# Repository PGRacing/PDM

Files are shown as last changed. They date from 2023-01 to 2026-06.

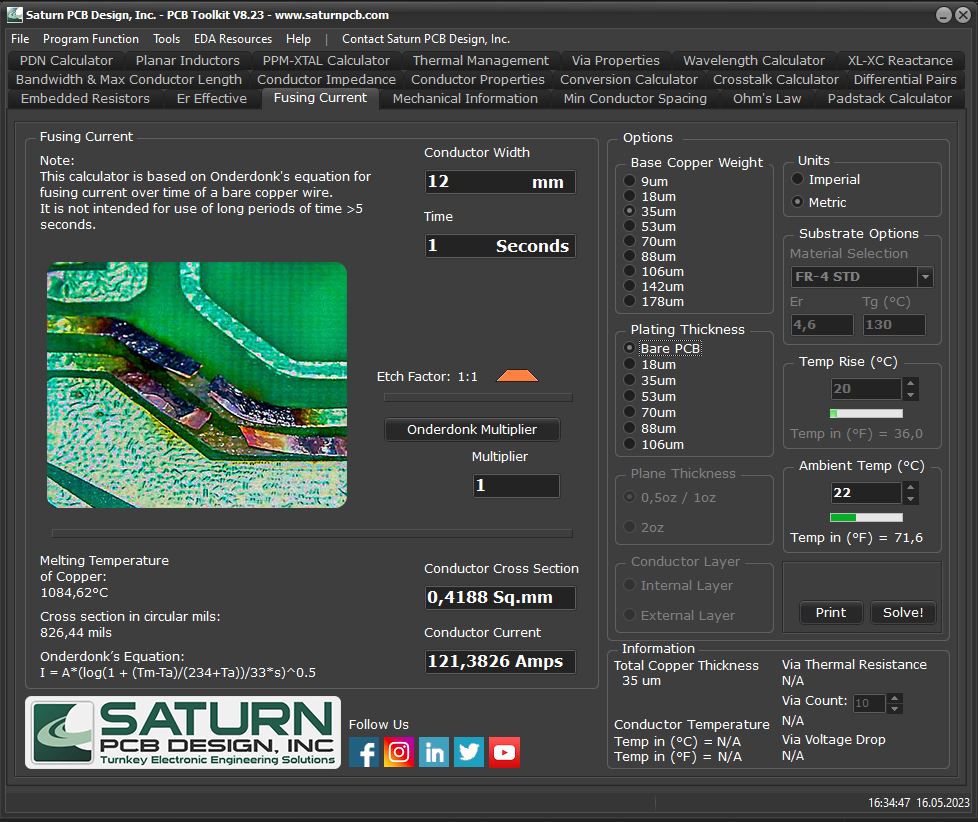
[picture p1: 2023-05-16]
SIM/CALCULATIONS/trace_fusing/external_12mm_1.0oz_121A_result.JPG

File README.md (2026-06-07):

# PDM

Schematic mockup:
obraz

TODO on next PCB:

Rev 4.3
| ID | NAME | CAUSE |DIFFICULTY | PRIORITY | STATUS |
| --- | --- | --- | --- | --- | --- |
| 1. | Create test board for BTS50025-1TAE | Switch with higher Rds(on) should perform better in terms of diagnostics on most used loads | 1 | 3 | | 
| 2. | Create schematic and brd for imporoved power delivery section optimized for autmotive use based on MP4322 TLS850F2TAV50, TVS diodes + filtering | Current solution with MP2332 has maximum rating of 18V, which is really for load dumps | 3 | 3 || 
| 3. | Divide task to "safety critical real-time" hardware based (timer) ones and other normal operation tasks | Current solution can cause safety issus | 3 | 3 || 
| 4. | Prepare I^2t wiring harness protection | This should allow better WH protection| 3 | 2 || 
| 5. | Prepare OCP using curve, not only single value | This should allow better WH protection | 2 | 3 || 
| 6. | Use buffers for MCU protection | Protect MCU I/O pins | 1 | 2 || 
| 7. | Change zenner protection diodes to extended linearity region of Is switch output || 1 | 3 || 
| 8. | Add better filtering (change RC filter values) on Is output | Is output on inductive signals or fast switched signals HFreq PWM used causes invalid readings | 1 | 3 || 
| 9. | Detect battery under-voltage and UV shutdown for battery protection || 1 | 2 || 
| 10. | Configuration over USB | For sake of user-friendly solution | 3 | 2 || 
| 11. | CAN inputs support || 2 | 2 || 
| 12. | Thermal sensing | Safety critical | 2 | 2 || 
| 13. | Better 3D printed caseing (take care of screws outside of caseing envelope) + add honeycomb reinforcment | Safety critical for splash proof | 2 | 1 || 
| 14. | Add logic-level shifter for LED's | Some LED's turn red on random order | 1 | 3 || 
| 15. | Add separate voltage source for ARGB LED's and CAN bus | working can bus is critical for system integrity | 1 | 3 || 
| 16. | Add external voltage sources diagnosis (at least voltage on output) || 2 | 3 || 
| 17. | Add battery insulation and reverse-polarity + huge TVS and maybe Gas Discharge Tubes | Load dumps + cold crank etc. | 3 | 2 || 
| 18. | Add better connector for BAT+ | 1 | 3 || 
| 19. | Add limp home mode when any peripheral is malfunctioning (detect those malfunctions) | 2 | 3 || 
| 20. | Add TVS or zenner on all inputs (in limit of absolute maximium rating) near connector | 1 | 3 || 
| 21. | Add external or on-board probes for temperature sensing | 2 | 2 || 
| 22. | Add more state/debug led's | 1 | 1 || 
| 23. | Move safety functions oc and counters and errors into separate struct or bit mask of register | 2 | 3 || 

Rev. 4.1
| NAME | DIFFICULTY | PRIORITY | STATUS |
| --- | --- | --- | --- |
| 1. Add fuse for external sensors supply (100mA). Can also be solved with second 5V regulator for sensors + fuse. | 1 | 3 | DONE - Added external LDO's to 3.3V and 5V |
| 2. Change CPC1117N to CPC1017N (or diffrent PhotoMos) | 1 | 2 | DONE - Added diffrent (smaller) Opto-MOS |
| 3. Add clamping diodes on any signals | 2 | 3 | Added zenner + shottky clippers |
| 4. Change input filtration for low profile SMD capacitor instead of tht | 1 | 1 | DEPRECEATED  |
| 5. Add SWO pin | 2 | 2 | DONE |
| 6. Current sensors output should be collected by one ADC !!! - for eg. ADC3 (change pinout) | 3 | 2 | DONE |
| 7. Add clamping diodes on current sensor to allow lower range current detecion | 2 | 3 | DONE |
| 8. Selection and redirection of IO is not imporant | 1 | 1 | DONE - (only four channels) |
| 9. Fix WS2812B footprint | 1 | 3 | DONE |
| 10. Use smaller footprint for voltage mux and can transceiver | 2 | 1 | DONE - changed voltage mux to 16 channel, CAN transceiver same |
| 11. Change FET's to BTS50010-1LUA | 3 | 2 |  DONE |
| 12. Add RX/TX information leds to CAN bus (software driven) | 1 | 1 | DEPERECATED |
| 13. Add MUX for mutlichannel switch | 2 | 2 | DONE - added 16 channel mux |
| 14. Add CAN software switching | 2 | 2 | DONE |
| 14. Remove additional header for stlink | 2 | 2 | DONE |

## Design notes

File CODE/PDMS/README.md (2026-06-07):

# PDMS 

### DESCRIPTION
This repository contains code that is targeted for PDM - Power distribution module. PDMS is custom PDM mainly created for motorcycles and single-seater vehicles (formula student). Making changes in code and configurations can have critical impact on vehicle and driver safety. After changing configuration ALWAYS verify it in secure test enviroment. 

### NOTE
- This is code that should be used with PDMS v4.1 or PDMS v4.2 board
- Before usage verify MCU I/O configuration and mapping

### INSTALL

0. Install choco package manager: https://chocolatey.org/install

1. Install Visual Studio code as it is used as IDE for this project:
`> choco install vscode`

2. Check if cygwin is installed if install it via: 
`> choco install cygwin` 

3. Check if you have ARM embedded toolchain installed, version at least 10.3.1 required. In terminal in project directory type: 
`> arm-none-eabi-gcc --version `

4. If no toolchain present install it by:
`> choco install gcc-arm-embedded `
or by installing binary from: [ARM GNU Toolchain](https://developer.arm.com/downloads/-/arm-gnu-toolchain-downloads)

5. Install GNU make: 
`> choco install make `

6. Verify that all tools installed are added to `$PATH` and available in projects directory. 
``` 
    > arm-none-eabi-gcc --version
    > make --version
    > cygwin
```

7. Install following extensions for VS Code: 
    - [C/C++](https://marketplace.visualstudio.com/items?itemName=ms-vscode.cpptools)
    - [Cortex-Debug](https://marketplace.visualstudio.com/items?itemName=marus25.cortex-debug)
    - [Makefile Tools](https://marketplace.visualstudio.com/items?itemName=ms-vscode.makefile-tools)
  
### BUILD

Project is based on makefile system based on one root makefile [Makefile](https://github.com/PGRacing/PDM/blob/main/CODE/PDMS/Makefile)

To start build type: 
`>  make -j 16`
or start task:
`Build STM32 - L496` by clicking `Ctrl + Shift + B`

To clean build type: 
`> make clean -j 16`
or start task:
`Clean STM32 - L496` by clicking `Ctrl + Shift + B`

Build results are present in `./build` directory as:
    - PDMS.elf
    - PDMS.hex
    - PDMS.bin
    - PDMS.map

### DEBUG

Debug is performed via SWD interface on ST-Link probe via GDB Debugger. Start cortex-debug session from `Run and Debug (Ctrl + Shift + D)` tab by selecting one of following options: 
    - Debug STM32 (PDMS)
    - Attach STM32 (PDMS)
    - Debug STM32 with Live Expressions
Last option gives you access to Cortex Live Watch. Refresh frequency can be adjusted in `.vscode/launch.json` file in `samplesPerSecond` parameter. 

###### SWV
When SWO pin in ST-Link probe is connected, additional logging (SWV - Serial Wire Viewer) functionality can be used. On debug startup new terminal tab will pop-up named "ITM port 0 output". All printf function output is redirected over there. To interface with this port, wrapper macros from `util\logger.h` should be used. SWV is MCU and probe clock dependent, if any of those are changed it needs to be adjusted in `.vscode/launch.json`

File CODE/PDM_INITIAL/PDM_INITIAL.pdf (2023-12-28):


09/12/2023

PDM_INITIAL Project
Configuration Report

## 1. Description

### 1.1. Project

Project Name | PDM_INITIAL
Board Name | custom
Generated with: | STM32CubeMX 6.6.1
Date | 12/09/2023

### 1.2. MCU

MCU Series | STM32L4
MCU Line | STM32L4x6
MCU name | STM32L496ZGTx
MCU Package | LQFP144
MCU Pin number | 144

### 1.3. Core(s) information

Core(s) | Arm Cortex-M4

## 2. Pinout Configuration

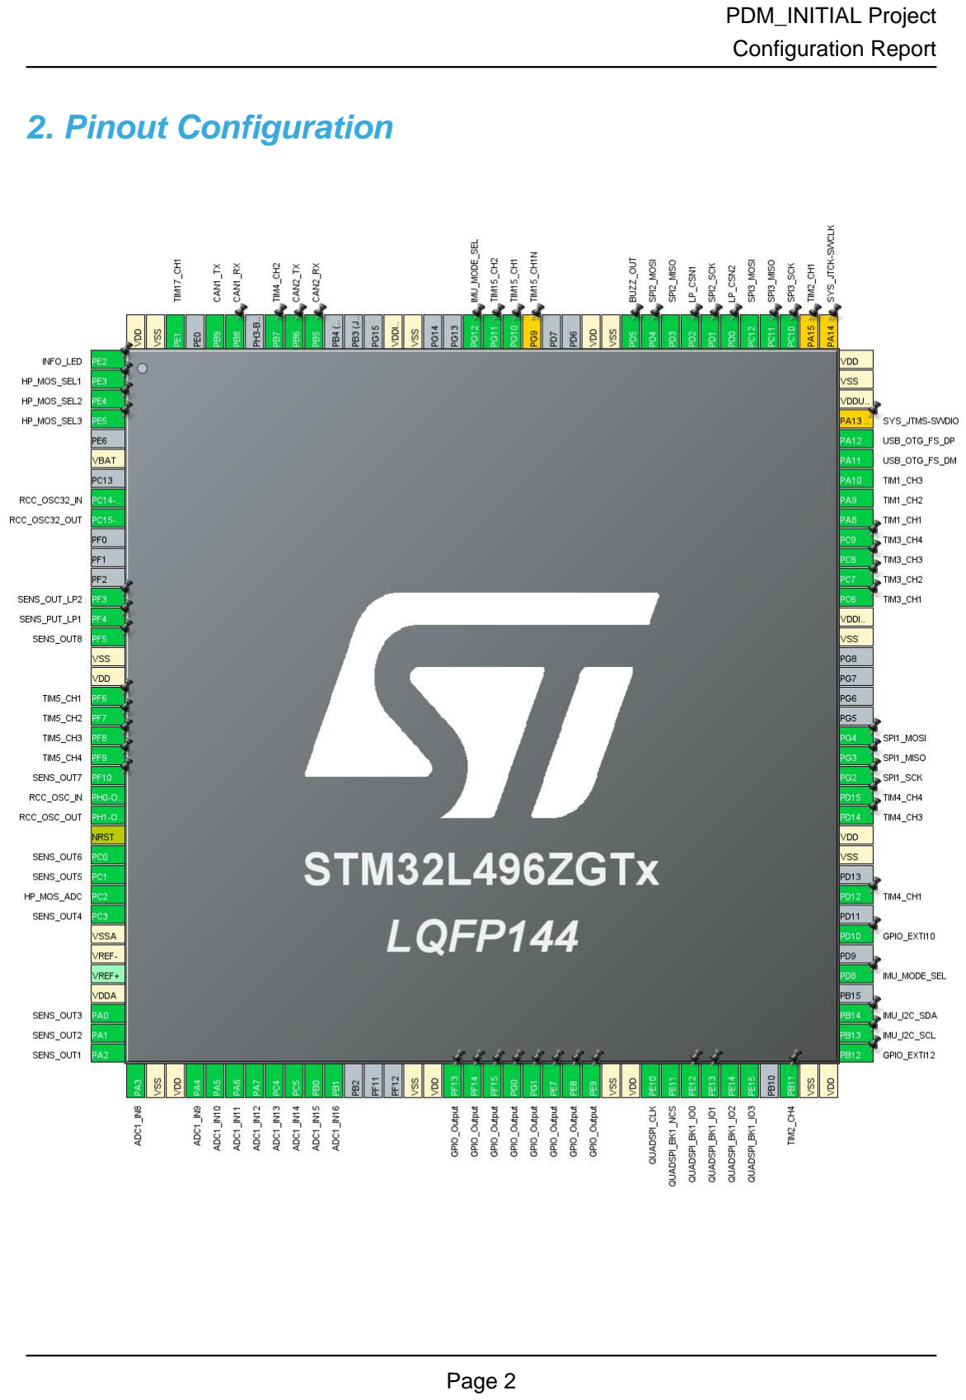
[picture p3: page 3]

## 3. Pins Configuration

Pin Number LQFP144 | Pin Name (function after reset) | Pin Type | Alternate Function(s) | Label
1 | PE2 * | I/O | GPIO_Output | INFO_LED
2 | PE3 * | I/O | GPIO_Output | HP_MOS_SEL1
3 | PE4 * | I/O | GPIO_Output | HP_MOS_SEL2
4 | PE5 * | I/O | GPIO_Output | HP_MOS_SEL3
6 | VBAT | Power
8 | PC14-OSC32_IN (PC14) | I/O | RCC_OSC32_IN
9 | PC15-OSC32_OUT (PC15) | I/O | RCC_OSC32_OUT
13 | PF3 | I/O | ADC3_IN6 | SENS_OUT_LP2
14 | PF4 | I/O | ADC3_IN7 | SENS_PUT_LP1
15 | PF5 | I/O | ADC3_IN8 | SENS_OUT8
16 | VSS | Power
17 | VDD | Power
18 | PF6 | I/O | TIM5_CH1
19 | PF7 | I/O | TIM5_CH2
20 | PF8 | I/O | TIM5_CH3
21 | PF9 | I/O | TIM5_CH4
22 | PF10 | I/O | ADC3_IN13 | SENS_OUT7
23 | PH0-OSC_IN (PH0) | I/O | RCC_OSC_IN
24 | PH1-OSC_OUT (PH1) | I/O | RCC_OSC_OUT
25 | NRST | Reset
26 | PC0 | I/O | ADC1_IN1 | SENS_OUT6
27 | PC1 | I/O | ADC1_IN2 | SENS_OUT5
28 | PC2 | I/O | ADC1_IN3 | HP_MOS_ADC
29 | PC3 | I/O | ADC1_IN4 | SENS_OUT4
30 | VSSA | Power
31 | VREF- | Power
33 | VDDA | Power
34 | PA0 | I/O | ADC1_IN5 | SENS_OUT3
35 | PA1 | I/O | ADC1_IN6 | SENS_OUT2
36 | PA2 | I/O | ADC1_IN7 | SENS_OUT1
37 | PA3 | I/O | ADC1_IN8
38 | VSS | Power
39 | VDD | Power
40 | PA4 | I/O | ADC1_IN9
41 | PA5 | I/O | ADC1_IN10
42 | PA6 | I/O | ADC1_IN11

Pin Number LQFP144 | Pin Name (function after reset) | Pin Type | Alternate Function(s) | Label
43 | PA7 | I/O | ADC1_IN12
44 | PC4 | I/O | ADC1_IN13
45 | PC5 | I/O | ADC1_IN14
46 | PB0 | I/O | ADC1_IN15
47 | PB1 | I/O | ADC1_IN16
51 | VSS | Power
52 | VDD | Power
53 | PF13 * | I/O | GPIO_Output
54 | PF14 * | I/O | GPIO_Output
55 | PF15 * | I/O | GPIO_Output
56 | PG0 * | I/O | GPIO_Output
57 | PG1 * | I/O | GPIO_Output
58 | PE7 * | I/O | GPIO_Output
59 | PE8 * | I/O | GPIO_Output
60 | PE9 * | I/O | GPIO_Output
61 | VSS | Power
62 | VDD | Power
63 | PE10 | I/O | QUADSPI_CLK
64 | PE11 | I/O | QUADSPI_BK1_NCS
65 | PE12 | I/O | QUADSPI_BK1_IO0
66 | PE13 | I/O | QUADSPI_BK1_IO1
67 | PE14 | I/O | QUADSPI_BK1_IO2
68 | PE15 | I/O | QUADSPI_BK1_IO3
70 | PB11 | I/O | TIM2_CH4
71 | VSS | Power
72 | VDD | Power
73 | PB12 | I/O | GPIO_EXTI12
74 | PB13 | I/O | I2C2_SCL | IMU_I2C_SCL
75 | PB14 | I/O | I2C2_SDA | IMU_I2C_SDA
77 | PD8 * | I/O | GPIO_Output | IMU_MODE_SEL
79 | PD10 | I/O | GPIO_EXTI10
81 | PD12 | I/O | TIM4_CH1
83 | VSS | Power
84 | VDD | Power
85 | PD14 | I/O | TIM4_CH3
86 | PD15 | I/O | TIM4_CH4
87 | PG2 | I/O | SPI1_SCK
88 | PG3 | I/O | SPI1_MISO
89 | PG4 | I/O | SPI1_MOSI

Pin Number LQFP144 | Pin Name (function after reset) | Pin Type | Alternate Function(s) | Label
94 | VSS | Power
95 | VDDIO2 | Power
96 | PC6 | I/O | TIM3_CH1
97 | PC7 | I/O | TIM3_CH2
98 | PC8 | I/O | TIM3_CH3
99 | PC9 | I/O | TIM3_CH4
100 | PA8 | I/O | TIM1_CH1
101 | PA9 | I/O | TIM1_CH2
102 | PA10 | I/O | TIM1_CH3
103 | PA11 | I/O | USB_OTG_FS_DM
104 | PA12 | I/O | USB_OTG_FS_DP
105 | PA13 (JTMS/SWDIO) ** | I/O | SYS_JTMS-SWDIO
106 | VDDUSB | Power
107 | VSS | Power
108 | VDD | Power
109 | PA14 (JTCK/SWCLK) ** | I/O | SYS_JTCK-SWCLK
110 | PA15 (JTDI) ** | I/O | TIM2_CH1
111 | PC10 | I/O | SPI3_SCK
112 | PC11 | I/O | SPI3_MISO
113 | PC12 | I/O | SPI3_MOSI
114 | PD0 * | I/O | GPIO_Output | LP_CSN2
115 | PD1 | I/O | SPI2_SCK
116 | PD2 * | I/O | GPIO_Output | LP_CSN1
117 | PD3 | I/O | SPI2_MISO
118 | PD4 | I/O | SPI2_MOSI
119 | PD5 * | I/O | GPIO_Output | BUZZ_OUT
120 | VSS | Power
121 | VDD | Power
124 | PG9 ** | I/O | TIM15_CH1N
125 | PG10 | I/O | TIM15_CH1
126 | PG11 | I/O | TIM15_CH2
127 | PG12 * | I/O | GPIO_Output | IMU_MODE_SEL
130 | VSS | Power
131 | VDDIO2 | Power
135 | PB5 | I/O | CAN2_RX
136 | PB6 | I/O | CAN2_TX
137 | PB7 | I/O | TIM4_CH2
139 | PB8 | I/O | CAN1_RX
140 | PB9 | I/O | CAN1_TX

Pin Number LQFP144 | Pin Name (function after reset) | Pin Type | Alternate Function(s) | Label
142 | PE1 | I/O | TIM17_CH1
143 | VSS | Power
144 | VDD | Power

* The pin is affected with an I/O function
** The pin is affected with a peripheral function but no peripheral mode is activated

## 4. Clock Tree Configuration

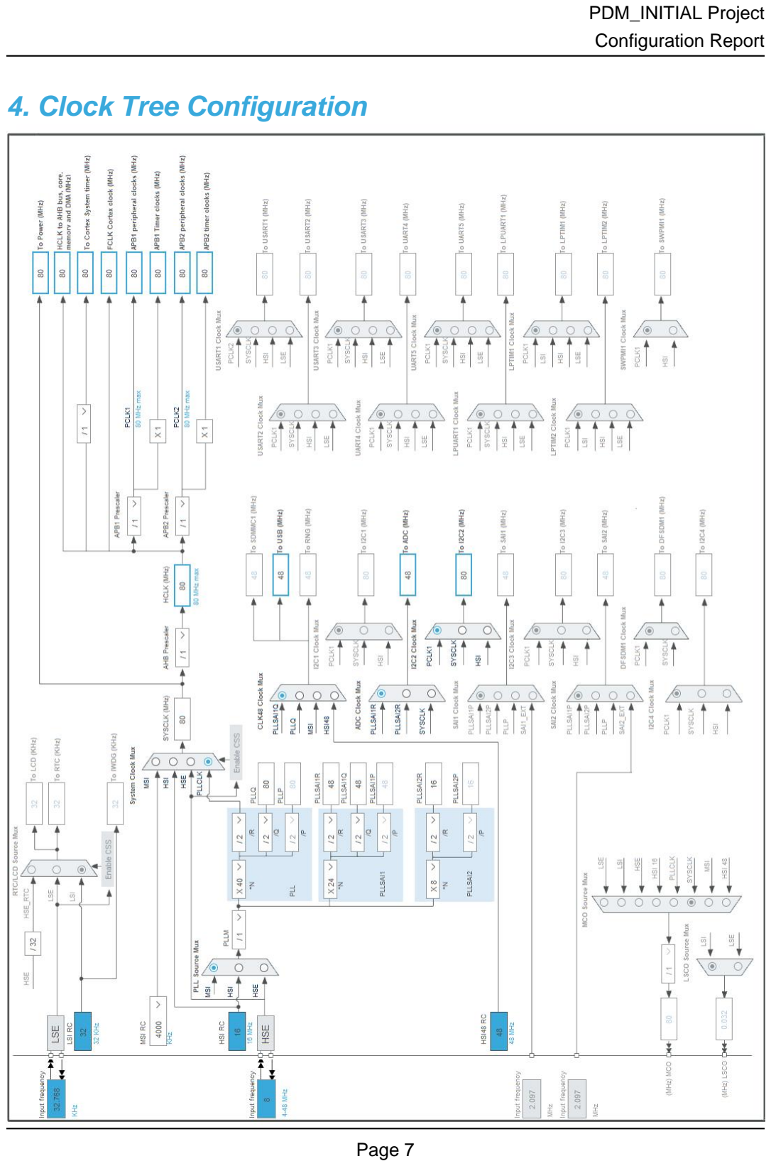
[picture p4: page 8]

## 5. Software Project

### 5.1. Project Settings

Name | Value
Project Name | PDM_INITIAL
Project Folder | C:\Users\Karol\Documents\GitHub\PDM\CODE\PDM_INITIAL
Toolchain / IDE | EWARM V8.32
Firmware Package Name and Version | STM32Cube FW_L4 V1.17.2
Application Structure | Advanced
Generate Under Root | No
Do not generate the main() | No
Minimum Heap Size | 0x200
Minimum Stack Size | 0x400

### 5.2. Code Generation Settings

Name | Value
STM32Cube MCU packages and embedded software | Copy all used libraries into the project folder
Generate peripheral initialization as a pair of '.c/.h' files | No
Backup previously generated files when re-generating | No
Keep User Code when re-generating | Yes
Delete previously generated files when not re-generated | Yes
Set all free pins as analog (to optimize the power consumption) | No
Enable Full Assert | No

### 5.3. Advanced Settings - Generated Function Calls

Rank | Function Name | Peripheral Instance Name
1 | SystemClock_Config | RCC
2 | MX_GPIO_Init | GPIO
3 | MX_DMA_Init | DMA
4 | MX_ADC1_Init | ADC1
5 | MX_ADC3_Init | ADC3
6 | MX_CAN1_Init | CAN1
7 | MX_CAN2_Init | CAN2
8 | MX_QUADSPI_Init | QUADSPI
9 | MX_SPI1_Init | SPI1
10 | MX_SPI3_Init | SPI3
11 | MX_TIM4_Init | TIM4

Rank | Function Name | Peripheral Instance Name
12 | MX_TIM3_Init | TIM3
13 | MX_TIM2_Init | TIM2
14 | MX_I2C2_Init | I2C2
15 | MX_TIM1_Init | TIM1
16 | MX_TIM5_Init | TIM5
17 | MX_TIM15_Init | TIM15
18 | MX_TIM17_Init | TIM17
19 | MX_SPI2_Init | SPI2
20 | MX_USB_DEVICE_Init | USB_DEVICE

## 6. Power Consumption Calculator report

### 6.1. Microcontroller Selection

Series | STM32L4
Line | STM32L4x6
MCU | STM32L496ZGTx
Datasheet | DS11585_Rev2

### 6.2. Parameter Selection

Temperature | 25
Vdd | 3.0

### 6.3. Battery Selection

Battery | Li-SOCL2(A3400)
Capacity | 3400.0 mAh
Self Discharge | 0.08 %/month
Nominal Voltage | 3.6 V
Max Cont Current | 100.0 mA
Max Pulse Current | 200.0 mA
Cells in series | 1
Cells in parallel | 1

### 6.4. Sequence

Step | Step1 | Step2
Mode | RUN | STOP2
Vdd | 3.0 | 3.0
Voltage Source | Battery | Battery
Range | Range1-High | NoRange
Fetch Type | FLASH | n/a
CPU Frequency | 80 MHz | 0 Hz
Clock Configuration | HSE BYP PLL Flash-ON | ALL CLOCKS OFF
Clock Source Frequency | 4 MHz | 0 Hz
Peripherals
Additional Cons. | 0 mA | 0 mA
Average Current | 10 mA | 2.69 µA
Duration | 0.1 ms | 0.9 ms
DMIPS | 100.0 | 0.0
Ta Max | 104.04 | 105
Category | In DS Table | In DS Table

### 6.5. Results

Sequence Time | 1 ms | Average Current | 1 mA
Battery Life | 4 months, 19 days, 3 hours | Average DMIPS | 100.0 DMIPS

### 6.6. Chart

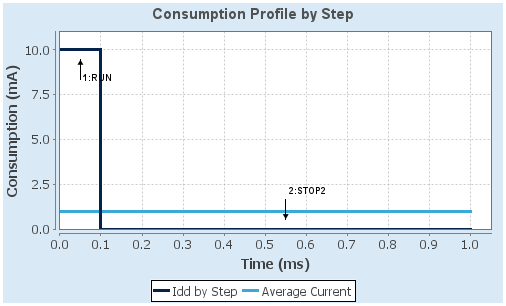
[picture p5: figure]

## 7. Peripherals and Middlewares Configuration

### 7.1. ADC1

IN1: IN1 Single-ended
IN2: IN2 Single-ended
IN3: IN3 Single-ended
IN4: IN4 Single-ended
IN5: IN5 Single-ended
IN6: IN6 Single-ended
IN7: IN7 Single-ended
IN8: IN8 Single-ended
IN9: IN9 Single-ended
IN10: IN10 Single-ended
IN11: IN11 Single-ended
IN12: IN12 Single-ended
IN13: IN13 Single-ended
IN14: IN14 Single-ended
IN15: IN15 Single-ended
mode: IN16 Single-ended
mode: Temperature Sensor Channel mode: Vbat Channel
7.1.1. Parameter Settings:

ADCs_Common_Settings:

Mode | Independent mode
ADC_Settings:
Clock Prescaler | Asynchronous clock mode divided by 1
Resolution | ADC 12-bit resolution
Data Alignment | Right alignment
Scan Conversion Mode | Disabled
Continuous Conversion Mode | Disabled
Discontinuous Conversion Mode | Disabled
DMA Continuous Requests | Disabled
End Of Conversion Selection | End of single conversion
Overrun behaviour | Overrun data preserved
Low Power Auto Wait | Disabled
ADC_Regular_ConversionMode:
Enable Regular Conversions | Enable

Enable Regular Oversampling | Disable
Number Of Conversion | 1
External Trigger Conversion Source | Regular Conversion launched by software
External Trigger Conversion Edge | None
Rank | 1
Channel | Channel 1
Sampling Time | 2.5 Cycles
Offset Number | No offset
ADC_Injected_ConversionMode:
Enable Injected Conversions | Disable
Analog Watchdog 1:
Enable Analog WatchDog1 Mode | false
Analog Watchdog 2:
Enable Analog WatchDog2 Mode | false
Analog Watchdog 3:
Enable Analog WatchDog3 Mode | false

### 7.2. ADC3

IN6: IN6 Differential
IN8: IN8 Single-ended
mode: IN13
7.2.1. Parameter Settings:

ADC_Settings:

Clock Prescaler | Asynchronous clock mode divided by 1
Resolution | ADC 12-bit resolution
Data Alignment | Right alignment
Scan Conversion Mode | Disabled
Continuous Conversion Mode | Disabled
Discontinuous Conversion Mode | Disabled
DMA Continuous Requests | Disabled
End Of Conversion Selection | End of single conversion
Overrun behaviour | Overrun data preserved
Low Power Auto Wait | Disabled
ADC_Regular_ConversionMode:
Enable Regular Conversions | Enable
Enable Regular Oversampling | Disable
Number Of Conversion | 1
External Trigger Conversion Source | Regular Conversion launched by software

External Trigger Conversion Edge | None
Rank | 1
Channel | Channel 6
Sampling Time | 2.5 Cycles
Offset Number | No offset
ADC_Injected_ConversionMode:
Enable Injected Conversions | Disable
Analog Watchdog 1:
Enable Analog WatchDog1 Mode | false
Analog Watchdog 2:
Enable Analog WatchDog2 Mode | false
Analog Watchdog 3:
Enable Analog WatchDog3 Mode | false

### 7.3. CAN1

mode: Activated
7.3.1. Parameter Settings:

Bit Timings Parameters:

Prescaler (for Time Quantum) | 16
Time Quantum | 200.0 *
Time Quanta in Bit Segment 1 | 6 Times *
Time Quanta in Bit Segment 2 | 1 Time
Time for one Bit | 1600 *
Baud Rate | 625000 *
ReSynchronization Jump Width | 1 Time
Basic Parameters:
Time Triggered Communication Mode | Disable
Automatic Bus-Off Management | Disable
Automatic Wake-Up Mode | Disable
Automatic Retransmission | Disable
Receive Fifo Locked Mode | Disable
Transmit Fifo Priority | Disable
Advanced Parameters:
Operating Mode | Normal

### 7.4. CAN2

mode: Activated
7.4.1. Parameter Settings:

Bit Timings Parameters:

Prescaler (for Time Quantum) | 16
Time Quantum | 200.0 *
Time Quanta in Bit Segment 1 | 8 Times *
Time Quanta in Bit Segment 2 | 1 Time
Time for one Bit | 2000 *
Baud Rate | 500000 *
ReSynchronization Jump Width | 1 Time
Basic Parameters:
Time Triggered Communication Mode | Disable
Automatic Bus-Off Management | Disable
Automatic Wake-Up Mode | Disable
Automatic Retransmission | Disable
Receive Fifo Locked Mode | Disable
Transmit Fifo Priority | Disable
Advanced Parameters:
Operating Mode | Normal

### 7.5. I2C2

I2C: I2C
7.5.1. Parameter Settings:

Timing configuration:

Custom Timing | Disabled
I2C Speed Mode | Standard Mode
I2C Speed Frequency (KHz) | 100
Rise Time (ns) | 0
Fall Time (ns) | 0
Coefficient of Digital Filter | 0
Analog Filter | Enabled
Timing | 0x10909CEC *
Slave Features:
Clock No Stretch Mode | Disabled
General Call Address Detection | Disabled

Primary Address Length selection | 7-bit
Dual Address Acknowledged | Disabled
Primary slave address | 0

### 7.6. QUADSPI

QuadSPI Mode: Bank1 with Quad SPI Lines
7.6.1. Parameter Settings:

General Parameters:

Clock Prescaler | 255
Fifo Threshold | 1
Sample Shifting | No Sample Shifting
Flash Size | 1
Chip Select High Time | 1 Cycle
Clock Mode | Low
Flash ID | Flash ID 1
Dual Flash | Disabled

### 7.7. RCC

High Speed Clock (HSE): Crystal/Ceramic Resonator Low Speed Clock (LSE) : Crystal/Ceramic Resonator
7.7.1. Parameter Settings:

System Parameters:

VDD voltage (V) | 3.3
Instruction Cache | Enabled
Prefetch Buffer | Disabled
Data Cache | Enabled
Flash Latency(WS) | 4 WS (5 CPU cycle)
RCC Parameters:
HSI Calibration Value | 64
MSI Calibration Value | 0
MSI Auto Calibration | Enabled
HSE Startup Timout Value (ms) | 100
LSE Startup Timout Value (ms) | 5000
LSE Drive Capability | LSE oscillator low drive capability
Power Parameters:
Power Regulator Voltage Scale | Power Regulator Voltage Scale 1

### 7.8. SPI1

Mode: Full-Duplex Master
7.8.1. Parameter Settings:

Basic Parameters:

Frame Format | Motorola
Data Size | 4 Bits
First Bit | MSB First
Clock Parameters:
Prescaler (for Baud Rate) | 2
Baud Rate | 40.0 MBits/s *
Clock Polarity (CPOL) | Low
Clock Phase (CPHA) | 1 Edge
Advanced Parameters:
CRC Calculation | Disabled
NSSP Mode | Enabled
NSS Signal Type | Software

### 7.9. SPI2

Mode: Full-Duplex Master
7.9.1. Parameter Settings:

Basic Parameters:

Frame Format | Motorola
Data Size | 4 Bits
First Bit | MSB First
Clock Parameters:
Prescaler (for Baud Rate) | 2
Baud Rate | 40.0 MBits/s *
Clock Polarity (CPOL) | Low
Clock Phase (CPHA) | 1 Edge
Advanced Parameters:
CRC Calculation | Disabled
NSSP Mode | Enabled
NSS Signal Type | Software

### 7.10. SPI3

Mode: Full-Duplex Master
7.10.1. Parameter Settings:

Basic Parameters:

Frame Format | Motorola
Data Size | 4 Bits
First Bit | MSB First
Clock Parameters:
Prescaler (for Baud Rate) | 2
Baud Rate | 40.0 MBits/s *
Clock Polarity (CPOL) | Low
Clock Phase (CPHA) | 1 Edge
Advanced Parameters:
CRC Calculation | Disabled
NSSP Mode | Enabled
NSS Signal Type | Software

### 7.11. SYS

Timebase Source: SysTick

### 7.12. TIM1

Channel1: PWM Generation CH1 Channel2: PWM Generation CH2 Channel3: PWM Generation CH3
7.12.1. Parameter Settings:

Counter Settings:

Prescaler (PSC - 16 bits value) | 0
Counter Mode | Up
Counter Period (AutoReload Register - 16 bits value ) | 65535
Internal Clock Division (CKD) | No Division
Repetition Counter (RCR - 8 bits value) | 0
auto-reload preload | Disable
Trigger Output (TRGO) Parameters:

Master/Slave Mode (MSM bit) | Disable (Trigger input effect not delayed)
Trigger Event Selection TRGO | Reset (UG bit from TIMx_EGR)
Trigger Event Selection TRGO2 | Reset (UG bit from TIMx_EGR)
Break And Dead Time management - BRK Configuration:
BRK State | Disable
BRK Polarity | High
BRK Filter (4 bits value) | 0
BRK Sources Configuration
- Digital Input | Disable
- COMP1 | Disable
- COMP2 | Disable
- DFSDM | Disable
Break And Dead Time management - BRK2 Configuration:
BRK2 State | Disable
BRK2 Polarity | High
BRK2 Filter (4 bits value) | 0
BRK2 Sources Configuration
- Digital Input | Disable
- COMP1 | Disable
- COMP2 | Disable
- DFSDM | Disable
Break And Dead Time management - Output Configuration:
Automatic Output State | Disable
Off State Selection for Run Mode (OSSR) | Disable
Off State Selection for Idle Mode (OSSI) | Disable
Lock Configuration | Off
Clear Input:
Clear Input Source | Disable
PWM Generation Channel 1:
Mode | PWM mode 1
Pulse (16 bits value) | 0
Output compare preload | Enable
Fast Mode | Disable
CH Polarity | High
CH Idle State | Reset
PWM Generation Channel 2:
Mode | PWM mode 1
Pulse (16 bits value) | 0
Output compare preload | Enable
Fast Mode | Disable
CH Polarity | High
CH Idle State | Reset

PWM Generation Channel 3:

Mode | PWM mode 1
Pulse (16 bits value) | 0
Output compare preload | Enable
Fast Mode | Disable
CH Polarity | High
CH Idle State | Reset

### 7.13. TIM2

Channel4: PWM Generation CH4
7.13.1. Parameter Settings:

Counter Settings:

Prescaler (PSC - 16 bits value) | 0
Counter Mode | Up
Counter Period (AutoReload Register - 32 bits value ) | 4294967295
Internal Clock Division (CKD) | No Division
auto-reload preload | Disable
Trigger Output (TRGO) Parameters:
Master/Slave Mode (MSM bit) | Disable (Trigger input effect not delayed)
Trigger Event Selection TRGO | Reset (UG bit from TIMx_EGR)
Clear Input:
Clear Input Source | Disable
PWM Generation Channel 4:
Mode | PWM mode 1
Pulse (32 bits value) | 0
Output compare preload | Enable
Fast Mode | Disable
CH Polarity | High

### 7.14. TIM3

Channel1: PWM Generation CH1 Channel2: PWM Generation CH2 Channel3: PWM Generation CH3 Channel4: PWM Generation CH4
7.14.1. Parameter Settings:

Counter Settings:

Prescaler (PSC - 16 bits value) | 0
Counter Mode | Up
Counter Period (AutoReload Register - 16 bits value ) | 65535
Internal Clock Division (CKD) | No Division
auto-reload preload | Disable
Trigger Output (TRGO) Parameters:
Master/Slave Mode (MSM bit) | Disable (Trigger input effect not delayed)
Trigger Event Selection TRGO | Reset (UG bit from TIMx_EGR)
Clear Input:
Clear Input Source | Disable
PWM Generation Channel 1:
Mode | PWM mode 1
Pulse (16 bits value) | 0
Output compare preload | Enable
Fast Mode | Disable
CH Polarity | High
PWM Generation Channel 2:
Mode | PWM mode 1
Pulse (16 bits value) | 0
Output compare preload | Enable
Fast Mode | Disable
CH Polarity | High
PWM Generation Channel 3:
Mode | PWM mode 1
Pulse (16 bits value) | 0
Output compare preload | Enable
Fast Mode | Disable
CH Polarity | High
PWM Generation Channel 4:
Mode | PWM mode 1
Pulse (16 bits value) | 0
Output compare preload | Enable
Fast Mode | Disable
CH Polarity | High

### 7.15. TIM4

Channel1: PWM Generation CH1 Channel2: PWM Generation CH2 Channel3: PWM Generation CH3 Channel4: PWM Generation CH4
7.15.1. Parameter Settings:

Counter Settings:

Prescaler (PSC - 16 bits value) | 0
Counter Mode | Up
Counter Period (AutoReload Register - 16 bits value ) | 65535
Internal Clock Division (CKD) | No Division
auto-reload preload | Disable
Trigger Output (TRGO) Parameters:
Master/Slave Mode (MSM bit) | Disable (Trigger input effect not delayed)
Trigger Event Selection TRGO | Reset (UG bit from TIMx_EGR)
Clear Input:
Clear Input Source | Disable
PWM Generation Channel 1:
Mode | PWM mode 1
Pulse (16 bits value) | 0
Output compare preload | Enable
Fast Mode | Disable
CH Polarity | High
PWM Generation Channel 2:
Mode | PWM mode 1
Pulse (16 bits value) | 0
Output compare preload | Enable
Fast Mode | Disable
CH Polarity | High
PWM Generation Channel 3:
Mode | PWM mode 1
Pulse (16 bits value) | 0
Output compare preload | Enable
Fast Mode | Disable
CH Polarity | High
PWM Generation Channel 4:
Mode | PWM mode 1
Pulse (16 bits value) | 0
Output compare preload | Enable
Fast Mode | Disable

CH Polarity | High

### 7.16. TIM5

Channel1: PWM Generation CH1 Channel2: PWM Generation CH2 Channel3: PWM Generation CH3 Channel4: PWM Generation CH4
7.16.1. Parameter Settings:

Counter Settings:

Prescaler (PSC - 16 bits value) | 0
Counter Mode | Up
Counter Period (AutoReload Register - 32 bits value ) | 4294967295
Internal Clock Division (CKD) | No Division
auto-reload preload | Disable
Trigger Output (TRGO) Parameters:
Master/Slave Mode (MSM bit) | Disable (Trigger input effect not delayed)
Trigger Event Selection TRGO | Reset (UG bit from TIMx_EGR)
Clear Input:
Clear Input Source | Disable
PWM Generation Channel 1:
Mode | PWM mode 1
Pulse (32 bits value) | 0
Output compare preload | Enable
Fast Mode | Disable
CH Polarity | High
PWM Generation Channel 2:
Mode | PWM mode 1
Pulse (32 bits value) | 0
Output compare preload | Enable
Fast Mode | Disable
CH Polarity | High
PWM Generation Channel 3:
Mode | PWM mode 1
Pulse (32 bits value) | 0
Output compare preload | Enable
Fast Mode | Disable
CH Polarity | High
PWM Generation Channel 4:

Mode | PWM mode 1
Pulse (32 bits value) | 0
Output compare preload | Enable
Fast Mode | Disable
CH Polarity | High

### 7.17. TIM15

Channel1: PWM Generation CH1 Channel2: PWM Generation CH2
7.17.1. Parameter Settings:

Counter Settings:

Prescaler (PSC - 16 bits value) | 0
Counter Mode | Up
Counter Period (AutoReload Register - 16 bits value ) | 65535
Internal Clock Division (CKD) | No Division
Repetition Counter (RCR - 8 bits value) | 0
auto-reload preload | Disable
Trigger Output (TRGO) Parameters:
Master/Slave Mode (MSM bit) | Disable (Trigger input effect not delayed)
Trigger Event Selection | Reset (UG bit from TIMx_EGR)
Break And Dead Time management - BRK Configuration:
BRK State | Disable
BRK Polarity | High
BRK Sources Configuration
- Digital Input | Disable
- COMP1 | Disable
- COMP2 | Disable
- DFSDM | Disable
Break And Dead Time management - Output Configuration:
Automatic Output State | Disable
Off State Selection for Run Mode (OSSR) | Disable
Off State Selection for Idle Mode (OSSI) | Disable
Lock Configuration | Off
PWM Generation Channel 1:
Mode | PWM mode 1
Pulse (16 bits value) | 0
Output compare preload | Enable
Fast Mode | Disable
CH Polarity | High

CH Idle State | Reset
PWM Generation Channel 2:
Mode | PWM mode 1
Pulse (16 bits value) | 0
Output compare preload | Enable
Fast Mode | Disable
CH Polarity | High
CH Idle State | Reset

### 7.18. TIM17

mode: Activated
Channel1: PWM Generation CH1
7.18.1. Parameter Settings:

Counter Settings:

Prescaler (PSC - 16 bits value) | 0
Counter Mode | Up
Counter Period (AutoReload Register - 16 bits value ) | 65535
Internal Clock Division (CKD) | No Division
Repetition Counter (RCR - 8 bits value) | 0
auto-reload preload | Disable
Break And Dead Time management - BRK Configuration:
BRK State | Disable
BRK Polarity | High
BRK Sources Configuration
- Digital Input | Disable
- COMP1 | Disable
- COMP2 | Disable
- DFSDM | Disable
Break And Dead Time management - Output Configuration:
Automatic Output State | Disable
Off State Selection for Run Mode (OSSR) | Disable
Off State Selection for Idle Mode (OSSI) | Disable
Lock Configuration | Off
PWM Generation Channel 1:
Mode | PWM mode 1
Pulse (16 bits value) | 0
Output compare preload | Enable
Fast Mode | Disable
CH Polarity | High

CH Idle State | Reset

### 7.19. USB_OTG_FS

Mode: Device_Only
7.19.1. Parameter Settings:
Speed | Full Speed 12MBit/s
Low power | Disabled
Battery charging | Disabled
Link Power Management | Disabled
Use dedicated end point 1 interrupt | Disabled
VBUS sensing | Disabled
Signal start of frame | Disabled

### 7.20. USB_DEVICE

Class For FS IP: Communication Device Class (Virtual Port Com)
7.20.1. Parameter Settings:

Basic Parameters:

USBD_MAX_NUM_INTERFACES (Maximum number of supported interfaces) | 1
USBD_MAX_NUM_CONFIGURATION (Maximum number of supported configuration) | 1
USBD_MAX_STR_DESC_SIZ (Maximum size for the string descriptors) | 512
USBD_SELF_POWERED (Enabled self power) | Enabled
USBD_DEBUG_LEVEL (USBD Debug Level) | 0: No debug message
USBD_LPM_ENABLED (Link Power Management) | 1: Link Power Management supported
Class Parameters:
USB CDC Rx Buffer Size | 2048
USB CDC Tx Buffer Size | 2048
7.20.2. Device Descriptor:

Device Descriptor:

VID (Vendor IDentifier) | 1155
LANGID_STRING (Language Identifier) | English(United States)
MANUFACTURER_STRING (Manufacturer Identifier) | STMicroelectronics
Device Descriptor FS:
PID (Product IDentifier) | 22336

PRODUCT_STRING (Product Identifier) | STM32 Virtual ComPort
CONFIGURATION_STRING (Configuration Identifier) | CDC Config
INTERFACE_STRING (Interface Identifier) | CDC Interface

* User modified value

## 8. System Configuration

### 8.1. GPIO configuration

IP | Pin | Signal | GPIO mode | GPIO pull/up pull down

Max
Speed

User Label

ADC1 | PC0 | ADC1_IN1 | Analog mode | No pull-up and no pull-down | n/a | SENS_OUT6
| PC1 | ADC1_IN2 | Analog mode | No pull-up and no pull-down | n/a | SENS_OUT5
| PC2 | ADC1_IN3 | Analog mode | No pull-up and no pull-down | n/a | HP_MOS_ADC
| PC3 | ADC1_IN4 | Analog mode | No pull-up and no pull-down | n/a | SENS_OUT4
| PA0 | ADC1_IN5 | Analog mode | No pull-up and no pull-down | n/a | SENS_OUT3
| PA1 | ADC1_IN6 | Analog mode | No pull-up and no pull-down | n/a | SENS_OUT2
| PA2 | ADC1_IN7 | Analog mode | No pull-up and no pull-down | n/a | SENS_OUT1
| PA3 | ADC1_IN8 | Analog mode | No pull-up and no pull-down | n/a
| PA4 | ADC1_IN9 | Analog mode | No pull-up and no pull-down | n/a
| PA5 | ADC1_IN10 | Analog mode | No pull-up and no pull-down | n/a
| PA6 | ADC1_IN11 | Analog mode | No pull-up and no pull-down | n/a
| PA7 | ADC1_IN12 | Analog mode | No pull-up and no pull-down | n/a
| PC4 | ADC1_IN13 | Analog mode | No pull-up and no pull-down | n/a
| PC5 | ADC1_IN14 | Analog mode | No pull-up and no pull-down | n/a
| PB0 | ADC1_IN15 | Analog mode | No pull-up and no pull-down | n/a
| PB1 | ADC1_IN16 | Analog mode | No pull-up and no pull-down | n/a
ADC3 | PF3 | ADC3_IN6 | Analog mode | No pull-up and no pull-down | n/a | SENS_OUT_LP2
| PF4 | ADC3_IN7 | Analog mode | No pull-up and no pull-down | n/a | SENS_PUT_LP1
| PF5 | ADC3_IN8 | Analog mode | No pull-up and no pull-down | n/a | SENS_OUT8
| PF10 | ADC3_IN13 | Analog mode | No pull-up and no pull-down | n/a | SENS_OUT7
CAN1 | PB8 | CAN1_RX | Alternate Function Push Pull | No pull-up and no pull-down | Very High
*
| PB9 | CAN1_TX | Alternate Function Push Pull | No pull-up and no pull-down | Very High
*
CAN2 | PB5 | CAN2_RX | Alternate Function Push Pull | No pull-up and no pull-down | Very High
*
| PB6 | CAN2_TX | Alternate Function Push Pull | No pull-up and no pull-down | Very High
*
I2C2 | PB13 | I2C2_SCL | Alternate Function Open Drain | No pull-up and no pull-down | Very High
*
| | | | | | IMU_I2C_SCL
| PB14 | I2C2_SDA | Alternate Function Open Drain | No pull-up and no pull-down | Very High
*
| | | | | | IMU_I2C_SDA
QUADSPI | PE10 | QUADSPI_CLK Alternate Function Push Pull | No pull-up and no pull-down | Very High
*
| PE11 | QUADSPI_BK1_ | Alternate Function Push Pull | No pull-up and no pull-down | Very High

IP | Pin | Signal | GPIO mode | GPIO pull/up pull down

Max
Speed

User Label

NCS | | | *
PE12 | QUADSPI_BK1_I
O0 | Alternate Function Push Pull | No pull-up and no pull-down | Very High
*
PE13 | QUADSPI_BK1_I
O1 | Alternate Function Push Pull | No pull-up and no pull-down | Very High
*
PE14 | QUADSPI_BK1_I
O2 | Alternate Function Push Pull | No pull-up and no pull-down | Very High
*
PE15 | QUADSPI_BK1_I
O3 | Alternate Function Push Pull | No pull-up and no pull-down | Very High
*
RCC | PC14-
OSC32_IN
(PC14)
RCC_OSC32_IN | n/a | n/a | n/a

PC15-
OSC32_OU
T (PC15)

RCC_OSC32_O
UT
n/a | n/a | n/a

PH0-
OSC_IN
(PH0)
RCC_OSC_IN | n/a | n/a | n/a

PH1-
OSC_OUT
(PH1)
RCC_OSC_OUT | n/a | n/a | n/a
SPI1 | PG2 | SPI1_SCK | Alternate Function Push Pull | No pull-up and no pull-down | Very High
*
| PG3 | SPI1_MISO | Alternate Function Push Pull | No pull-up and no pull-down | Very High
*
| PG4 | SPI1_MOSI | Alternate Function Push Pull | No pull-up and no pull-down | Very High
*
SPI2 | PD1 | SPI2_SCK | Alternate Function Push Pull | No pull-up and no pull-down | Very High
*
| PD3 | SPI2_MISO | Alternate Function Push Pull | No pull-up and no pull-down | Very High
*
| PD4 | SPI2_MOSI | Alternate Function Push Pull | No pull-up and no pull-down | Very High
*
SPI3 | PC10 | SPI3_SCK | Alternate Function Push Pull | No pull-up and no pull-down | Very High
*
| PC11 | SPI3_MISO | Alternate Function Push Pull | No pull-up and no pull-down | Very High
*
| PC12 | SPI3_MOSI | Alternate Function Push Pull | No pull-up and no pull-down | Very High
*

IP | Pin | Signal | GPIO mode | GPIO pull/up pull down | Max Speed | User Label
TIM1 | PA8 | TIM1_CH1 | Alternate Function Push Pull | No pull-up and no pull-down | Low
| PA9 | TIM1_CH2 | Alternate Function Push Pull | No pull-up and no pull-down | Low
| PA10 | TIM1_CH3 | Alternate Function Push Pull | No pull-up and no pull-down | Low
TIM2 | PB11 | TIM2_CH4 | Alternate Function Push Pull | No pull-up and no pull-down | Low
TIM3 | PC6 | TIM3_CH1 | Alternate Function Push Pull | No pull-up and no pull-down | Low
| PC7 | TIM3_CH2 | Alternate Function Push Pull | No pull-up and no pull-down | Low
| PC8 | TIM3_CH3 | Alternate Function Push Pull | No pull-up and no pull-down | Low
| PC9 | TIM3_CH4 | Alternate Function Push Pull | No pull-up and no pull-down | Low
TIM4 | PD12 | TIM4_CH1 | Alternate Function Push Pull | No pull-up and no pull-down | Low
| PD14 | TIM4_CH3 | Alternate Function Push Pull | No pull-up and no pull-down | Low
| PD15 | TIM4_CH4 | Alternate Function Push Pull | No pull-up and no pull-down | Low
| PB7 | TIM4_CH2 | Alternate Function Push Pull | No pull-up and no pull-down | Low
TIM5 | PF6 | TIM5_CH1 | Alternate Function Push Pull | No pull-up and no pull-down | Low
| PF7 | TIM5_CH2 | Alternate Function Push Pull | No pull-up and no pull-down | Low
| PF8 | TIM5_CH3 | Alternate Function Push Pull | No pull-up and no pull-down | Low
| PF9 | TIM5_CH4 | Alternate Function Push Pull | No pull-up and no pull-down | Low
TIM15 | PG10 | TIM15_CH1 | Alternate Function Push Pull | No pull-up and no pull-down | Low
| PG11 | TIM15_CH2 | Alternate Function Push Pull | No pull-up and no pull-down | Low
TIM17 | PE1 | TIM17_CH1 | Alternate Function Push Pull | No pull-up and no pull-down | Low
USB_OTG_ FS | PA11 | USB_OTG_FS_ DM | Alternate Function Push Pull | No pull-up and no pull-down | Very High *
| PA12 | USB_OTG_FS_ DP | Alternate Function Push Pull | No pull-up and no pull-down | Very High *
Single Mapped Signals | PA13 (JTMS/SWDI O) | SYS_JTMS-SWDIO | n/a | n/a | n/a
| PA14 (JTCK/SWC LK) | SYS_JTCK-SWCLK | n/a | n/a | n/a
| PA15 (JTDI) | TIM2_CH1 | Alternate Function Push Pull | No pull-up and no pull-down | Low
| PG9 | TIM15_CH1N | Alternate Function Push Pull | No pull-up and no pull-down | Low
GPIO | PE2 | GPIO_Output | Output Push Pull | No pull-up and no pull-down | Low | INFO_LED
| PE3 | GPIO_Output | Output Push Pull | No pull-up and no pull-down | Low | HP_MOS_SEL1
| PE4 | GPIO_Output | Output Push Pull | No pull-up and no pull-down | Low | HP_MOS_SEL2
| PE5 | GPIO_Output | Output Push Pull | No pull-up and no pull-down | Low | HP_MOS_SEL3
| PF13 | GPIO_Output | Output Push Pull | No pull-up and no pull-down | Low
| PF14 | GPIO_Output | Output Push Pull | No pull-up and no pull-down | Low
| PF15 | GPIO_Output | Output Push Pull | No pull-up and no pull-down | Low
| PG0 | GPIO_Output | Output Push Pull | No pull-up and no pull-down | Low
| PG1 | GPIO_Output | Output Push Pull | No pull-up and no pull-down | Low
| PE7 | GPIO_Output | Output Push Pull | No pull-up and no pull-down | Low

IP | Pin | Signal | GPIO mode | GPIO pull/up pull down | Max Speed | User Label
| PE8 | GPIO_Output | Output Push Pull | No pull-up and no pull-down | Low
| PE9 | GPIO_Output | Output Push Pull | No pull-up and no pull-down | Low
| PB12 | GPIO_EXTI12 | External Interrupt Mode with Rising edge trigger detection | No pull-up and no pull-down | n/a
| PD8 | GPIO_Output | Output Push Pull | No pull-up and no pull-down | Low | IMU_MODE_SEL
| PD10 | GPIO_EXTI10 | External Interrupt Mode with Rising edge trigger detection | No pull-up and no pull-down | n/a
| PD0 | GPIO_Output | Output Push Pull | No pull-up and no pull-down | Low | LP_CSN2
| PD2 | GPIO_Output | Output Push Pull | No pull-up and no pull-down | Low | LP_CSN1
| PD5 | GPIO_Output | Output Push Pull | No pull-up and no pull-down | Low | BUZZ_OUT
| PG12 | GPIO_Output | Output Push Pull | No pull-up and no pull-down | Low | IMU_MODE_SEL

### 8.2. DMA configuration

DMA request | Stream | Direction | Priority
ADC1 | DMA1_Channel1 | Peripheral To Memory | Low
ADC3 | DMA2_Channel5 | Peripheral To Memory | Low
TIM3_CH4/UP | DMA1_Channel3 | Peripheral To Memory | Low
SPI1_RX | DMA1_Channel2 | Peripheral To Memory | Low
SPI1_TX | DMA2_Channel4 | Memory To Peripheral | Low

ADC1: DMA1_Channel1 DMA request Settings:

Mode: | Normal
Peripheral Increment: | Disable
Memory Increment: | Enable *
Peripheral Data Width: | Half Word
Memory Data Width: | Half Word

ADC3: DMA2_Channel5 DMA request Settings:

Mode: | Normal
Peripheral Increment: | Disable
Memory Increment: | Enable *
Peripheral Data Width: | Half Word
Memory Data Width: | Half Word

TIM3_CH4/UP: DMA1_Channel3 DMA request Settings:

Mode: | Normal
Peripheral Increment: | Disable
Memory Increment: | Enable *
Peripheral Data Width: | Half Word
Memory Data Width: | Half Word

SPI1_RX: DMA1_Channel2 DMA request Settings:

Mode: | Normal
Peripheral Increment: | Disable
Memory Increment: | Enable *
Peripheral Data Width: | Byte

Memory Data Width: Byte

SPI1_TX: DMA2_Channel4 DMA request Settings:

Mode: | Normal
Peripheral Increment: | Disable
Memory Increment: | Enable *
Peripheral Data Width: | Byte
Memory Data Width: | Byte

### 8.3. NVIC configuration

8.3.1. NVIC
Interrupt Table | Enable | Preenmption Priority | SubPriority
Non maskable interrupt | true | 0 | 0
Hard fault interrupt | true | 0 | 0
Memory management fault | true | 0 | 0
Prefetch fault, memory access fault | true | 0 | 0
Undefined instruction or illegal state | true | 0 | 0
System service call via SWI instruction | true | 0 | 0
Debug monitor | true | 0 | 0
Pendable request for system service | true | 0 | 0
System tick timer | true | 15 | 0
DMA1 channel1 global interrupt | true | 0 | 0
DMA1 channel2 global interrupt | true | 0 | 0
DMA1 channel3 global interrupt | true | 0 | 0
DMA2 channel4 global interrupt | true | 0 | 0
DMA2 channel5 global interrupt | true | 0 | 0
USB OTG FS global interrupt | true | 0 | 0
PVD/PVM1/PVM2/PVM3/PVM4 interrupts through EXTI lines 16/35/36/37/38 | unused
Flash global interrupt | unused
RCC global interrupt | unused
ADC1 and ADC2 interrupts | unused
CAN1 TX interrupt | unused
CAN1 RX0 interrupt | unused
CAN1 RX1 interrupt | unused
CAN1 SCE interrupt | unused
TIM1 break interrupt and TIM15 global interrupt | unused
TIM1 update interrupt and TIM16 global interrupt | unused
TIM1 trigger and commutation interrupts and TIM17 global interrupt | unused
TIM1 capture compare interrupt | unused
TIM2 global interrupt | unused
TIM3 global interrupt | unused
TIM4 global interrupt | unused
I2C2 event interrupt | unused
I2C2 error interrupt | unused
SPI1 global interrupt | unused
SPI2 global interrupt | unused
EXTI line[15:10] interrupts | unused
ADC3 global interrupt | unused

Interrupt Table | Enable | Preenmption Priority | SubPriority
TIM5 global interrupt | unused
SPI3 global interrupt | unused
QUADSPI global interrupt | unused
FPU global interrupt | unused
CAN2 TX interrupt | unused
CAN2 RX0 interrupt | unused
CAN2 RX1 interrupt | unused
CAN2 SCE interrupt | unused
8.3.2. NVIC Code generation
Enabled interrupt Table | Select for init sequence ordering | Generate IRQ handler | Call HAL handler
Non maskable interrupt | false | true | false
Hard fault interrupt | false | true | false
Memory management fault | false | true | false
Prefetch fault, memory access fault | false | true | false
Undefined instruction or illegal state | false | true | false
System service call via SWI instruction | false | true | false
Debug monitor | false | true | false
Pendable request for system service | false | true | false
System tick timer | false | true | true
DMA1 channel1 global interrupt | false | true | true
DMA1 channel2 global interrupt | false | true | true
DMA1 channel3 global interrupt | false | true | true
DMA2 channel4 global interrupt | false | true | true
DMA2 channel5 global interrupt | false | true | true
USB OTG FS global interrupt | false | true | true

* User modified value

## 9. System Views

9.1. Category view
9.1.1. Current

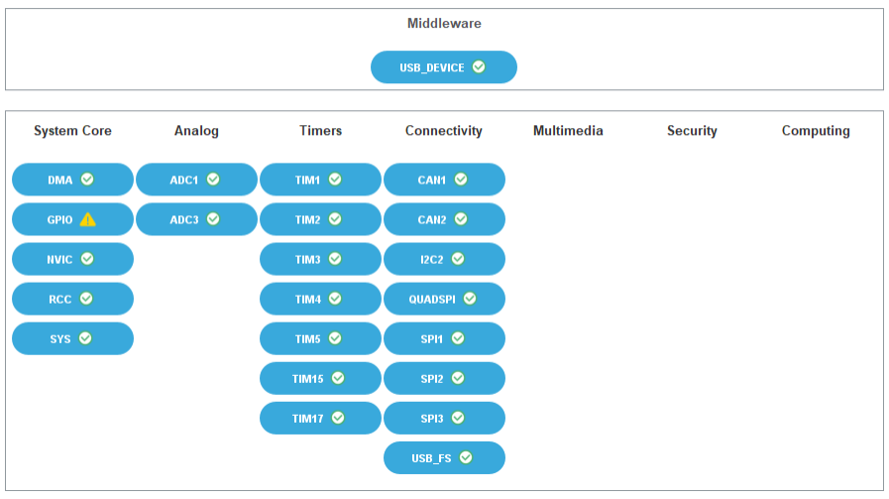
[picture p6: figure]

## 10. Docs & Resources

Type | Link
BSDL files | https://www.st.com/resource/en/bsdl_model/stm32l4_bsdl.zip
IBIS models | https://www.st.com/resource/en/ibis_model/stm32l4_ibis.zip
System View Description | https://www.st.com/resource/en/svd/stm32l4_svd.zip
Presentations | https://www.st.com/resource/en/product_presentation/stm32-stm8_embedded_software_solutions.pdf
Presentations | https://www.st.com/resource/en/product_presentation/stm32_eval-tools_portfolio.pdf
Presentations | https://www.st.com/resource/en/product_presentation/stm32_stm8_functi onal-safety-packages.pdf
Presentations | https://www.st.com/resource/en/product_presentation/stm32l4_marketing-pres.pdf
Presentations | https://www.st.com/resource/en/product_presentation/stm32-stm8_software_development_tools.pdf
Presentations | https://www.st.com/resource/en/product_presentation/microcontrollers-stm32-family-overview.pdf
Brochures | https://www.st.com/resource/en/brochure/brstm32ulp.pdf
Flyers | https://www.st.com/resource/en/flyer/flstm32l4.pdf
Flyers | https://www.st.com/resource/en/flyer/flstm32nucleo.pdf
Flyers | https://www.st.com/resource/en/flyer/flstmcsuite.pdf
Flyers | https://www.st.com/resource/en/flyer/flstm32trust.pdf
Flyers | https://www.st.com/resource/en/flyer/flstm32gui.pdf
Magazine Articles | https://www.st.com/resource/en/magazine/design-elektronik_august2017.pdf
Magazine Articles | https://www.st.com/resource/en/magazine/design-elektronik_october2016.pdf
Product Certifications | https://www.st.com/resource/en/certification_document/sesip-2000002-01-cert.pdf

Product Certifications | https://www.st.com/resource/en/certification_document/sesip-2000002-01-st2.pdf
Product Certifications | https://www.st.com/resource/en/certification_document/psa-certificate_stm32l4.pdf
Application Notes | https://www.st.com/resource/en/application_note/an1181-electrostatic-discharge-sensitivity-measurement-stmicroelectronics.pdf
Application Notes | https://www.st.com/resource/en/application_note/an1709-emc-design-guide-for-stm8-stm32-and-legacy-mcus-stmicroelectronics.pdf
Application Notes | https://www.st.com/resource/en/application_note/an2606-stm32-microcontroller-system-memory-boot-mode-stmicroelectronics.pdf
Application Notes | https://www.st.com/resource/en/application_note/an2639-soldering-recommendations-and-package-information-for-leadfree-ecopack-mcus-and-mpus-stmicroelectronics.pdf
Application Notes | https://www.st.com/resource/en/application_note/an2867-oscillator-design-guide-for-stm8afals-stm32-mcus-and-mpus-stmicroelectronics.pdf
Application Notes | https://www.st.com/resource/en/application_note/an3126-audio-and-waveform-generation-using-the-dac-in-stm32-products-stmicroelectronics.pdf
Application Notes | https://www.st.com/resource/en/application_note/an3154-can-protocol-used-in-the-stm32-bootloader-stmicroelectronics.pdf
Application Notes | https://www.st.com/resource/en/application_note/an3155-usart-protocol-used-in-the-stm32-bootloader-stmicroelectronics.pdf
Application Notes | https://www.st.com/resource/en/application_note/an3156-usb-dfu-protocol-used-in-the-stm32-bootloader-stmicroelectronics.pdf
Application Notes | https://www.st.com/resource/en/application_note/an3236-increase-the-number-of-touchkeys-for-touch-sensing-applications-on-mcus-stmicroelectronics.pdf
Application Notes | https://www.st.com/resource/en/application_note/an3960-esd-considerations-for-touch-sensing-applications-on-mcus-stmicroelectronics.pdf
Application Notes | https://www.st.com/resource/en/application_note/an4013-stm32-crossseries-timer-overview-stmicroelectronics.pdf
Application Notes | https://www.st.com/resource/en/application_note/an4221-i2c-protocol-

| used-in-the-stm32-bootloader-stmicroelectronics.pdf
Application Notes | https://www.st.com/resource/en/application_note/an4229-how-to-implement-a-vocoder-solution-using-stm32-microcontrollers-stmicroelectronics.pdf
Application Notes | https://www.st.com/resource/en/application_note/an4277-using-stm32-device-pwm-shutdown-features-for-motor-control-and-digital-power-conversion-stmicroelectronics.pdf
Application Notes | https://www.st.com/resource/en/application_note/an4286-spi-protocol-used-in-the-stm32-bootloader-stmicroelectronics.pdf
Application Notes | https://www.st.com/resource/en/application_note/an4299-improve-conducted-noise-robustness-for-touch-sensing-applications-on-mcus-stmicroelectronics.pdf
Application Notes | https://www.st.com/resource/en/application_note/an4310-sampling-capacitor-selection-guide-for-touch-sensing-applications-on-mcus-stmicroelectronics.pdf
Application Notes | https://www.st.com/resource/en/application_note/an4312-design-with-surface-sensors-for-touch-sensing-applications-on-mcus-stmicroelectronics.pdf
Application Notes | https://www.st.com/resource/en/application_note/an4316-tuning-a-touch-sensing-application-on-mcus-stmicroelectronics.pdf
Application Notes | https://www.st.com/resource/en/application_note/an4555-getting-started-with-stm32l4-series-and-stm32l4-series-hardware-development-stmicroelectronics.pdf
Application Notes | https://www.st.com/resource/en/application_note/an4566-extending-the-dac-performance-of-stm32-microcontrollers-stmicroelectronics.pdf
Application Notes | https://www.st.com/resource/en/application_note/an4612-migrating-from-stm32l1-series-to-stm32l4-series-and-stm32l4-series-microcontrollers-stmicroelectronics.pdf
Application Notes | https://www.st.com/resource/en/application_note/an4616-migrating-from-stm32f401-and-stm32f411-lines-to-stm32l4-series-and-stm32l4-series-microcontrollers-stmicroelec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
Application Notes | https://www.st.com/resource/en/application_note/an4621-stm32l4-and-stm32l4-ultralowpower-features-overview-stmicroelectronics.pdf

Application Notes | https://www.st.com/resource/en/application_note/an4629-adc-hardware-oversampling-for-microcontrollers-of-the-stm32-l0-and-l4-series-stmicroelectronics.pdf
Application Notes | https://www.st.com/resource/en/application_note/an4635-minimization-of-power-consumption-using-lpuart-for-stm32-microcontrollers-stmicroelectronics.pdf
Application Notes | https://www.st.com/resource/en/application_note/an4649-migrating-from-stm32f1-series-to-stm32l4-series--stm32l4-series-microntrollers-stmicroelectronics.pdf
Application Notes | https://www.st.com/resource/en/application_note/an4655-virtually-increasing-the-number-of-serial-communication-peripherals-in-stm32-applications-stmicroelectronics.p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
Application Notes | https://www.st.com/resource/en/application_note/an4726-stm32cube-firmware-examples-for-stm32l4-series-and-stm32l4-series-stmicroelectronics.pdf
Application Notes | https://www.st.com/resource/en/application_note/an4729-stm32l0l4-firewall-overview-stmicroelectronics.pdf
Application Notes | https://www.st.com/resource/en/application_note/an4730-using-the-firewall-embedded-in-stm32l0l4l4-series-mcus-for-secure-access-to-sensitive-parts-of-code-and-data-s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
Application Notes | https://www.st.com/resource/en/application_note/an4746-optimizing-power-and-performance-with-stm32l4-and-stm32l4-series-microcontrollers-stmicroelectronics.pdf
Application Notes | https://www.st.com/resource/en/application_note/an4750-handling-of-soft-errors-in-stm32-applications-stmicroelectronics.pdf
Application Notes | https://www.st.com/resource/en/application_note/an4759-using-the-hardware-realtime-clock-rtc-and-the-tamper-management-unit-tamp-with-stm32-microcontrollers-stmicroe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
Application Notes | https://www.st.com/resource/en/application_note/an4776-generalpurpose-timer-cookbook-for-stm32-microcontrollers-stmicroelectronics.pdf
Application Notes | https://www.st.com/resource/en/application_note/an4803-highspeed-si-simulations-using-ibis-and-boardlevel-simulations-using-hyperlynx-si-on-stm32-mcus-and-mpus-stmic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
Application Notes | https://www.st.com/resource/en/application_note/an4809-migrating-

| between-stm32l0-series-and-stm32l4-series--stm32l4-series-microcontrollers-stmicroelectronics.pdf
Application Notes | https://www.st.com/resource/en/application_note/an4821-migrating-from-stm32f405415-line-and-stm32f407417-line-to-stm32l4-series-and-stm32l4-series-microcontrollers-s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
Application Notes | https://www.st.com/resource/en/application_note/an4822-migrating-between-stm32l476xx486xx-and-stm32l496xx4a6xx-microcontrollers-stmicroelectronics.pdf
Application Notes | https://www.st.com/resource/en/application_note/an4831-migrating-from-stm32f2x5-line-to-stm32l4-series-and-stm32l4-series-microcontrollers-stmicroelectronics.pdf
Application Notes | https://www.st.com/resource/en/application_note/an4832-migrating-from-stm32f303-line-to-stm32l4-series-and-stm32l4-series-microcontrollers-stmicroelectronics.pdf
Application Notes | https://www.st.com/resource/en/application_note/an4908-stm32-usart-automatic-baud-rate-detection-stmicroelectronics.pdf
Application Notes | https://www.st.com/resource/en/application_note/an4989-stm32-microcontroller-debug-toolbox-stmicroelectronics.pdf
Application Notes | https://www.st.com/resource/en/application_note/an4990-getting-started-with-sigmadelta-digital-interface-on-applicable-stm32-microcontrollers-stmicroelectronics.pdf
Application Notes | https://www.st.com/resource/en/application_note/an4995-using-an-electromyogram-technique-to-detect-muscle-activity-stmicroelectronics.pdf
Application Notes | https://www.st.com/resource/en/application_note/an5012-analogtodigital-audio-conversion-example-using-stm32l4-series-microcontroller-peripherals-stmicroelectronics.p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
Application Notes | https://www.st.com/resource/en/application_note/an5020-digital-camera-interface-dcmi-on-stm32-mcus-stmicroelectronics.pdf
Application Notes | https://www.st.com/resource/en/application_note/an5027-interfacing-pdm-digital-microphones-using-stm32-mcus-and-mpus-stmicroelectronics.pdf
Application Notes | https://www.st.com/resource/en/application_note/an5036-thermal-management-guidelines-for-stm32-applications-stmicroelectronics.pdf

Application Notes | https://www.st.com/resource/en/application_note/an5105-getting-started-with-touch-sensing-control-on-stm32-microcontrollers-stmicroelectronics.pdf
Application Notes | https://www.st.com/resource/en/application_note/an5138-migrating-from-stm32l4-and-stm32l4-to-stm32l5-series-microcontrollers-stmicroelectronics.pdf
Application Notes | https://www.st.com/resource/en/application_note/an5408-migrating-from-stm32l0-stm32l1-and-stm32l4-series-associated-with-sx12xx-transceivers-to-stm32wl-series-microc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
Application Notes | https://www.st.com/resource/en/application_note/an5543-enhanced-methods-to-handle-spi-communication-on-stm32-devices-stmicroelectronics.pdf
Application Notes | https://www.st.com/resource/en/application_note/an4943-using-the-stm32-chromart-accelerator-to-refresh-an-lcdtft-display-stmicroelectronics.pdf
Application Notes | https://www.st.com/resource/en/application_note/an5690-vrefbuf-peripheral-applications-and-trimming-technique-stmicroelectronics.pdf
Application Notes | https://www.st.com/resource/en/application_note/an4760-quadspi-interface-on-stm32-microcontrollers-and-microprocessors--stmicroelectronics.pdf
Application Notes | https://www.st.com/resource/en/application_note/an4899-stm32-microcontroller-gpio-hardware-settings-and-lowpower-consumption-stmicroelectronics.pdf
Application Notes | https://www.st.com/resource/en/application_note/an5612-esd-protection-of-stm32-mcus-and-mpus-stmicroelectronics.pdf
Application Notes | https://www.st.com/resource/en/application_note/an5156-introduction-to-stm32-microcontrollers-security-stmicroelectronics.pdf
Application Notes | https://www.st.com/resource/en/application_note/an2548-using-the-stm32f0f1f3cxgxlx-series-dma-controller-stmicroelectronics.pdf
Application Notes | https://www.st.com/resource/en/application_note/an4991-how-to-wake-up-an-stm32-microcontroller-from-lowpower-mode-with-the-usart-or-the-lpuart-stmicroelectronics.pdf
Application Notes | https://www.st.com/resource/en/application_note/an4978-design- recommendations-for-stm32l4xxxx-with-external-smps-for-ultra-low-

| power-applications-with-high-performance-stmicroelectronics.pdf
Application Notes | https://www.st.com/resource/en/application_note/an4838-introduction-to-memory-protection-unit-management-on-stm32-mcus-stmicroelectronics.pdf
Application Notes | https://www.st.com/resource/en/application_note/an4230-random-number-generation-validation-using-nist-statistical-test-suite-for-stm32-microcontrollers-stmicroelectr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
Application Notes | https://www.st.com/resource/en/application_note/an4879-introduction-to-usb-hardware-and-pcb-guidelines-using-stm32-mcus-stmicroelectronics.pdf
Application Notes | https://www.st.com/resource/en/application_note/an5372-migrating-from-stm32l4-and-stm32l4--to-stm32u5-mcus-stmicroelectronics.pdf
Application Notes | https://www.st.com/resource/en/application_note/an5225-introduction-to-usb-typec-power-delivery-for-stm32-mcus-and-mpus-stmicroelectronics.pdf
Application Notes | https://www.st.com/resource/en/application_note/an4894-how-to-use-eeprom-emulation-on-stm32-mcus-stmicroelectronics.pdf
Application Notes | https://www.st.com/resource/en/application_note/an2834-how-to-optimize-the-adc-accuracy-in-the-stm32-mcus-stmicroelectronics.pdf
Application Notes | https://www.st.com/resource/en/application_note/an5816-how-to-build-stm32-lpbam-application-using-stm32cubemx-stmicroelectronics.pdf
Application Notes | https://www.st.com/resource/en/application_note/an5537-how-to-use-adc-oversampling-techniques-to-improve-signaltonoise-ratio-on-stm32-mcus-stmicroelectronics.pdf
Application Notes for related Tools & Software | https://www.st.com/resource/en/application_note/an1202_freertos_guide-freertos-guide-stmicroelectronics.pdf
Application Notes for related Tools & Software | https://www.st.com/resource/en/application_note/an1602_semihosting_in_truestudio-how-to-do-semihosting-in-truestudio-stmicroelectronics.pdf
Application Notes for related Tools & Software | https://www.st.com/resource/en/application_note/an1801_stm32cubeprogrammer_in_truestudio-installing-stm32cubeprogrammer-in-truestudio-stmicroelectronics.pdf

Application Notes for related Tools & Software | https://www.st.com/resource/en/application_note/atollic_editing_keyboard_shortcuts-atollic-editing-keyboard-shortcuts-stmicroelectronics.pdf
Application Notes for related Tools & Software | https://www.st.com/resource/en/application_note/iar_to_atollic_truestudio_migration_guide-truestudio-for-arm-migration-guide-iar-embedded-workbench-to-truestudio-stm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
Application Notes for related Tools & Software | https://www.st.com/resource/en/application_note/stm32cubemx_installation_in_truestudio-stm32cubemx-installation-in-truestudio-stmicroelectronics.pdf
Application Notes for related Tools & Software | https://www.st.com/resource/en/application_note/an4044-floating-point-unit-demonstration-on-stm32-microcontrollers-stmicroelectronics.pdf
Application Notes for related Tools & Software | https://www.st.com/resource/en/application_note/an4323-getting-started-with-stemwin-library-stmicroelectronics.pdf
Application Notes for related Tools & Software | https://www.st.com/resource/en/application_note/an4435-guidelines-for-obtaining-ulcsaiec-607301603351-class-b-certification-in-any-stm32-application-stmicroelectroni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
Application Notes for related Tools & Software | https://www.st.com/resource/en/application_note/an4631-how-to-calibrate-an-stm32l0xx-internal-rc-oscillator-stmicroelectronics.pdf
Application Notes for related Tools & Software | https://www.st.com/resource/en/application_note/an4635-minimization-of-power-consumption-using-lpuart-for-stm32-microcontrollers-stmicroelectronics.pdf
Application Notes for related Tools & Software | https://www.st.com/resource/en/application_note/an4657-stm32-inapplication-programming-iap-using-the-usart-stmicroelectronics.pdf
Application Notes for related Tools & Software | https://www.st.com/resource/en/application_note/an4666-parallel-synchronous-transmission-using-gpio-and-dma-stmicroelectronics.pdf
Application Notes for related Tools & Software | https://www.st.com/resource/en/application_note/an4701-proprietary-code-readout-protection-on-microcontrollers-of-the-stm32f4-series-stmicroelectronics.pdf
Application Notes | https://www.st.com/resource/en/application_note/an4726-stm32cube-

for related Tools & Software | firmware-examples-for-stm32l4-series-and-stm32l4-series-stmicroelectronics.pdf
Application Notes for related Tools & Software | https://www.st.com/resource/en/application_note/an4736-how-to-calibrate-stm32l4-series-microcontrollers-internal-rc-oscillator-stmicroelectronics.pdf
Application Notes for related Tools & Software | https://www.st.com/resource/en/application_note/an4758-proprietary-code-readout-protection-on-stm32l4-stm32l4-stm32g4-and-stm32wb-series-mcus-stmicroelectronics.pdf
Application Notes for related Tools & Software | https://www.st.com/resource/en/application_note/an4759-using-the-hardware-realtime-clock-rtc-and-the-tamper-management-unit-tamp-with-stm32-microcontrollers-stmicroe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
Application Notes for related Tools & Software | https://www.st.com/resource/en/application_note/an4767-onthefly-firmware-update-for-dual-bank-stm32-microcontrollers-stmicroelectronics.pdf
Application Notes for related Tools & Software | https://www.st.com/resource/en/application_note/an4834-implementation-of-transmitters-and-receivers-for-infrared-remote-control-protocols-with-stm32cube-stmicroelect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
Application Notes for related Tools & Software | https://www.st.com/resource/en/application_note/an4841-digital-signal-processing-for-stm32-microcontrollers-using-cmsis-stmicroelectronics.pdf
Application Notes for related Tools & Software | https://www.st.com/resource/en/application_note/an4968-proprietary-code-read-out-protection-pcrop-on-stm32f72xxx-and-stm32f73xxx-microcontrollers-stmicroelectronics.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
Application Notes for related Tools & Software | https://www.st.com/resource/en/application_note/an5054-secure-programming-using-stm32cubeprogrammer-stmicroelectronics.pdf
Application Notes for related Tools & Software | https://www.st.com/resource/en/application_note/an5056-integration-guide-for-the-xcubesbsfu-stm32cube-expansion-package-stmicroelectronics.pdf
Application Notes for related Tools & Software | https://www.st.com/resource/en/application_note/an5282-using-xcuberccalib-software-to-calibrate-stm32wb-series-internal-rc-oscillators-stmicroelectronics.pdf

Application Notes
for related Tools

https://www.st.com/resource/en/application_note/an5360-getting-startedwith-projects-based-on-the-stm32mp1-series-in-stm32cubeide-

& Software | stmicroelectronics.pdf
Application Notes for related Tools & Software | https://www.st.com/resource/en/application_note/an5361-getting-started-with-projects-based-on-dualcore-stm32h7-microcontrollers-in-stm32cubeide-stmicroelectronics.pd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
Application Notes for related Tools & Software | https://www.st.com/resource/en/application_note/an5394-getting-started-with-projects-based-on-the-stm32l5-series-in-stm32cubeide-stmicroelectronics.pdf
Application Notes for related Tools & Software | https://www.st.com/resource/en/application_note/an5418-how-to-build-a-simple-usbpd-sink-application-with-stm32cubemx-stmicroelectronics.pdf
Application Notes for related Tools & Software | https://www.st.com/resource/en/application_note/an5426-migrating-graphics-middleware-projects-from-stm32cubemx-540-to-stm32cubemx-550-stmicroelectronics.pdf
Application Notes for related Tools & Software | https://www.st.com/resource/en/application_note/an5564-getting-started-with-projects-based-on-dualcore-stm32wl-microcontrollers-in-stm32cubeide-stmicroelectronics.pd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
Application Notes for related Tools & Software | https://www.st.com/resource/en/application_note/an4865-lowpower-timer-lptim-applicative-use-cases-on-stm32-mcus-and-mpus-stmicroelectronics.pdf
Application Notes for related Tools & Software | https://www.st.com/resource/en/application_note/an5676-how-to-calibrate-internal-rc-oscillators-on-stm32u5-series-stmicroelectronics.pdf
Application Notes for related Tools & Software | https://www.st.com/resource/en/application_note/an5698-adapting-the-xcubestl-functional-safety-package-for-stm32-iec-61508-compliant-to-other-safety-standards-stmicr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
Application Notes for related Tools & Software | https://www.st.com/resource/en/application_note/an5731-stm32cubemx-and-stm32cubeide-threadsafe-solution-stmicroelectronics.pdf
Application Notes for related Tools & Software | https://www.st.com/resource/en/application_note/an5857-using-xcuberccalib-software-to-calibrate-stm32c0-series-internal-rc-oscillator-stmicroelectronics.pdf
Application Notes for related Tools & Software | https://www.st.com/resource/en/application_note/an4502-stm32-smbuspmbus-expansion-package-for-stm32cube-stmicroelectronics.pdf

Application Notes for related Tools & Software | https://www.st.com/resource/en/application_note/an5126-how-to-calibrate-internal-oscillators-on-stm32g0-mcus-stmicroelectronics.pdf
Application Notes for related Tools & Software | https://www.st.com/resource/en/application_note/an4777-how-to-optimize-power-consumption-on-stm32-mcus-stmicroelectronics.pdf
Application Notes for related Tools & Software | https://www.st.com/resource/en/application_note/an5952-how-to-use-cmake-in-stm32cubeide-stmicroelectronics.pdf
Application Notes for related Tools & Software | https://www.st.com/resource/en/application_note/an4894-how-to-use-eeprom-emulation-on-stm32-mcus-stmicroelectronics.pdf
Design Notes & Tips | https://www.st.com/resource/en/design_tip/dt0117-microphone-array-beamforming-in-the-pcm-and-pdm-domain-stmicroelectronics.pdf
Device Option Lists | https://www.st.com/resource/en/device_option_list/opl_stm32l496_1m.zip
Device Option Lists | https://www.st.com/resource/en/device_option_list/opl_stm32l496_1m_sm ps.zip
Errata Sheets | https://www.st.com/resource/en/errata_sheet/es0335-stm32l496xx4a6xx-device-errata-stmicroelectronics.pdf
Datasheet | https://www.st.com/resource/en/datasheet/dm00284211.pdf
Programming Manuals | https://www.st.com/resource/en/programming_manual/pm0214-stm32-cortexm4-mcus-and-mpus-programming-manual-stmicroelectronics.pdf
Reference Manuals | https://www.st.com/resource/en/reference_manual/rm0351-stm32l47xxx-stm32l48xxx-stm32l49xxx-and-stm32l4axxx-advanced-armbased-32bit-mcus-stmicroelectronics.pdf
Technical Notes & Articles | https://www.st.com/resource/en/technical_note/tn1163-description-of-wlcsp-for-microcontrollers-and-recommendations-for-its-use-stmicroelectronics.pdf
Technical Notes & Articles | https://www.st.com/resource/en/technical_note/tn1204-tape-and-reel-shipping-media-for-stm32-microcontrollers-in-bga-packages-stmicroelectronics.pdf
Technical Notes | https://www.st.com/resource/en/technical_note/tn1205-tape-and-reel-

& Articles | shipping-media-for-stm8-and-stm32-microcontrollers-in-fpn-packages-stmicroelectronics.pdf
Technical Notes & Articles | https://www.st.com/resource/en/technical_note/tn1206-tape-and-reel-shipping-media-for-stm8-and-stm32-microcontrollers-in-qfp-packages-stmicroelectronics.pdf
Technical Notes & Articles | https://www.st.com/resource/en/technical_note/tn1207-tape-and-reel-shipping-media-for-stm8-and-stm32-microcontrollers-in-so-packages-stmicroelectronics.pdf
Technical Notes & Articles | https://www.st.com/resource/en/technical_note/tn1208-tape-and-reel-shipping-media-for-stm8-and-stm32-microcontrollers-in-tssop-and-ssop-packages-stmicroelectronics.p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
Technical Notes & Articles | https://www.st.com/resource/en/technical_note/tn1433-reference-device-marking-schematics-for-stm32-microcontrollers-and-microprocessors-stmicroelectronics.pdf
User Manuals | https://www.st.com/resource/en/user_manual/um2305-stm32l4-and-stm32l4-series-safety-manual-stmicroelectronics.pdf
User Manuals | https://www.st.com/resource/en/user_manual/um3166-stm32l4-and-stm32l4-series-ulcsaiec-607301603351-selftest-library-user-guide-stmicroelectronics.pdf

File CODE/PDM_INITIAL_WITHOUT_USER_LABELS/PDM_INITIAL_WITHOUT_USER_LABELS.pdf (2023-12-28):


09/12/2023

PDM_INITIAL_WITHOUT_USER_LABELS Project Configuration Report

## 1. Description

### 1.1. Project

Project Name | PDM_INITIAL_WITHOUT_USER_L ABELS
Board Name | custom
Generated with: | STM32CubeMX 6.6.1
Date | 12/09/2023

### 1.2. MCU

MCU Series | STM32L4
MCU Line | STM32L4x6
MCU name | STM32L496ZGTx
MCU Package | LQFP144
MCU Pin number | 144

### 1.3. Core(s) information

Core(s) | Arm Cortex-M4

## 2. Pinout Configuration

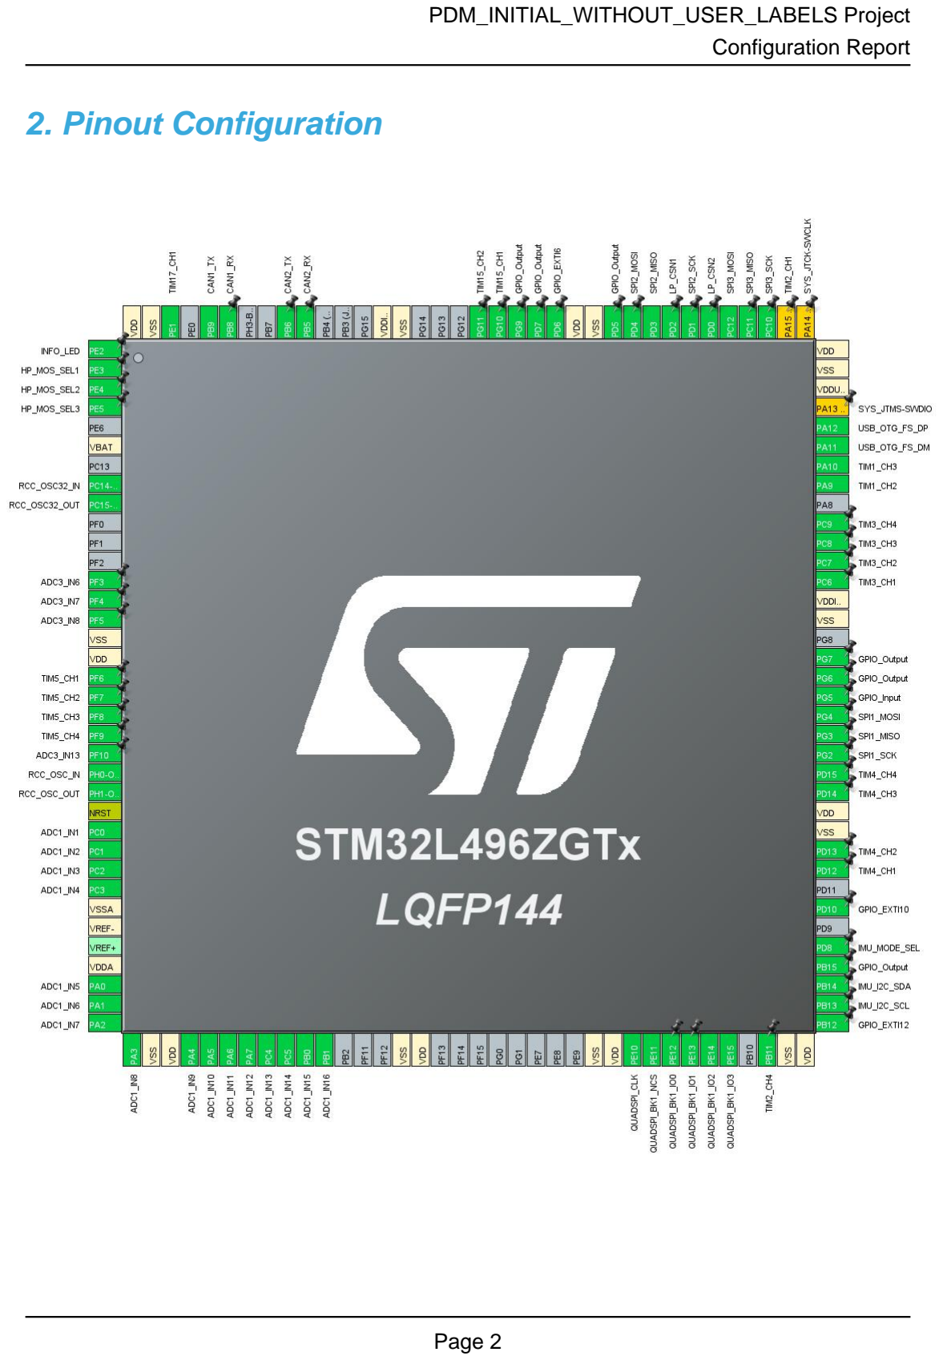
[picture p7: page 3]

## 3. Pins Configuration

Pin Number LQFP144 | Pin Name (function after reset) | Pin Type | Alternate Function(s) | Label
1 | PE2 * | I/O | GPIO_Output | INFO_LED
2 | PE3 * | I/O | GPIO_Output | HP_MOS_SEL1
3 | PE4 * | I/O | GPIO_Output | HP_MOS_SEL2
4 | PE5 * | I/O | GPIO_Output | HP_MOS_SEL3
6 | VBAT | Power
8 | PC14-OSC32_IN (PC14) | I/O | RCC_OSC32_IN
9 | PC15-OSC32_OUT (PC15) | I/O | RCC_OSC32_OUT
13 | PF3 | I/O | ADC3_IN6
14 | PF4 | I/O | ADC3_IN7
15 | PF5 | I/O | ADC3_IN8
16 | VSS | Power
17 | VDD | Power
18 | PF6 | I/O | TIM5_CH1
19 | PF7 | I/O | TIM5_CH2
20 | PF8 | I/O | TIM5_CH3
21 | PF9 | I/O | TIM5_CH4
22 | PF10 | I/O | ADC3_IN13
23 | PH0-OSC_IN (PH0) | I/O | RCC_OSC_IN
24 | PH1-OSC_OUT (PH1) | I/O | RCC_OSC_OUT
25 | NRST | Reset
26 | PC0 | I/O | ADC1_IN1
27 | PC1 | I/O | ADC1_IN2
28 | PC2 | I/O | ADC1_IN3
29 | PC3 | I/O | ADC1_IN4
30 | VSSA | Power
31 | VREF- | Power
33 | VDDA | Power
34 | PA0 | I/O | ADC1_IN5
35 | PA1 | I/O | ADC1_IN6
36 | PA2 | I/O | ADC1_IN7
37 | PA3 | I/O | ADC1_IN8
38 | VSS | Power
39 | VDD | Power
40 | PA4 | I/O | ADC1_IN9
41 | PA5 | I/O | ADC1_IN10
42 | PA6 | I/O | ADC1_IN11

Pin Number LQFP144 | Pin Name (function after reset) | Pin Type | Alternate Function(s) | Label
43 | PA7 | I/O | ADC1_IN12
44 | PC4 | I/O | ADC1_IN13
45 | PC5 | I/O | ADC1_IN14
46 | PB0 | I/O | ADC1_IN15
47 | PB1 | I/O | ADC1_IN16
51 | VSS | Power
52 | VDD | Power
61 | VSS | Power
62 | VDD | Power
63 | PE10 | I/O | QUADSPI_CLK
64 | PE11 | I/O | QUADSPI_BK1_NCS
65 | PE12 | I/O | QUADSPI_BK1_IO0
66 | PE13 | I/O | QUADSPI_BK1_IO1
67 | PE14 | I/O | QUADSPI_BK1_IO2
68 | PE15 | I/O | QUADSPI_BK1_IO3
70 | PB11 | I/O | TIM2_CH4
71 | VSS | Power
72 | VDD | Power
73 | PB12 | I/O | GPIO_EXTI12
74 | PB13 | I/O | I2C2_SCL | IMU_I2C_SCL
75 | PB14 | I/O | I2C2_SDA | IMU_I2C_SDA
76 | PB15 * | I/O | GPIO_Output
77 | PD8 * | I/O | GPIO_Output | IMU_MODE_SEL
79 | PD10 | I/O | GPIO_EXTI10
81 | PD12 | I/O | TIM4_CH1
82 | PD13 | I/O | TIM4_CH2
83 | VSS | Power
84 | VDD | Power
85 | PD14 | I/O | TIM4_CH3
86 | PD15 | I/O | TIM4_CH4
87 | PG2 | I/O | SPI1_SCK
88 | PG3 | I/O | SPI1_MISO
89 | PG4 | I/O | SPI1_MOSI
90 | PG5 * | I/O | GPIO_Input
91 | PG6 * | I/O | GPIO_Output
92 | PG7 * | I/O | GPIO_Output
94 | VSS | Power
95 | VDDIO2 | Power
96 | PC6 | I/O | TIM3_CH1

Pin Number LQFP144 | Pin Name (function after reset) | Pin Type | Alternate Function(s) | Label
97 | PC7 | I/O | TIM3_CH2
98 | PC8 | I/O | TIM3_CH3
99 | PC9 | I/O | TIM3_CH4
101 | PA9 | I/O | TIM1_CH2
102 | PA10 | I/O | TIM1_CH3
103 | PA11 | I/O | USB_OTG_FS_DM
104 | PA12 | I/O | USB_OTG_FS_DP
105 | PA13 (JTMS/SWDIO) ** | I/O | SYS_JTMS-SWDIO
106 | VDDUSB | Power
107 | VSS | Power
108 | VDD | Power
109 | PA14 (JTCK/SWCLK) ** | I/O | SYS_JTCK-SWCLK
110 | PA15 (JTDI) ** | I/O | TIM2_CH1
111 | PC10 | I/O | SPI3_SCK
112 | PC11 | I/O | SPI3_MISO
113 | PC12 | I/O | SPI3_MOSI
114 | PD0 * | I/O | GPIO_Output | LP_CSN2
115 | PD1 | I/O | SPI2_SCK
116 | PD2 * | I/O | GPIO_Output | LP_CSN1
117 | PD3 | I/O | SPI2_MISO
118 | PD4 | I/O | SPI2_MOSI
119 | PD5 * | I/O | GPIO_Output
120 | VSS | Power
121 | VDD | Power
122 | PD6 | I/O | GPIO_EXTI6
123 | PD7 * | I/O | GPIO_Output
124 | PG9 * | I/O | GPIO_Output
125 | PG10 | I/O | TIM15_CH1
126 | PG11 | I/O | TIM15_CH2
130 | VSS | Power
131 | VDDIO2 | Power
135 | PB5 | I/O | CAN2_RX
136 | PB6 | I/O | CAN2_TX
139 | PB8 | I/O | CAN1_RX
140 | PB9 | I/O | CAN1_TX
142 | PE1 | I/O | TIM17_CH1
143 | VSS | Power
144 | VDD | Power

* The pin is affected with an I/O function
** The pin is affected with a peripheral function but no peripheral mode is activated

## 4. Clock Tree Configuration

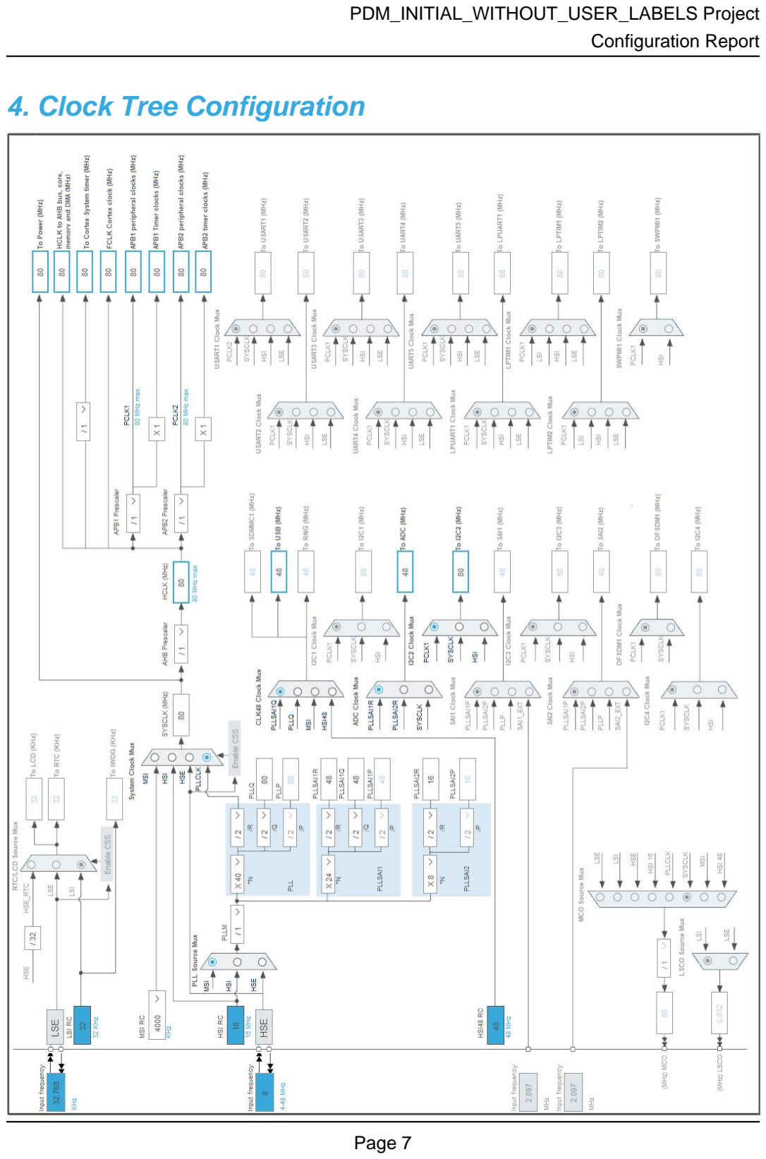
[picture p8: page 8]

## 5. Software Project

### 5.1. Project Settings

Name | Value
Project Name | PDM_INITIAL_WITHOUT_USER_LABELS
Project Folder | C:\Users\Karol\Documents\GitHub\PDM\CODE\PDM_INITIAL_WITHOUT_USER
Toolchain / IDE | EWARM V8.32
Firmware Package Name and Version | STM32Cube FW_L4 V1.17.2
Application Structure | Advanced
Generate Under Root | No
Do not generate the main() | No
Minimum Heap Size | 0x200
Minimum Stack Size | 0x400

### 5.2. Code Generation Settings

Name | Value
STM32Cube MCU packages and embedded software | Copy all used libraries into the project folder
Generate peripheral initialization as a pair of '.c/.h' files | No
Backup previously generated files when re-generating | No
Keep User Code when re-generating | Yes
Delete previously generated files when not re-generated | Yes
Set all free pins as analog (to optimize the power consumption) | No
Enable Full Assert | No

### 5.3. Advanced Settings - Generated Function Calls

Rank | Function Name | Peripheral Instance Name
1 | SystemClock_Config | RCC
2 | MX_GPIO_Init | GPIO
3 | MX_DMA_Init | DMA
4 | MX_ADC1_Init | ADC1
5 | MX_ADC3_Init | ADC3
6 | MX_CAN1_Init | CAN1
7 | MX_CAN2_Init | CAN2
8 | MX_QUADSPI_Init | QUADSPI
9 | MX_SPI1_Init | SPI1
10 | MX_SPI3_Init | SPI3
11 | MX_TIM4_Init | TIM4

Rank | Function Name | Peripheral Instance Name
12 | MX_TIM3_Init | TIM3
13 | MX_TIM2_Init | TIM2
14 | MX_I2C2_Init | I2C2
15 | MX_TIM1_Init | TIM1
16 | MX_TIM5_Init | TIM5
17 | MX_TIM15_Init | TIM15
18 | MX_TIM17_Init | TIM17
19 | MX_SPI2_Init | SPI2
20 | MX_USB_DEVICE_Init | USB_DEVICE

## 6. Power Consumption Calculator report

### 6.1. Microcontroller Selection

Series | STM32L4
Line | STM32L4x6
MCU | STM32L496ZGTx
Datasheet | DS11585_Rev2

### 6.2. Parameter Selection

Temperature | 25
Vdd | 3.0

### 6.3. Battery Selection

Battery | Li-SOCL2(A3400)
Capacity | 3400.0 mAh
Self Discharge | 0.08 %/month
Nominal Voltage | 3.6 V
Max Cont Current | 100.0 mA
Max Pulse Current | 200.0 mA
Cells in series | 1
Cells in parallel | 1

### 6.4. Sequence

Step | Step1 | Step2
Mode | RUN | STOP2
Vdd | 3.0 | 3.0
Voltage Source | Battery | Battery
Range | Range1-High | NoRange
Fetch Type | FLASH | n/a
CPU Frequency | 80 MHz | 0 Hz
Clock Configuration | HSE BYP PLL Flash-ON | ALL CLOCKS OFF
Clock Source Frequency | 4 MHz | 0 Hz
Peripherals
Additional Cons. | 0 mA | 0 mA
Average Current | 10 mA | 2.69 µA
Duration | 0.1 ms | 0.9 ms
DMIPS | 100.0 | 0.0
Ta Max | 104.04 | 105
Category | In DS Table | In DS Table

### 6.5. Results

Sequence Time | 1 ms | Average Current | 1 mA
Battery Life | 4 months, 19 days, 3 hours | Average DMIPS | 100.0 DMIPS

### 6.6. Chart


## 7. Peripherals and Middlewares Configuration

### 7.1. ADC1

IN1: IN1 Single-ended
IN2: IN2 Single-ended
IN3: IN3 Single-ended
IN4: IN4 Single-ended
IN5: IN5 Single-ended
IN6: IN6 Single-ended
IN7: IN7 Single-ended
IN8: IN8 Single-ended
IN9: IN9 Single-ended
IN10: IN10 Single-ended
IN11: IN11 Single-ended
IN12: IN12 Single-ended
IN13: IN13 Single-ended
IN14: IN14 Single-ended
IN15: IN15 Single-ended
mode: IN16 Single-ended
mode: Temperature Sensor Channel mode: Vbat Channel
7.1.1. Parameter Settings:

ADCs_Common_Settings:

Mode | Independent mode
ADC_Settings:
Clock Prescaler | Asynchronous clock mode divided by 1
Resolution | ADC 12-bit resolution
Data Alignment | Right alignment
Scan Conversion Mode | Disabled
Continuous Conversion Mode | Disabled
Discontinuous Conversion Mode | Disabled
DMA Continuous Requests | Disabled
End Of Conversion Selection | End of single conversion
Overrun behaviour | Overrun data preserved
Low Power Auto Wait | Disabled
ADC_Regular_ConversionMode:
Enable Regular Conversions | Enable

Enable Regular Oversampling | Disable
Number Of Conversion | 1
External Trigger Conversion Source | Regular Conversion launched by software
External Trigger Conversion Edge | None
Rank | 1
Channel | Channel 1
Sampling Time | 2.5 Cycles
Offset Number | No offset
ADC_Injected_ConversionMode:
Enable Injected Conversions | Disable
Analog Watchdog 1:
Enable Analog WatchDog1 Mode | false
Analog Watchdog 2:
Enable Analog WatchDog2 Mode | false
Analog Watchdog 3:
Enable Analog WatchDog3 Mode | false

### 7.2. ADC3

IN6: IN6 Differential
IN8: IN8 Single-ended
mode: IN13
7.2.1. Parameter Settings:

ADC_Settings:

Clock Prescaler | Asynchronous clock mode divided by 1
Resolution | ADC 12-bit resolution
Data Alignment | Right alignment
Scan Conversion Mode | Disabled
Continuous Conversion Mode | Disabled
Discontinuous Conversion Mode | Disabled
DMA Continuous Requests | Disabled
End Of Conversion Selection | End of single conversion
Overrun behaviour | Overrun data preserved
Low Power Auto Wait | Disabled
ADC_Regular_ConversionMode:
Enable Regular Conversions | Enable
Enable Regular Oversampling | Disable
Number Of Conversion | 1
External Trigger Conversion Source | Regular Conversion launched by software

External Trigger Conversion Edge | None
Rank | 1
Channel | Channel 6
Sampling Time | 2.5 Cycles
Offset Number | No offset
ADC_Injected_ConversionMode:
Enable Injected Conversions | Disable
Analog Watchdog 1:
Enable Analog WatchDog1 Mode | false
Analog Watchdog 2:
Enable Analog WatchDog2 Mode | false
Analog Watchdog 3:
Enable Analog WatchDog3 Mode | false

### 7.3. CAN1

mode: Activated
7.3.1. Parameter Settings:

Bit Timings Parameters:

Prescaler (for Time Quantum) | 16
Time Quantum | 200.0 *
Time Quanta in Bit Segment 1 | 6 Times *
Time Quanta in Bit Segment 2 | 1 Time
Time for one Bit | 1600 *
Baud Rate | 625000 *
ReSynchronization Jump Width | 1 Time
Basic Parameters:
Time Triggered Communication Mode | Disable
Automatic Bus-Off Management | Disable
Automatic Wake-Up Mode | Disable
Automatic Retransmission | Disable
Receive Fifo Locked Mode | Disable
Transmit Fifo Priority | Disable
Advanced Parameters:
Operating Mode | Normal

### 7.4. CAN2

mode: Activated
7.4.1. Parameter Settings:

Bit Timings Parameters:

Prescaler (for Time Quantum) | 16
Time Quantum | 200.0 *
Time Quanta in Bit Segment 1 | 8 Times *
Time Quanta in Bit Segment 2 | 1 Time
Time for one Bit | 2000 *
Baud Rate | 500000 *
ReSynchronization Jump Width | 1 Time
Basic Parameters:
Time Triggered Communication Mode | Disable
Automatic Bus-Off Management | Disable
Automatic Wake-Up Mode | Disable
Automatic Retransmission | Disable
Receive Fifo Locked Mode | Disable
Transmit Fifo Priority | Disable
Advanced Parameters:
Operating Mode | Normal

### 7.5. I2C2

I2C: I2C
7.5.1. Parameter Settings:

Timing configuration:

Custom Timing | Disabled
I2C Speed Mode | Standard Mode
I2C Speed Frequency (KHz) | 100
Rise Time (ns) | 0
Fall Time (ns) | 0
Coefficient of Digital Filter | 0
Analog Filter | Enabled
Timing | 0x10909CEC *
Slave Features:
Clock No Stretch Mode | Disabled
General Call Address Detection | Disabled

Primary Address Length selection | 7-bit
Dual Address Acknowledged | Disabled
Primary slave address | 0

### 7.6. QUADSPI

QuadSPI Mode: Bank1 with Quad SPI Lines
7.6.1. Parameter Settings:

General Parameters:

Clock Prescaler | 255
Fifo Threshold | 1
Sample Shifting | No Sample Shifting
Flash Size | 1
Chip Select High Time | 1 Cycle
Clock Mode | Low
Flash ID | Flash ID 1
Dual Flash | Disabled

### 7.7. RCC

High Speed Clock (HSE): Crystal/Ceramic Resonator Low Speed Clock (LSE) : Crystal/Ceramic Resonator
7.7.1. Parameter Settings:

System Parameters:

VDD voltage (V) | 3.3
Instruction Cache | Enabled
Prefetch Buffer | Disabled
Data Cache | Enabled
Flash Latency(WS) | 4 WS (5 CPU cycle)
RCC Parameters:
HSI Calibration Value | 64
MSI Calibration Value | 0
MSI Auto Calibration | Enabled
HSE Startup Timout Value (ms) | 100
LSE Startup Timout Value (ms) | 5000
LSE Drive Capability | LSE oscillator low drive capability
Power Parameters:
Power Regulator Voltage Scale | Power Regulator Voltage Scale 1

### 7.8. SPI1

Mode: Full-Duplex Master
7.8.1. Parameter Settings:

Basic Parameters:

Frame Format | Motorola
Data Size | 4 Bits
First Bit | MSB First
Clock Parameters:
Prescaler (for Baud Rate) | 2
Baud Rate | 40.0 MBits/s *
Clock Polarity (CPOL) | Low
Clock Phase (CPHA) | 1 Edge
Advanced Parameters:
CRC Calculation | Disabled
NSSP Mode | Enabled
NSS Signal Type | Software

### 7.9. SPI2

Mode: Full-Duplex Master
7.9.1. Parameter Settings:

Basic Parameters:

Frame Format | Motorola
Data Size | 4 Bits
First Bit | MSB First
Clock Parameters:
Prescaler (for Baud Rate) | 2
Baud Rate | 40.0 MBits/s *
Clock Polarity (CPOL) | Low
Clock Phase (CPHA) | 1 Edge
Advanced Parameters:
CRC Calculation | Disabled
NSSP Mode | Enabled
NSS Signal Type | Software

### 7.10. SPI3

Mode: Full-Duplex Master
7.10.1. Parameter Settings:

Basic Parameters:

Frame Format | Motorola
Data Size | 4 Bits
First Bit | MSB First
Clock Parameters:
Prescaler (for Baud Rate) | 2
Baud Rate | 40.0 MBits/s *
Clock Polarity (CPOL) | Low
Clock Phase (CPHA) | 1 Edge
Advanced Parameters:
CRC Calculation | Disabled
NSSP Mode | Enabled
NSS Signal Type | Software

### 7.11. SYS

Timebase Source: SysTick

### 7.12. TIM1

Channel2: PWM Generation CH2 Channel3: PWM Generation CH3
7.12.1. Parameter Settings:

Counter Settings:

Prescaler (PSC - 16 bits value) | 0
Counter Mode | Up
Counter Period (AutoReload Register - 16 bits value ) | 65535
Internal Clock Division (CKD) | No Division
Repetition Counter (RCR - 8 bits value) | 0
auto-reload preload | Disable
Trigger Output (TRGO) Parameters:
Master/Slave Mode (MSM bit) | Disable (Trigger input effect not delayed)
Trigger Event Selection TRGO | Reset (UG bit from TIMx_EGR)

Trigger Event Selection TRGO2 | Reset (UG bit from TIMx_EGR)
Break And Dead Time management - BRK Configuration:
BRK State | Disable
BRK Polarity | High
BRK Filter (4 bits value) | 0
BRK Sources Configuration
- Digital Input | Disable
- COMP1 | Disable
- COMP2 | Disable
- DFSDM | Disable
Break And Dead Time management - BRK2 Configuration:
BRK2 State | Disable
BRK2 Polarity | High
BRK2 Filter (4 bits value) | 0
BRK2 Sources Configuration
- Digital Input | Disable
- COMP1 | Disable
- COMP2 | Disable
- DFSDM | Disable
Break And Dead Time management - Output Configuration:
Automatic Output State | Disable
Off State Selection for Run Mode (OSSR) | Disable
Off State Selection for Idle Mode (OSSI) | Disable
Lock Configuration | Off
Clear Input:
Clear Input Source | Disable
PWM Generation Channel 2:
Mode | PWM mode 1
Pulse (16 bits value) | 0
Output compare preload | Enable
Fast Mode | Disable
CH Polarity | High
CH Idle State | Reset
PWM Generation Channel 3:
Mode | PWM mode 1
Pulse (16 bits value) | 0
Output compare preload | Enable
Fast Mode | Disable
CH Polarity | High
CH Idle State | Reset

### 7.13. TIM2

Channel4: PWM Generation CH4
7.13.1. Parameter Settings:

Counter Settings:

Prescaler (PSC - 16 bits value) | 0
Counter Mode | Up
Counter Period (AutoReload Register - 32 bits value ) | 4294967295
Internal Clock Division (CKD) | No Division
auto-reload preload | Disable
Trigger Output (TRGO) Parameters:
Master/Slave Mode (MSM bit) | Disable (Trigger input effect not delayed)
Trigger Event Selection TRGO | Reset (UG bit from TIMx_EGR)
Clear Input:
Clear Input Source | Disable
PWM Generation Channel 4:
Mode | PWM mode 1
Pulse (32 bits value) | 0
Output compare preload | Enable
Fast Mode | Disable
CH Polarity | High

### 7.14. TIM3

Channel1: PWM Generation CH1 Channel2: PWM Generation CH2 Channel3: PWM Generation CH3 Channel4: PWM Generation CH4
7.14.1. Parameter Settings:

Counter Settings:

Prescaler (PSC - 16 bits value) | 0
Counter Mode | Up
Counter Period (AutoReload Register - 16 bits value ) | 65535
Internal Clock Division (CKD) | No Division
auto-reload preload | Disable
Trigger Output (TRGO) Parameters:

Master/Slave Mode (MSM bit) | Disable (Trigger input effect not delayed)
Trigger Event Selection TRGO | Reset (UG bit from TIMx_EGR)
Clear Input:
Clear Input Source | Disable
PWM Generation Channel 1:
Mode | PWM mode 1
Pulse (16 bits value) | 0
Output compare preload | Enable
Fast Mode | Disable
CH Polarity | High
PWM Generation Channel 2:
Mode | PWM mode 1
Pulse (16 bits value) | 0
Output compare preload | Enable
Fast Mode | Disable
CH Polarity | High
PWM Generation Channel 3:
Mode | PWM mode 1
Pulse (16 bits value) | 0
Output compare preload | Enable
Fast Mode | Disable
CH Polarity | High
PWM Generation Channel 4:
Mode | PWM mode 1
Pulse (16 bits value) | 0
Output compare preload | Enable
Fast Mode | Disable
CH Polarity | High

### 7.15. TIM4

Channel1: PWM Generation CH1 Channel2: PWM Generation CH2 Channel3: PWM Generation CH3 Channel4: PWM Generation CH4
7.15.1. Parameter Settings:

Counter Settings:

Prescaler (PSC - 16 bits value) | 0
Counter Mode | Up

Counter Period (AutoReload Register - 16 bits value ) | 65535
Internal Clock Division (CKD) | No Division
auto-reload preload | Disable
Trigger Output (TRGO) Parameters:
Master/Slave Mode (MSM bit) | Disable (Trigger input effect not delayed)
Trigger Event Selection TRGO | Reset (UG bit from TIMx_EGR)
Clear Input:
Clear Input Source | Disable
PWM Generation Channel 1:
Mode | PWM mode 1
Pulse (16 bits value) | 0
Output compare preload | Enable
Fast Mode | Disable
CH Polarity | High
PWM Generation Channel 2:
Mode | PWM mode 1
Pulse (16 bits value) | 0
Output compare preload | Enable
Fast Mode | Disable
CH Polarity | High
PWM Generation Channel 3:
Mode | PWM mode 1
Pulse (16 bits value) | 0
Output compare preload | Enable
Fast Mode | Disable
CH Polarity | High
PWM Generation Channel 4:
Mode | PWM mode 1
Pulse (16 bits value) | 0
Output compare preload | Enable
Fast Mode | Disable
CH Polarity | High

### 7.16. TIM5

Channel1: PWM Generation CH1 Channel2: PWM Generation CH2 Channel3: PWM Generation CH3 Channel4: PWM Generation CH4

7.16.1. Parameter Settings:

Counter Settings:

Prescaler (PSC - 16 bits value) | 0
Counter Mode | Up
Counter Period (AutoReload Register - 32 bits value ) | 4294967295
Internal Clock Division (CKD) | No Division
auto-reload preload | Disable
Trigger Output (TRGO) Parameters:
Master/Slave Mode (MSM bit) | Disable (Trigger input effect not delayed)
Trigger Event Selection TRGO | Reset (UG bit from TIMx_EGR)
Clear Input:
Clear Input Source | Disable
PWM Generation Channel 1:
Mode | PWM mode 1
Pulse (32 bits value) | 0
Output compare preload | Enable
Fast Mode | Disable
CH Polarity | High
PWM Generation Channel 2:
Mode | PWM mode 1
Pulse (32 bits value) | 0
Output compare preload | Enable
Fast Mode | Disable
CH Polarity | High
PWM Generation Channel 3:
Mode | PWM mode 1
Pulse (32 bits value) | 0
Output compare preload | Enable
Fast Mode | Disable
CH Polarity | High
PWM Generation Channel 4:
Mode | PWM mode 1
Pulse (32 bits value) | 0
Output compare preload | Enable
Fast Mode | Disable
CH Polarity | High

### 7.17. TIM15

Channel1: PWM Generation CH1 Channel2: PWM Generation CH2
7.17.1. Parameter Settings:

Counter Settings:

Prescaler (PSC - 16 bits value) | 0
Counter Mode | Up
Counter Period (AutoReload Register - 16 bits value ) | 65535
Internal Clock Division (CKD) | No Division
Repetition Counter (RCR - 8 bits value) | 0
auto-reload preload | Disable
Trigger Output (TRGO) Parameters:
Master/Slave Mode (MSM bit) | Disable (Trigger input effect not delayed)
Trigger Event Selection | Reset (UG bit from TIMx_EGR)
Break And Dead Time management - BRK Configuration:
BRK State | Disable
BRK Polarity | High
BRK Sources Configuration
- Digital Input | Disable
- COMP1 | Disable
- COMP2 | Disable
- DFSDM | Disable
Break And Dead Time management - Output Configuration:
Automatic Output State | Disable
Off State Selection for Run Mode (OSSR) | Disable
Off State Selection for Idle Mode (OSSI) | Disable
Lock Configuration | Off
PWM Generation Channel 1:
Mode | PWM mode 1
Pulse (16 bits value) | 0
Output compare preload | Enable
Fast Mode | Disable
CH Polarity | High
CH Idle State | Reset
PWM Generation Channel 2:
Mode | PWM mode 1
Pulse (16 bits value) | 0
Output compare preload | Enable
Fast Mode | Disable
CH Polarity | High

CH Idle State | Reset

### 7.18. TIM17

mode: Activated
Channel1: PWM Generation CH1
7.18.1. Parameter Settings:

Counter Settings:

Prescaler (PSC - 16 bits value) | 0
Counter Mode | Up
Counter Period (AutoReload Register - 16 bits value ) | 65535
Internal Clock Division (CKD) | No Division
Repetition Counter (RCR - 8 bits value) | 0
auto-reload preload | Disable
Break And Dead Time management - BRK Configuration:
BRK State | Disable
BRK Polarity | High
BRK Sources Configuration
- Digital Input | Disable
- COMP1 | Disable
- COMP2 | Disable
- DFSDM | Disable
Break And Dead Time management - Output Configuration:
Automatic Output State | Disable
Off State Selection for Run Mode (OSSR) | Disable
Off State Selection for Idle Mode (OSSI) | Disable
Lock Configuration | Off
PWM Generation Channel 1:
Mode | PWM mode 1
Pulse (16 bits value) | 0
Output compare preload | Enable
Fast Mode | Disable
CH Polarity | High
CH Idle State | Reset

### 7.19. USB_OTG_FS

Mode: Device_Only

7.19.1. Parameter Settings:
Speed | Full Speed 12MBit/s
Low power | Disabled
Battery charging | Disabled
Link Power Management | Disabled
Use dedicated end point 1 interrupt | Disabled
VBUS sensing | Disabled
Signal start of frame | Disabled

### 7.20. USB_DEVICE

Class For FS IP: Communication Device Class (Virtual Port Com)
7.20.1. Parameter Settings:

Basic Parameters:

USBD_MAX_NUM_INTERFACES (Maximum number of supported interfaces) | 1
USBD_MAX_NUM_CONFIGURATION (Maximum number of supported configuration) | 1
USBD_MAX_STR_DESC_SIZ (Maximum size for the string descriptors) | 512
USBD_SELF_POWERED (Enabled self power) | Enabled
USBD_DEBUG_LEVEL (USBD Debug Level) | 0: No debug message
USBD_LPM_ENABLED (Link Power Management) | 1: Link Power Management supported
Class Parameters:
USB CDC Rx Buffer Size | 2048
USB CDC Tx Buffer Size | 2048
7.20.2. Device Descriptor:

Device Descriptor:

VID (Vendor IDentifier) | 1155
LANGID_STRING (Language Identifier) | English(United States)
MANUFACTURER_STRING (Manufacturer Identifier) | STMicroelectronics
Device Descriptor FS:
PID (Product IDentifier) | 22336
PRODUCT_STRING (Product Identifier) | STM32 Virtual ComPort
CONFIGURATION_STRING (Configuration Identifier) | CDC Config
INTERFACE_STRING (Interface Identifier) | CDC Interface

* User modified value

## 8. System Configuration

### 8.1. GPIO configuration

IP | Pin | Signal | GPIO mode | GPIO pull/up pull down

Max
Speed

User Label

ADC1 | PC0 | ADC1_IN1 | Analog mode | No pull-up and no pull-down | n/a
| PC1 | ADC1_IN2 | Analog mode | No pull-up and no pull-down | n/a
| PC2 | ADC1_IN3 | Analog mode | No pull-up and no pull-down | n/a
| PC3 | ADC1_IN4 | Analog mode | No pull-up and no pull-down | n/a
| PA0 | ADC1_IN5 | Analog mode | No pull-up and no pull-down | n/a
| PA1 | ADC1_IN6 | Analog mode | No pull-up and no pull-down | n/a
| PA2 | ADC1_IN7 | Analog mode | No pull-up and no pull-down | n/a
| PA3 | ADC1_IN8 | Analog mode | No pull-up and no pull-down | n/a
| PA4 | ADC1_IN9 | Analog mode | No pull-up and no pull-down | n/a
| PA5 | ADC1_IN10 | Analog mode | No pull-up and no pull-down | n/a
| PA6 | ADC1_IN11 | Analog mode | No pull-up and no pull-down | n/a
| PA7 | ADC1_IN12 | Analog mode | No pull-up and no pull-down | n/a
| PC4 | ADC1_IN13 | Analog mode | No pull-up and no pull-down | n/a
| PC5 | ADC1_IN14 | Analog mode | No pull-up and no pull-down | n/a
| PB0 | ADC1_IN15 | Analog mode | No pull-up and no pull-down | n/a
| PB1 | ADC1_IN16 | Analog mode | No pull-up and no pull-down | n/a
ADC3 | PF3 | ADC3_IN6 | Analog mode | No pull-up and no pull-down | n/a
| PF4 | ADC3_IN7 | Analog mode | No pull-up and no pull-down | n/a
| PF5 | ADC3_IN8 | Analog mode | No pull-up and no pull-down | n/a
| PF10 | ADC3_IN13 | Analog mode | No pull-up and no pull-down | n/a
CAN1 | PB8 | CAN1_RX | Alternate Function Push Pull | No pull-up and no pull-down | Very High
*
| PB9 | CAN1_TX | Alternate Function Push Pull | No pull-up and no pull-down | Very High
*
CAN2 | PB5 | CAN2_RX | Alternate Function Push Pull | No pull-up and no pull-down | Very High
*
| PB6 | CAN2_TX | Alternate Function Push Pull | No pull-up and no pull-down | Very High
*
I2C2 | PB13 | I2C2_SCL | Alternate Function Open Drain | No pull-up and no pull-down | Very High
*

IMU_I2C_SCL

| PB14 | I2C2_SDA | Alternate Function Open Drain | No pull-up and no pull-down | Very High
*

IMU_I2C_SDA

QUADSPI | PE10 | QUADSPI_CLK Alternate Function Push Pull | No pull-up and no pull-down | Very High
*
| PE11 | QUADSPI_BK1_ | Alternate Function Push Pull | No pull-up and no pull-down | Very High

IP | Pin | Signal | GPIO mode | GPIO pull/up pull down

Max
Speed

User Label

NCS | | | *
PE12 | QUADSPI_BK1_I
O0 | Alternate Function Push Pull | No pull-up and no pull-down | Very High
*
PE13 | QUADSPI_BK1_I
O1 | Alternate Function Push Pull | No pull-up and no pull-down | Very High
*
PE14 | QUADSPI_BK1_I
O2 | Alternate Function Push Pull | No pull-up and no pull-down | Very High
*
PE15 | QUADSPI_BK1_I
O3 | Alternate Function Push Pull | No pull-up and no pull-down | Very High
*
RCC | PC14-
OSC32_IN
(PC14)
RCC_OSC32_IN | n/a | n/a | n/a

PC15-
OSC32_OU
T (PC15)

RCC_OSC32_O
UT
n/a | n/a | n/a

PH0-
OSC_IN
(PH0)
RCC_OSC_IN | n/a | n/a | n/a

PH1-
OSC_OUT
(PH1)
RCC_OSC_OUT | n/a | n/a | n/a
SPI1 | PG2 | SPI1_SCK | Alternate Function Push Pull | No pull-up and no pull-down | Very High
*
| PG3 | SPI1_MISO | Alternate Function Push Pull | No pull-up and no pull-down | Very High
*
| PG4 | SPI1_MOSI | Alternate Function Push Pull | No pull-up and no pull-down | Very High
*
SPI2 | PD1 | SPI2_SCK | Alternate Function Push Pull | No pull-up and no pull-down | Very High
*
| PD3 | SPI2_MISO | Alternate Function Push Pull | No pull-up and no pull-down | Very High
*
| PD4 | SPI2_MOSI | Alternate Function Push Pull | No pull-up and no pull-down | Very High
*
SPI3 | PC10 | SPI3_SCK | Alternate Function Push Pull | No pull-up and no pull-down | Very High
*
| PC11 | SPI3_MISO | Alternate Function Push Pull | No pull-up and no pull-down | Very High
*
| PC12 | SPI3_MOSI | Alternate Function Push Pull | No pull-up and no pull-down | Very High
*

IP | Pin | Signal | GPIO mode | GPIO pull/up pull down

Max
Speed

User Label

TIM1 | PA9 | TIM1_CH2 | Alternate Function Push Pull | No pull-up and no pull-down | Low
| PA10 | TIM1_CH3 | Alternate Function Push Pull | No pull-up and no pull-down | Low
TIM2 | PB11 | TIM2_CH4 | Alternate Function Push Pull | No pull-up and no pull-down | Low
TIM3 | PC6 | TIM3_CH1 | Alternate Function Push Pull | No pull-up and no pull-down | Low
| PC7 | TIM3_CH2 | Alternate Function Push Pull | No pull-up and no pull-down | Low
| PC8 | TIM3_CH3 | Alternate Function Push Pull | No pull-up and no pull-down | Low
| PC9 | TIM3_CH4 | Alternate Function Push Pull | No pull-up and no pull-down | Low
TIM4 | PD12 | TIM4_CH1 | Alternate Function Push Pull | No pull-up and no pull-down | Low
| PD13 | TIM4_CH2 | Alternate Function Push Pull | No pull-up and no pull-down | Low
| PD14 | TIM4_CH3 | Alternate Function Push Pull | No pull-up and no pull-down | Low
| PD15 | TIM4_CH4 | Alternate Function Push Pull | No pull-up and no pull-down | Low
TIM5 | PF6 | TIM5_CH1 | Alternate Function Push Pull | No pull-up and no pull-down | Low
| PF7 | TIM5_CH2 | Alternate Function Push Pull | No pull-up and no pull-down | Low
| PF8 | TIM5_CH3 | Alternate Function Push Pull | No pull-up and no pull-down | Low
| PF9 | TIM5_CH4 | Alternate Function Push Pull | No pull-up and no pull-down | Low
TIM15 | PG10 | TIM15_CH1 | Alternate Function Push Pull | No pull-up and no pull-down | Low
| PG11 | TIM15_CH2 | Alternate Function Push Pull | No pull-up and no pull-down | Low
TIM17 | PE1 | TIM17_CH1 | Alternate Function Push Pull | No pull-up and no pull-down | Low
USB_OTG_ FS | PA11 | USB_OTG_FS_ DM | Alternate Function Push Pull | No pull-up and no pull-down | Very High
*
| PA12 | USB_OTG_FS_ DP | Alternate Function Push Pull | No pull-up and no pull-down | Very High
*
Single Mapped Signals | PA13 (JTMS/SWDI O) | SYS_JTMS- SWDIO | n/a | n/a | n/a

PA14
(JTCK/SWC
LK)

SYS_JTCK-SWCLK

n/a | n/a | n/a
| PA15 (JTDI) | TIM2_CH1 | Alternate Function Push Pull | No pull-up and no pull-down | Low
GPIO | PE2 | GPIO_Output | Output Push Pull | No pull-up and no pull-down | Low | INFO_LED
| PE3 | GPIO_Output | Output Push Pull | No pull-up and no pull-down | Low | HP_MOS_SEL1
| PE4 | GPIO_Output | Output Push Pull | No pull-up and no pull-down | Low | HP_MOS_SEL2
| PE5 | GPIO_Output | Output Push Pull | No pull-up and no pull-down | Low | HP_MOS_SEL3
PB12 | GPIO_EXTI12 External Interrupt Mode with
| | | Rising edge trigger detection | No pull-up and no pull-down | n/a
| PB15 | GPIO_Output | Output Push Pull | No pull-up and no pull-down | Low
| PD8 | GPIO_Output | Output Push Pull | No pull-up and no pull-down | Low | IMU_MODE_SEL
PD10 | GPIO_EXTI10 External Interrupt Mode with
| | | Rising edge trigger detection | No pull-up and no pull-down | n/a
| PG5 | GPIO_Input | Input mode | No pull-up and no pull-down | n/a
| PG6 | GPIO_Output | Output Push Pull | No pull-up and no pull-down | Low

IP | Pin | Signal | GPIO mode | GPIO pull/up pull down | Max Speed | User Label
| PG7 | GPIO_Output | Output Push Pull | No pull-up and no pull-down | Low
| PD0 | GPIO_Output | Output Push Pull | No pull-up and no pull-down | Low | LP_CSN2
| PD2 | GPIO_Output | Output Push Pull | No pull-up and no pull-down | Low | LP_CSN1
| PD5 | GPIO_Output | Output Push Pull | No pull-up and no pull-down | Low
| PD6 | GPIO_EXTI6 | External Interrupt Mode with Rising edge trigger detection | No pull-up and no pull-down | n/a
| PD7 | GPIO_Output | Output Push Pull | No pull-up and no pull-down | Low
| PG9 | GPIO_Output | Output Push Pull | No pull-up and no pull-down | Low

### 8.2. DMA configuration

DMA request | Stream | Direction | Priority
ADC1 | DMA1_Channel1 | Peripheral To Memory | Low
ADC3 | DMA2_Channel5 | Peripheral To Memory | Low
TIM3_CH4/UP | DMA1_Channel3 | Peripheral To Memory | Low
SPI1_RX | DMA1_Channel2 | Peripheral To Memory | Low
SPI1_TX | DMA2_Channel4 | Memory To Peripheral | Low

ADC1: DMA1_Channel1 DMA request Settings:

Mode: | Normal
Peripheral Increment: | Disable
Memory Increment: | Enable *
Peripheral Data Width: | Half Word
Memory Data Width: | Half Word

ADC3: DMA2_Channel5 DMA request Settings:

Mode: | Normal
Peripheral Increment: | Disable
Memory Increment: | Enable *
Peripheral Data Width: | Half Word
Memory Data Width: | Half Word

TIM3_CH4/UP: DMA1_Channel3 DMA request Settings:

Mode: | Normal
Peripheral Increment: | Disable
Memory Increment: | Enable *
Peripheral Data Width: | Half Word
Memory Data Width: | Half Word

SPI1_RX: DMA1_Channel2 DMA request Settings:

Mode: | Normal
Peripheral Increment: | Disable
Memory Increment: | Enable *
Peripheral Data Width: | Byte

Memory Data Width: Byte

SPI1_TX: DMA2_Channel4 DMA request Settings:

Mode: | Normal
Peripheral Increment: | Disable
Memory Increment: | Enable *
Peripheral Data Width: | Byte
Memory Data Width: | Byte

### 8.3. NVIC configuration

8.3.1. NVIC
Interrupt Table | Enable | Preenmption Priority | SubPriority
Non maskable interrupt | true | 0 | 0
Hard fault interrupt | true | 0 | 0
Memory management fault | true | 0 | 0
Prefetch fault, memory access fault | true | 0 | 0
Undefined instruction or illegal state | true | 0 | 0
System service call via SWI instruction | true | 0 | 0
Debug monitor | true | 0 | 0
Pendable request for system service | true | 0 | 0
System tick timer | true | 15 | 0
DMA1 channel1 global interrupt | true | 0 | 0
DMA1 channel2 global interrupt | true | 0 | 0
DMA1 channel3 global interrupt | true | 0 | 0
DMA2 channel4 global interrupt | true | 0 | 0
DMA2 channel5 global interrupt | true | 0 | 0
USB OTG FS global interrupt | true | 0 | 0
PVD/PVM1/PVM2/PVM3/PVM4 interrupts through EXTI lines 16/35/36/37/38 | unused
Flash global interrupt | unused
RCC global interrupt | unused
ADC1 and ADC2 interrupts | unused
CAN1 TX interrupt | unused
CAN1 RX0 interrupt | unused
CAN1 RX1 interrupt | unused
CAN1 SCE interrupt | unused
EXTI line[9:5] interrupts | unused
TIM1 break interrupt and TIM15 global interrupt | unused
TIM1 update interrupt and TIM16 global interrupt | unused
TIM1 trigger and commutation interrupts and TIM17 global interrupt | unused
TIM1 capture compare interrupt | unused
TIM2 global interrupt | unused
TIM3 global interrupt | unused
TIM4 global interrupt | unused
I2C2 event interrupt | unused
I2C2 error interrupt | unused
SPI1 global interrupt | unused
SPI2 global interrupt | unused
EXTI line[15:10] interrupts | unused

Interrupt Table | Enable | Preenmption Priority | SubPriority
ADC3 global interrupt | unused
TIM5 global interrupt | unused
SPI3 global interrupt | unused
QUADSPI global interrupt | unused
FPU global interrupt | unused
CAN2 TX interrupt | unused
CAN2 RX0 interrupt | unused
CAN2 RX1 interrupt | unused
CAN2 SCE interrupt | unused
8.3.2. NVIC Code generation
Enabled interrupt Table | Select for init sequence ordering | Generate IRQ handler | Call HAL handler
Non maskable interrupt | false | true | false
Hard fault interrupt | false | true | false
Memory management fault | false | true | false
Prefetch fault, memory access fault | false | true | false
Undefined instruction or illegal state | false | true | false
System service call via SWI instruction | false | true | false
Debug monitor | false | true | false
Pendable request for system service | false | true | false
System tick timer | false | true | true
DMA1 channel1 global interrupt | false | true | true
DMA1 channel2 global interrupt | false | true | true
DMA1 channel3 global interrupt | false | true | true
DMA2 channel4 global interrupt | false | true | true
DMA2 channel5 global interrupt | false | true | true
USB OTG FS global interrupt | false | true | true

* User modified value

## 9. System Views

9.1. Category view
9.1.1. Current

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

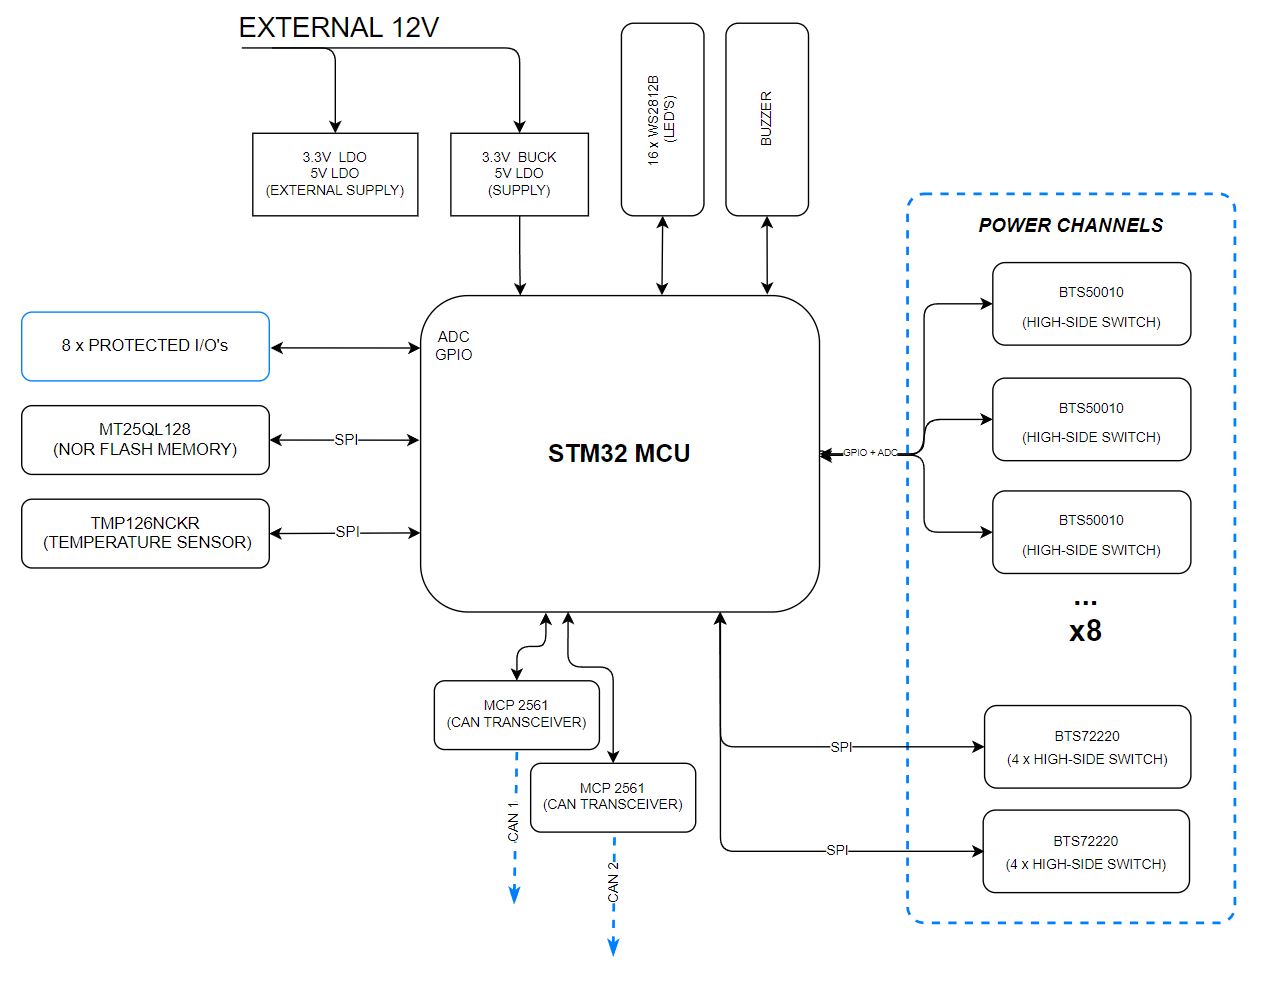
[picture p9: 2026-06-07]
DOCS/concept_schema_2024.JPG

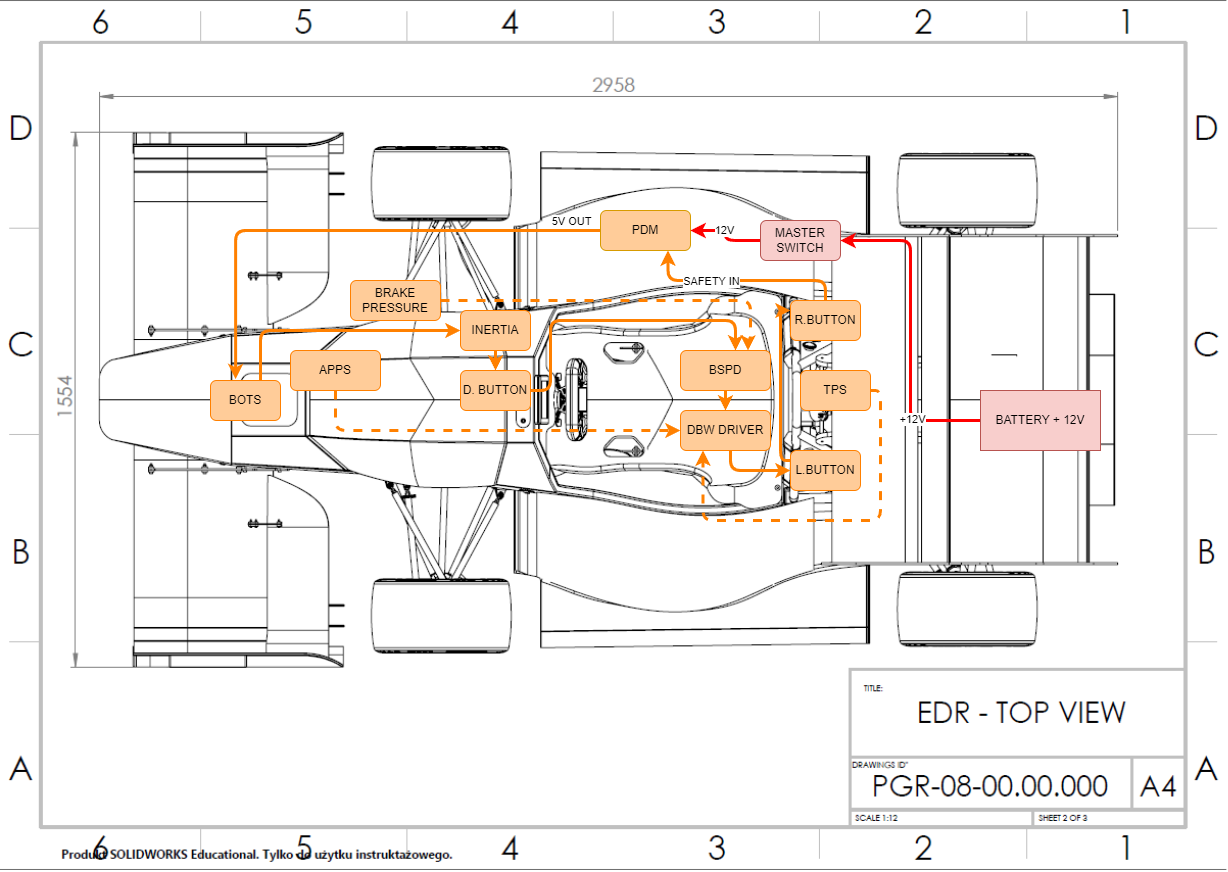
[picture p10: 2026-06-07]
DOCS/safety.png

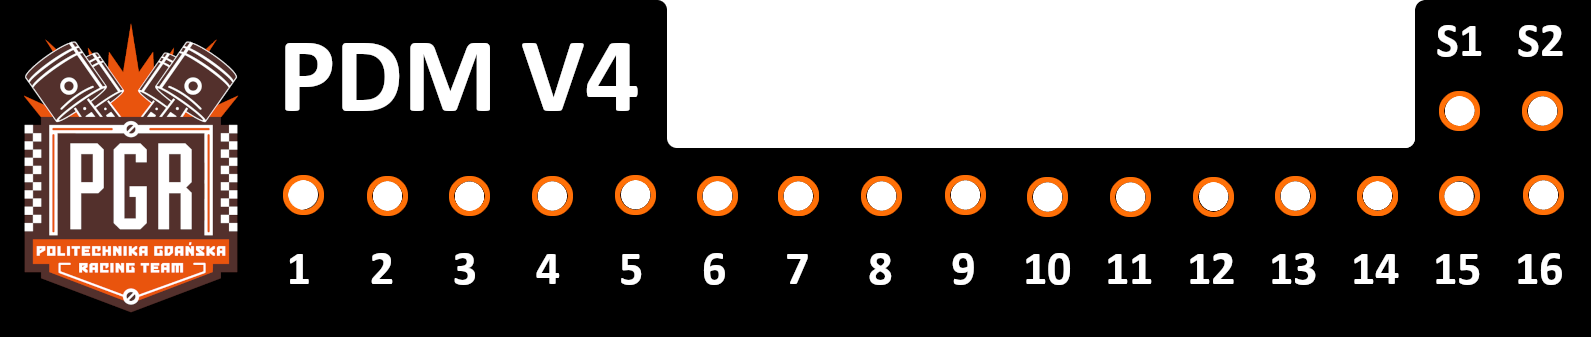
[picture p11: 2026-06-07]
MODEL/sticker_final.png

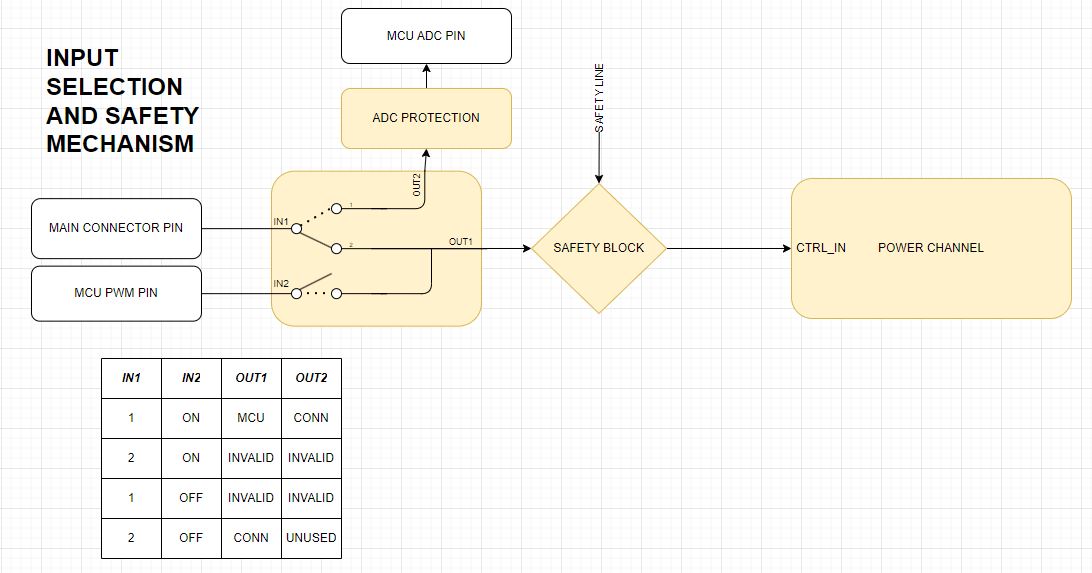
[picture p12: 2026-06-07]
PCB/io_safety_schema.jpg

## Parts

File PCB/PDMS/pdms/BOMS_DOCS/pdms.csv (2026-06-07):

Item | Qty | Reference(s) | Value | LibPart | Footprint | Datasheet | Arrow Part Number | Arrow Price/Stock | Comment | Datasheet_1 | Description | Footprint_1 | Height | MANUFACTURER | MAXIMUM_PACKAGE_HEIGHT | Manufacturer_Name | Manufacturer_Part_Number | Mouser Part Number | Mouser Price/Stock | PARTREV | Reference_1 | STANDARD | Value_1
1 | 1 | BZ1 | Buzzer | Device:Buzzer | Buzzer_Beeper:Buzzer_12x9.5RM7.6 | ~
2 | 14 | C2, C64, C65, C74, C76, C87, C95, C101, C106, C111, C117, C122, C127, C132 | 100nF | Device:C_Small | Capacitor_SMD:C_0402_1005Metric | ~
3 | 3 | C3, C54, C90 | 1uF | Device:C_Small | Capacitor_SMD:C_0805_2012Metric | ~
4 | 3 | C4, C55, C92 | 4.7uF | Device:C_Small | Capacitor_SMD:C_0603_1608Metric | ~
5 | 8 | C14, C15, C16, C17, C70, C71, C72, C73 | 10nF | Device:C_Small | Capacitor_SMD:C_0603_1608Metric | ~
6 | 2 | C18, C67 | 220pF | Device:C_Small | Capacitor_SMD:C_0402_1005Metric | ~
7 | 2 | C19, C68 | 470nF | Device:C_Small | Capacitor_SMD:C_0805_2012Metric | ~
8 | 2 | C20, C69 | 100nF | Device:C_Small | Resistor_SMD:R_0402_1005Metric | ~
9 | 1 | C40 | 1F | Device:C_Small | PDMS_Additional:CAPCP3225X100N | ~
10 | 1 | C41 | 4u7 | Device:C_Small | Resistor_SMD:R_0402_1005Metric | ~
11 | 3 | C42, C46, C61 | 10pF | Device:C_Small | Resistor_SMD:R_0402_1005Metric | ~
12 | 1 | C43 | 1u | Device:C_Small | Resistor_SMD:R_0402_1005Metric | ~
13 | 11 | C44, C45, C47, C48, C49, C50, C51, C52, C53, C66, C91 | 100n | Device:C_Small | Resistor_SMD:R_0402_1005Metric | ~
14 | 1 | C56 | 22uF | Device:C_Small | Capacitor_SMD:C_0805_2012Metric | ~
15 | 1 | C57 | 1nF | Device:C_Small | Resistor_SMD:R_0402_1005Metric | ~
16 | 1 | C58 | 0.1uF | Device:C_Small | Resistor_SMD:R_0402_1005Metric | ~
17 | 1 | C59 | 6.8nF | Device:C_Small | Resistor_SMD:R_0402_1005Metric | ~
18 | 1 | C60 | 1uF | Device:C_Small | Resistor_SMD:R_0402_1005Metric | ~
19 | 2 | C62, C63 | 22uF | Device:C_Small | Resistor_SMD:R_0402_1005Metric | ~
20 | 17 | C75, C93, C94, C98, C100, C103, C105, C108, C110, C114, C116, C119, C121, C124, C126, C129, C131 | 10nF | Device:C_Small | Capacitor_SMD:C_0402_1005Metric | ~
21 | 6 | C77, C78, C79, C80, C81, C82 | 100n | Device:C_Small | Capacitor_SMD:C_0402_1005Metric | ~
22 | 1 | C83 | 1u | Device:C_Small | Capacitor_SMD:C_0402_1005Metric | ~
23 | 2 | C84, C85 | 10pF | Device:C_Small | Capacitor_SMD:C_0402_1005Metric | ~
24 | 1 | C86 | 0.1uF | Device:C_Small | Capacitor_SMD:C_0402_1005Metric | ~
25 | 1 | C88 | 1000uF | Device:C | Capacitor_THT:CP_Radial_D12.5mm_P5.00mm | ~
26 | 8 | C99, C104, C109, C113, C115, C120, C125, C130 | 1nF | Device:C_Small | Capacitor_SMD:C_0402_1005Metric | ~
27 | 13 | D1, D2, D3, D4, D5, D6, D7, D8, D9, D37, D38, D39, D40 | BAT54SW | Diode:BAT54SW | Package_TO_SOT_SMD:SOT-323_SC-70 | https://assets.nexperia.com/documents/data-sheet/BAT54W_SER.pdf
28 | 18 | D10, D11, D12, D13, D14, D15, D16, D17, D18, D19, D20, D21, D22, D29, D30, D31, D32, D36 | WS2812B-2020 | pdms_additional:WS2812B-2020 | PDMS_Additional:WS2812B2020 |  |  |  |  | https://www.alldatasheet.com/datasheet-pdf/pdf/1134522/WORLDSEMI/WS2812B-2020.html |  | WS2812B2020 | 0.84 |  |  | Worldsemi | WS2812B-2020 |  |  |  | LED |  | WS2812B-2020
29 | 4 | D23, D24, D25, D26 | BAT54BRW-7-F | pdms_additional:BAT54BRW-7-F | PDM_Additional:SOT65P210X110-6N |  |  |  |  |  |  |  |  | Diodes Inc. | 1.1 mm |  |  |  |  | 17 - 2 |  | IPC 7351B
30 | 2 | D27, D28 | PESD2CANFD24L-UX | pdms_additional:PESD2CANFD24L-UX | PDMS_Additional:SOT65P210X110-3N | https://assets.nexperia.com/documents/data-sheet/PESD2CANFD24L-U.pdf | PESD2CANFD24L-UX | https://www.arrow.com/en/products/pesd2canfd24l-ux/nexperia?region=nac |  |  | PESD2CANFD24L-U - ESD protection for In-vehicle networks |  | 1.1 |  |  | Nexperia | PESD2CANFD24L-UX | 771-PESD2CANFD24L-UX | https://www.mouser.co.uk/ProductDetail/Nexperia/PESD2CANFD24L-UX?qs=sPbYRqrBIVnB5Z4FrS5%2FgA%3D%3D
31 | 1 | D33 | LED | Device:LED_Small | LED_SMD:LED_0402_1005Metric | ~
32 | 2 | D34, D35 | LED | Device:LED_Small | LED_SMD:LED_0805_2012Metric | ~
33 | 10 | D41, D42, D43, D44, D45, D46, D47, D48, D49, D50 | 3V3 | Device:D_Zener_Small | Diode_SMD:D_SOD-523 | SZMM5Z3V3T1G
34 | 2 | F1, F3 | 3A | Device:Fuse | Fuse:Fuse_0805_2012Metric | ~
35 | 3 | F2, F18, F19 | 100mA | Device:Fuse | Fuse:Fuse_0805_2012Metric | ~
36 | 8 | F10, F11, F12, F13, F14, F15, F16, F17 | 7A | Device:Fuse_Small | Fuse:Fuse_1206_3216Metric | ~
37 | 1 | F20 | 500mA | Device:Fuse | Fuse:Fuse_0805_2012Metric | ~
38 | 4 | H1, H2, H3, H4 | MountingHole_Pad | Mechanical:MountingHole_Pad | MountingHole:MountingHole_3.2mm_M3_Pad_Via | ~
39 | 1 | IC2 | 74HC4067PW-Q100J | pdms_additional:74HC4067PW-Q100J | PDMS_Additional:SOP65P640X110-24N |  | 74HC4067PW-Q100J | https://www.arrow.com/en/products/74hc4067pw-q100j/nexperia?region=asia |  | https://assets.nexperia.com/documents/data-sheet/74HC_HCT4067_Q100.pdf |  | SOP65P640X110-24N | 1.1 |  |  | Nexperia | 74HC4067PW-Q100J | 771-74HC4067PW-Q100J | https://www.mouser.co.uk/ProductDetail/Nexperia/74HC4067PW-Q100J?qs=sPdA%252BpIfi%2F%252BXvXN1KGf9sg%3D%3D |  | IC |  | 74HC4067PW-Q100J
40 | 1 | IC3 | LDO40LPU33RY | pdms_additional:LDO40LPU33RY | PDMS_Additional:SON95P300X300X90-7N-D |  | LDO40LPU33RY | https://www.arrow.com/en/products/ldo40lpu33ry/stmicroelectronics?region=europe |  | https://www.st.com/resource/en/datasheet/ldo40l.pdf |  | SON95P300X300X90-7N-D | 0.9 |  |  | STMicroelectronics | LDO40LPU33RY | 511-LDO40LPU33RY | https://www.mouser.co.uk/ProductDetail/STMicroelectronics/LDO40LPU33RY?qs=qSfuJ%252Bfl%2Fd5qazWclm%2Ffpg%3D%3D |  | IC |  | LDO40LPU33RY
41 | 2 | IC7, IC16 | BTS722204ESAXUMA1 | PDM_additional:BTS722204ESAXUMA1 | PDMS_Additional:SOP65P600X115-25N | https://www.infineon.com/dgdl/Infineon-BTS72220-4ESA-DS-v01_00-EN.pdf?fileId=5546d462636cc8fb0163feab173708d9 | BTS722204ESAXUMA1 | https://www.arrow.com/en/products/bts722204esaxuma1/infineon-technologies-ag |  |  | Power Switch ICs - Power Distribution SPOC |  | 1.15 |  |  | Infineon | BTS722204ESAXUMA1 | 726-BTS722204ESAXUMA | https://www.mouser.co.uk/ProductDetail/Infineon-Technologies/BTS722204ESAXUMA1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
42 | 2 | IC10, IC14 | LDO40LPU50RY | pdms_additional:LDO40LPU50RY | PDMS_Additional:SON95P300X300X90-7N-D | https://componentsearchengine.com/Datasheets/1/LDO40LPU50RY.pdf | LDO40LPU50RY | https://www.arrow.com/en/products/ldo40lpu50ry/stmicroelectronics?region=nac |  |  | LDO Voltage Regulators 400 mA, 38 V low-dropout regulator |  | 0.9 |  |  | STMicroelectronics | LDO40LPU50RY | 511-LDO40LPU50RY | https://www.mouser.co.uk/ProductDetail/STMicroelectronics/LDO40LPU50RY?qs=qSfuJ%252Bfl%2Fd76TFu8P3XttQ%3D%3D
43 | 1 | IC11 | MP2332HGTL-P | pdms_additional:MP2332HGTL-P | PDMS_Additional:SOTFL50P160X60-8N | https://eu.mouser.com/datasheet/2/277/MP2332H-1624281.pdf |  |  |  |  | Switching Voltage Regulators High-Efficiency, 2A, 18V, 1200kHz, Synchronous, Step-Down Converter |  | 0.6 |  |  | Monolithic Power Systems (MPS) | MP2332HGTL-P | 946-MP2332HGTL-P | https://www.mouser.co.uk/ProductDetail/Monolithic-Power-Systems-MPS/MP2332HGTL-P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
44 | 1 | IC12 | TMP126NDCKR | PDM_additional:TMP126NDCKR | PDM_Additional:SOT65P210X110-6N | https://www.ti.com/lit/ds/symlink/tmp126.pdf |  |  |  |  | Board Mount Temperature Sensors +/-0.25 C SPI temperature sensor with 175 C operation, CRC and slew-rate alert |  | 1.1 |  |  | Texas Instruments | TMP126NDCKR | 595-TMP126NDCKR | https://www.mouser.co.uk/ProductDetail/Texas-Instruments/TMP126NDCKR?qs=4ASt3YYao0WSJ2BCCG0dWw%3D%3D
45 | 1 | IC15 | ASM330LHHTR | pdms_additional:ASM330LHHTR | PDMS_Additional:LGA-14_2.5X3X0.86_ | https://www.st.com/resource/en/datasheet/asm330lhh.pdf | ASM330LHHTR | https://www.arrow.com/en/products/asm330lhhtr/stmicroelectronics |  |  | STMICROELECTRONICS - ASM330LHHTR - MEMS MOD, 3-AXIS GYROSCOPE/ACCELEROMETER |  |  |  |  | STMicroelectronics | ASM330LHHTR | 511-ASM330LHHTR | https://www.mouser.co.uk/ProductDetail/STMicroelectronics/ASM330LHHTR?qs=lc2O%252BfHJPVYgP8P9MzExKQ%3D%3D
46 | 1 | IC17 | TS5A21366DCUR | PDM_additional:TS5A21366DCUR | PDM_Additional:SOP50P310X90-8N | https://datasheet.datasheetarchive.com/originals/distributors/Datasheets-SFU2/DSASFU100028169.pdf | TS5A21366DCUR | https://www.arrow.com/en/products/ts5a21366dcur/texas-instruments?region=nac |  |  | 0.75R Dual SPST Analog Switch 1.8V VSSOP TS5A21366DCUR, Analogue Switch Dual SPST Analogue Switch, 1.65 5.5 V, 8-Pin, US8, 2 |  | 0.9 |  |  | Texas Instruments | TS5A21366DCUR | 595-TS5A21366DCUR | https://www.mouser.co.uk/ProductDetail/Texas-Instruments/TS5A21366DCUR?qs=XqfCv5qmO5hoVqowLBMCFA%3D%3D
47 | 1 | IC19 | STM32L496ZGT6 | PDM_additional:STM32L496ZGT6 | PDM_Additional:QFP50P2200X2200X160-144N | https://componentsearchengine.com/Datasheets/2/STM32L496ZGT6.pdf | STM32L496ZGT6 | https://www.arrow.com/en/products/stm32l496zgt6/stmicroelectronics |  |  | STMICROELECTRONICS - STM32L496ZGT6 - ARM MCU, STM32 Family STM32L4 Series Microcontrollers, ARM Cortex-M4, 32bit, 80 MHz, 1 MB, 320 KB |  | 1.6 |  |  | STMicroelectronics | STM32L496ZGT6 | 511-STM32L496ZGT6 | https://www.mouser.co.uk/ProductDetail/STMicroelectronics/STM32L496ZGT6?qs=Mv7BduZupUixTZjNdljBTQ%3D%3D
48 | 1 | IC20 | AT25SF128A-SHB-T | PDM_additional:AT25SF128A-SHB-T | PDM_Additional:SOIC127P798X216-8N | https://www.dialog-semiconductor.com/sites/default/files/2021-02/DS-AT25SF128A-168.pdf |  |  |  |  | NOR Flash 128 Mbit, 3.0V (2.7V to 3.6V), -40C to 85C, SOIC-W 208mil (Tape Reel), Single, Dual, Quad SPI NOR flash |  | 2.16 |  |  | Dialog Semiconductor | AT25SF128A-SHB-T | 988-AT25SF128A-SHB-T | https://www.mouser.co.uk/ProductDetail/Dialog-Semiconductor/AT25SF128A-SHB-T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
49 | 1 | J1 | Conn_2Rows-07Pins | Connector_Generic:Conn_2Rows-07Pins | Connector_Molex:Molex_PicoBlade_53047-0710_1x07_P1.25mm_Vertical | ~
50 | 1 | J2 | 6473427-1 | pdms_additional:6473427-1 | PDMS_Additional:64734271 | https://www.te.com/commerce/DocumentDelivery/DDEController?Action=showdoc | 6473427-1 | https://www.arrow.com/en/products/6473427-1/te-connectivity?region=nac |  |  | Automotive Connectors SUPER SEAL 60POS CAP ASY H AU |  | 27.4 |  |  | TE Connectivity | 6473427-1 | 571-6473427-1 | https://www.mouser.co.uk/ProductDetail/TE-Connectivity/6473427-1?qs=%252BJ%252BJwDEtia0S2ZPotWhzbA%3D%3D
51 | 1 | J3 | 7461383 | pdms_additional:7461383 | PDMS_Additional:7461383 |  |  |  |  | https://www.we-online.com/catalog/datasheet/7461383.pdf |  | 7461383 | 12.5 |  |  | Wurth Elektronik | 7461383 | 710-7461383 | https://www.mouser.co.uk/ProductDetail/Wurth-Elektronik/7461383?qs=lykWx4dhCCFZ0JBsRfYENw%3D%3D |  | IC |  | 7461383
52 | 1 | J4 | Conn_02x04_Counter_Clockwise | Connector_Generic:Conn_02x04_Counter_Clockwise | Connector_PinHeader_1.00mm:PinHeader_2x04_P1.00mm_Vertical_SMD | ~
53 | 1 | J5 | SAFETY | Connector:Conn_01x04_Male | Connector_Molex:Molex_PicoBlade_53047-0410_1x04_P1.25mm_Vertical | ~
54 | 1 | J6 | 2305018-2 | pdms_additional:2305018-2 | PDMS_Additional:TE_2305018-2 |  |  |  | 2305018-2
55 | 1 | JP1 | SolderJumper_3_Open | Jumper:SolderJumper_3_Open | Jumper:SolderJumper-3_P1.3mm_Open_Pad1.0x1.5mm | ~
56 | 1 | L1 | 2u7 120m | Device:L_Small | Inductor_SMD:L_0603_1608Metric | ~
57 | 1 | L2 | 2.2uH | Device:L_Small | Inductor_SMD:L_Vishay_IHLP-1616 | ~
58 | 2 | Q1, Q11 | AO3401A | Transistor_FET:AO3401A | Package_TO_SOT_SMD:SOT-23 | http://www.aosmd.com/pdfs/datasheet/AO3401A.pdf
59 | 1 | Q2 | RJU002N06FRAT106 | BSPD-07:RJU002N06FRAT106 | PDMS_Additional:SOT65P210X110-3N | https://datasheet.datasheetarchive.com/originals/distributors/DKDS-10/185695.pdf |  |  |  |  | ROHM - RJU002N06FRAT106 - MOSFET, AEC-Q101, N-CH, 60V, 0.2A, UMT3 |  | 1 |  |  | ROHM Semiconductor | RJU002N06FRAT106 | 755-RJU002N06FRAT106 | https://www.mouser.com/Search/Refine.aspx?Keyword=755-RJU002N06FRAT106
60 | 8 | Q3, Q4, Q5, Q6, Q7, Q8, Q9, Q10 | BTS500101LUAAUMA1 | BTS500101LUAAUMA1:BTS500101LUAAUMA1 | PDM_Additional:BTS500101LUAAUMA1 |  |  |  |  | https://www.infineon.com/dgdl/Infineon-BTS50010-1LUA-DataSheet-v01_10-EN.pdf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 |  | BTS500101LUAAUMA1 | 2.3 |  |  | Infineon | BTS500101LUAAUMA1 | 726-BTS500101LUAAUMA | https://www.mouser.co.uk/ProductDetail/Infineon-Technologies/BTS500101LUAAUMA1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 |  | IC |  | BTS500101LUAAUMA1
61 | 16 | R1, R2, R3, R4, R116, R117, R118, R119, R159, R160, R161, R162, R163, R164, R165, R166 | 0Ohm | Device:R_Small | Resistor_SMD:R_0402_1005Metric | ~
62 | 17 | R5, R6, R7, R8, R55, R67, R72, R169, R170, R172, R185, R190, R195, R201, R206, R211, R216 | 1k | Device:R_Small | Resistor_SMD:R_0402_1005Metric | ~
63 | 29 | R9, R24, R25, R26, R27, R30, R38, R96, R101, R102, R103, R104, R106, R107, R110, R111, R112, R113, R114, R115, R171, R183, R188, R193, R198, R199, R204, R209, R214 | 4.7k | Device:R_Small | Resistor_SMD:R_0402_1005Metric | ~
64 | 16 | R10, R13, R14, R17, R18, R33, R34, R37, R45, R48, R49, R52, R53, R88, R89, R92 | 2.3k | Device:R_Small | Resistor_SMD:R_0402_1005Metric | ~
65 | 18 | R11, R12, R15, R16, R19, R32, R35, R36, R46, R47, R50, R51, R56, R57, R65, R87, R90, R91 | 10k | Device:R_Small | Resistor_SMD:R_0402_1005Metric | ~
66 | 21 | R20, R21, R22, R23, R31, R44, R68, R70, R75, R77, R79, R81, R83, R85, R93, R97, R98, R99, R100, R105, R168 | 1.2k | Device:R_Small | Resistor_SMD:R_0402_1005Metric | ~
67 | 2 | R28, R94 | 47 | Device:R_Small | Resistor_SMD:R_0402_1005Metric | ~
68 | 2 | R29, R95 | 470 | Device:R_Small | Resistor_SMD:R_0402_1005Metric | ~
69 | 4 | R39, R40, R41, R42 | 100k | Device:R_Small | Resistor_SMD:R_0402_1005Metric | ~
70 | 1 | R43 | EXB-2HV472JV | pdms_additional:EXB-2HV472JV | PDMS_Additional:RES_EXB2HV | EXB-2HV472JV
71 | 1 | R54 | 0 | Device:R_Small | Resistor_SMD:R_0805_2012Metric | ~
72 | 2 | R58, R59 | 120 | Device:R_Small | Resistor_SMD:R_0402_1005Metric | ~
73 | 1 | R60 | 200k | Device:R_Small | Resistor_SMD:R_0402_1005Metric | ~
74 | 1 | R61 | 20 | Device:R_Small | Resistor_SMD:R_0402_1005Metric | ~
75 | 1 | R62 | 20k | Device:R_Small | Resistor_SMD:R_0402_1005Metric | ~
76 | 1 | R63 | 13k | Device:R_Small | Resistor_SMD:R_0402_1005Metric | ~
77 | 1 | R64 | 40.2k | Device:R_Small | Resistor_SMD:R_0402_1005Metric | ~
78 | 5 | R66, R108, R109, R173, R175 | 1k5 | Device:R_Small | Resistor_SMD:R_0402_1005Metric | ~
79 | 9 | R69, R71, R76, R78, R80, R82, R84, R86, R167 | 2.2k | Device:R_Small | Resistor_SMD:R_0402_1005Metric | ~
80 | 2 | R73, R74 | 2k2 | Device:R_Small | Resistor_SMD:R_0402_1005Metric | ~
81 | 2 | R174, R176 | 22 | Device:R_Small | Resistor_SMD:R_0402_1005Metric | ~
82 | 2 | R177, R178 | 5.1k | Device:R_Small | Resistor_SMD:R_0402_1005Metric | ~
83 | 2 | R179, R180 | 0 | Device:R_Small | Resistor_SMD:R_0402_1005Metric | ~
84 | 1 | TP1 | 3.3V PG | Connector:TestPoint | TestPoint:TestPoint_Pad_D1.0mm | ~
85 | 4 | U1, U4, U5, U6 | AQY221R4VY | pdms_additional:AQY221R4VY | PDMS_Additional:SOTFL127P485X190-4N |  |  |  |  | https://www3.panasonic.biz/ac/cdn/e/control/relay/photomos/catalog/semi_eng_rf1a_aqy22_v_cr10.pdf |  | SOTFL127P485X190-4N | 1.9 |  |  | Panasonic | AQY221R4VY | 769-AQY221R4VY | https://www.mouser.com/Search/Refine.aspx?Keyword=769-AQY221R4VY |  | IC |  | AQY221R4VY
86 | 2 | U2, U3 | MCP2561-E-SN | Interface_CAN_LIN:MCP2561-E-SN | Package_SO:SOIC-8_3.9x4.9mm_P1.27mm | http://ww1.microchip.com/downloads/en/DeviceDoc/25167A.pdf
87 | 1 | U12 | USBLC6-2SC6 | Power_Protection:USBLC6-2SC6 | Package_TO_SOT_SMD:SOT-23-6 | https://www.st.com/resource/en/datasheet/usblc6-2.pdf
88 | 1 | Y1 | 16Mhz | Device:Crystal_GND24_Small | Crystal:Crystal_SMD_2016-4Pin_2.0x1.6mm | ~
89 | 1 | Y2 | 32KHz | Device:Crystal_Small | Crystal:Crystal_SMD_3215-2Pin_3.2x1.5mm | ~

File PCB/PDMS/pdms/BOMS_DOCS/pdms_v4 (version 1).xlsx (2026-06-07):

LID | Reference | Value | Footprint | Qty | DNP | Stock | Kolumna1
1 | BZ1 | Buzzer | Buzzer_Beeper:Buzzer_12x9.5RM7.6 | 1 |  | 3
2 | C4, C92 | 4.7uF | Capacitor_SMD:C_0603_1608Metric | 2 |  | 10
3 | C2, C64, C65, C74, C76, C77, C78, C79, C80, C81, C82, C86, C87, C112, C118, C44, C45, C47, C48, C49, C50, C51, C52, C53, C66, C89, C91, C96, C97, C102, C133, C134, C135, C136, C137, C138, C139, C140, C141, C142, C143, C144, C145, C146, C147, C148, C149, C150 | 100nF | _0402 | 48 |  | 100
4 | C3,C5, C90 | 1uF | _0805 | 3 |  | 15
5 | C6,C7,C8,C9,C10,C11,C12,C13 | 10uF | Capacitor_SMD:C_1206_3216Metric | 8 |  | 24
6 | (0603)C14,C15,C16,C17,C70,C71,C72,C73 | 10nF | Capacitor_SMD:C_0603_1608Metric | 8 |  | 24
7 | C18,C67 | 220pF | Capacitor_SMD:C_0402_1005Metric | 2 |  | 10
8 | C19,C68 | 470nF | Capacitor_SMD:C_0805_2012Metric | 2 |  | 10
9 | C21 | 100pF/50V | Capacitor_SMD:C_0402_1005Metric | 1 |  | 10
10 | C22 | 100nF/50V | Capacitor_SMD:C_0402_1005Metric | 1 |  | 100
11 | C23,C99,C104,C109,C113,C115,C120,C125,C130 | 1nF | Capacitor_SMD:C_0402_1005Metric | 9 |  | 30
12 | C25,C26 | 2.2uF | Capacitor_SMD:C_0805_2012Metric | 2 |  | 10
13 | C58,C59 | 22uF | Capacitor_SMD:C_1206_3216Metric | 3 |  | 25
14 |  |  |  | 2
15 | C32,C33,C34,C35,C36,C37,C38,C39,C56 | 47nF | Capacitor_SMD:C_0402_1005Metric | 9 |  | 30
16 | C40 | 1F | PDMS_Additional:CAPCP3225X100N | 1 | DNP
17 | C41 | 4.7uF | Capacitor_SMD:C_0402_1005Metric | 1 |  | 10
18 | C42,C46,C57,C84,C85 | 10pF | Capacitor_SMD:C_0402_1005Metric | 5 |  | 20
19 | C61,C62 | 10uF | Capacitor_SMD:C_1206_3216Metric | 2 | DNP | 6
20 | C63 | 2.2uF | Capacitor_SMD:C_1206_3216Metric | 1 | DNP | 3
21 | C88 | 1000uF | Capacitor_THT:CP_Radial_D12.5mm_P5.00mm | 1 |  | 1
22 | C107,C123,C128,R122,R123 | NA | -- mixed values -- | 5
23 | D1,D2,D3,D4,D5,D6,D7,D8,D9,D37,D38,D39,D40 | BAT54SW | Package_TO_SOT_SMD:SOT-323_SC-70 | 13 |  | 39
24 | D10,D11,D12,D13,D14,D15,D16,D17,D18,D19,D20,D21,D22,D29,D30,D31,D32,D36 | WS2812B-2020 | PDMS_Additional:WS2812B2020 | 18 |  | 60
25 | D23,D24,D25,D26 | BAT54BRW-7-F | PDM_Additional:SOT65P210X110-6N | 4 |  | 22
26 | D27,D28 | PESD2CANFD24L-UX | PDMS_Additional:SOT65P210X110-3N | 2
26 | D33, | LED | _0402 | 3 |  | 6
28 | D41,D42,D43,D44,D45,D46,D47,D48,D49,D50,D67,D69 | SZMM5Z3V9 | Diode_SMD:D_SOD-523 | 12 |  | 36
29 | D51 | SMC_TVS_28V | Diode_SMD:D_SMC | 1 |  | 6
30 | D52 | SMC_TVS_28V | Diode_SMD:D_SMC | 1 |  | abv
31 | D53 | 1N4448WS | Diode_SMD:D_SOD-323 | 2 |  | 6
32 | D55,D56,D57,D58,D59,D60,D61,D62 | TSD05 | Diode_SMD:D_SOD-323 | 8 |  | 24
33 | D63,D64,D65,D66 | SZMM5Z5V6 | Diode_SMD:D_SOD-523 | 4 |  | 12
34 | D68 | TSD12 | Diode_SMD:D_SOD-323 | 1 |  | 3
35 | F1 | 2A | Fuse:Fuse_1206_3216Metric | 1 |  | 3
36 | F2,F19,F23 | 1A | Fuse:Fuse_0805_2012Metric | 4 |  | 10
37 | F3 | 3A | Fuse:Fuse_0805_2012Metric | 1 |  | 3
38 | F4,F5,F6,F7,F8,F9,F21,F22 | 40A | Fuse:Fuse_1206_3216Metric | 8 |  | 24
39 | F10,F11,F12,F13,F14,F15,F16,F17 | 7A | Fuse:Fuse_1206_3216Metric | 8 |  | 24
40 | FB1,L2 | 742792063 | Inductor_SMD:L_0805_2012Metric | 2 |  | 10
41 | H1,H2,H3,H4 | MountingHole_Pad | MountingHole:MountingHole_3.2mm_M3_Pad_Via | 4
42 | IC1 | BD50FD0WHFP-TR | PDMS_Additional:BD50FD0WHFPTR | 1 |  | 10
43 | IC2 | 74HC4067PW-Q100J | PDMS_Additional:SOP65P640X110-24N | 1 |  | 2
44 | IC3 | LDO40LPU33RY | PDMS_Additional:SON95P300X300X90-7N-D | 1 |  | 3
45 | IC7,IC16 | BTS722204ESAXUMA1 | PDMS_Additional:SOP65P600X115-25N | 2 |  | 10
46 | IC10,IC14 | LDO40LPU50RY | PDMS_Additional:SON95P300X300X90-7N-D | 2 |  | 15
47 | IC12 | TMP126NDCKR | PDM_Additional:SOT65P210X110-6N | 1 |  | 3
48 | IC15 | ASM330LHHTR | PDMS_Additional:LGA-14_2.5X3X0.86_ | 1 |  | 1
49 | IC17 | TS5A21366DCUR | PDM_Additional:SOP50P310X90-8N | 1
50 | IC19 | STM32L496ZGT6 | PDM_Additional:QFP50P2200X2200X160-144N | 1 |  | 3
51 | IC20 | AT25SF128A-SHB-T | PDM_Additional:SOIC127P798X216-8N | 1 |  | 3
52 | J1 | DBG | Connector_Molex:Molex_PicoBlade_53047-0710_1x07_P1.25mm_Vertical | 1 |  | 1
53 | J2 | 6473427-1 | PDMS_Additional:64734271 | 1 |  | 2
54 | J3 | 7461383 | PDMS_Additional:7461383 | 1 |  | 3
55 | J4 | AUX | Connector_PinHeader_1.00mm:PinHeader_2x04_P1.00mm_Vertical_SMD | 1
56 | J5 | SAFETY | Connector_Molex:Molex_PicoBlade_53047-0410_1x04_P1.25mm_Vertical | 1 | DNP
57 | J6 | 2305018-2 | PDMS_Additional:TE_2305018-2 | 1 | DNP
58 | J7 | ONE_WIRE | Connector_PinHeader_2.00mm:PinHeader_1x03_P2.00mm_Vertical | 1
59 | JP1 | SolderJumper_3_Open | Jumper:SolderJumper-3_P1.3mm_Open_Pad1.0x1.5mm | 1
60 | L1 | FCM 1608KF-601T03 | Inductor_SMD:L_0603_1608Metric | 1 |  | 10
61 | L3 | 120uH / 1A | Inductor_SMD:L_6.3x6.3_H3 | 1 |  | 3
62 | L4 | XEL4020-102MEB | Inductor_SMD:L_Coilcraft_XxL4020 | 1 |  | 3
63 | L5 | 2.2uH | Inductor_SMD:L_Vishay_IHLP-1616 | 1 |  | 3
64 | Q1,Q11 | Si2319CDS | Package_TO_SOT_SMD:SOT-23 | 1 |  | 10
65 | Q2 | RJU002N06FRAT106 | PDMS_Additional:SOT65P210X110-3N | 1 |  | 10
66 | Q3,Q4,Q5,Q6,Q7,Q8,Q9,Q10 | BTS500101LUAAUMA1 | PDM_Additional:BTS500101LUAAUMA1 | 8 |  | 24
67 |  | AO3401A | Package_TO_SOT_SMD:SOT-23 | 1 |  | DNP
68 | R1,R2,R3,R4,R160,R162,R164,R166 | 0Ohm | Resistor_SMD:R_0402_1005Metric | 8 | DNP
69 | R5,R6,R7,R8, R55,R72 | 1k | Resistor_SMD:R_0402_1005Metric | 6 |  | 18
70 | R142, R9,R24,R25,R26,R27,R30,R38,R96,R101,R102,R103,R104,R106,R107,R110,R111,R112,R113,R114,R115,R183,R188,R193,R198,R199,R204,R209,R214 | 4.7k | Resistor_SMD:R_0402_1005Metric | 28 |  | 70
71 | R10,R13,R14,R17,R18,R33,R34,R37,R45,R48,R49,R52,R53,R88,R89,R92 | 2.3k | Resistor_SMD:R_0402_1005Metric | 16 |  | 90
72 | R11,R12,R15,R16,R19,R32,R35,R36,R39,R40,R41,R42,R46,R47,R50,R51,R56,R57,R65,R73,R74,R87,R90,R91,R141,R170 | 10k | Resistor_SMD:R_0402_1005Metric | 26 |  | 50
73 | R20,R21,R22,R23,R31,R44,R68,R70,R75,R77,R79,R81,R83,R85,R93,R97,R98,R99,R100,R105,R168 | 1.2k | Resistor_SMD:R_0402_1005Metric | 21 |  | 100
74 | R28,R94 | 47 | Resistor_SMD:R_0805_2012Metric | 2 |  | 10
75 | R29,R95 | 470 | Resistor_SMD:R_0402_1005Metric | 2 |  | 10
76 | R43 | EXB-2HV472JV | PDMS_Additional:RES_EXB2HV | 1 |  | 9
77 | R54,R179,R180 | 0 | -- mixed values -- | 3
78 | R58,R59 | 120 | Resistor_SMD:R_0402_1005Metric | 2 |  | 8
79 | R60 | 0R0 | Resistor_SMD:R_0402_1005Metric | 1
80 | R61,R63,R64,R127,R128,R131,R132,R137,R138,R139,R140 | 100k | Resistor_SMD:R_0402_1005Metric | 11 |  | 90
81 | R62 | 15k | Resistor_SMD:R_0402_1005Metric | 1 |  | 10
82 | R66,R108,R109 | 1k5 | Resistor_SMD:R_0402_1005Metric | 3 |  | 10
83 | R69,R71,R76,R78,R80,R82,R84,R86,R167,R124 | 2k | Resistor_SMD:R_0402_1005Metric | 10 |  | 80
84 | R116,R117,R118,R119,R159,R161,R163,R165 | 0Ohm | Resistor_SMD:R_0402_1005Metric | 8
85 | R120 | 31.6k | Resistor_SMD:R_0402_1005Metric | 1 |  | 10
86 | R121 | NA | Resistor_SMD:R_0402_1005Metric | 1 | DNP
87
88 | R125,R126,R129,R130,R133,R134,R135,R136 | 1k/0.2W | Resistor_SMD:R_0603_1608Metric | 8 |  | 24
89 |  | 4k7 | Resistor_SMD:R_0402_1005Metric | 1
90 | R169 | 10k | Resistor_SMD:R_0402_1005Metric | 1 | DNP
91 | R174,R176 | 22 | Resistor_SMD:R_0402_1005Metric | 2 | DNP
92 | R177,R178 | 5.1k | Resistor_SMD:R_0402_1005Metric | 2 | DNP
93 | TP1 | 3.3V PG | TestPoint:TestPoint_Pad_D1.0mm | 1
94 | TP2,TP3,TP4,TP5,TP6,TP7,TP8,TP9 | AFUSE | TestPoint:TestPoint_Pad_D2.0mm | 8
95 | TP10 | 5V | TestPoint:TestPoint_Pad_D2.0mm | 1
96 | TP11 | SAFETY_TP | TestPoint:TestPoint_Pad_D2.0mm | 1
97 | TP13 | 3.3V | TestPoint:TestPoint_Pad_D2.0mm | 1
98 | U1,U4,U5,U6 | AQY221R4VY | PDMS_Additional:SOTFL127P485X190-4N | 4 |  | 12
99 | U2,U3 | MCP2561-E-SN | Package_SO:SOIC-8_3.9x4.9mm_P1.27mm | 2 |  | 6 | MCP2561T as replacement (same diffrent pack)
100 |  | MP4322GDE-P | PDMS_Additional:QFN-12_MP4322_MNP | 1 |  | 3 | 1 x MP4323 ordered as replacement
101 | U8,U9,U10,U11 | MCP6002-xMC | Package_DFN_QFN:DFN-8-1EP_3x2mm_P0.5mm_EP1.75x1.45mm | 4 |  | 12
102 | U12 | USBLC6-2SC6 | Package_TO_SOT_SMD:SOT-23-6 | 1 | DNP | 10
103 | U13,U14 | MCP6001-OT | Package_TO_SOT_SMD:SOT-23-5 | 2 |  | 10
104 | Y1 | 16Mhz | Crystal:Crystal_SMD_2016-4Pin_2.0x1.6mm | 1 |  | 2
105 | Y2 | 32KHz | Crystal:Crystal_SMD_3215-2Pin_3.2x1.5mm | 1 |  | 2
106 | C27 | 22uF | Capacitor_6.3x9.9 | 1 |  | 10
107 | F20 | 2A | _0805 | 1 |  | 5
108 | C43 ,C60,C83, | 1uF | _0402 | 3 |  | 10
109 | D34,D35 | LED | _0805
110 | C20, C30, C31, C69, C95, C101, C106, C111, C117, C122, C127, C132 | 100nF | _0805 | 12 |  | 36
111 | C1 | 4.7uF | Capacitor_SMD:C_0805_2012Metric | 1 |  | 10
112 | C28, C29 | 4.7uF | Capacitor_SMD:C_1206_3216Metric | 2 |  | 10
113 | C93, C98, C103, C108, C114, C119, C124, C129 | 33nF | Capacitor_SMD:C_0402_1005Metric | 8 |  | 100
114 | (0402) ,C94,C100,C105,C110,C116,C121,C126,C131, C24,C75 | 10nF | Capacitor_SMD:C_0402_1005Metric | 10
115 | R67,R185,R190,R195,R201,R206,R211,R216 | 8.2k 0.1% | Resistor_SMD:R_0402_1005Metric | 8 |  | 24

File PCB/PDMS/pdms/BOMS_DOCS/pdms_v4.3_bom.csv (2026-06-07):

Reference | Value | Datasheet | Footprint | Qty | DNP
BZ1 | Buzzer | ~ | Buzzer_Beeper:Buzzer_12x9.5RM7.6 | 1
C1,C4,C28,C29,C55,C92 | 4.7uF | ~ | -- mixed values -- | 6
C2,C20,C44,C45,C47,C48,C49,C50,C51,C52,C53,C64,C65,C66,C69,C74,C76,C77,C78,C79,C80,C81,C82,C86,C87,C89,C91,C95,C96,C97,C101,C102,C106,C111,C112,C117,C118,C122,C127,C132,C133,C134,C135,C136,C137,C138,C139,C140,C141,C142,C143,C144,C145,C146,C147,C148,C149,C150 | 100nF | ~ | -- mixed values -- | 58
C3,C5,C43,C54,C60,C83,C90 | 1uF | ~ | -- mixed values -- | 7
C6,C7,C8,C9,C10,C11,C12,C13 | 10uF | ~ | Capacitor_SMD:C_1206_3216Metric | 8
C14,C15,C16,C17,C24,C70,C71,C72,C73,C75,C93,C94,C98,C100,C103,C105,C108,C110,C114,C116,C119,C121,C124,C126,C129,C131 | 10nF | ~ | -- mixed values -- | 26
C18,C67 | 220pF | ~ | Capacitor_SMD:C_0402_1005Metric | 2
C19,C68 | 470nF | ~ | Capacitor_SMD:C_0805_2012Metric | 2
C21 | 100pF/50V | ~ | Capacitor_SMD:C_0402_1005Metric | 1
C22 | 100nF/50V | ~ | Capacitor_SMD:C_0402_1005Metric | 1
C23,C99,C104,C109,C113,C115,C120,C125,C130 | 1nF | ~ | Capacitor_SMD:C_0402_1005Metric | 9
C25,C26 | 2.2uF | ~ | Capacitor_SMD:C_0805_2012Metric | 2
C27,C58,C59 | 22uF | ~ | -- mixed values -- | 3
C30,C31 | 0.1uF | ~ | Capacitor_SMD:C_0805_2012Metric | 2
C32,C33,C34,C35,C36,C37,C38,C39,C56 | 47nF | ~ | Capacitor_SMD:C_0402_1005Metric | 9
C40 | 1F | ~ | PDMS_Additional:CAPCP3225X100N | 1
C41 | 4u7 | ~ | Resistor_SMD:R_0402_1005Metric | 1
C42,C46,C57,C84,C85 | 10pF | ~ | -- mixed values -- | 5
C61,C62 | 10uF | ~ | Capacitor_SMD:C_1206_3216Metric | 2 | DNP
C63 | 2.2uF | ~ | Capacitor_SMD:C_1206_3216Metric | 1 | DNP
C88 | 1000uF | ~ | Capacitor_THT:CP_Radial_D12.5mm_P5.00mm | 1
C107,C123,C128,R122,R123 | NA | ~ | -- mixed values -- | 5
D1,D2,D3,D4,D5,D6,D7,D8,D9,D37,D38,D39,D40 | BAT54SW | https://assets.nexperia.com/documents/data-sheet/BAT54W_SER.pdf | Package_TO_SOT_SMD:SOT-323_SC-70 | 13
D10,D11,D12,D13,D14,D15,D16,D17,D18,D19,D20,D21,D22,D29,D30,D31,D32,D36 | WS2812B-2020 |  | PDMS_Additional:WS2812B2020 | 18
D23,D24,D25,D26 | BAT54BRW-7-F |  | PDM_Additional:SOT65P210X110-6N | 4
D27,D28 | PESD2CANFD24L-UX | https://assets.nexperia.com/documents/data-sheet/PESD2CANFD24L-U.pdf | PDMS_Additional:SOT65P210X110-3N | 2
D33,D34,D35 | LED | ~ | -- mixed values -- | 3
D41,D42,D43,D44,D45,D46,D47,D48,D49,D50,D67,D69 | SZMM5Z3V9 | SZMM5Z3V3T1G | Diode_SMD:D_SOD-523 | 12
D51 | SMC_TVS_28V | ~ | Diode_SMD:D_SMC | 1
D52 | D_TVS | ~ | Diode_SMD:D_SMC | 1
D53,D54 | 1N4448WS | https://www.vishay.com/docs/81387/1n4448ws.pdf | Diode_SMD:D_SOD-323 | 2
D55,D56,D57,D58,D59,D60,D61,D62 | TSD05 | ~ | Diode_SMD:D_SOD-323 | 8
D63,D64,D65,D66 | SZMM5Z5V3 | ~ | Diode_SMD:D_SOD-523 | 4
D68 | 12V | ~ | Diode_SMD:D_SOD-323 | 1
F1,F20 | 2A | ~ | -- mixed values -- | 2
F2,F18,F19,F23 | 100mA | ~ | Fuse:Fuse_0805_2012Metric | 4
F3 | 3A | ~ | Fuse:Fuse_0805_2012Metric | 1
F4,F5,F6,F7,F8,F9,F21,F22 | Fuse | ~ | Fuse:Fuse_1206_3216Metric | 8
F10,F11,F12,F13,F14,F15,F16,F17 | 7A | ~ | Fuse:Fuse_1206_3216Metric | 8
FB1,L2 | 742792063 | ~ | Inductor_SMD:L_0805_2012Metric | 2
H1,H2,H3,H4 | MountingHole_Pad | ~ | MountingHole:MountingHole_3.2mm_M3_Pad_Via | 4
IC1 | BD50FD0WHFP-TR |  | PDMS_Additional:BD50FD0WHFPTR | 1
IC2 | 74HC4067PW-Q100J |  | PDMS_Additional:SOP65P640X110-24N | 1
IC3 | LDO40LPU33RY |  | PDMS_Additional:SON95P300X300X90-7N-D | 1
IC7,IC16 | BTS722204ESAXUMA1 | https://www.infineon.com/dgdl/Infineon-BTS72220-4ESA-DS-v01_00-EN.pdf?fileId=5546d462636cc8fb0163feab173708d9 | PDMS_Additional:SOP65P600X115-25N | 2
IC10,IC14 | LDO40LPU50RY | https://componentsearchengine.com/Datasheets/1/LDO40LPU50RY.pdf | PDMS_Additional:SON95P300X300X90-7N-D | 2
IC12 | TMP126NDCKR | https://www.ti.com/lit/ds/symlink/tmp126.pdf | PDM_Additional:SOT65P210X110-6N | 1
IC15 | ASM330LHHTR | https://www.st.com/resource/en/datasheet/asm330lhh.pdf | PDMS_Additional:LGA-14_2.5X3X0.86_ | 1
IC17 | TS5A21366DCUR | https://datasheet.datasheetarchive.com/originals/distributors/Datasheets-SFU2/DSASFU100028169.pdf | PDM_Additional:SOP50P310X90-8N | 1
IC19 | STM32L496ZGT6 | https://componentsearchengine.com/Datasheets/2/STM32L496ZGT6.pdf | PDM_Additional:QFP50P2200X2200X160-144N | 1
IC20 | AT25SF128A-SHB-T | https://www.dialog-semiconductor.com/sites/default/files/2021-02/DS-AT25SF128A-168.pdf | PDM_Additional:SOIC127P798X216-8N | 1
J1 | DBG | ~ | Connector_Molex:Molex_PicoBlade_53047-0710_1x07_P1.25mm_Vertical | 1
J2 | 6473427-1 | https://www.te.com/commerce/DocumentDelivery/DDEController?Action=showdoc | PDMS_Additional:64734271 | 1
J3 | 7461383 |  | PDMS_Additional:7461383 | 1
J4 | AUX | ~ | Connector_PinHeader_1.00mm:PinHeader_2x04_P1.00mm_Vertical_SMD | 1
J5 | SAFETY | ~ | Connector_Molex:Molex_PicoBlade_53047-0410_1x04_P1.25mm_Vertical | 1 | DNP
J6 | 2305018-2 |  | PDMS_Additional:TE_2305018-2 | 1
J7 | Conn_01x03_Pin | ~ | Connector_PinHeader_2.00mm:PinHeader_1x03_P2.00mm_Vertical | 1
JP1 | SolderJumper_3_Open | ~ | Jumper:SolderJumper-3_P1.3mm_Open_Pad1.0x1.5mm | 1
L1 | 2u7 120m | ~ | Inductor_SMD:L_0603_1608Metric | 1
L3 | 120uH / 3A | ~ | Inductor_SMD:L_6.3x6.3_H3 | 1
L4 | XEL4020-102MEB | ~ | Inductor_SMD:L_Coilcraft_XxL4020 | 1
L5 | 2.2uH | ~ | Inductor_SMD:L_Vishay_IHLP-1616 | 1
Q1 | Si2319CDS | http://www.aosmd.com/pdfs/datasheet/AO3401A.pdf | Package_TO_SOT_SMD:SOT-23 | 1
Q2 | RJU002N06FRAT106 | https://datasheet.datasheetarchive.com/originals/distributors/DKDS-10/185695.pdf | PDMS_Additional:SOT65P210X110-3N | 1
Q3,Q4,Q5,Q6,Q7,Q8,Q9,Q10 | BTS500101LUAAUMA1 |  | PDM_Additional:BTS500101LUAAUMA1 | 8
Q11 | AO3401A | http://www.aosmd.com/pdfs/datasheet/AO3401A.pdf | Package_TO_SOT_SMD:SOT-23 | 1
R1,R2,R3,R4,R160,R162,R164,R166 | 0Ohm | ~ | Resistor_SMD:R_0402_1005Metric | 8 | DNP
R5,R6,R7,R8,R55,R67,R72,R185,R190,R195,R201,R206,R211,R216 | 1k | ~ | Resistor_SMD:R_0402_1005Metric | 14
R9,R24,R25,R26,R27,R30,R38,R96,R101,R102,R103,R104,R106,R107,R110,R111,R112,R113,R114,R115,R183,R188,R193,R198,R199,R204,R209,R214 | 4.7k | ~ | Resistor_SMD:R_0402_1005Metric | 28
R10,R13,R14,R17,R18,R33,R34,R37,R45,R48,R49,R52,R53,R88,R89,R92 | 2.3k | ~ | Resistor_SMD:R_0402_1005Metric | 16
R11,R12,R15,R16,R19,R32,R35,R36,R39,R40,R41,R42,R46,R47,R50,R51,R56,R57,R65,R73,R74,R87,R90,R91,R141,R170 | 10k | ~ | Resistor_SMD:R_0402_1005Metric | 26
R20,R21,R22,R23,R31,R44,R68,R70,R75,R77,R79,R81,R83,R85,R93,R97,R98,R99,R100,R105,R168 | 1.2k | ~ | Resistor_SMD:R_0402_1005Metric | 21
R28,R94 | 47 | ~ | Resistor_SMD:R_0805_2012Metric | 2
R29,R95 | 470 | ~ | Resistor_SMD:R_0402_1005Metric | 2
R43 | EXB-2HV472JV | EXB-2HV472JV | PDMS_Additional:RES_EXB2HV | 1
R54,R179,R180 | 0 | ~ | -- mixed values -- | 3
R58,R59 | 120 | ~ | Resistor_SMD:R_0402_1005Metric | 2
R60 | 0R0 | ~ | Resistor_SMD:R_0402_1005Metric | 1
R61,R63,R64,R127,R128,R131,R132,R137,R138,R139,R140 | 100k | ~ | Resistor_SMD:R_0402_1005Metric | 11
R62 | 15k | ~ | Resistor_SMD:R_0402_1005Metric | 1
R66,R108,R109,R173,R175 | 1k5 | ~ | Resistor_SMD:R_0402_1005Metric | 5
R69,R71,R76,R78,R80,R82,R84,R86,R167 | 2.2k | ~ | Resistor_SMD:R_0402_1005Metric | 9
R116,R117,R118,R119,R159,R161,R163,R165 | 0Ohm | ~ | Resistor_SMD:R_0402_1005Metric | 8
R120 | 31.6k | ~ | Resistor_SMD:R_0402_1005Metric | 1
R121 | NA | ~ | Resistor_SMD:R_0402_1005Metric | 1 | DNP
R124 | 2.32k | ~ | Resistor_SMD:R_0402_1005Metric | 1
R125,R126,R129,R130,R133,R134,R135,R136 | 1k/0.2W | ~ | Resistor_SMD:R_0603_1608Metric | 8
R142 | 4k7 | ~ | Resistor_SMD:R_0402_1005Metric | 1
R169 | 10k | ~ | Resistor_SMD:R_0402_1005Metric | 1 | DNP
R174,R176 | 22 | ~ | Resistor_SMD:R_0402_1005Metric | 2
R177,R178 | 5.1k | ~ | Resistor_SMD:R_0402_1005Metric | 2
TP1 | 3.3V PG | ~ | TestPoint:TestPoint_Pad_D1.0mm | 1
TP2,TP3,TP4,TP5,TP6,TP7,TP8,TP9 | AFUSE | ~ | TestPoint:TestPoint_Pad_D2.0mm | 8
TP10 | 5V | ~ | TestPoint:TestPoint_Pad_D2.0mm | 1
TP11 | SAFETY_TP | ~ | TestPoint:TestPoint_Pad_D2.0mm | 1
TP13 | 3.3V | ~ | TestPoint:TestPoint_Pad_D2.0mm | 1
U1,U4,U5,U6 | AQY221R4VY |  | PDMS_Additional:SOTFL127P485X190-4N | 4
U2,U3 | MCP2561-E-SN | http://ww1.microchip.com/downloads/en/DeviceDoc/25167A.pdf | Package_SO:SOIC-8_3.9x4.9mm_P1.27mm | 2
U7 | MP4322GDE-P | MP4322GDE-P | PDMS_Additional:QFN-12_MP4322_MNP | 1
U8,U9,U10,U11 | MCP6002-xMC | http://ww1.microchip.com/downloads/en/DeviceDoc/21733j.pdf | Package_DFN_QFN:DFN-8-1EP_3x2mm_P0.5mm_EP1.75x1.45mm | 4
U12 | USBLC6-2SC6 | https://www.st.com/resource/en/datasheet/usblc6-2.pdf | Package_TO_SOT_SMD:SOT-23-6 | 1
U13,U14 | MCP6001-OT | https://ww1.microchip.com/downloads/en/DeviceDoc/MCP6001-1R-1U-2-4-1-MHz-Low-Power-Op-Amp-DS20001733L.pdf | Package_TO_SOT_SMD:SOT-23-5 | 2
Y1 | 16Mhz | ~ | Crystal:Crystal_SMD_2016-4Pin_2.0x1.6mm | 1
Y2 | 32KHz | ~ | Crystal:Crystal_SMD_3215-2Pin_3.2x1.5mm | 1

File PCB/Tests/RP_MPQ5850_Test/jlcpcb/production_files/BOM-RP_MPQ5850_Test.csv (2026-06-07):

Comment | Designator | Footprint | LCSC | Quantity
IQDH45N04LM6CG | Q3 | IFX-PG-TTFN-9-2-V |  | 1
0R0 | R2 | R_0402_1005Metric |  | 1
4.7uF | C3 | D_1206_3216Metric |  | 1
MPQ5850GJ-AEC1-Z | IC1 | SOT65P280X100-8N |  | 1
COM | J1 | PinHeader_1x03_P2.54mm_Vertical |  | 1
IQDH45N04LM6CG | Q1 | IFX-PG-TTFN-9-2-V |  | 1
IQDH45N04LM6CG | Q5 | IFX-PG-TTFN-9-2-V |  | 1
470uF | C7 | CP_Radial_D12.5mm_P5.00mm |  | 1
SMBJ24CA | D1 | D_SMB |  | 1
10nF / 50V | C1 | D_0603_1608Metric |  | 1
1uF | C2 | D_0805_2012Metric |  | 1
IQDH45N04LM6CG | Q4 | IFX-PG-TTFN-9-2-V |  | 1
68uH | L1 | LQH2MCN100K02L |  | 1
100k | R1 | R_0402_1005Metric |  | 1
470uF | C5 | CP_Radial_D12.5mm_P5.00mm |  | 1
IQDH45N04LM6CG | Q2 | IFX-PG-TTFN-9-2-V |  | 1
IQDH45N04LM6CG | Q6 | IFX-PG-TTFN-9-2-V |  | 1
470uF | C6 | CP_Radial_D12.5mm_P5.00mm |  | 1
100k | R3 | R_0402_1005Metric |  | 1
470uF | C4 | CP_Radial_D12.5mm_P5.00mm |  | 1

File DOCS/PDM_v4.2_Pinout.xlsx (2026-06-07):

 | ID | NAME | WHAT | USED
BIG 34 PIN | 1 | HP_MOS7 | FAN1 | YES
 | 2 | LP_MOS7 | ADD1
 | 3 | HP_MOS7 | FAN2 | YES
 | 4
 | 5 | LP_MOS6 | LOGGER
 | 6
 | 7 | LP_MOS5 | MOTOROLA
 | 8 | HP_MOS6 | FUEL PUMP | YES
 | 9 | HP_MOS6 | FUEL PUMP | YES
 | 10 | GND
 | 11 | LP_MOS4 | DASHBOARD + STEERING
 | 12 | GND
 | 13 | LP_MOS3 | TELEMETRY FRONT
 | 14 | GND
 | 15 | LP_MOS2
 | 16 | HP_MOS5 | COILS | YES
 | 17 | HP_MOS5 | INJECTORS | YES
 | 18 | LP_MOS8 | ADD2
 | 19 | HP_MOS8 | ECUMASTER IGNITION | YES
 | 20 | HP_MOS8 | ECUMASTER CONSTANT, Lambda | YES
 | 21 | `+12VA | GEAR CONTROL + 12VA | YES
 | 22 | `+12VA
 | 23 | `+3.3VP
 | 24 | `+3.3VP
 | 25 | `+5VL | SAFETY IN | YES
 | 26 | `+5VL
 | 27 | GND
 | 28 | GND
 | 29 | GND
 | 30 | GND
 | 31 | GND
 | 32 | GND
 | 33 | SAFETY_IN | SAFETY OUT | YES
 | 34 | LP_MOS1 | TELEMETRY + BRAKE LIGHT
SMALL 26 PIN | 35 | HP_MOS4 |  | NO
 | 36 | HP_MOS4 |  | NO
 | 37 | HP_MOS4 |  | NO
 | 38 | CAN1_L
 | 39 | HP_MOS3 | GEAR CONTROL | YES
 | 40 | CAN1_H
 | 41 | HP_MOS3 | GEAR CONTROL | YES
 | 42 | CAN2_L
 | 43 | HP_MOS3 |  | NO
 | 44 | CAN2_H
 | 45 | HP_MOS2 | CAN LAMBDA | YES
 | 46 | HP_MOS1 | SERVO 12V | YES
 | 47 | HP_MOS2 | CAN LAMBDA | YES
 | 48 | ADC_IN1
 | 49 | ADC_IN2
 | 50 | ADC_IN3
 | 51 | ADC_IN4
 | 52 | CONN_AD_IN5
 | 53 | CONN_AD_IN6 | 3. HBRIDGE VIOLET
 | 54 | CONN_AD_IN7 | 10. HBRIDGE GREEN
 | 55 | CONN_AD_IN8 | 2. HBRIDGE MAIN
 | 56 | GND
 | 57 | GND
 | 58 | GND
 | 59 | HP_MOS1 | SERVO 12V | YES
 | 60 | GND

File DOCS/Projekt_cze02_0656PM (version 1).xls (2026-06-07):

PDM_V4.3_ADDITONAL
Nr Mouser | Nr prod. | Producent | Nr klienta | Opis | Wielkość zamówienia | Cena (PLN) | Wewn.: (PLN)
652-SF-1206HV40M-2 | SF-1206HV40M-2 | Bourns | PDM_v4.3_MAIN_CHANNEL | Surface Mount Fuses 40A Single blow fuse 1206 SinglFuse | 12 | 5.12 | 61.44
863-SZMM5Z3V9T5G | SZMM5Z3V9T5G | onsemi | PDM_v4.3_D41__ | Zener Diodes SOD-523 EUT SNGL PB FREE | 36 | 1.23 | 44.28
581-F0805B1R00FSTR | F0805B1R00FSTR | KYOCERA AVX | PDM_v4.3_F2_F19_F23 | Surface Mount Fuses 1A SMD | 9 | 4.17 | 37.53
511-ASM330LHHTR | ASM330LHHTR | STMicroelectronics | PDM_IC15 | IMUs - Inertial Measurement Units Automotive 6-axis inertial module: 3D accelerometer and 3D gyroscope | 1 | 31.48 | 31.48
579-MCP2561T-E/SN | MCP2561T-E/SN | Microchip | PDM_v4.3_U2_U3 | CAN Interface IC CAN Tranceiver | 6 | 4.73 | 28.38
579-MCP6002T-E/MC | MCP6002T-E/MC | Microchip | PDM_v4.3_U8/9/10/11 | Operational Amplifiers - Op Amps Dual 1.8V 1MHz OP, E temp | 12 | 1.96 | 23.52
994-XEL4020-102MEC | XEL4020-102MEC | Coilcraft | PDM_v4.3_L4 | Power Inductors - SMD 1uH Shld 20% 9.6A 14.6mOhms AECQ2 | 3 | 7.78 | 23.34
511-LDO40LPU33RY | LDO40LPU33RY | STMicroelectronics | PDM_v4.3_IC3 | LDO Voltage Regulators 400 mA, 38 V low-dropout regulator, 45 uA quiescent current | 3 | 7.53 | 22.59
710-7461383 | 7461383 | Wurth Elektronik | PDM | Terminals WP-SHFU Pin-Plate 16Pin M5 Shank 180A | 2 | 11.05 | 22.1
581-F0805B2R00FSTR | F0805B2R00FSTR | KYOCERA AVX | PDM_v4.3_F20 | Surface Mount Fuses 2A SMD | 5 | 4.17 | 20.85
78-SI2319CDS-T1-BE3 | SI2319CDS-T1-BE3 | Vishay | PDM_v4.3_Q1_Q11 | MOSFETs P-CHANNEL 40V (D-S | 10 | 1.68 | 16.8
871-B82462G4103M | B82462G4103M | TDK | PDM_v4.3_L3 | Power Inductors - SMD 10uH 1.5A 20% 6.3x6.3mm SMD | 3 | 5.25 | 15.75
660-RS73G1JRTTD1001F | RS73G1JRTTD1001F | KOA Speer | PDM_V4.3_R125 | Thick Film Resistors - SMD 0603 1kOhm 0.2W Tol 1% AEC-Q200 | 24 | 0.641 | 15.38
70-IHLP1616ABER2R2M1 | IHLP1616ABER2R2M11 | Vishay | PDM_v4.3_L5 | Power Inductors - SMD 2.2uH 20% | 3 | 4.43 | 13.29
871-B41866C5108M000 | B41866C5108M000 | TDK | PDM | Aluminum Electrolytic Capacitors - Radial Leaded 25VDC 1000uF 20% STD Leads | 2 | 6.45 | 12.9
810-C2012X8R1H104K | C2012X8R1H104K125AA | TDK | PDMK_v4.3_C20__ | Multilayer Ceramic Capacitors MLCC - SMD/SMT 0805 50V 0.1uF X8R 10% T: 1.25mm | 36 | 0.34 | 12.24
603-RC0402BR-078K2L | RC0402BR-078K2L | YAGEO | PDM_v4.3_R67__ | Thick Film Resistors - SMD 8.2kOhms 1/16W 0402 0.1% | 24 | 0.499 | 11.98
187-CL31B106KBHNNNE | CL31B106KBHNNNE | Samsung Electro-Mechanics | PDM_v4.3_C6/7__ | Multilayer Ceramic Capacitors MLCC - SMD/SMT 10uF+/-10% 50V X7R 3 1206 | 24 | 0.49 | 11.76
810-CGA5L3X7R1H225KS | CGA5L3X7R1H225K160AE | TDK | PDM_v4.3_C63_DNP | Multilayer Ceramic Capacitors MLCC - SMD/SMT SOFT 1206 50V 2.2uF X7R 10% AEC-Q200 | 3 | 3.8 | 11.4
863-SZMM5Z5V6T5G | SZMM5Z5V6T5G | onsemi | PDM_v4.3_D63__ | Zener Diodes ZENER DIODE SOD523 | 12 | 0.937 | 11.24
581-KAM21KR71H225KU | KAM21KR71H225KU | KYOCERA AVX | PDM_v4.3_C25_C26 | Multilayer Ceramic Capacitors MLCC - SMD/SMT 50V 2.2uF X7R 0805 1 0% AEC-Q200 | 10 | 1.08 | 10.8
80-C0805C474K3RECLR | C0805C474K3REC7210 | KEMET | PDM_C19_C68 | Multilayer Ceramic Capacitors MLCC - SMD/SMT 25V 0.47uF X7R 0805 10% | 20 | 0.499 | 9.98
946-MP4323GDE-P | MP4323GDE-P | Monolithic Power Systems (MPS) | PDM_v4.3_U7 | Switching Voltage Regulators 36V, 3A, Low Quiescent Current | 1 | 9.33 | 9.33
80-EDK226M050S9GAA | EDK226M050S9GAA | KEMET | PDM_v4.3_C27 | Aluminum Electrolytic Capacitors - SMD 50V 22uF AEC-Q200 20% 85C/2K Hours | 10 | 0.873 | 8.73
710-742792063 | 742792063 | Wurth Elektronik | PDM_v4.3_FB1_L2 | Ferrite Beads WE-CBF 0805 100MHz 60Ohm 3000mA AECQ200 | 10 | 0.86 | 8.6
963-UMK316ABJ475MLHT | UMK316ABJ475MLHT | TAIYO YUDEN | PDM_v4.3_C28_C29 | Multilayer Ceramic Capacitors MLCC - SMD/SMT 963-MCASU31LAB5475MT RPLCMT PN 50V 4.7uF X5R 1206 AEC-Q200 | 10 | 0.86 | 8.6
579-MCP6001T-E/OT | MCP6001T-E/OT | Microchip | PDM_v4.3_U13_U14 | Operational Amplifiers - Op Amps Single 1.8V 1MHz | 6 | 1.43 | 8.58
595-TSD05CDYFR | TSD05CDYFR | Texas Instruments | PDM_v4.3_D55,D56 | ESD Protection Diodes / TVS Diodes 5.5-V 30-A bidirecti onal surge protectio | 24 | 0.292 | 7.01
81-GRM21BZ71E475KE5L | GRM21BZ71E475KE15L | Murata | PDM_v4.3_C1 | Multilayer Ceramic Capacitors MLCC - SMD/SMT 4.7 uF 25 VDC 10% 0805 X7R | 10 | 0.606 | 6.06
81-GCM155R71H333KE2D | GCM155R71H333KE02D | Murata | PDM_v4.3_C93, C98, __ | Multilayer Ceramic Capacitors MLCC - SMD/SMT 0.033 uF 50 VDC 10% 0402 X7R AEC-Q200 | 100 | 0.056 | 5.6
81-GCM155R71H104ME2J | GCM155R71H104ME02J | Murata | PDM_v4.3_C2_C64__ | Multilayer Ceramic Capacitors MLCC - SMD/SMT 0.1 uF 50 VDC 20% 0402 X7R AEC-Q200 | 100 | 0.056 | 5.6
595-TSD12CDYFR | TSD12CDYFR | Texas Instruments | PDM_v4.3_D68 | ESD Protection Diodes / TVS Diodes 12V bidirectional su rge protection devic | 3 | 1.76 | 5.28
81-GRM155D71A475ME5D | GRM155D71A475ME15D | Murata | PDM_v4.3_C41 | Multilayer Ceramic Capacitors MLCC - SMD/SMT 4.7UF 10V 20% 0402 | 10 | 0.482 | 4.82
603-AC0603KPX79BB103 | AC0603KPX7R9BB103 | YAGEO | PDM_v4.3_C14_15__ | Multilayer Ceramic Capacitors MLCC - SMD/SMT 50V 0.01uF X7R 0603 10% AEC-Q200 | 24 | 0.181 | 4.34
603-AC0402KR9BB102 | AC0402KRX7R9BB102 | YAGEO | PDM_v4.3_C23_99_104__ | Multilayer Ceramic Capacitors MLCC - SMD/SMT 50V 1000pF X7R 0402 10% AEC-Q200 | 30 | 0.142 | 4.26
81-GRT188C81E475KE3D | GRT188C81E475KE13D | Murata | PDM_v4.3_C4_C92 | Multilayer Ceramic Capacitors MLCC - SMD/SMT 4.7 uF 25 VDC 10% 0603 X6S AEC-Q200 | 10 | 0.409 | 4.09
187-CL05B103KB5NFNC | CL05B103KB5NFNC | Samsung Electro-Mechanics | PDM_v4.3_C94_100__ | Multilayer Ceramic Capacitors MLCC - SMD/SMT 10nF+/-10% 50V X7R 1 0402 | 100 | 0.039 | 3.9
81-GCM155R71H473KE2D | GCM155R71H473KE02D | Murata | PDM_v4.3_C32_33_34__ | Multilayer Ceramic Capacitors MLCC - SMD/SMT 0.047 uF 50 VDC 10% 0402 X7R AEC-Q200 | 30 | 0.082 | 2.46
80-C0402C101K5RAUTO | C0402C101K5RACAUTO | KEMET | PDM_v4.3_C21 | Multilayer Ceramic Capacitors MLCC - SMD/SMT 50V 100pF X7R 0402 10% AEC-Q200 | 10 | 0.198 | 1.98
81-GRM155R61H105KE5J | GRM155R61H105KE05J | Murata | PDM_v4.3_C43_C60_C83 | Multilayer Ceramic Capacitors MLCC - SMD/SMT 1 uF 50 VDC 10% 0402 X5R | 10 | 0.185 | 1.85
603-BBGK160808601Y00 | BBGK00160808601Y00 | Pulse | PDM_v4.3_L1 | Ferrite Beads 600Ohms RDC=0.30Ohms 400mA | 10 | 0.159 | 1.59
603-CC0402KR7BN100 | CC0402KRNPO7BN100 | YAGEO | PDM_v4.3_C42_46___ | Multilayer Ceramic Capacitors MLCC - SMD/SMT 16 V 10 pF C0G 0402 10% | 20 | 0.077 | 1.54
603-AC0805FR-7W47RL | AC0805FR-7W47RL | YAGEO | PDM_v4.3_R28_R94 | Thick Film Resistors - SMD 47Ohms 1/8W 0805 1% AEC-Q200 Double Power Version | 10 | 0.129 | 1.29
71-CRCW0402-31.6K-E3 | CRCW040231K6FKED | Vishay | PDM_v4.3_R120 | Thick Film Resistors - SMD 1/16watt 31.6Kohms 1% | 10 | 0.125 | 1.25
603-AC0402FR-1315KL | AC0402FR-1315KL | YAGEO | PDM_v4.3_R62 | Thick Film Resistors - SMD 15K OHM 1% | 20 | 0.06 | 1.2
581-KGM05AR71H221KH | KGM05AR71H221KH | KYOCERA AVX | PDM_v4.3_C18_C67 | Multilayer Ceramic Capacitors MLCC - SMD/SMT 50V 220pF X7R 0402 1 0% | 10 | 0.099 | 0.99
603-RE0402FRE071KL | RE0402FRE071KL | YAGEO | PDM_v4.3_R5/6/7/8/__ | Thick Film Resistors - SMD 1 kOhms 62.5 mW 0402 1% | 18 | 0.052 | 0.94

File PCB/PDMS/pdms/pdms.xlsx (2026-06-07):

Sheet: pdms (2)
Column1 | Column2 | Column3 | Column4 | Column5 | Column6 | Column7

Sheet: pdms (3)
Kolumna1 | Column1 | Column2 | Column3 | Column4 | Column5 | Column6 | Column7
1 | Source: | C:\Users\Karol\Documents\GitHub\PDM\PCB\PDMS\pdms\pdms.kicad_sch
0
1 | Date: | 01.06.2023 14:44:04
0
1 | Tool: | Eeschema (6.0.8)
0
1 | Generator: | C:\Program Files\KiCad\6.0\bin\scripting\plugins/bom_csv_grouped_by_value_with_fp.py
0
1 | Component Count: | 373
0
1 | Ref | Qnty | Value | Cmp name | Footprint | Description | Vendor
0
1 | BZ1, | 1 | Buzzer | Buzzer | Buzzer_Beeper:Buzzer_12x9.5RM7.6 | Buzzer, polarized
0
1 | C1, C5, C9, C13, C24, C28, C32, C36, C75, | 9 | 10nF | C_Small | Capacitor_SMD:C_0402_1005Metric | Unpolarized capacitor, small symbol
0
1 | C2, C6, C10, C21, C25, C29, C33, C37, | 8 | 150nF | C_Small | Capacitor_SMD:C_0402_1005Metric | Unpolarized capacitor, small symbol
0
1 | C3, C7, C11, C20, C22, C26, C30, C34, C38, C69, | 10 | 100nF | C_Small | Capacitor_SMD:C_0805_2012Metric | Unpolarized capacitor, small symbol
0
1 | C4, C8, C12, C23, C27, C31, C35, C39, | 8 | 10nF | C_Small | Capacitor_SMD:C_0805_2012Metric | Unpolarized capacitor, small symbol
0
1 | C14, C15, C16, C17, C70, C71, C72, C73, | 8 | 10nF | C_Small | Capacitor_SMD:C_0603_1608Metric | Unpolarized capacitor, small symbol
0
1 | C18, C67, | 2 | 220pF | C_Small | Capacitor_SMD:C_0402_1005Metric | Unpolarized capacitor, small symbol
0
1 | C19, C68, | 2 | 470nF | C_Small | Capacitor_SMD:C_0805_2012Metric | Unpolarized capacitor, small symbol
0
1 | C40, | 1 | 1F 5V | C_Small | PDMS_Additional:CAPCP3225X100N | Unpolarized capacitor, small symbol
0
1 | C41, | 1 | 4u7 | C_Small | Resistor_SMD:R_0402_1005Metric | Unpolarized capacitor, small symbol
0
1 | C42, C46, C61, | 3 | 10pF | C_Small | Resistor_SMD:R_0402_1005Metric | Unpolarized capacitor, small symbol
0
1 | C43, | 1 | 1u | C_Small | Resistor_SMD:R_0402_1005Metric | Unpolarized capacitor, small symbol
0
1 | C44, C45, C47, C48, C49, C50, C51, C52, C53, C66, C91, | 11 | 100n | C_Small | Resistor_SMD:R_0402_1005Metric | Unpolarized capacitor, small symbol
0
1 | C54, | 1 | 1uF | C_Small | Capacitor_SMD:C_0805_2012Metric | Unpolarized capacitor, small symbol
0
1 | C55, | 1 | 4.7uF | C_Small | Capacitor_SMD:C_0603_1608Metric | Unpolarized capacitor, small symbol
0
1 | C56, | 1 | 22uF | C_Small | Capacitor_SMD:C_0805_2012Metric | Unpolarized capacitor, small symbol
0
1 | C57, | 1 | 1nF | C_Small | Resistor_SMD:R_0402_1005Metric | Unpolarized capacitor, small symbol
0
1 | C58, | 1 | 0.1uF | C_Small | Resistor_SMD:R_0402_1005Metric | Unpolarized capacitor, small symbol
0
1 | C59, | 1 | 6.8nF | C_Small | Resistor_SMD:R_0402_1005Metric | Unpolarized capacitor, small symbol
0
1 | C60, | 1 | 1uF | C_Small | Resistor_SMD:R_0402_1005Metric | Unpolarized capacitor, small symbol
0
1 | C62, C63, | 2 | 22uF | C_Small | Resistor_SMD:R_0402_1005Metric | Unpolarized capacitor, small symbol
0
1 | C64, C65, C74, C76, C89, | 5 | 100nF | C_Small | Capacitor_SMD:C_0402_1005Metric | Unpolarized capacitor, small symbol
0
1 | C77, C78, C79, C80, C81, C82, C87, | 7 | 100n | C_Small | Capacitor_SMD:C_0402_1005Metric | Unpolarized capacitor, small symbol
0
1 | C83, | 1 | 1u | C_Small | Capacitor_SMD:C_0402_1005Metric | Unpolarized capacitor, small symbol
0
1 | C84, C85, | 2 | 10pF | C_Small | Capacitor_SMD:C_0402_1005Metric | Unpolarized capacitor, small symbol
0
1 | C86, | 1 | 0.1uF | C_Small | Capacitor_SMD:C_0402_1005Metric | Unpolarized capacitor, small symbol
0
1 | C88, | 1 | C | C | Capacitor_THT:CP_Radial_D12.5mm_P5.00mm | Unpolarized capacitor
0
1 | D1, D2, D3, D5, D6, D7, D8, D9, | 8 | 40V | D_TVS | Diode_SMD:D_SMA | Bidirectional transient-voltage-suppression diode
0
1 | D4, D37, | 2 | BAT54SW | BAT54SW | Package_TO_SOT_SMD:SOT-323_SC-70 | Dual schottky barrier diode, in series, SOT-323
0
1 | D10, D11, D12, D13, D14, D15, D16, D17, D18, D19, D20, D21, D22, D29, D30, D31, D32, D36, | 18 | WS2812B | WS2812B | LED_SMD:LED_WS2812B-2020_PLCC4_2.0x2.0mm | RGB LED with integrated controller
0
1 | D23, D24, D25, D26, | 4 | BAT54BRW-7-F | BAT54BRW-7-F | PDM_Additional:SOT65P210X110-6N
0
1 | D27, D28, | 2 | PESD2CANFD24L-UX | PESD2CANFD24L-UX | PDMS_Additional:SOT65P210X110-3N | PESD2CANFD24L-U - ESD protection for In-vehicle networks
0
1 | D33, | 1 | LED | LED_Small | LED_SMD:LED_0402_1005Metric | Light emitting diode, small symbol
0
1 | D34, D35, | 2 | LED | LED_Small | LED_SMD:LED_0805_2012Metric | Light emitting diode, small symbol
0
1 | F1, | 1 | 3A | Fuse | Fuse:Fuse_0805_2012Metric | Fuse
0
1 | F2, F3, F4, F5, F6, F7, F8, F9, | 8 | 40A | Fuse_Small | PDMS_Additional:0ACA9400TE | Fuse, small symbol
0
1 | F10, F11, F12, F13, F14, F15, F16, F17, | 8 | 7A | Fuse_Small | Fuse:Fuse_1206_3216Metric | Fuse, small symbol
0
1 | H1, H2, H3, H4, | 4 | MountingHole_Pad | MountingHole_Pad | MountingHole:MountingHole_3.2mm_M3_Pad_Via | Mounting Hole with connection
0
1 | IC1, IC2, IC3, IC4, IC5, IC6, IC8, IC9, | 8 | BTS500101TAEATMA1 | BTS500101TAEATMA1 | PDMS_Additional:PG-TO263-7-3_3 | Power Switch ICs - Power Distribution
0
1 | IC7, IC16, | 2 | BTS722204ESAXUMA1 | BTS722204ESAXUMA1 | PDMS_Additional:SOP65P600X115-25N | Power Switch ICs - Power Distribution SPOC
0
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

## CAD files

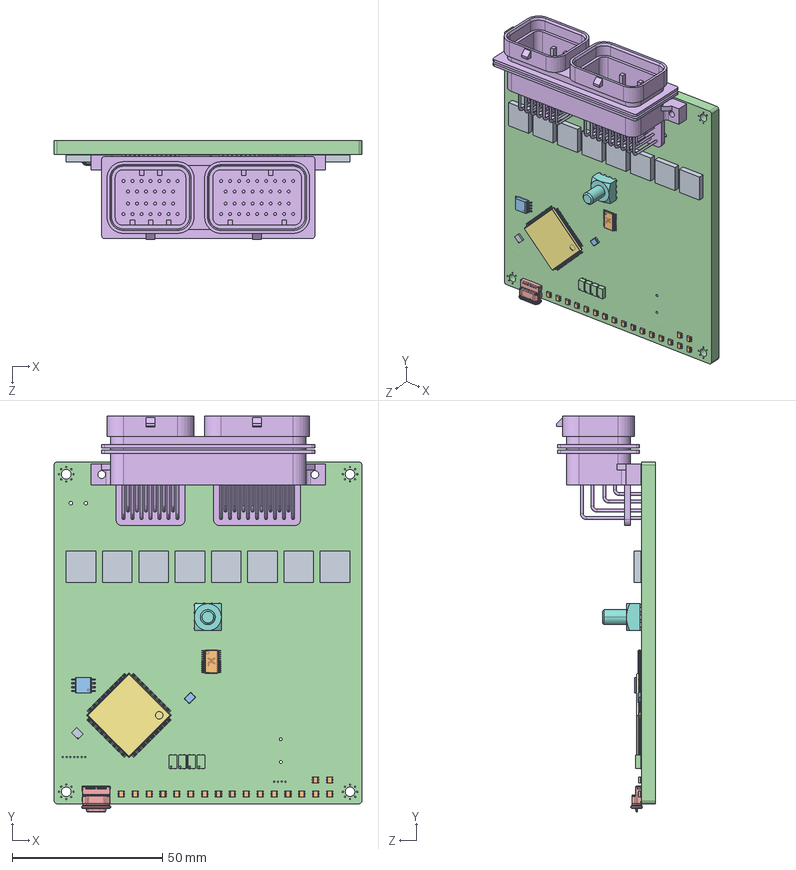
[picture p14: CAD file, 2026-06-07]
MODEL/pdms_v4.2_2024.SLDASM
102.5 x 131.9 x 32.9 mm
COMPOUND.step x 8
SOLID.step x 18
COMPOUND-0.step
COMPOUND-1.step x 4
COMPOUND-2.step
SOLID-3.step
COMPOUND-4.step
SOLID-5.step
COMPOUND-6.step
COMPOUND-7.step
COMPOUND-8.step
pdms PCB.step

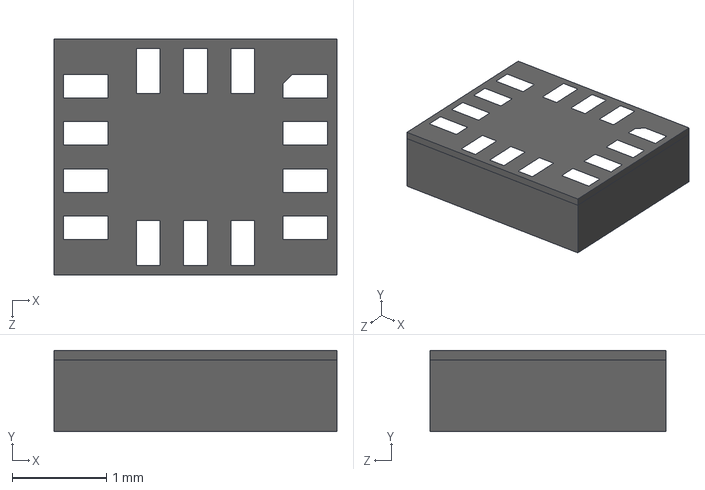
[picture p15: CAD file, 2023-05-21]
PCB/PDMS/pdms_additional/ASM330LHHTR/ASM330LHHTR.stp
3.00 x 0.86 x 2.50 mm

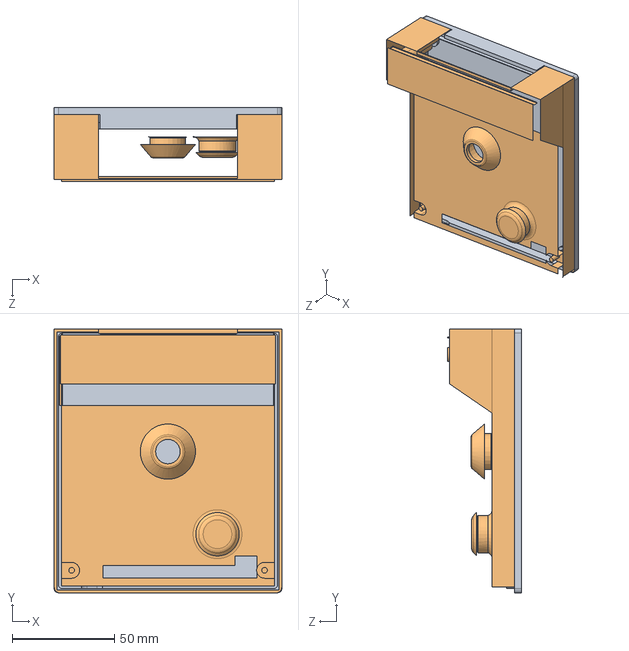
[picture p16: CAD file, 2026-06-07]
MODEL/CASE_2024/assy.SLDASM
111.5 x 129.3 x 38.4 mm
obudowa dół
prostokont ale lepszy

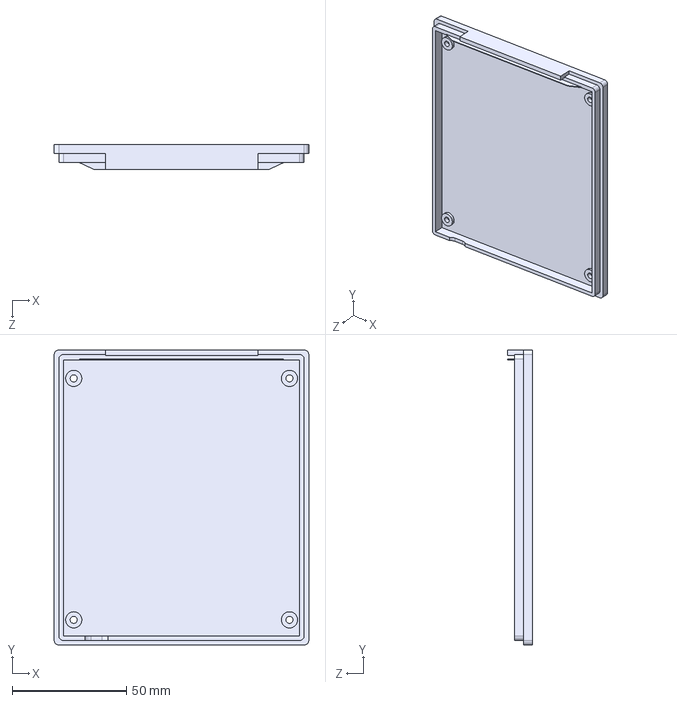
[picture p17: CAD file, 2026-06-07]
MODEL/CASE_2024/bottom.STEP
111.5 x 129.2 x 11.1 mm

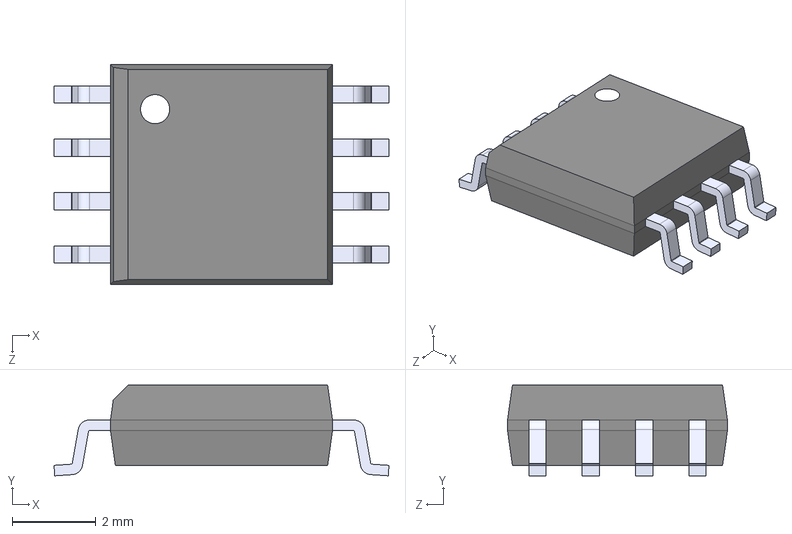
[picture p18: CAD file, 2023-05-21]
PCB/Additional/AT25SF128A-SHB-T/AT25SF128A-SHB-T.step
7.98 x 2.16 x 5.24 mm

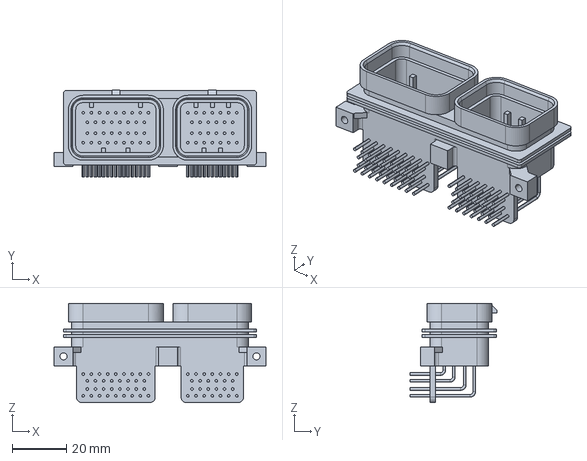
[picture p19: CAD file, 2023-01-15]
PCB/Additional/TE_6473427-1/.stp
78.0 x 32.1 x 36.5 mm

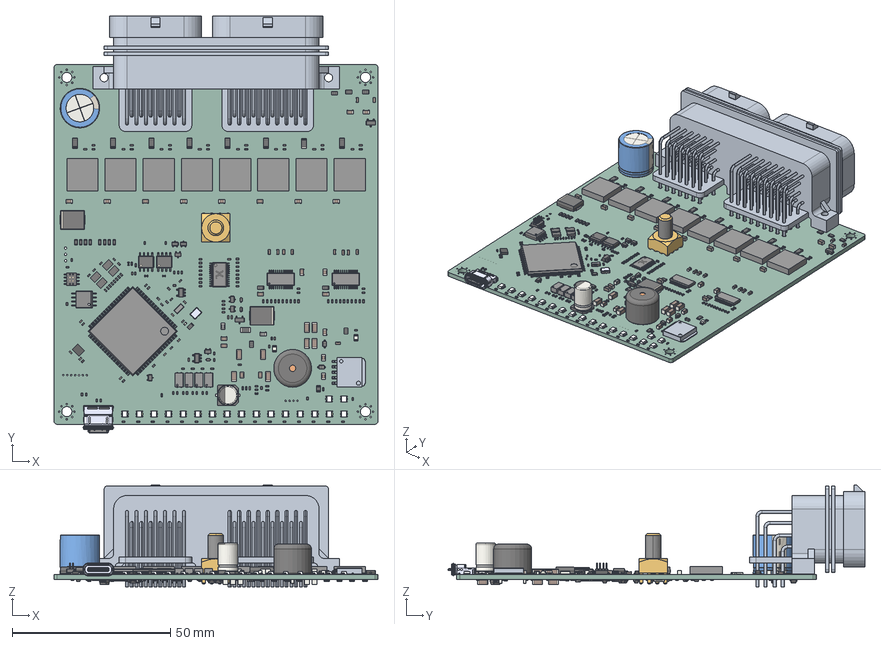
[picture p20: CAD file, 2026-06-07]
PCB/PDMS/pdms/3D_MODELS/pdms_v4.3_2025.step
102.5 x 131.9 x 32.2 mm
R_0402_1005Metric x 202
C_0805_2012Metric x 21
C_0402_1005Metric x 63
D_SMC x 2
ASSEMBLY x 15
WS2812B-2020 x 18
C_0603_1608Metric x 11
C_1206_3216Metric x 15
SOT_23 x 2
AT25QF128A-SHB-T
R_0603_1608Metric x 8
PinHeader_2x04_P100mm_Vertical_SMD
CP_Radial_D125mm_P500mm
R_0805_2012Metric x 3
LED_0402_1005Metric
Fuse_0805_2012Metric x 6
SOT_323_SC_70 x 13
C-6473427-1
DFN-8-1EP_3x2mm_Pitch0.5mm x 4
D_SOD_523 x 16
Fuse_1206_3216Metric x 17
Buzzer_12x95RM76
ISM330DHCXTR
SOT355-1
Crystal_SMD_3215-2Pin_3.2x1.5mm
D_SOD_323 x 11
HRP5
SOT_23_5 x 2
L_0805_2012Metric x 2
SOIC_8_39x49mm_P127mm x 2
CPH3225A
CP_Elec_63x99
LED_0805_2012Metric x 2
SOT_23_6
L_0603_1608Metric
pdms_PCB

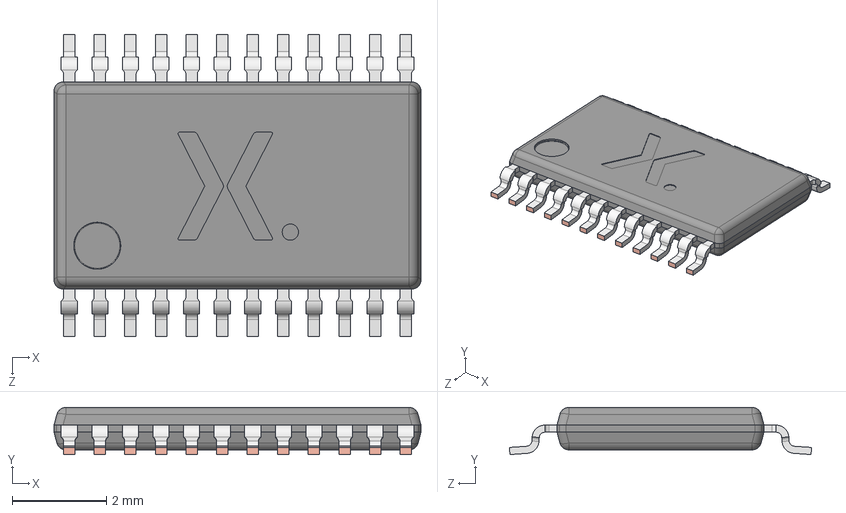
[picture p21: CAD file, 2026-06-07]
PCB/PDMS/pdms_additional/74HC4067PW-Q100J/74HC4067PW-Q100J.stp
7.80 x 1.00 x 6.42 mm
SOT355-1 Lower Mold body
SOT355-1 Lead
SOT355-1 Upper Mold body

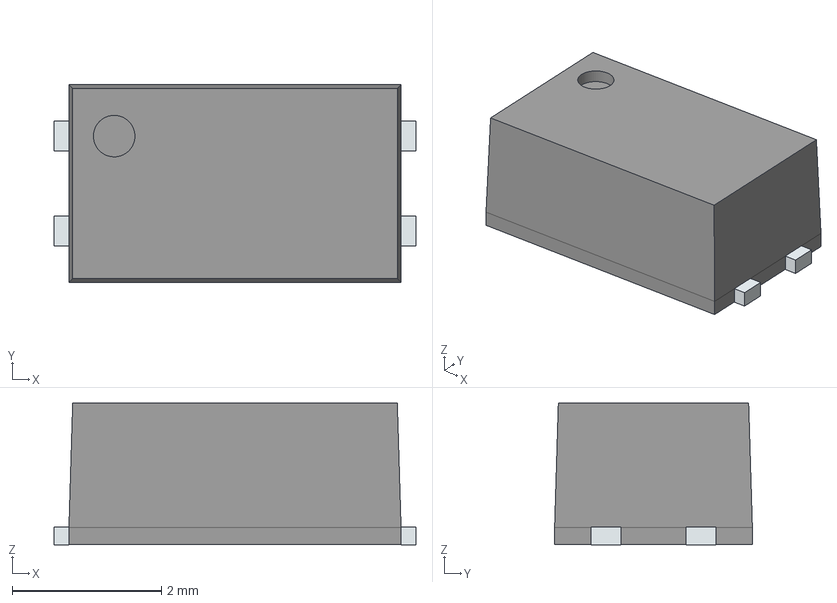
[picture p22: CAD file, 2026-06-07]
PCB/PDMS/pdms_additional/AQY221R4VY/3D/AQY221R4VY.stp
4.85 x 2.65 x 1.90 mm
PinsArrayL
PinsArrayR

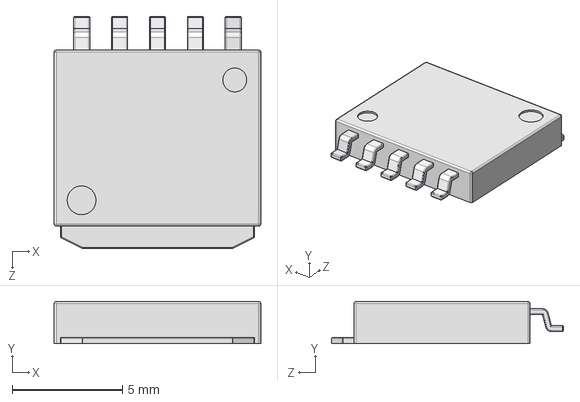
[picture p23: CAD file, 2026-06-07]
PCB/PDMS/pdms_additional/BD50FD0WHFP-TR/BD50FD0WHFP-TR.stp
9.40 x 1.92 x 10.5 mm

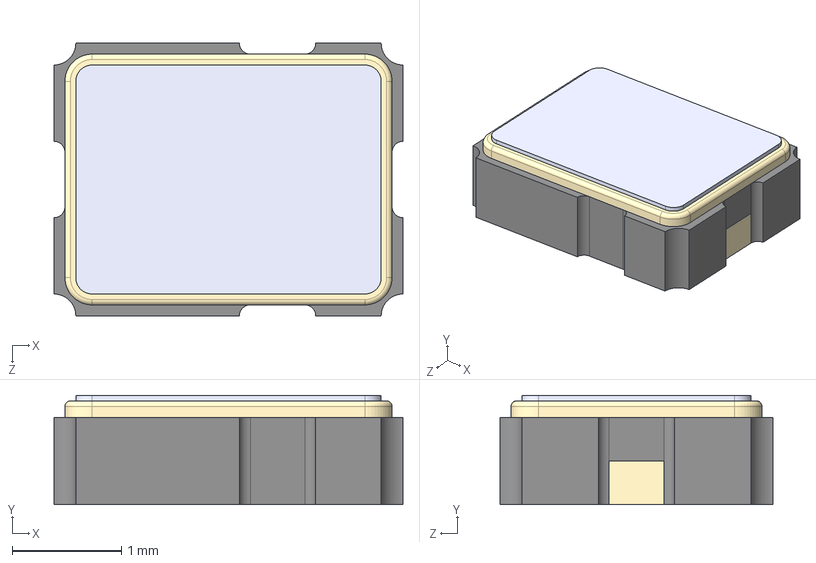
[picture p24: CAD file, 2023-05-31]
PCB/PDMS/pdms_additional/CPH3225A/CPH3225A.step
3.20 x 1.00 x 2.50 mm

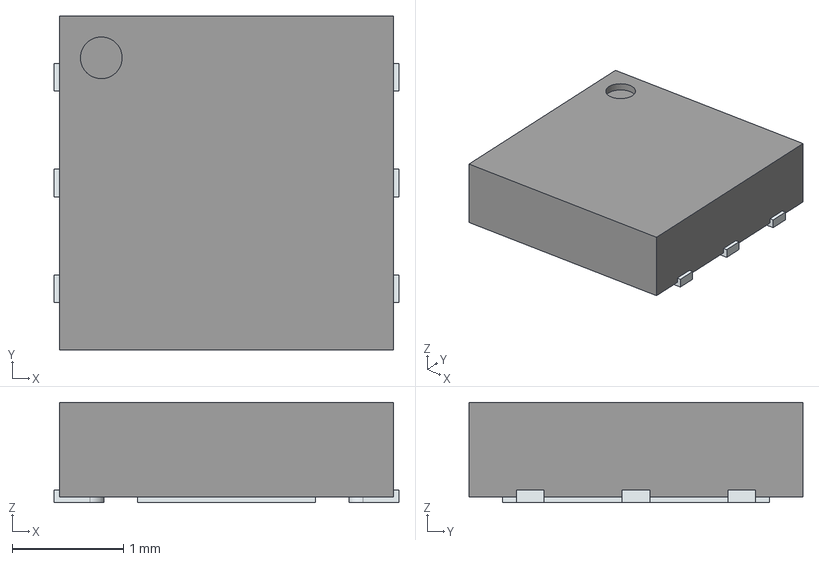
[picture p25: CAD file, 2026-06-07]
PCB/PDMS/pdms_additional/LDO40LPU33RY/LDO40LPU33RY.stp
3.10 x 3.00 x 0.9 mm
ThermalPin
PinsArrayLR

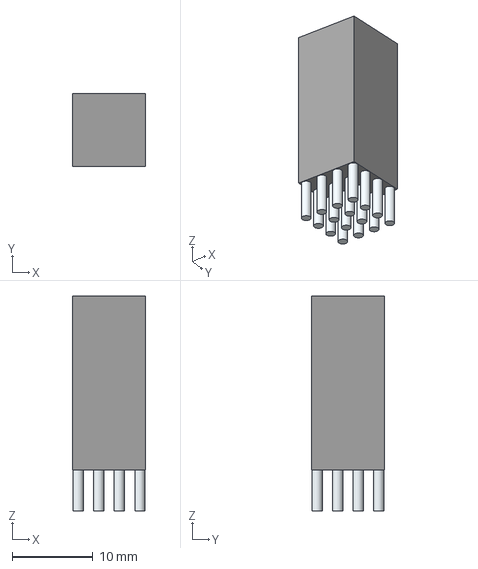
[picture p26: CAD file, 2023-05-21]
PCB/PDMS/pdms_additional/N01_036_6501_001/N01_036_6501_001.stp
9.00 x 9.00 x 26.6 mm
Leads

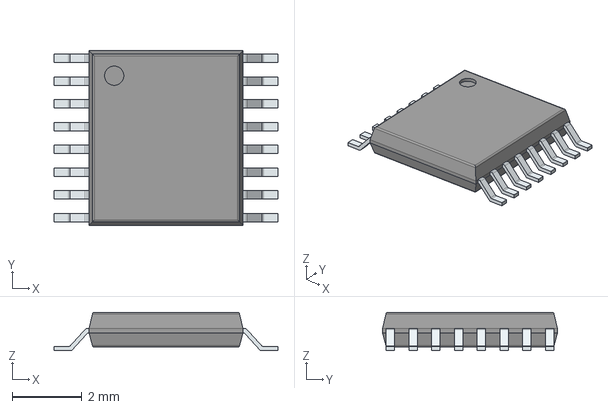
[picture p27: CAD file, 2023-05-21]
PCB/PDMS/pdms_additional/NX3L4051PW,118/NX3L4051PW,118.stp
6.40 x 5.00 x 1.10 mm
PinsArrayLR

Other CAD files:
MODEL/CASE_2025/pdms_assy_2025.SLDASM
PCB/PDMS/pdms_additional/SPBTLE-RF/SPBTLE-RF.step
PCB/PDMS/pdms_additional/WS2812B-2020/WS2812B-2020.stp
MODEL/CASE_2025/pdms_thread_extender.SLDPRT
MODEL/CASE_2024/bottom.3mf
MODEL/CASE_2024/bottom.SLDPRT
MODEL/CASE_2024/upper.SLDPRT
MODEL/CASE_2025/14mm.SLDPRT
MODEL/CASE_2025/14mm.stl
MODEL/CASE_2025/pdms_lower_case.SLDPRT
MODEL/CASE_2025/pdms_lower_case.STL
MODEL/CASE_2025/pdms_upper_case.SLDPRT
MODEL/CASE_2025/pdms_upper_case.STL
PCB/PDMS/pdms/3D_MODELS/pdms_v4.3_2025.SLDASM
PCB/PDMS/pdms_additional/6437288-2/6437288-2.stp
PCB/PDMS/pdms_additional/BTS500101LUAAUMA1/BTS500101LUAAUMA1.stp
PCB/PDMS/pdms_additional/BTS500101TAEATMA1/BTS500101TAEATMA1.stp
PCB/PDMS/pdms_additional/BTS722204ESAXUMA1/BTS722204ESAXUMA1.stp
PCB/PDMS/pdms_additional/USB TYPE C/2305018-2.step
PCB/PDMS/pdms_additional/WE_7461383/7461383.stp
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

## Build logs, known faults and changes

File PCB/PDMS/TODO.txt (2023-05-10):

1. Add connector
2. Take measurments to check if any inverter will be needed
3. Test if it's possible to generate PWM on 4 channels
4. Change footprint of debug connectors

Remember about:
1. 5V and 3.3V output for sensors -> 5VA will be carried from BSPD
2.

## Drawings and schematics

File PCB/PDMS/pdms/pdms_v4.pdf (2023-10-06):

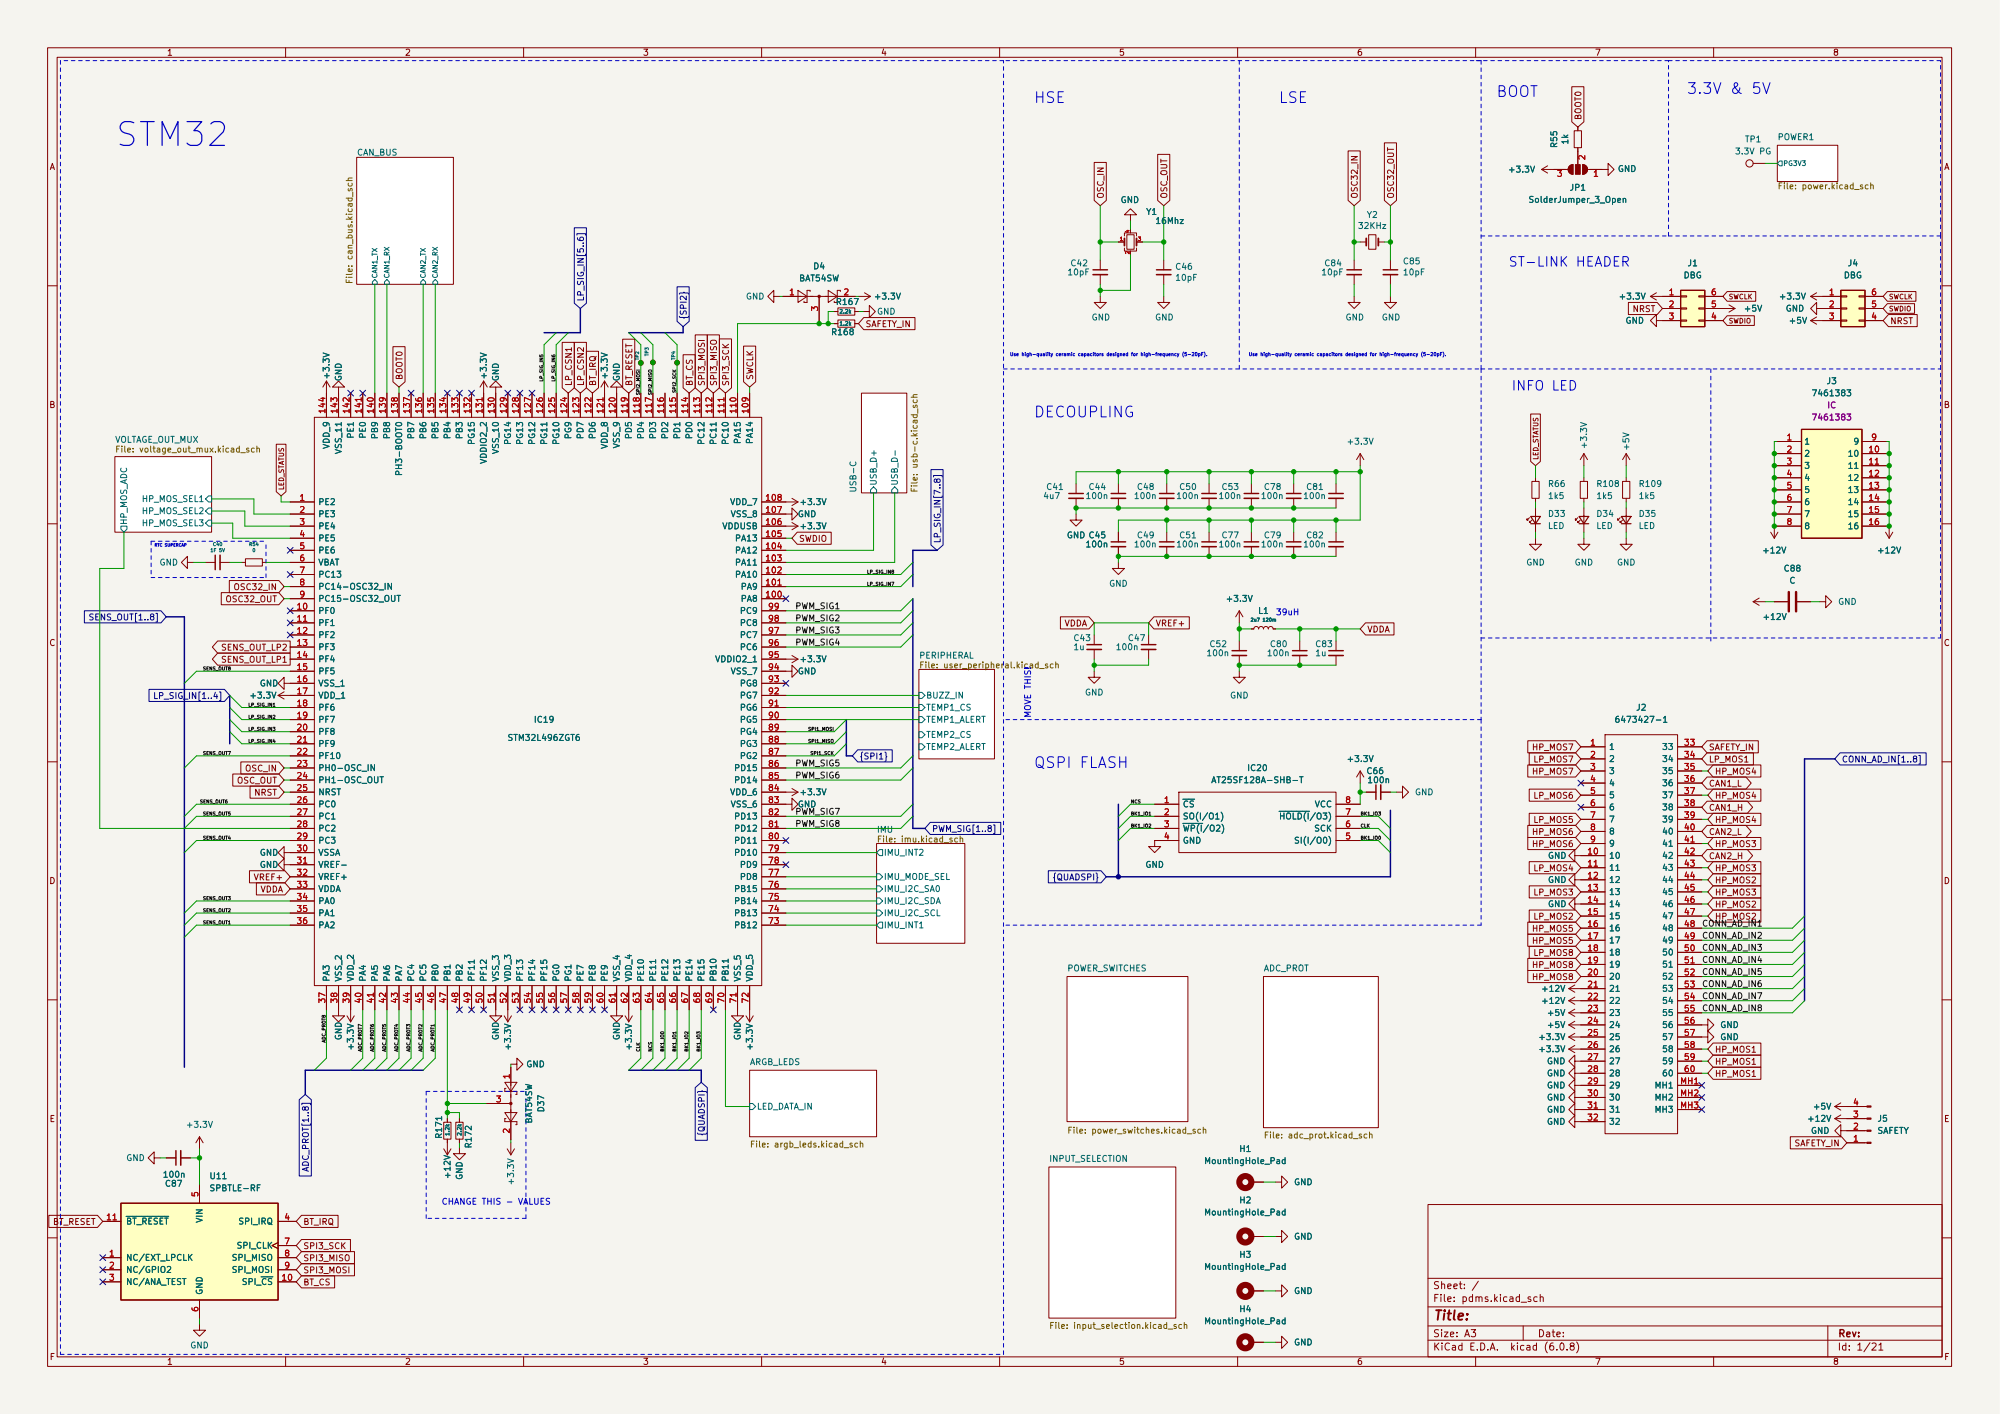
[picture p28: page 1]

Use high-quality ceramic capacitors designed for high-frequency (5-20pF). HSE

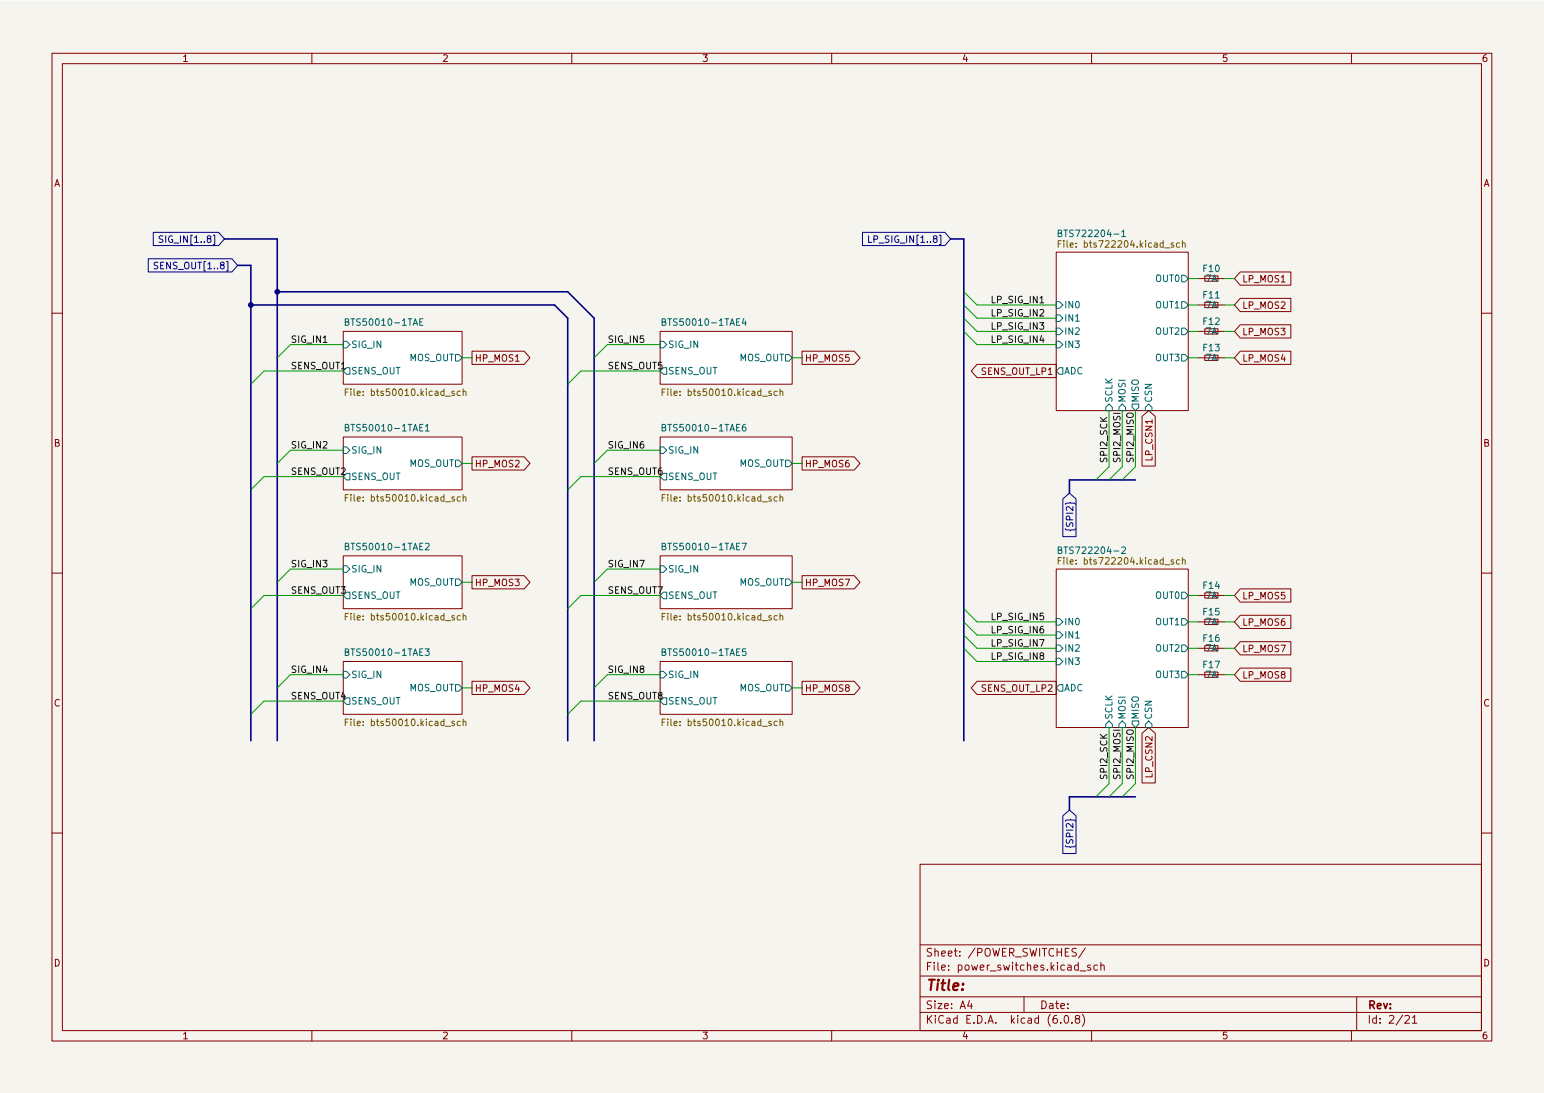
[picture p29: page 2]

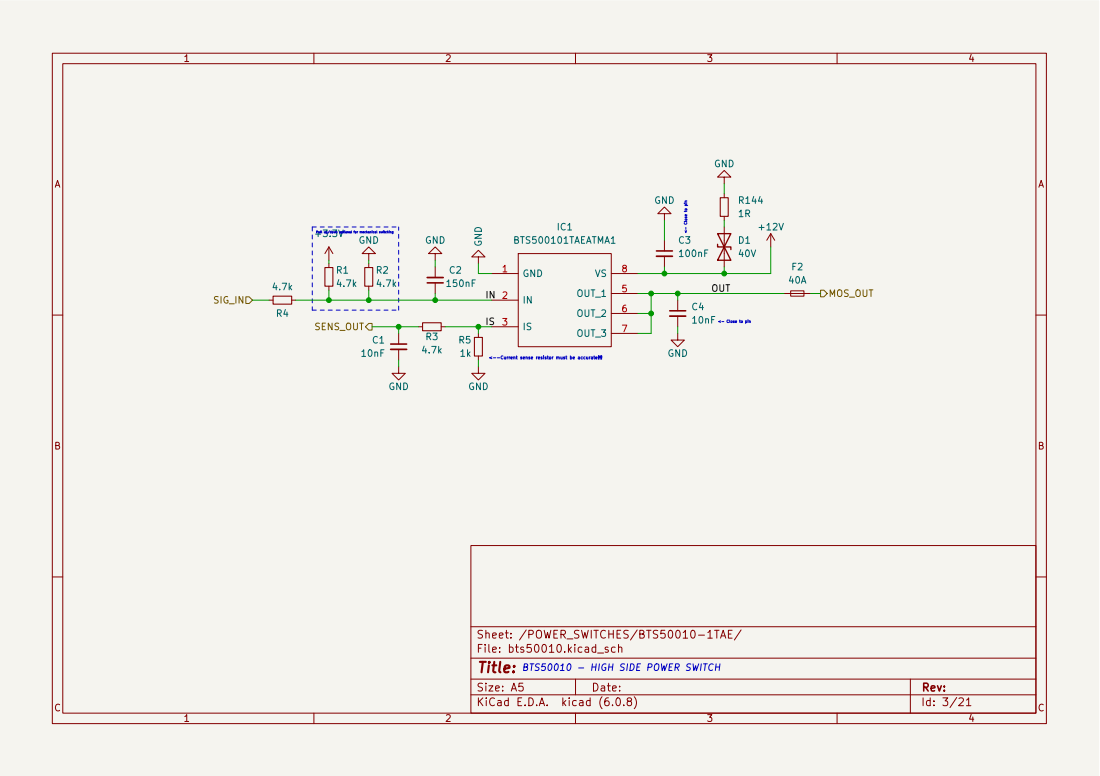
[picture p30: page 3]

<--Current sense resistor must be accurate!!! BTS50010 - HIGH SIDE POWER SWITCH

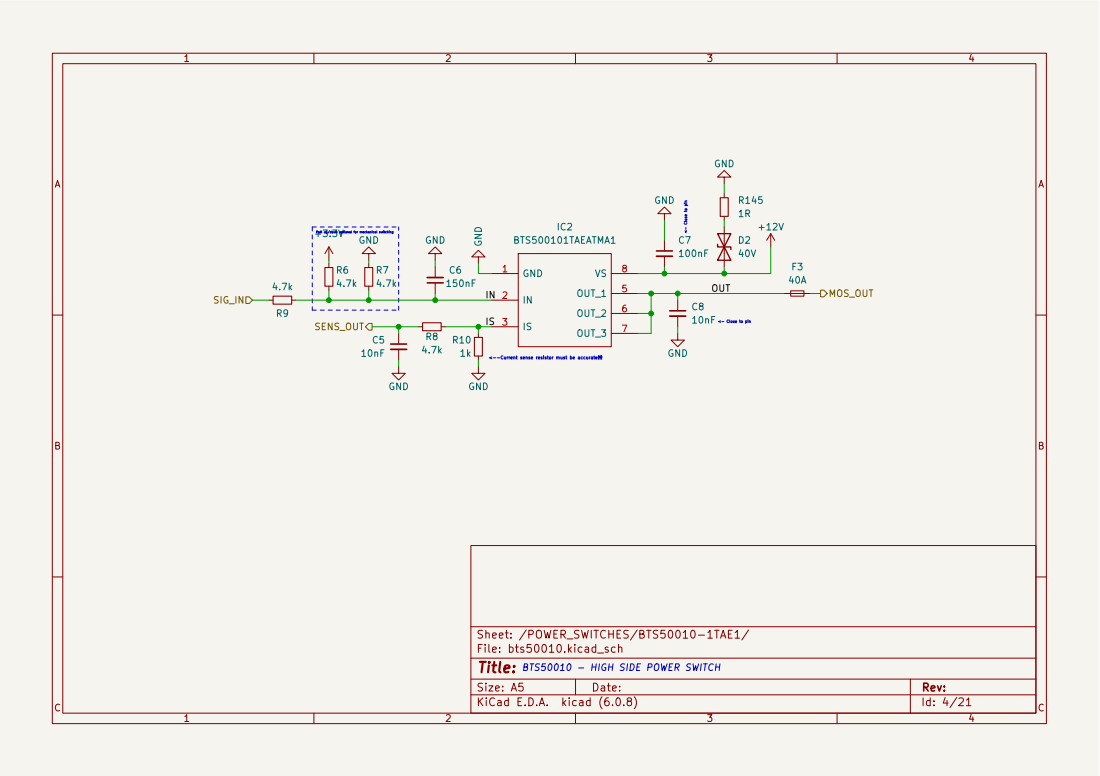
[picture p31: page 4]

<--Current sense resistor must be accurate!!! BTS50010 - HIGH SIDE POWER SWITCH

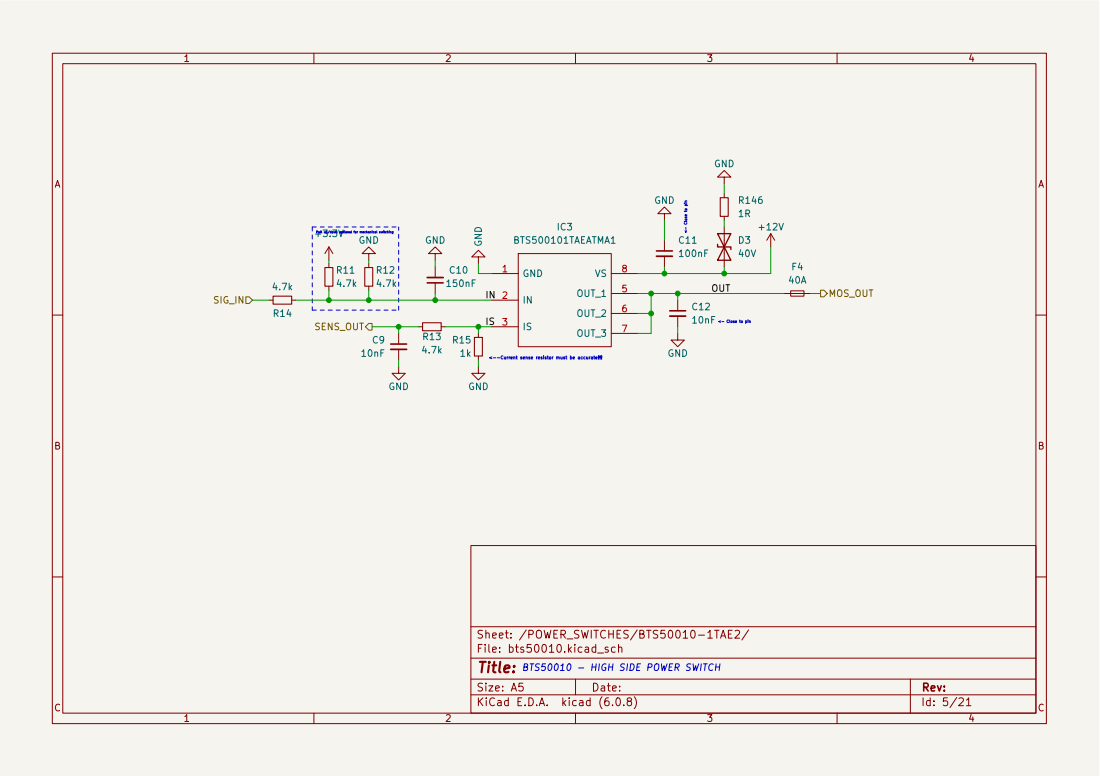
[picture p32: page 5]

<--Current sense resistor must be accurate!!! BTS50010 - HIGH SIDE POWER SWITCH

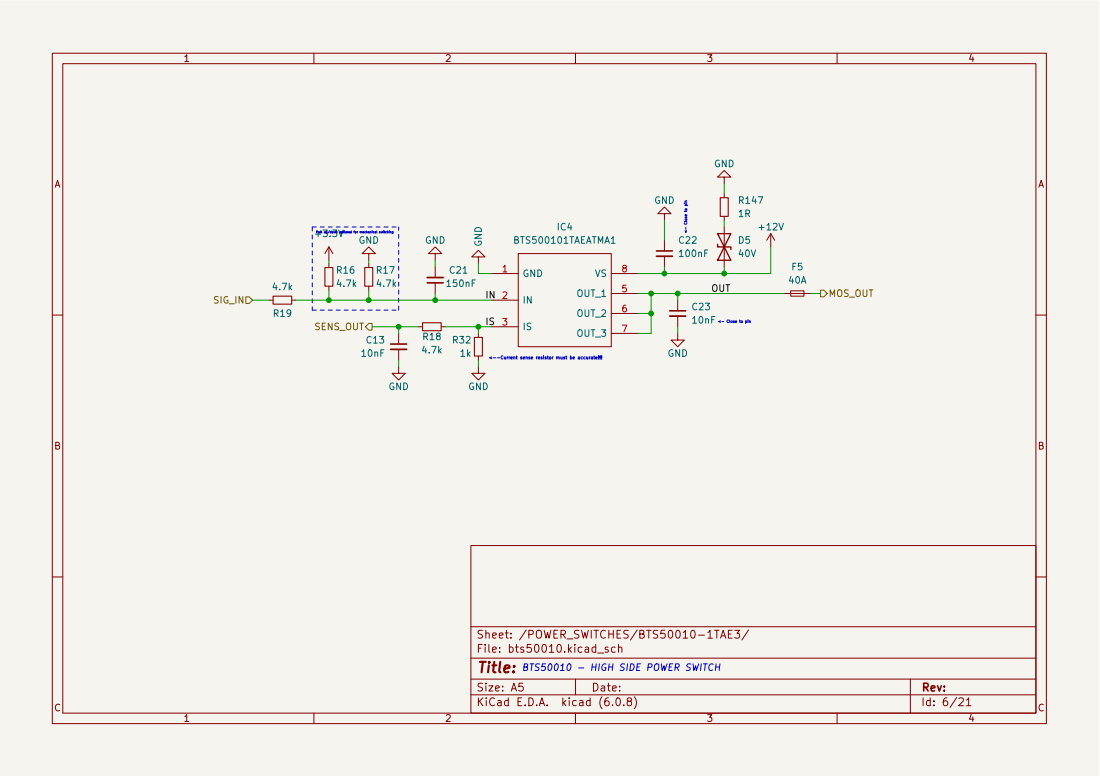
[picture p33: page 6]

<--Current sense resistor must be accurate!!! BTS50010 - HIGH SIDE POWER SWITCH

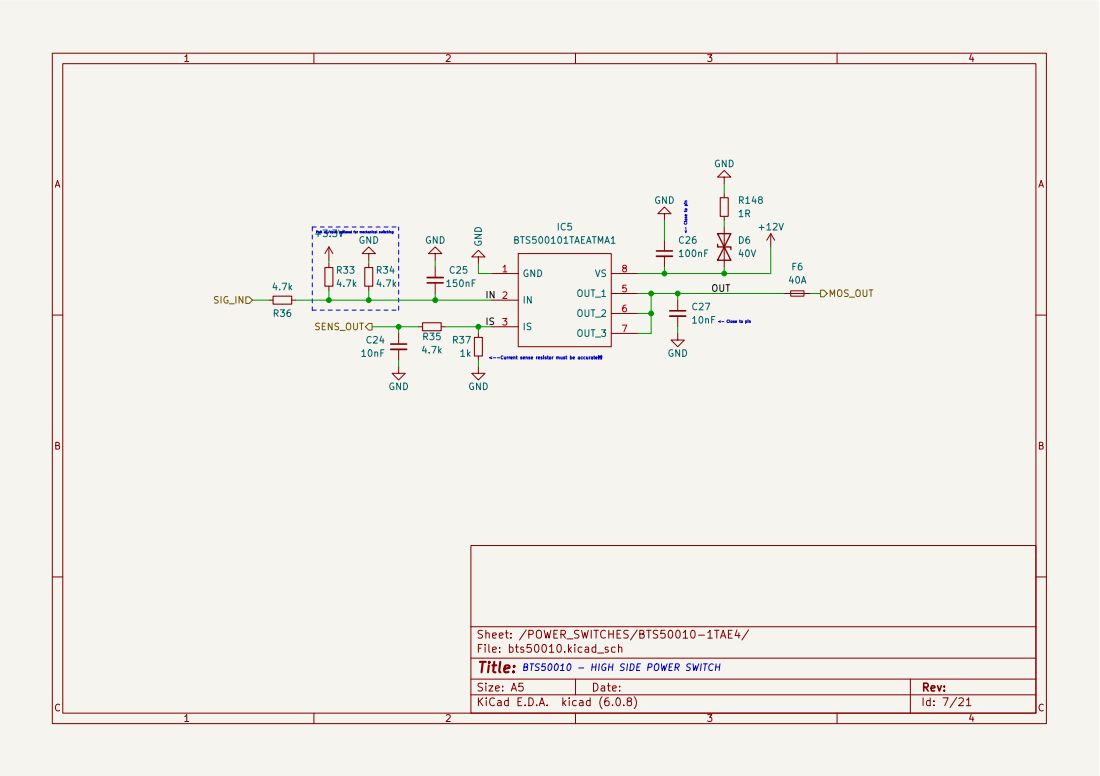
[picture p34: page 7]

<--Current sense resistor must be accurate!!! BTS50010 - HIGH SIDE POWER SWITCH

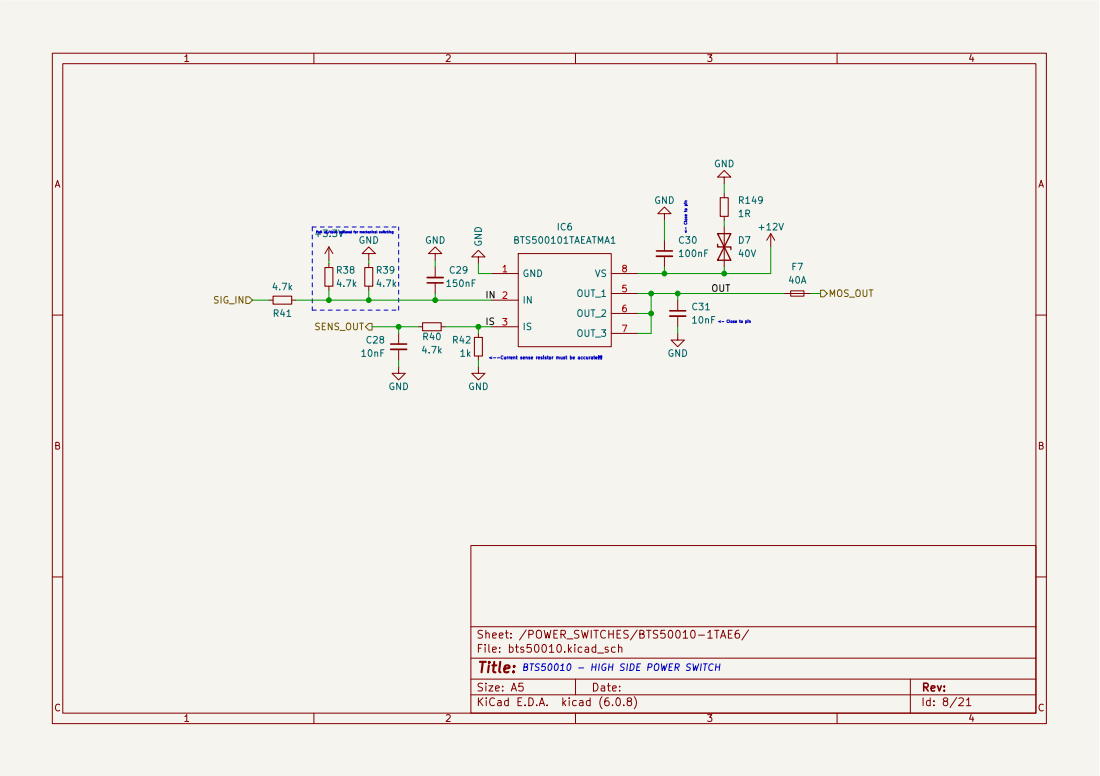
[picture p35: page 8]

<--Current sense resistor must be accurate!!! BTS50010 - HIGH SIDE POWER SWITCH

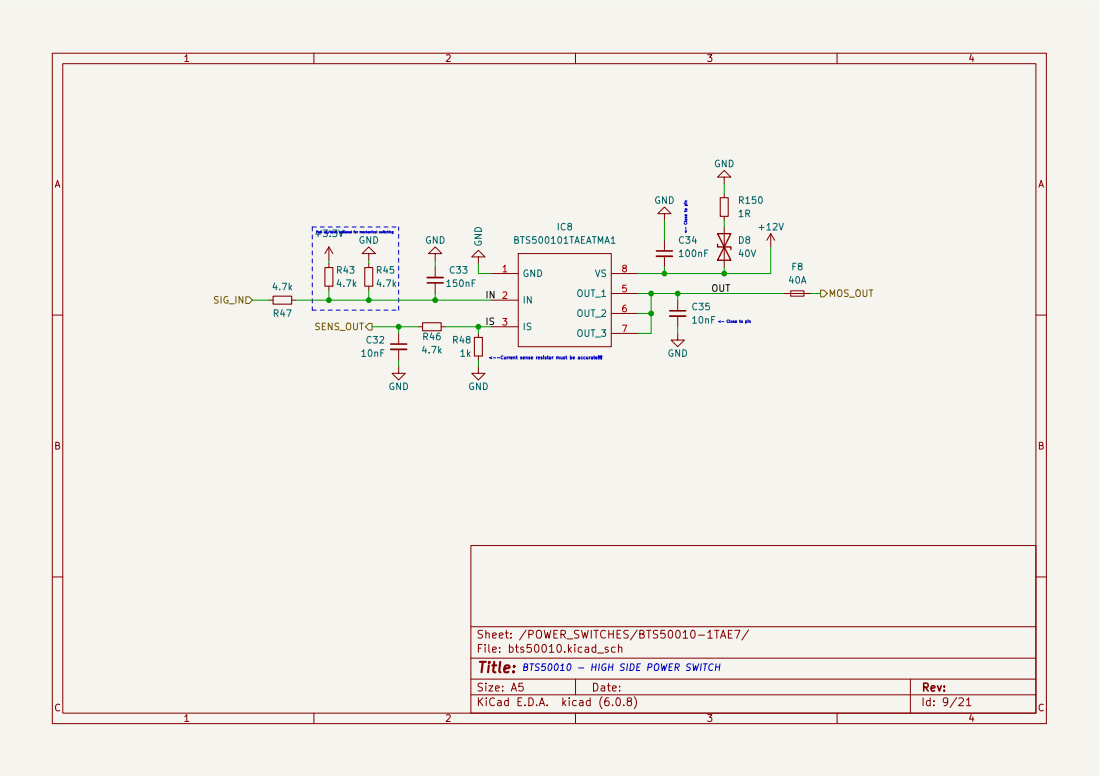
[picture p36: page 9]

<--Current sense resistor must be accurate!!! BTS50010 - HIGH SIDE POWER SWITCH

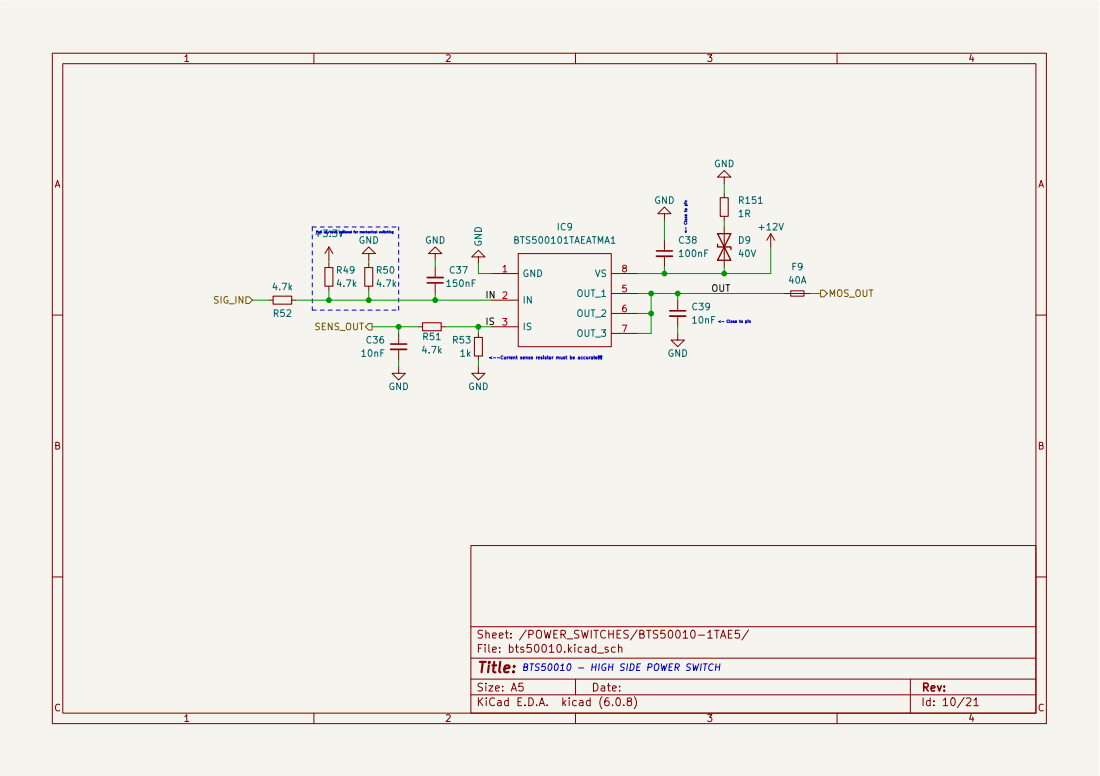
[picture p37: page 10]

<--Current sense resistor must be accurate!!! BTS50010 - HIGH SIDE POWER SWITCH

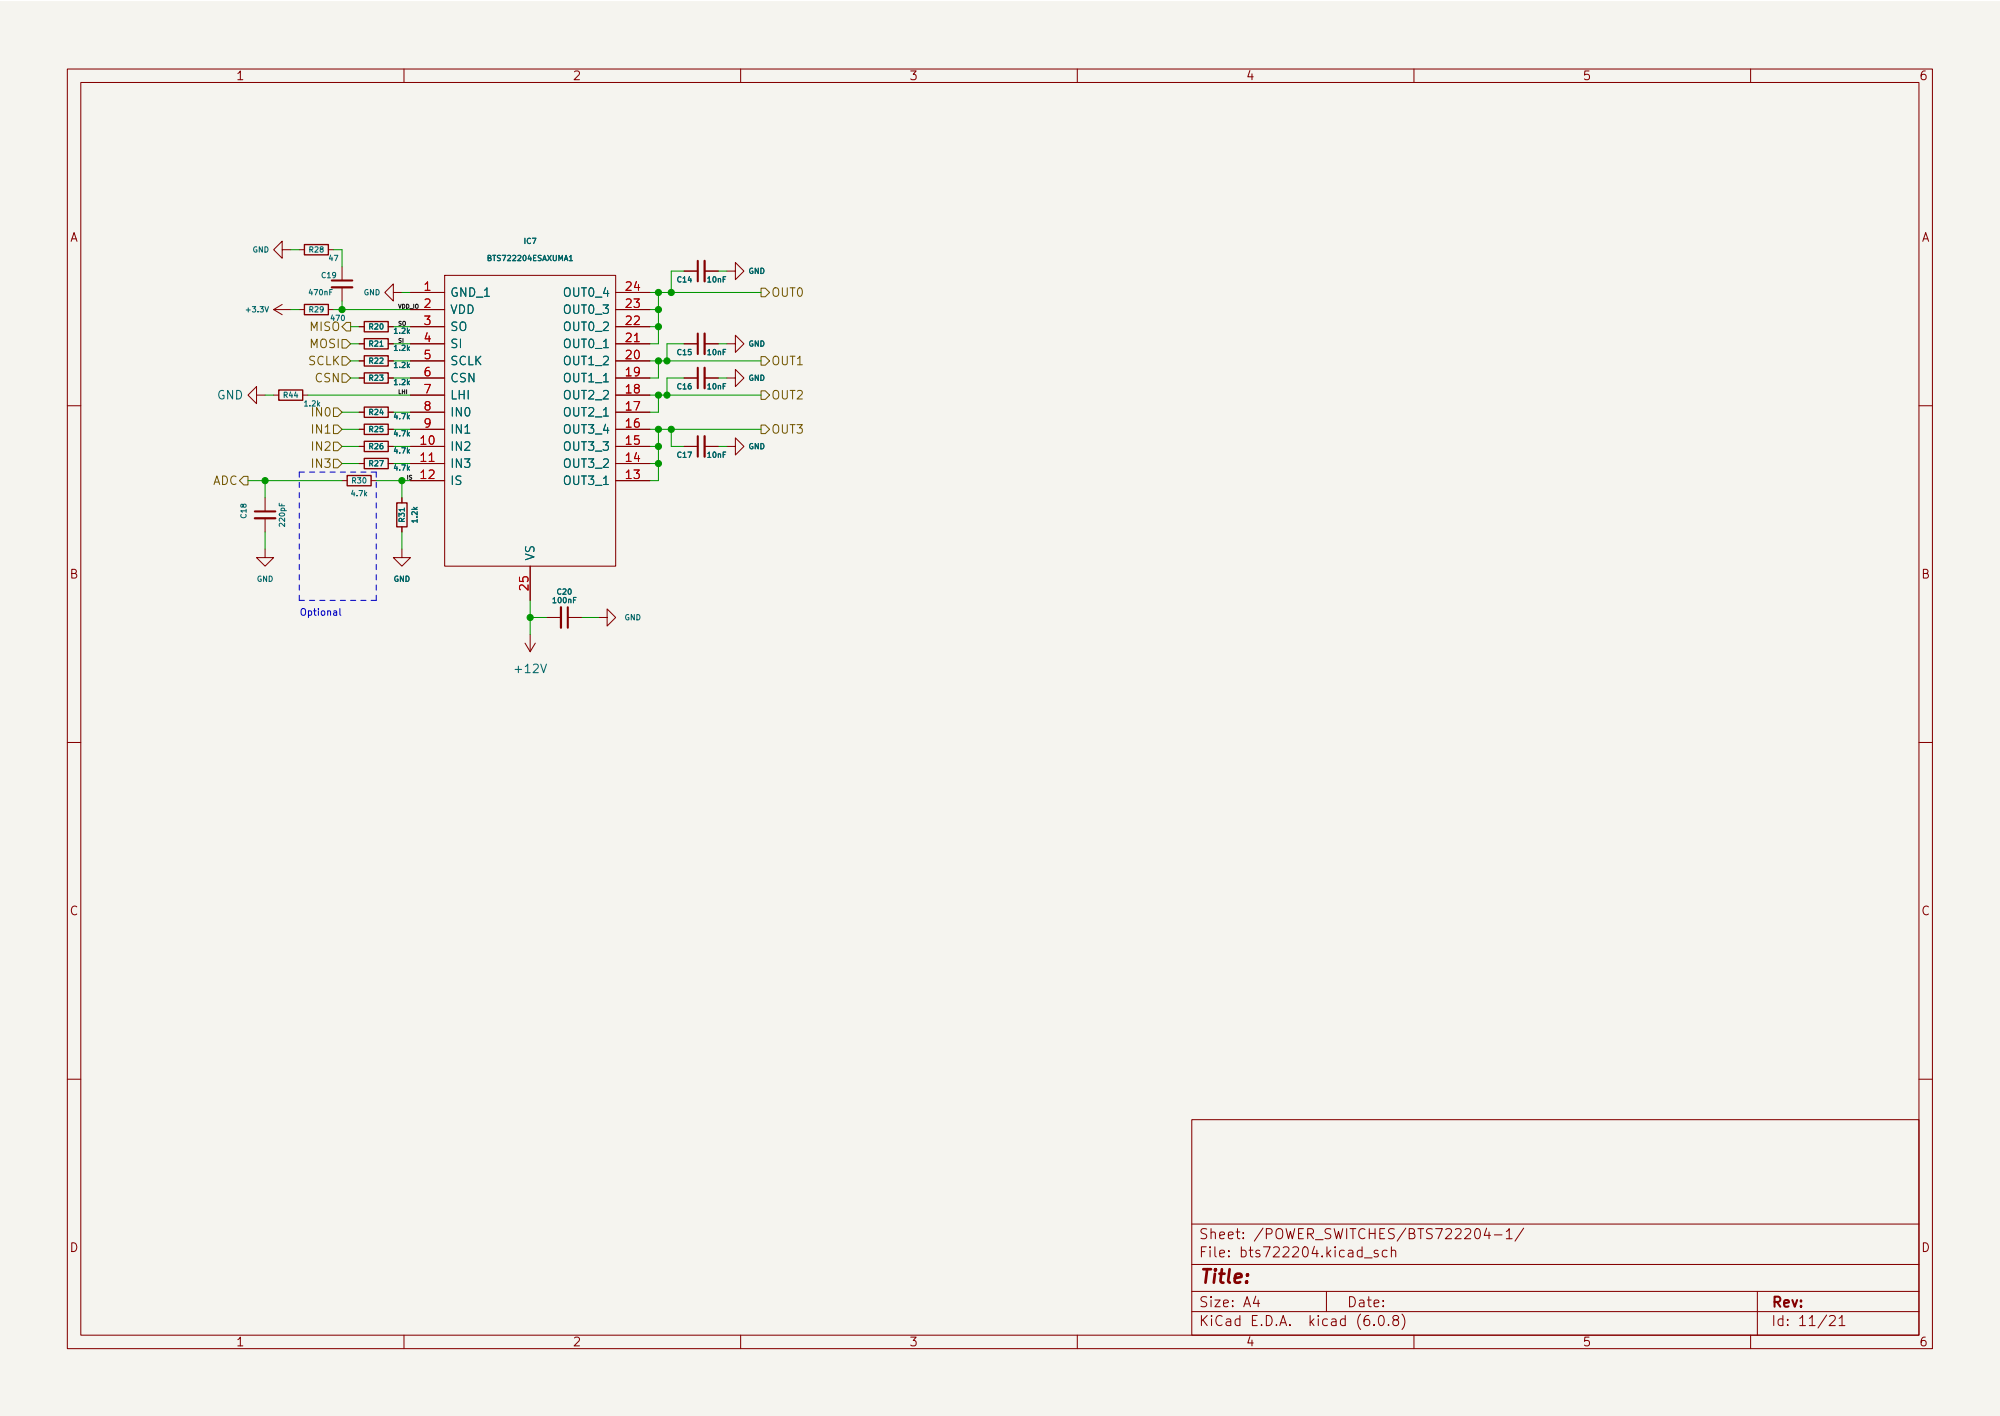
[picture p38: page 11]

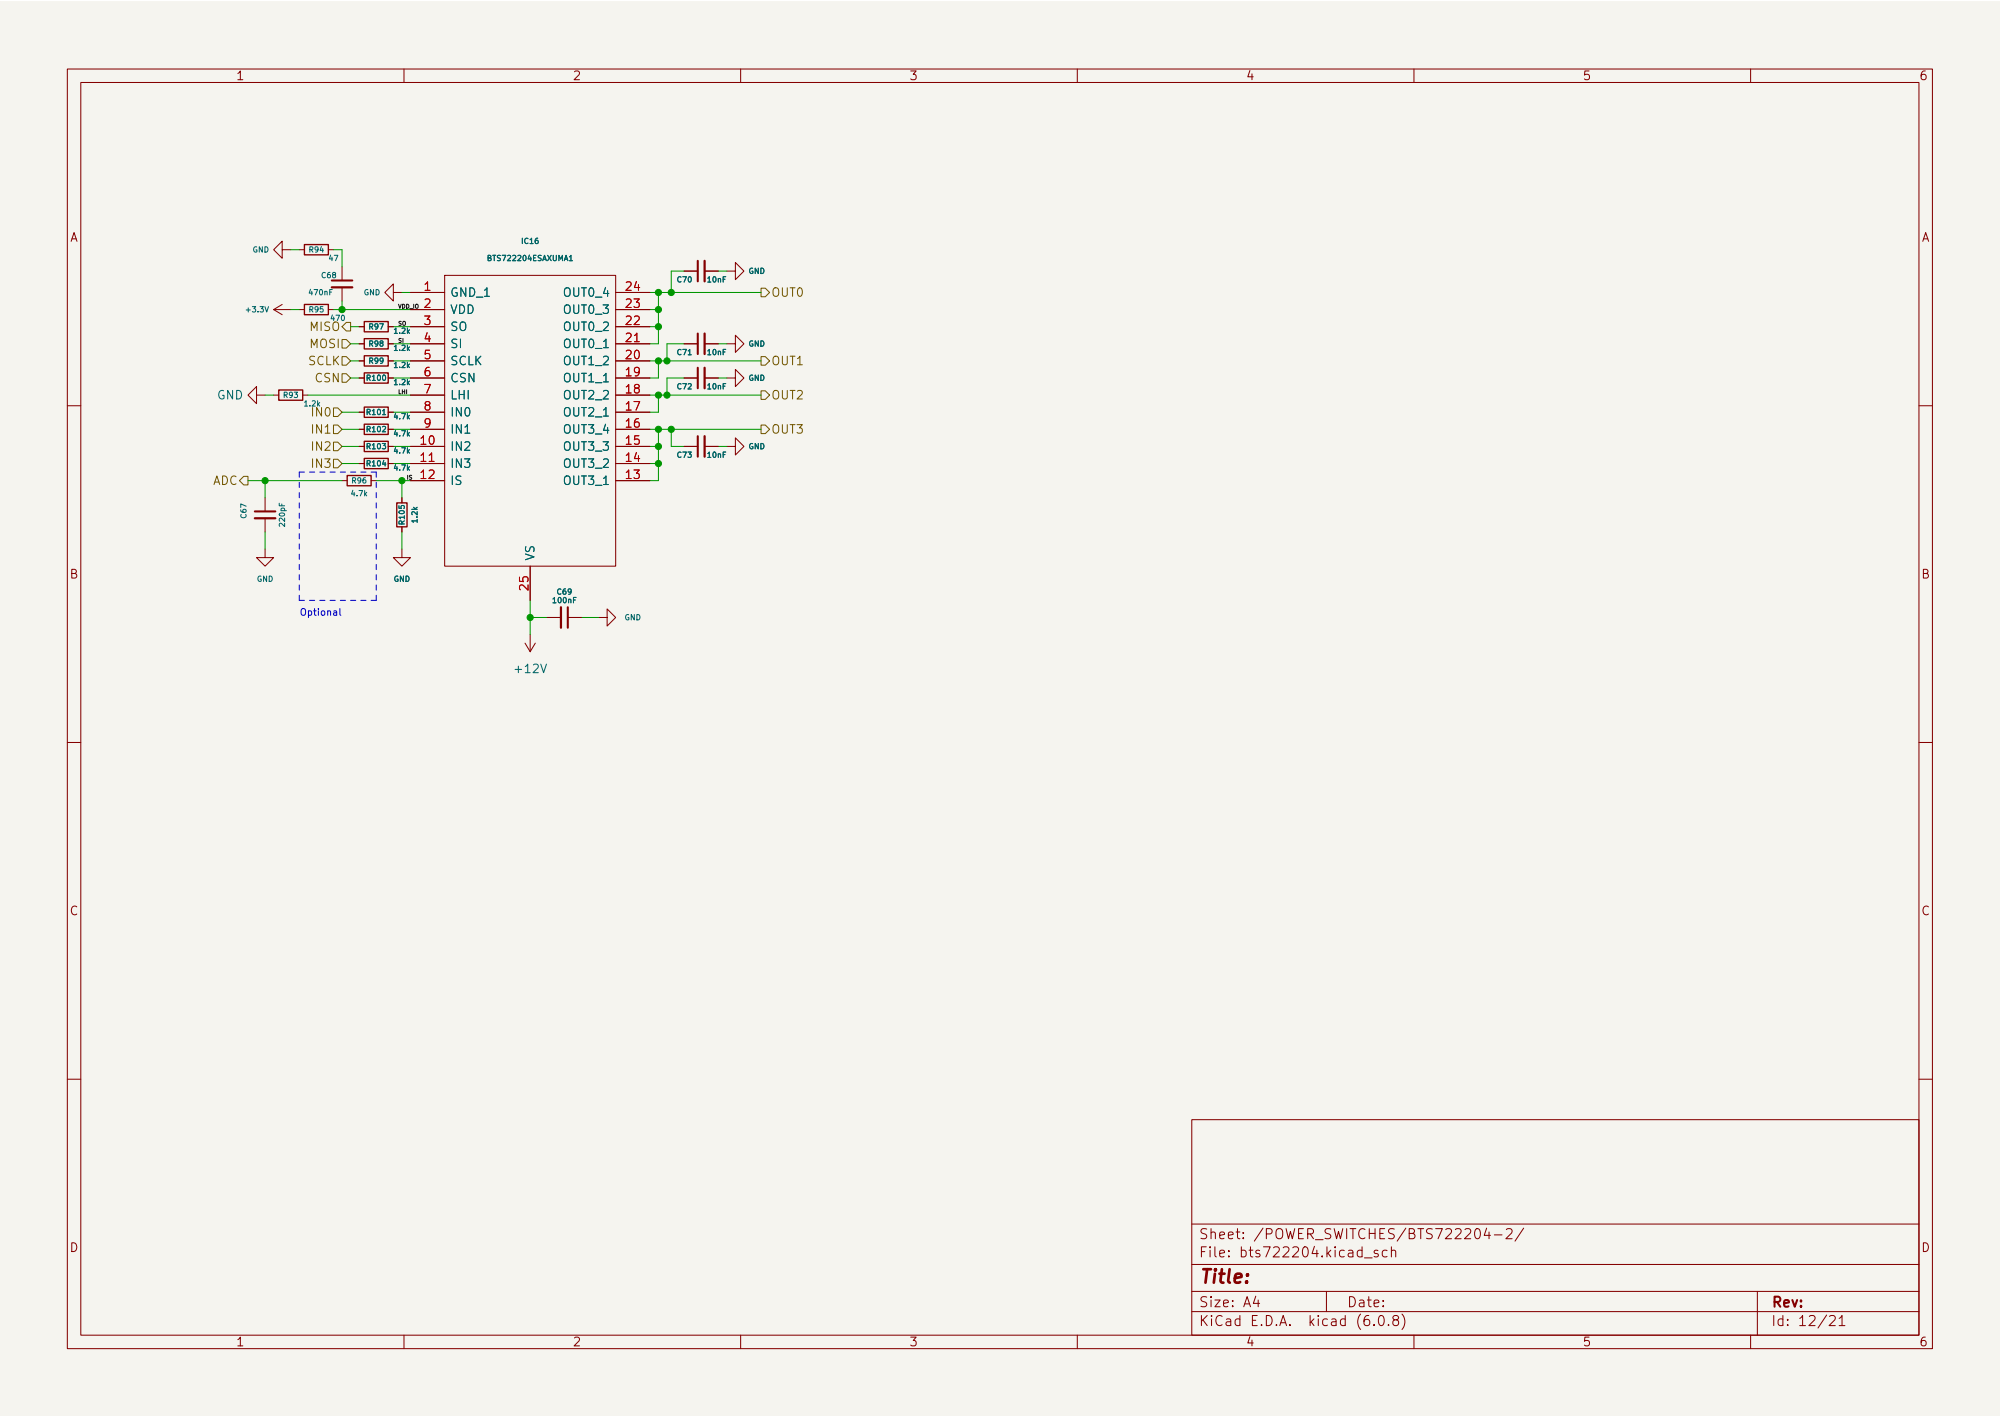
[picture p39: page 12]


IMU_I2C_SA0
File: imu.kicad_sch Sheet: /IMU/ C74



3 RXD 4 SPLIT 5 CANL 6 CANH 7 STBY 8 +5V D27 PESD2CANFD24L-UX K1

3 RXD 4 SPLIT 5 CANL 6 CANH 7 STBY 8 U2MCP2561-E-SN K1

3 RXD 4 SPLIT 5 CANL 6 CANH 7 STBY 8 U3MCP2561-E-SN

3 RXD 4 SPLIT 5 CANL 6 CANH 7 STBY 8



X7R capacitors close to pins LDO

4 BST 5 EN 6 SS 7 FB 8






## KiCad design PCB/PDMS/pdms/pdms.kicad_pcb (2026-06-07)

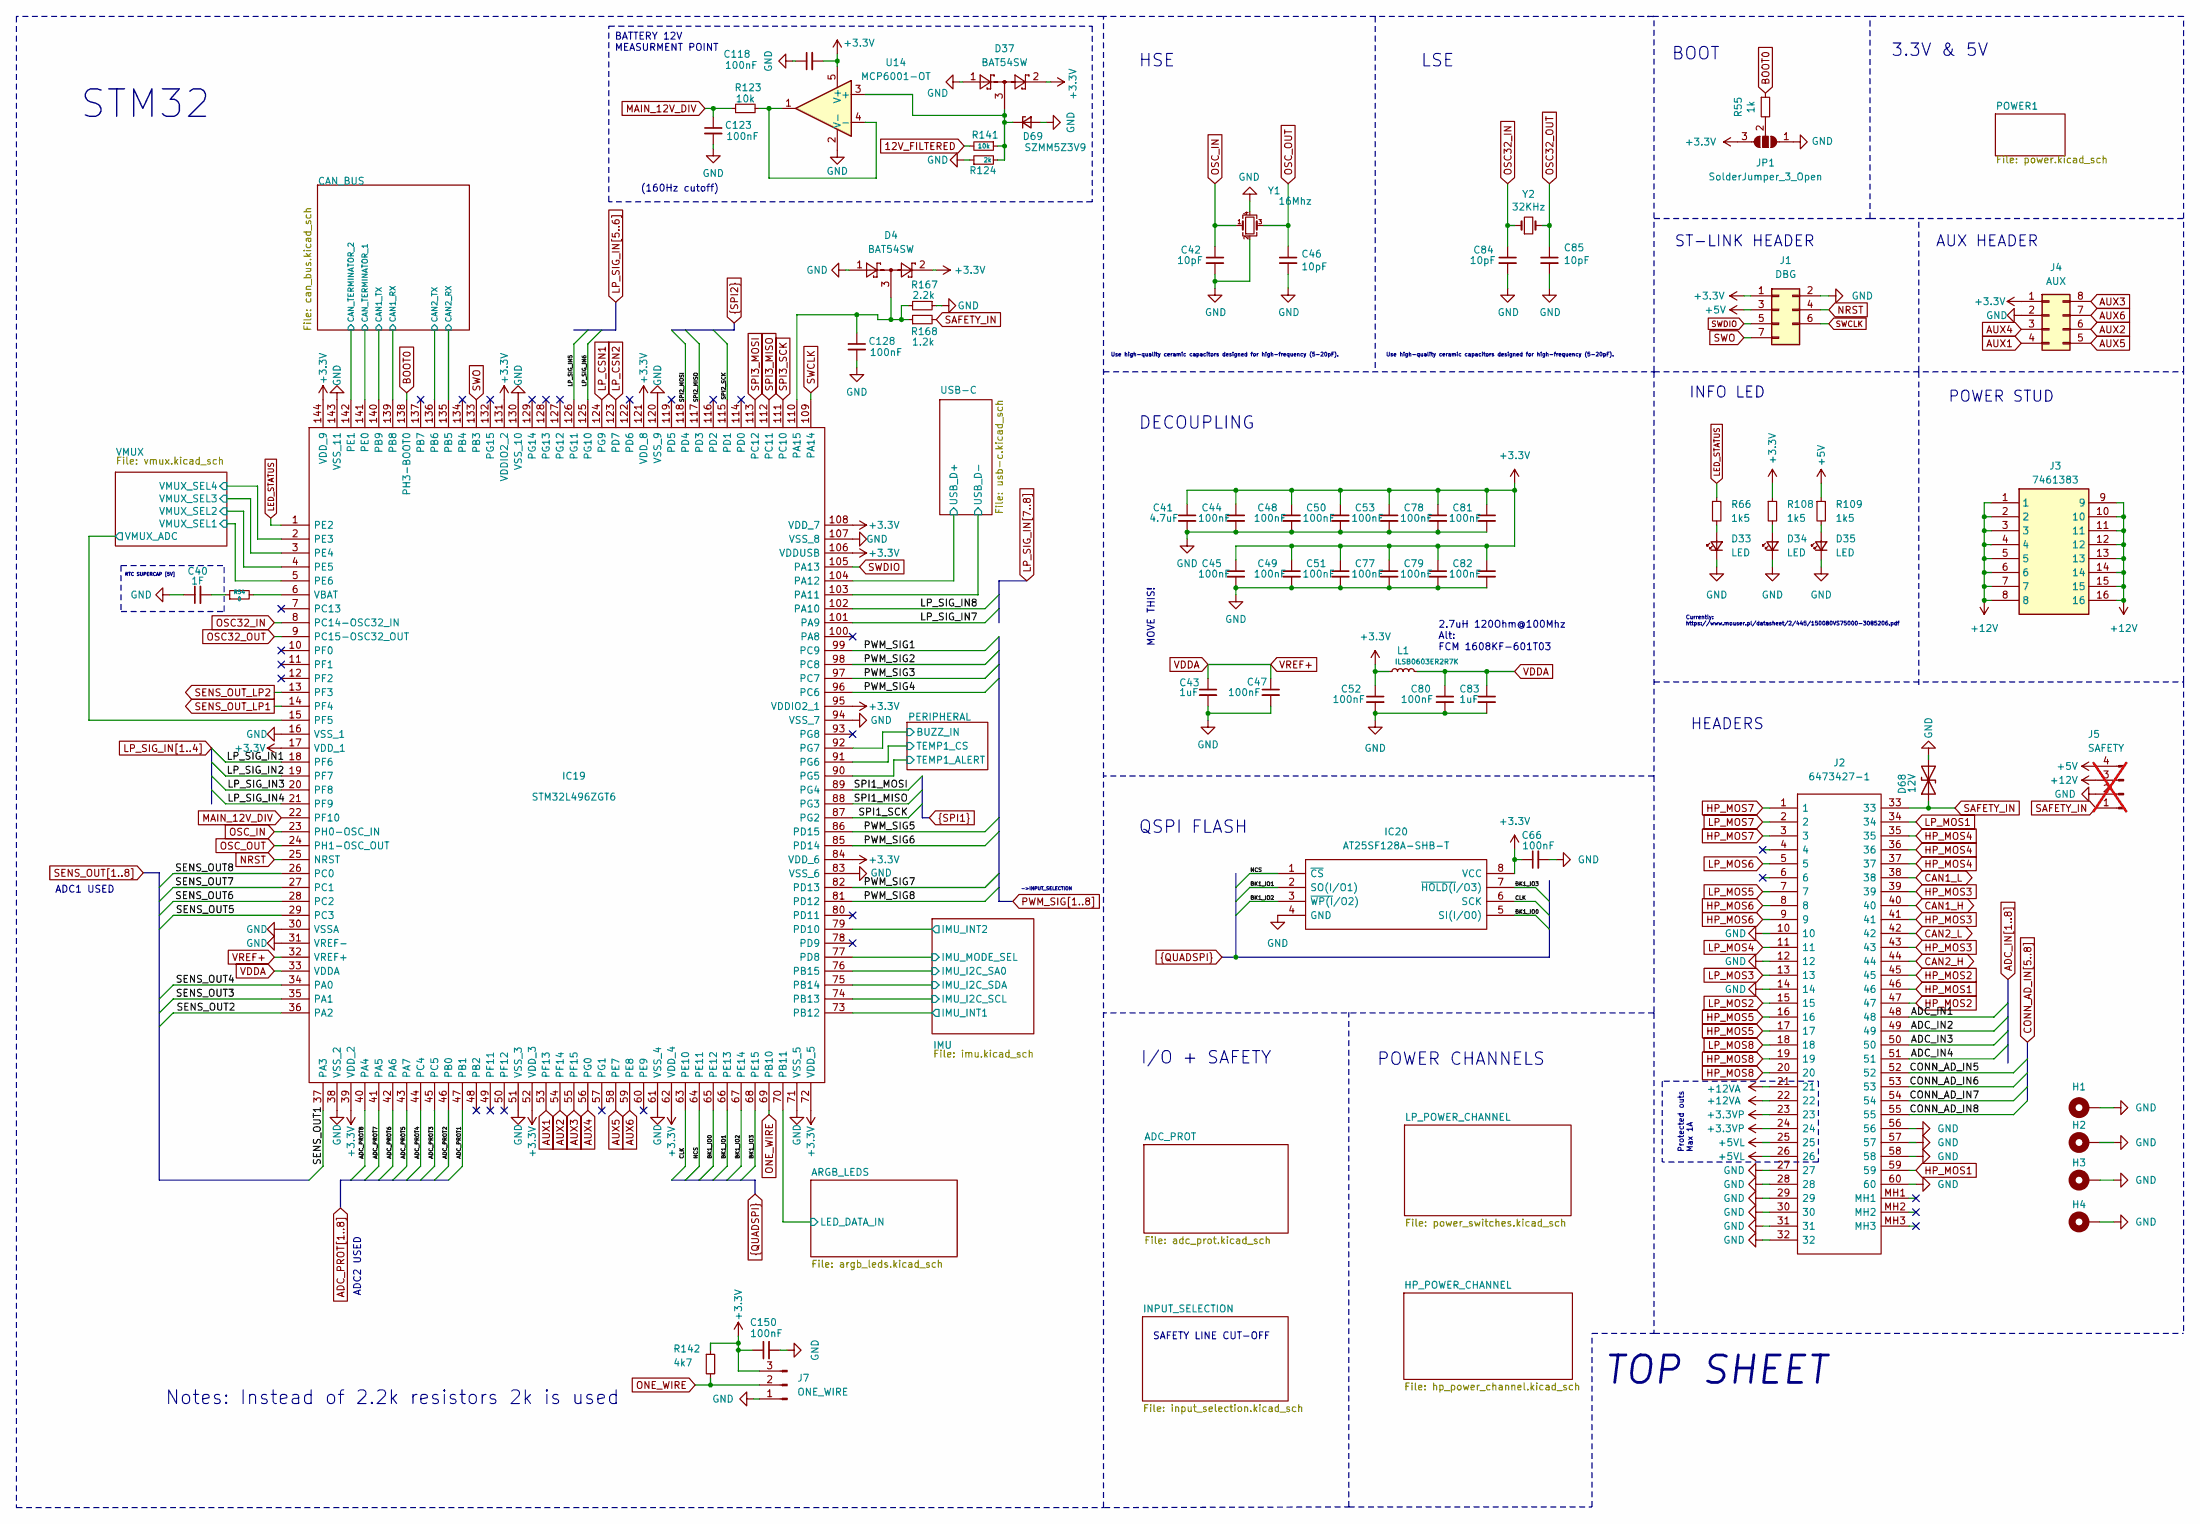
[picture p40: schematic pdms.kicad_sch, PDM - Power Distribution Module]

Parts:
C40: 1F; CAPCP3225X100N
C41: 4.7uF; R_0402_1005Metric
C42, C46: 10pF; R_0402_1005Metric
C43: 1uF; R_0402_1005Metric
C44, C45, C47, C48, C49, C50, C51, C52, C53, C66, C150: 100nF; R_0402_1005Metric
C77, C78, C79, C80, C81, C82, C118, C123, C128: 100nF; C_0402_1005Metric
C83: 1uF; C_0402_1005Metric
C84, C85: 10pF; C_0402_1005Metric
D4, D37: BAT54SW; SOT-323_SC-70
D33: LED; LED_0402_1005Metric
D34, D35: LED; LED_0805_2012Metric
D68: 12V; D_SOD-323
D69: SZMM5Z3V9; D_SOD-523
H1, H2, H3, H4: MountingHole_Pad; MountingHole_3.2mm_M3_Pad_Via
IC19: STM32L496ZGT6; QFP50P2200X2200X160-144N; Manufacturer_Part_Number STM32L496ZGT6; Mouser Part Number 511-STM32L496ZGT6
IC20: AT25SF128A-SHB-T; SOIC127P798X216-8N; Manufacturer_Part_Number AT25SF128A-SHB-T; Mouser Part Number 988-AT25SF128A-SHB-T
J1: DBG; Molex_PicoBlade_53047-0710_1x07_P1.25mm_Vertical
J2: 6473427-1; 64734271; Manufacturer_Part_Number 6473427-1; Mouser Part Number 571-6473427-1
J3: 7461383; Manufacturer_Part_Number 7461383; Mouser Part Number 710-7461383
J4: AUX; PinHeader_2x04_P1.00mm_Vertical_SMD
J5: SAFETY; Molex_PicoBlade_53047-0410_1x04_P1.25mm_Vertical; not fitted
J7: ONE_WIRE; PinHeader_1x03_P2.00mm_Vertical
JP1: SolderJumper_3_Open; SolderJumper-3_P1.3mm_Open_Pad1.0x1.5mm
L1: ILSB0603ER2R7K; L_0603_1608Metric
R54: 0; R_0805_2012Metric
R55: 1k; R_0402_1005Metric
R66, R108, R109: 1k5; R_0402_1005Metric
R123, R141: 10k; R_0402_1005Metric
R124: 2k; R_0402_1005Metric
R142: 4k7; R_0402_1005Metric
R167: 2.2k; R_0402_1005Metric
R168: 1.2k; R_0402_1005Metric
U14: MCP6001-OT; SOT-23-5
Y1: 16Mhz; Crystal_SMD_2016-4Pin_2.0x1.6mm
Y2: 32KHz; Crystal_SMD_3215-2Pin_3.2x1.5mm

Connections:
+3.3VP: J2.23, J2.24; also elsewhere on the board
+5V: J1.3, J5.4, R109.1; also elsewhere on the board
+5VL: J2.25, J2.26; also elsewhere on the board
+12V: J3.1, J3.2, J3.3, J3.4, J3.5, J3.6, J3.7, J3.8, J3.9, J3.10, J3.11, J3.12, J3.13, J3.14, J3.15, J3.16, J5.3; also elsewhere on the board
+12VA: J2.21, J2.22; also elsewhere on the board
/ARGB_LEDS/LED_DATA_IN: IC19.70 (PB11); also elsewhere on the board
/CAN_BUS/CAN1_RX: IC19.139 (PB8); also elsewhere on the board
/CAN_BUS/CAN1_TX: IC19.140 (PB9); also elsewhere on the board
/CAN_BUS/CAN2_RX: IC19.135 (PB5); also elsewhere on the board
/CAN_BUS/CAN2_TX: IC19.136 (PB6); also elsewhere on the board
/CAN_BUS/CAN_TERMINATOR_1: IC19.141 (PE0); also elsewhere on the board
/CAN_BUS/CAN_TERMINATOR_2: IC19.142 (PE1); also elsewhere on the board
/IMU/IMU_I2C_SA0: IC19.76 (PB15); also elsewhere on the board
/IMU/IMU_I2C_SCL: IC19.74 (PB13); also elsewhere on the board
/IMU/IMU_I2C_SDA: IC19.75 (PB14); also elsewhere on the board
/IMU/IMU_INT1: IC19.73 (PB12); also elsewhere on the board
/IMU/IMU_INT2: IC19.79 (PD10); also elsewhere on the board
/IMU/IMU_MODE_SEL: IC19.77 (PD8); also elsewhere on the board
/PERIPHERAL/BUZZ_IN: IC19.92 (PG7); also elsewhere on the board
/PERIPHERAL/TEMP1_ALERT: IC19.90 (PG5); also elsewhere on the board
/PERIPHERAL/TEMP1_CS: IC19.91 (PG6); also elsewhere on the board
/USB-C/USB_D+: IC19.104 (PA12); also elsewhere on the board
/USB-C/USB_D-: IC19.103 (PA11); also elsewhere on the board
/VMUX/VMUX_SEL1: IC19.5 (PE6); also elsewhere on the board
/VMUX/VMUX_SEL2: IC19.4 (PE5); also elsewhere on the board
/VMUX/VMUX_SEL3: IC19.3 (PE4); also elsewhere on the board
/VMUX/VMUX_SEL4: IC19.2 (PE3); also elsewhere on the board
ADC_IN1: J2.48; also elsewhere on the board
ADC_IN2: J2.49; also elsewhere on the board
ADC_IN3: J2.50; also elsewhere on the board
ADC_IN4: J2.51; also elsewhere on the board
ADC_PROT1: IC19.47 (PB1); also elsewhere on the board
ADC_PROT2: IC19.46 (PB0); also elsewhere on the board
ADC_PROT3: IC19.45 (PC5); also elsewhere on the board
ADC_PROT4: IC19.44 (PC4); also elsewhere on the board
ADC_PROT5: IC19.43 (PA7); also elsewhere on the board
ADC_PROT6: IC19.42 (PA6); also elsewhere on the board
ADC_PROT7: IC19.41 (PA5); also elsewhere on the board
ADC_PROT8: IC19.40 (PA4); also elsewhere on the board
AUX1: IC19.53 (PF13), J4.4
AUX2: IC19.54 (PF14), J4.6
AUX3: IC19.55 (PF15), J4.8
AUX4: IC19.56 (PG0), J4.3
AUX5: IC19.58 (PE7), J4.5
AUX6: IC19.59 (PE8), J4.7
BK1_IO0: IC19.65 (PE12), IC20.5 (SI(I/O0))
BK1_IO1: IC19.66 (PE13), IC20.2 (SO(I/O1))
BK1_IO2: IC19.67 (PE14), IC20.3 (~WP(I/O2))
BK1_IO3: IC19.68 (PE15), IC20.7 (~HOLD(I/O3))
BOOT0: IC19.138 (PH3-BOOT0), R55.1
CAN1_H: J2.40; also elsewhere on the board
CAN1_L: J2.38; also elsewhere on the board
CAN2_H: J2.44; also elsewhere on the board
CAN2_L: J2.42; also elsewhere on the board
CLK: IC19.63 (PE10), IC20.6 (SCK)
CONN_AD_IN5: J2.52; also elsewhere on the board
CONN_AD_IN6: J2.53; also elsewhere on the board
CONN_AD_IN7: J2.54; also elsewhere on the board
CONN_AD_IN8: J2.55; also elsewhere on the board
HP_MOS1: J2.46, J2.59; also elsewhere on the board
HP_MOS2: J2.45, J2.47; also elsewhere on the board
HP_MOS3: J2.39, J2.41, J2.43; also elsewhere on the board
HP_MOS4: J2.35, J2.36, J2.37; also elsewhere on the board
HP_MOS5: J2.16, J2.17; also elsewhere on the board
HP_MOS6: J2.8, J2.9; also elsewhere on the board
HP_MOS7: J2.1, J2.3; also elsewhere on the board
HP_MOS8: J2.19, J2.20; also elsewhere on the board
LED_STATUS: IC19.1 (PE2), R66.1
LP_CSN1: IC19.124 (PG9); also elsewhere on the board
LP_CSN2: IC19.123 (PD7); also elsewhere on the board
LP_MOS1: J2.34; also elsewhere on the board
LP_MOS2: J2.15; also elsewhere on the board
LP_MOS3: J2.13; also elsewhere on the board
LP_MOS4: J2.11; also elsewhere on the board
LP_MOS5: J2.7; also elsewhere on the board
LP_MOS6: J2.5; also elsewhere on the board
LP_MOS7: J2.2; also elsewhere on the board
LP_MOS8: J2.18; also elsewhere on the board
LP_SIG_IN1: IC19.18 (PF6); also elsewhere on the board
LP_SIG_IN2: IC19.19 (PF7); also elsewhere on the board
LP_SIG_IN3: IC19.20 (PF8); also elsewhere on the board
LP_SIG_IN4: IC19.21 (PF9); also elsewhere on the board
LP_SIG_IN5: IC19.126 (PG11); also elsewhere on the board
LP_SIG_IN6: IC19.125 (PG10); also elsewhere on the board
LP_SIG_IN7: IC19.101 (PA9); also elsewhere on the board
LP_SIG_IN8: IC19.102 (PA10); also elsewhere on the board
NCS: IC19.64 (PE11), IC20.1 (~CS)
NRST: IC19.25 (NRST), J1.4
unnamed: C40.2, R54.1
unnamed: D33.2 (A), R66.2
unnamed: D34.2 (A), R108.2
unnamed: D35.2 (A), R109.2
unnamed: C128.1, D4.3, IC19.110 (PA15), R167.2, R168.1
unnamed: IC19.6 (VBAT), R54.2
unnamed: JP1.2 (C), R55.2
ONE_WIRE: IC19.69 (PB10), J7.2, R142.2
OSC32_IN: C84.1, IC19.8 (PC14-OSC32_IN), Y2.1
OSC32_OUT: C85.1, IC19.9 (PC15-OSC32_OUT), Y2.2
OSC_IN: C42.1, IC19.23 (PH0-OSC_IN), Y1.1
OSC_OUT: C46.1, IC19.24 (PH1-OSC_OUT), Y1.3
PWM_SIG1: IC19.99 (PC9); also elsewhere on the board
PWM_SIG2: IC19.98 (PC8); also elsewhere on the board
PWM_SIG3: IC19.97 (PC7); also elsewhere on the board
PWM_SIG4: IC19.96 (PC6); also elsewhere on the board
PWM_SIG5: IC19.86 (PD15); also elsewhere on the board
PWM_SIG6: IC19.85 (PD14); also elsewhere on the board
PWM_SIG7: IC19.82 (PD13); also elsewhere on the board
PWM_SIG8: IC19.81 (PD12); also elsewhere on the board
SAFETY_IN: D68.1 (A1), J2.33, J5.1, R168.2; also elsewhere on the board
SENS_OUT1: IC19.37 (PA3); also elsewhere on the board
SENS_OUT2: IC19.36 (PA2); also elsewhere on the board
SENS_OUT3: IC19.35 (PA1); also elsewhere on the board
SENS_OUT4: IC19.34 (PA0); also elsewhere on the board
SENS_OUT5: IC19.29 (PC3); also elsewhere on the board
SENS_OUT6: IC19.28 (PC2); also elsewhere on the board
SENS_OUT7: IC19.27 (PC1); also elsewhere on the board
SENS_OUT8: IC19.26 (PC0); also elsewhere on the board
SENS_OUT_LP1: IC19.14 (PF4); also elsewhere on the board
SENS_OUT_LP2: IC19.13 (PF3); also elsewhere on the board
SPI1_MISO: IC19.88 (PG3); also elsewhere on the board
SPI1_MOSI: IC19.89 (PG4); also elsewhere on the board
SPI1_SCK: IC19.87 (PG2); also elsewhere on the board
SPI2_MISO: IC19.117 (PD3); also elsewhere on the board
SPI2_MOSI: IC19.118 (PD4); also elsewhere on the board
SPI2_SCK: IC19.115 (PD1); also elsewhere on the board
SPI3_MISO: IC19.112 (PC11)
SPI3_MOSI: IC19.113 (PC12)
SPI3_SCK: IC19.111 (PC10)
SWCLK: IC19.109 (PA14), J1.6; also elsewhere on the board
SWDIO: IC19.105 (PA13), J1.5; also elsewhere on the board
SWO: IC19.133 (PB3), J1.7

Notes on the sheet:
BATTERY 12V MEASURMENT POINT
POWER STUD
BOOT
AUX HEADER
HSE
MOVE THIS!
Notes: Instead of 2.2k resistors 2k is used
INFO LED
STM32
DECOUPLING
POWER CHANNELS
(160Hz cutoff)
->INPUT_SELECTION
2.7uH 120Ohm@100Mhz Alt: FCM 1608KF-601T03
Use high-quality ceramic capacitors designed for high-frequency (5-20pF).
QSPI FLASH
Protected outs Max 1A
TOP SHEET
RTC SUPERCAP [5V]
HEADERS
ST-LINK HEADER
LSE
I/O + SAFETY
SAFETY LINE CUT-OFF
Currently: https://www.mouser.pl/datasheet/2/445/150080VS75000-3085206.pdf
ADC2 USED
ADC1 USED
3.3V & 5V

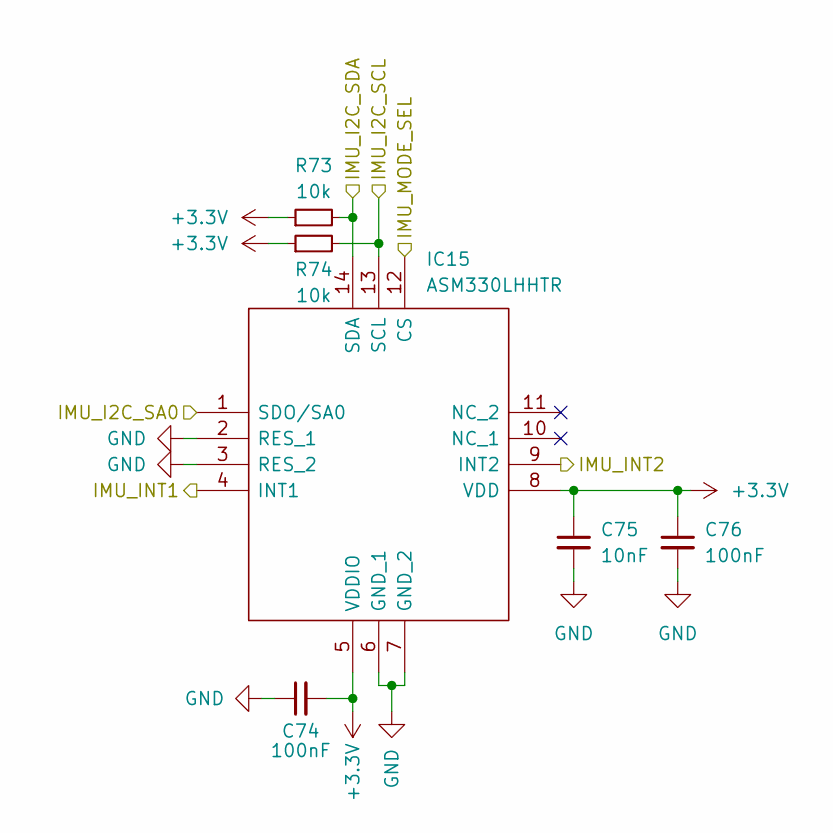
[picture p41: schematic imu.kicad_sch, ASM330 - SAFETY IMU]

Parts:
C74, C76: 100nF; C_0402_1005Metric
C75: 10nF; C_0402_1005Metric
IC15: ASM330LHHTR; LGA-14_2.5X3X0.86_; Manufacturer_Part_Number ASM330LHHTR; Mouser Part Number 511-ASM330LHHTR
R73, R74: 10k; R_0402_1005Metric

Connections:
/IMU/IMU_I2C_SA0: IC15.1 (SDO/SA0); also elsewhere on the board
/IMU/IMU_I2C_SCL: IC15.13 (SCL), R74.2; also elsewhere on the board
/IMU/IMU_I2C_SDA: IC15.14 (SDA), R73.2; also elsewhere on the board
/IMU/IMU_INT1: IC15.4 (INT1); also elsewhere on the board
/IMU/IMU_INT2: IC15.9 (INT2); also elsewhere on the board
/IMU/IMU_MODE_SEL: IC15.12 (CS); also elsewhere on the board

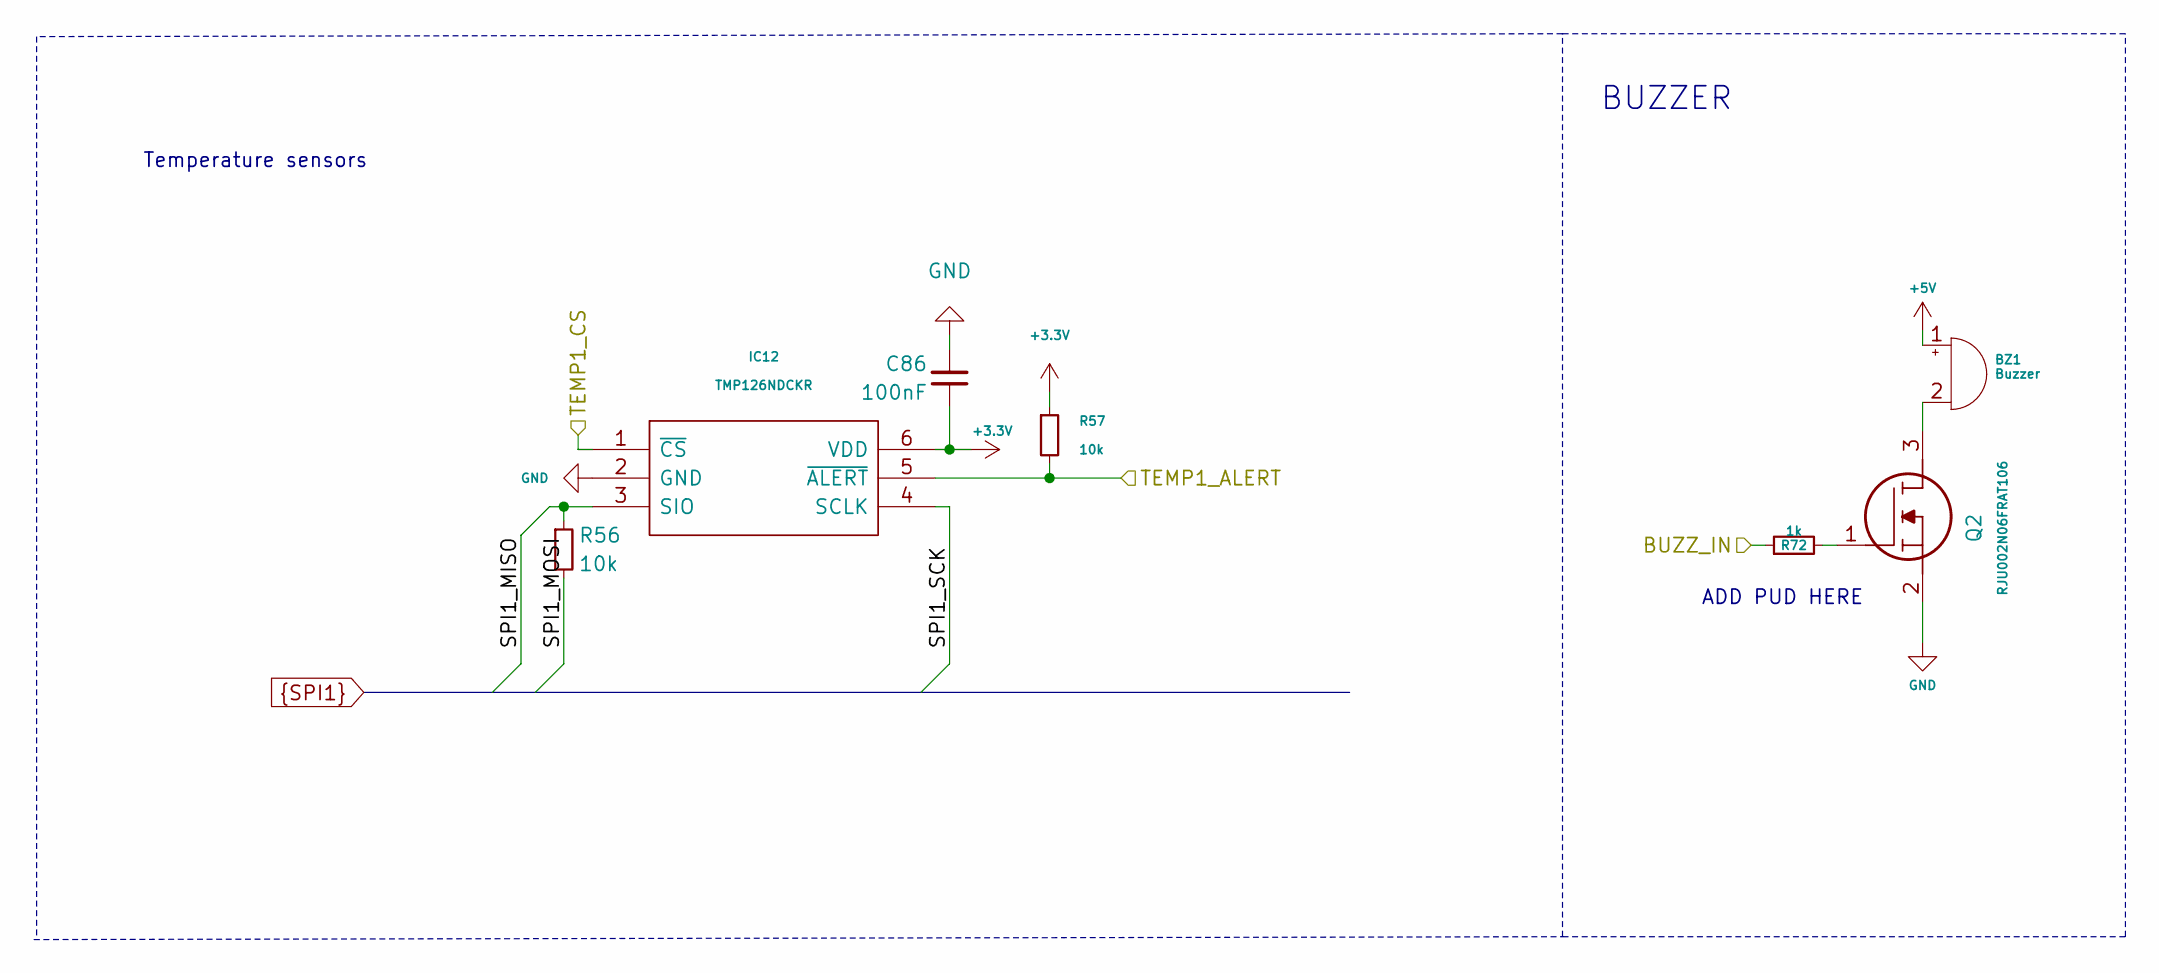
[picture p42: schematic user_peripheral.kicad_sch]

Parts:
BZ1: Buzzer; Buzzer_12x9.5RM7.6
C86: 100nF; C_0402_1005Metric
IC12: TMP126NDCKR; SOT65P210X110-6N; Manufacturer_Part_Number TMP126NDCKR; Mouser Part Number 595-TMP126NDCKR
Q2: RJU002N06FRAT106; SOT65P210X110-3N; Manufacturer_Part_Number RJU002N06FRAT106; Mouser Part Number 755-RJU002N06FRAT106
R56, R57: 10k; R_0402_1005Metric
R72: 1k; R_0402_1005Metric

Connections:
+5V: BZ1.1 (-); also elsewhere on the board
/PERIPHERAL/BUZZ_IN: R72.1; also elsewhere on the board
/PERIPHERAL/TEMP1_ALERT: IC12.5 (~ALERT), R57.2; also elsewhere on the board
/PERIPHERAL/TEMP1_CS: IC12.1 (~CS); also elsewhere on the board
unnamed: BZ1.2 (+), Q2.3
unnamed: Q2.1, R72.2
SPI1_MISO: IC12.3 (SIO), R56.1; also elsewhere on the board
SPI1_MOSI: R56.2; also elsewhere on the board
SPI1_SCK: IC12.4 (SCLK); also elsewhere on the board

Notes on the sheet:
BUZZER
ADD PUD HERE
Temperature sensors

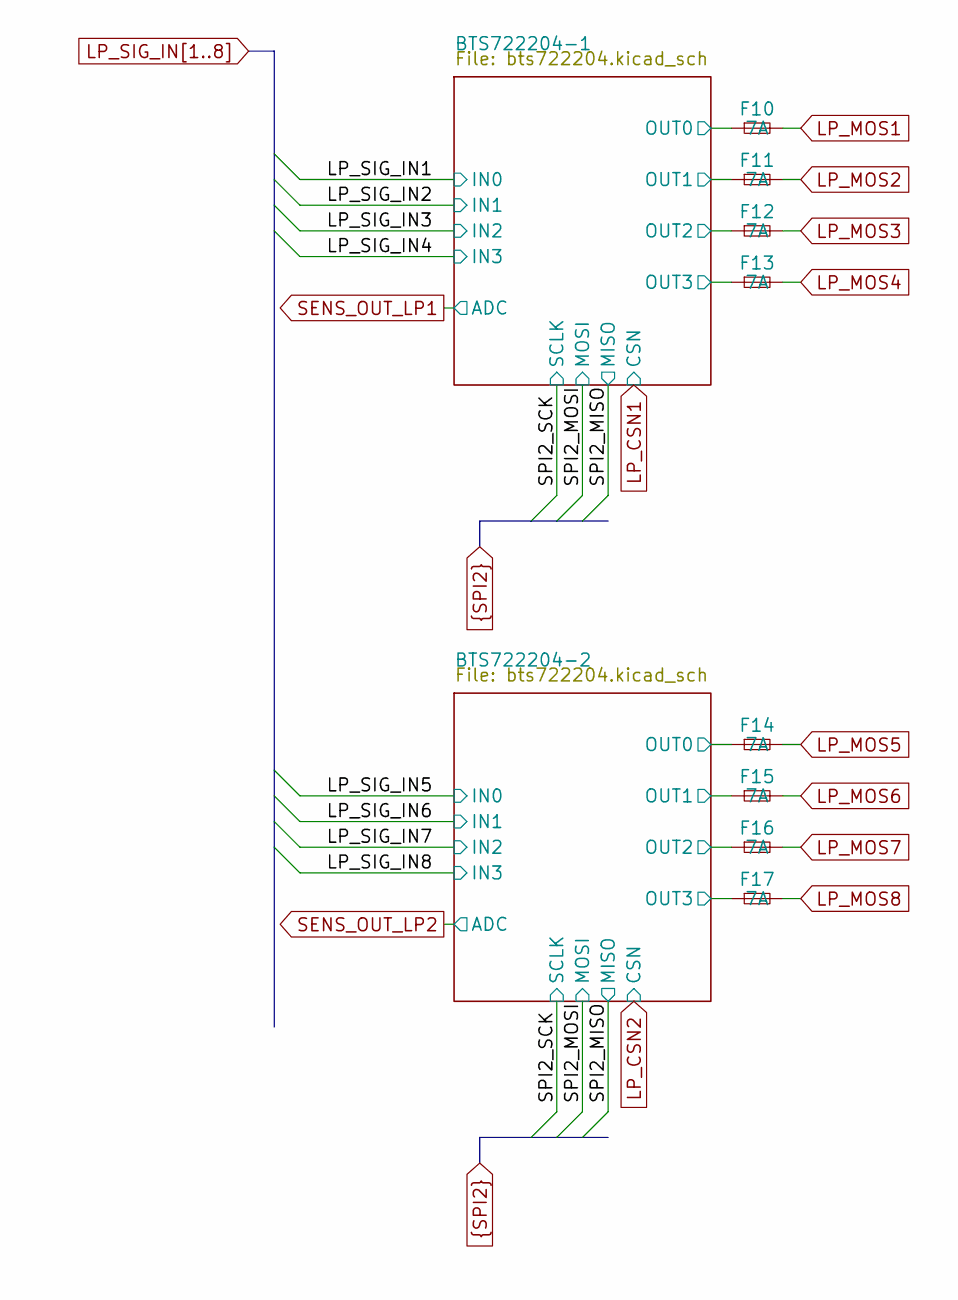
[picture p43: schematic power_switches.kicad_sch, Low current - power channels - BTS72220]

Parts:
F10, F11, F12, F13, F14, F15, F16, F17: 7A; Fuse_1206_3216Metric

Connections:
/LP_POWER_CHANNEL/BTS722204-1/OUT0: F10.1; also elsewhere on the board
/LP_POWER_CHANNEL/BTS722204-1/OUT1: F11.1; also elsewhere on the board
/LP_POWER_CHANNEL/BTS722204-1/OUT2: F12.1; also elsewhere on the board
/LP_POWER_CHANNEL/BTS722204-1/OUT3: F13.1; also elsewhere on the board
/LP_POWER_CHANNEL/BTS722204-2/OUT0: F14.1; also elsewhere on the board
/LP_POWER_CHANNEL/BTS722204-2/OUT1: F15.1; also elsewhere on the board
/LP_POWER_CHANNEL/BTS722204-2/OUT2: F16.1; also elsewhere on the board
/LP_POWER_CHANNEL/BTS722204-2/OUT3: F17.1; also elsewhere on the board
LP_MOS1: F10.2; also elsewhere on the board
LP_MOS2: F11.2; also elsewhere on the board
LP_MOS3: F12.2; also elsewhere on the board
LP_MOS4: F13.2; also elsewhere on the board
LP_MOS5: F14.2; also elsewhere on the board
LP_MOS6: F15.2; also elsewhere on the board
LP_MOS7: F16.2; also elsewhere on the board
LP_MOS8: F17.2; also elsewhere on the board

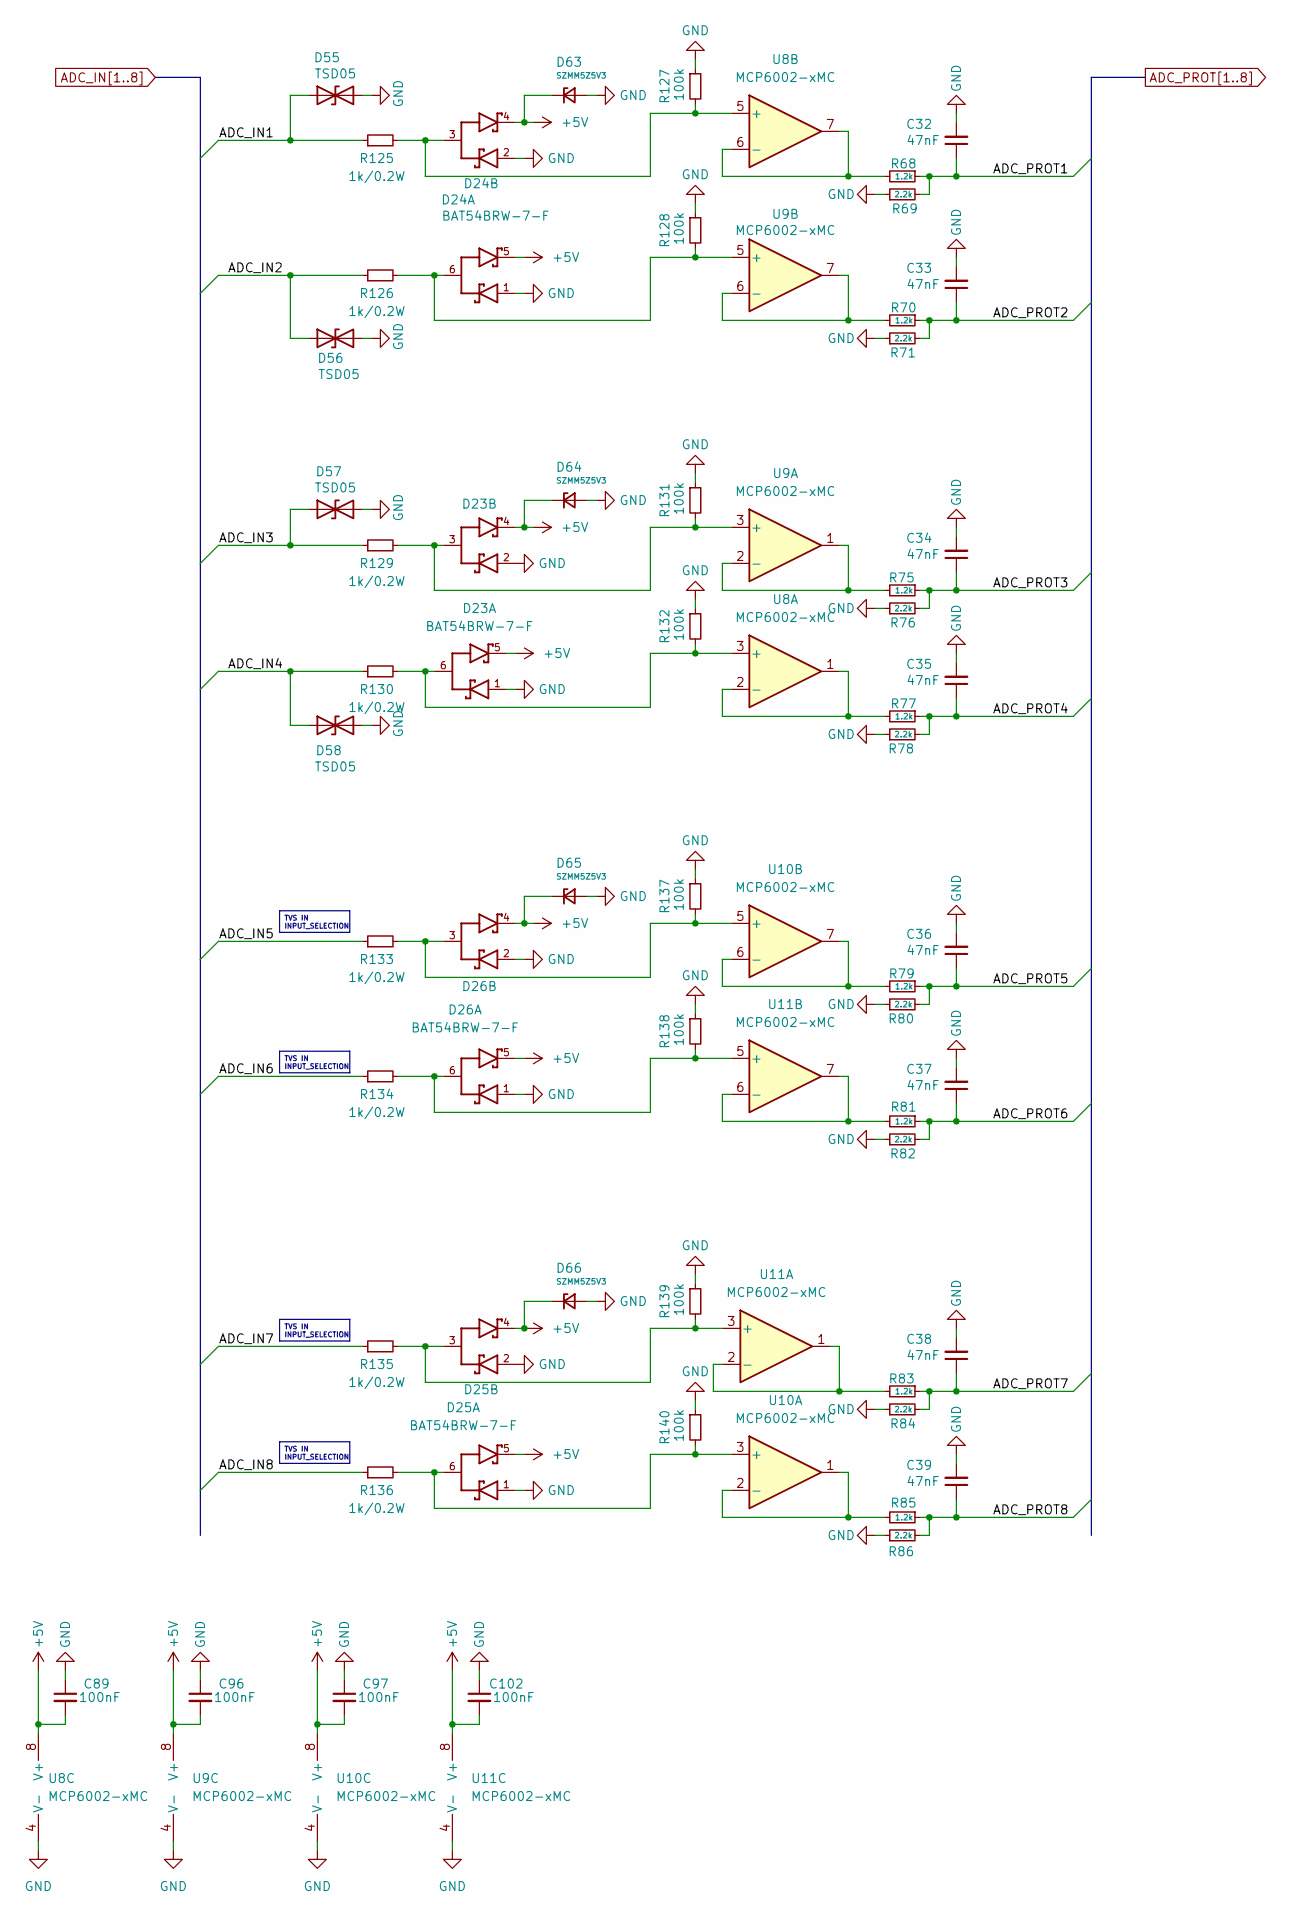
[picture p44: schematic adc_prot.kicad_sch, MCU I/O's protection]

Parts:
C32, C33, C34, C35, C36, C37, C38, C39: 47nF; C_0402_1005Metric
C89, C96, C97, C102: 100nF; R_0402_1005Metric
D23, D24, D25, D26: BAT54BRW-7-F; SOT65P210X110-6N; PARTREV 17 - 2
D55, D56, D57, D58: TSD05; D_SOD-323
D63, D64, D65, D66: SZMM5Z5V3; D_SOD-523
R68, R70, R75, R77, R79, R81, R83, R85: 1.2k; R_0402_1005Metric
R69, R71, R76, R78, R80, R82, R84, R86: 2.2k; R_0402_1005Metric
R125, R126, R129, R130, R133, R134, R135, R136: 1k/0.2W; R_0603_1608Metric
R127, R128, R131, R132, R137, R138, R139, R140: 100k; R_0402_1005Metric
U8, U9, U10, U11: MCP6002-xMC; DFN-8-1EP_3x2mm_P0.5mm_EP1.75x1.45mm

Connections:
+5V: C89.2, C96.2, C97.2, C102.2, D23.4, D23.5, D24.4, D24.5, D25.4, D25.5, D26.4, D26.5, D63.1 (K), D64.1 (K), D65.1 (K), D66.1 (K), U8.8 (V+), U9.8 (V+), U10.8 (V+), U11.8 (V+); also elsewhere on the board
ADC_IN1: D55.1 (A1), R125.1; also elsewhere on the board
ADC_IN2: D56.1 (A1), R126.1; also elsewhere on the board
ADC_IN3: D57.1 (A1), R129.1; also elsewhere on the board
ADC_IN4: D58.1 (A1), R130.1; also elsewhere on the board
ADC_IN5: R133.1; also elsewhere on the board
ADC_IN6: R134.1; also elsewhere on the board
ADC_IN7: R135.1; also elsewhere on the board
ADC_IN8: R136.1; also elsewhere on the board
ADC_PROT1: C32.1, R68.1, R69.2; also elsewhere on the board
ADC_PROT2: C33.1, R70.1, R71.2; also elsewhere on the board
ADC_PROT3: C34.1, R75.1, R76.2; also elsewhere on the board
ADC_PROT4: C35.1, R77.1, R78.2; also elsewhere on the board
ADC_PROT5: C36.1, R79.1, R80.2; also elsewhere on the board
ADC_PROT6: C37.1, R81.1, R82.2; also elsewhere on the board
ADC_PROT7: C38.1, R83.1, R84.2; also elsewhere on the board
ADC_PROT8: C39.1, R85.1, R86.2; also elsewhere on the board
unnamed: D23.6, R130.2, R132.2, U8.3 (+)
unnamed: R77.2, U8.1, U8.2 (-)
unnamed: D24.3, R125.2, R127.2, U8.5 (+)
unnamed: R68.2, U8.6 (-), U8.7
unnamed: D23.3, R129.2, R131.2, U9.3 (+)
unnamed: R75.2, U9.1, U9.2 (-)
unnamed: D24.6, R126.2, R128.2, U9.5 (+)
unnamed: R70.2, U9.6 (-), U9.7
unnamed: D25.6, R136.2, R140.2, U10.3 (+)
unnamed: R85.2, U10.1, U10.2 (-)
unnamed: D26.3, R133.2, R137.2, U10.5 (+)
unnamed: R79.2, U10.6 (-), U10.7
unnamed: D25.3, R135.2, R139.2, U11.3 (+)
unnamed: R83.2, U11.1, U11.2 (-)
unnamed: D26.6, R134.2, R138.2, U11.5 (+)
unnamed: R81.2, U11.6 (-), U11.7

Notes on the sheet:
TVS IN INPUT_SELECTION

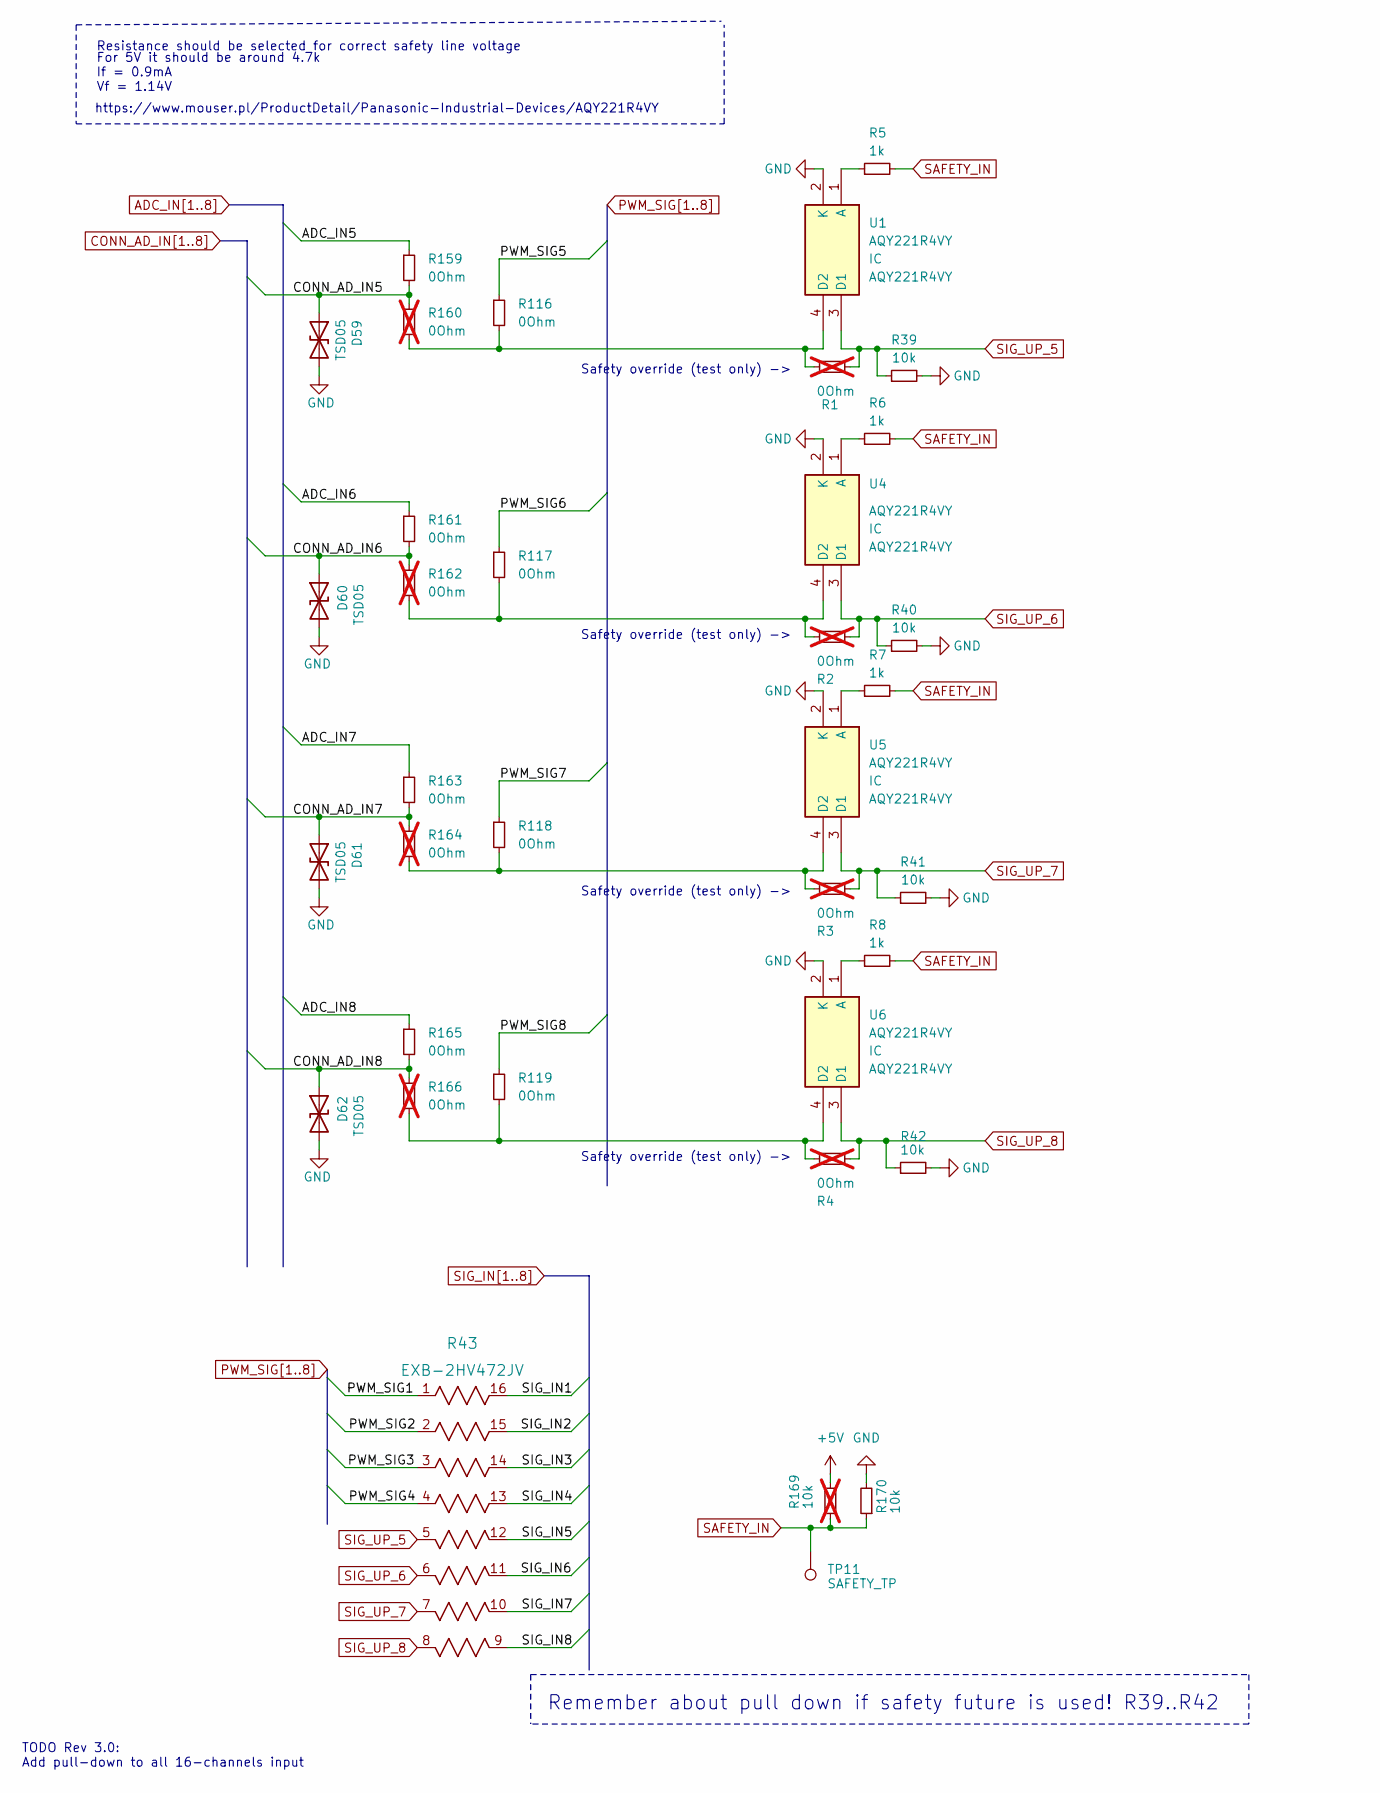
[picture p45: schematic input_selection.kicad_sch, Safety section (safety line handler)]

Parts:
D59, D60, D61, D62: TSD05; D_SOD-323
R1, R2, R3, R4, R160, R162, R164, R166: 0Ohm; R_0402_1005Metric; not fitted
R5, R6, R7, R8: 1k; R_0402_1005Metric
R39, R40, R41, R42, R170: 10k; R_0402_1005Metric
R43: EXB-2HV472JV; RES_EXB2HV
R116, R117, R118, R119, R159, R161, R163, R165: 0Ohm; R_0402_1005Metric
R169: 10k; R_0402_1005Metric; not fitted
TP11: SAFETY_TP; TestPoint_Pad_D2.0mm
U1, U4, U5, U6: AQY221R4VY; SOTFL127P485X190-4N; Manufacturer_Part_Number AQY221R4VY; Mouser Part Number 769-AQY221R4VY

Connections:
+5V: R169.2; also elsewhere on the board
ADC_IN5: R159.1; also elsewhere on the board
ADC_IN6: R161.1; also elsewhere on the board
ADC_IN7: R163.1; also elsewhere on the board
ADC_IN8: R165.1; also elsewhere on the board
CONN_AD_IN5: D59.1 (A1), R159.2, R160.1; also elsewhere on the board
CONN_AD_IN6: D60.1 (A1), R161.2, R162.1; also elsewhere on the board
CONN_AD_IN7: D61.1 (A1), R163.2, R164.1; also elsewhere on the board
CONN_AD_IN8: D62.1 (A1), R165.2, R166.1; also elsewhere on the board
unnamed: R5.1, U1.1 (A)
unnamed: R6.1, U4.1 (A)
unnamed: R7.1, U5.1 (A)
unnamed: R3.2, R118.2, R164.2, U5.4 (D2)
unnamed: R8.1, U6.1 (A)
unnamed: R4.2, R119.2, R166.2, U6.4 (D2)
PWM_SIG1: R43.1; also elsewhere on the board
PWM_SIG2: R43.2; also elsewhere on the board
PWM_SIG3: R43.3; also elsewhere on the board
PWM_SIG4: R43.4; also elsewhere on the board
PWM_SIG5: R116.1; also elsewhere on the board
PWM_SIG6: R117.1; also elsewhere on the board
PWM_SIG7: R118.1; also elsewhere on the board
PWM_SIG8: R119.1; also elsewhere on the board
SAFETY_IN: R5.2, R6.2, R7.2, R8.2, R169.1, R170.1, TP11.1; also elsewhere on the board
SIG_IN1: R43.16; also elsewhere on the board
SIG_IN2: R43.15; also elsewhere on the board
SIG_IN3: R43.14; also elsewhere on the board
SIG_IN4: R43.13; also elsewhere on the board
SIG_IN5: R43.12; also elsewhere on the board
SIG_IN6: R43.11; also elsewhere on the board
SIG_IN7: R43.10; also elsewhere on the board
SIG_IN8: R43.9; also elsewhere on the board
SIG_UP_7: R3.1, R41.1, R43.7, U5.3 (D1)
SIG_UP_8: R4.1, R42.1, R43.8, U6.3 (D1)

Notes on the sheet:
For 5V it should be around 4.7k If = 0.9mA Vf = 1.14V
Remember about pull down if safety future is used! R39..R42
Safety override (test only) ->
Resistance should be selected for correct safety line voltage
https://www.mouser.pl/ProductDetail/Panasonic-Industrial-Devices/AQY221R4VY
TODO Rev 3.0: Add pull-down to all 16-channels input

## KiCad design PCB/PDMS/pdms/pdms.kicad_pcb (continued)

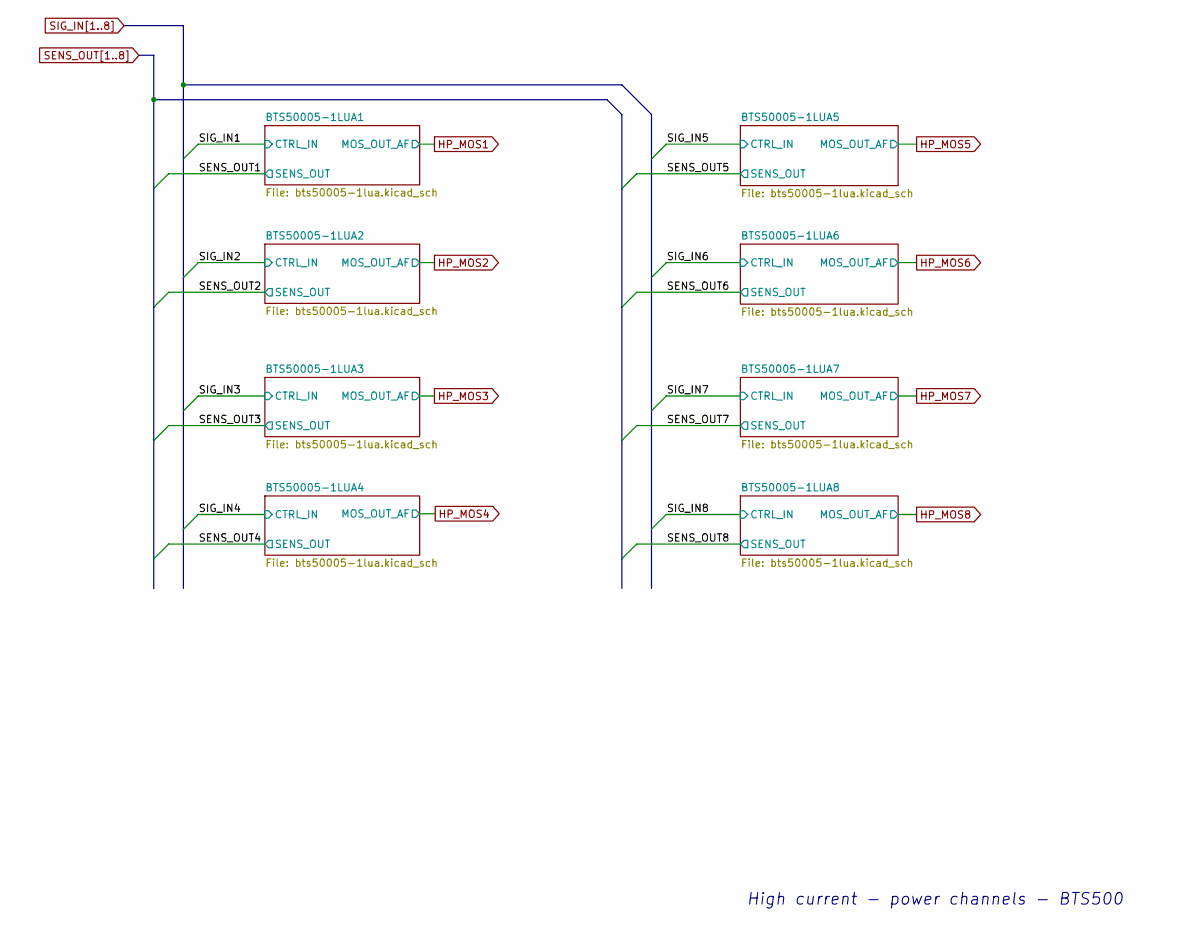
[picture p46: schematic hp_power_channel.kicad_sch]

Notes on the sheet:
High current - power channels - BTS500

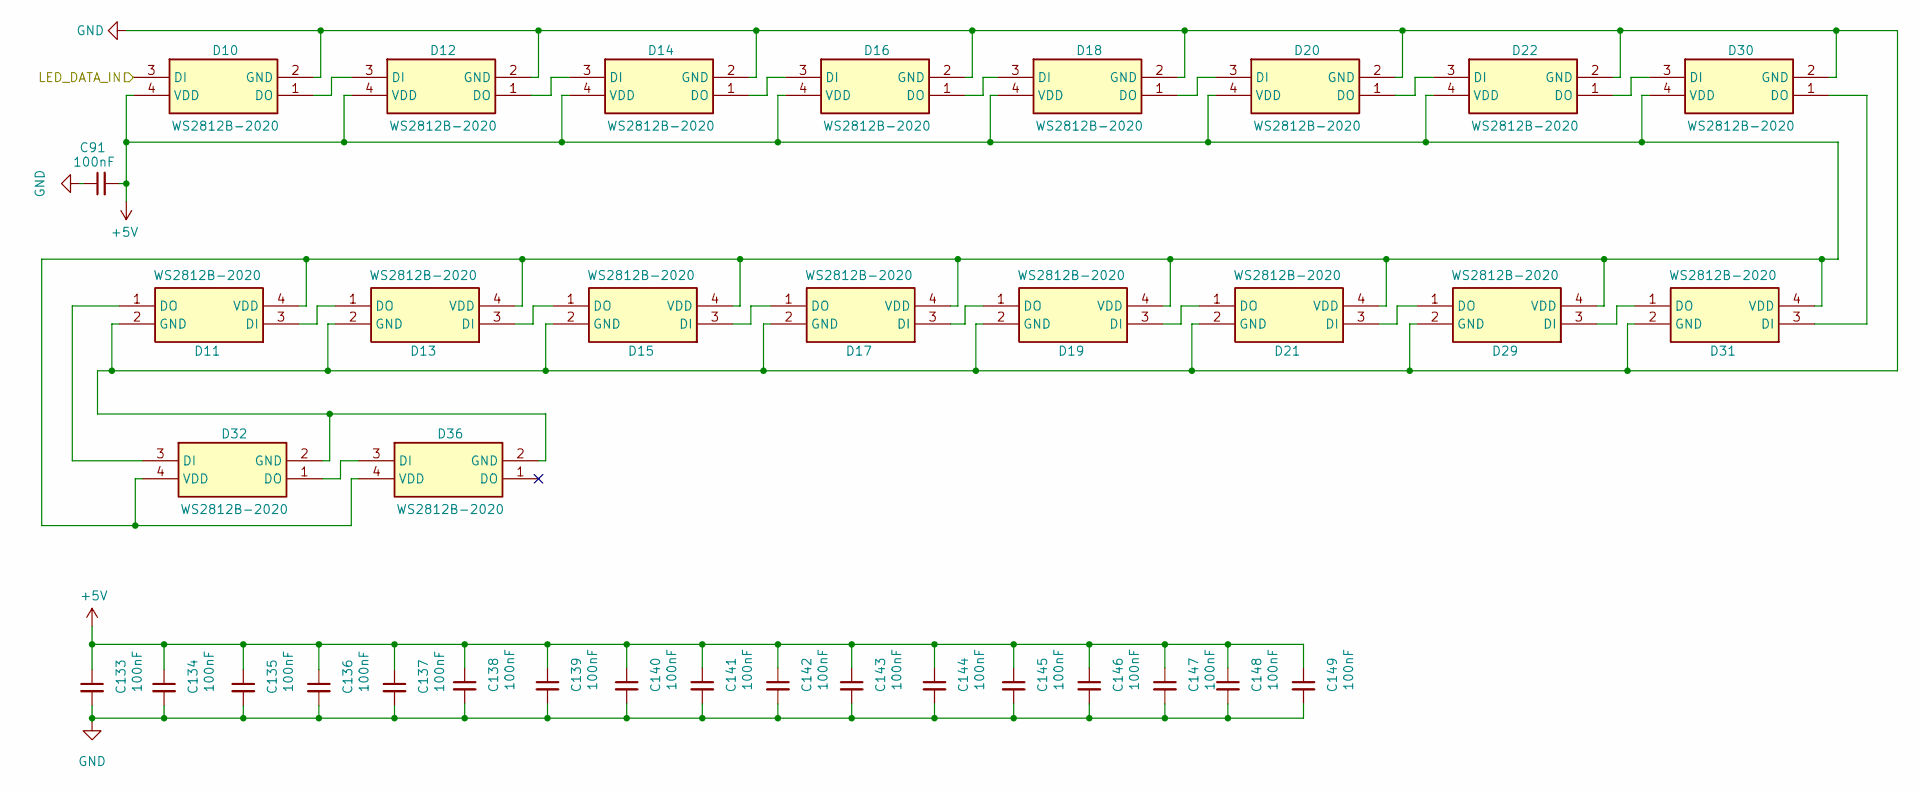
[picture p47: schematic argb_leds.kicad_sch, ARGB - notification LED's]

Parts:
C91, C133, C134, C135, C136, C137, C138, C139, C140, C141, C142, C143, C144, C145, C146, C147, C148, C149: 100nF; R_0402_1005Metric
D10, D11, D12, D13, D14, D15, D16, D17, D18, D19, D20, D21, D22, D29, D30, D31, D32, D36: WS2812B-2020; WS2812B2020; Manufacturer_Part_Number WS2812B-2020

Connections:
+5V: C91.2, C133.1, C134.1, C135.1, C136.1, C137.1, C138.1, C139.1, C140.1, C141.1, C142.1, C143.1, C144.1, C145.1, C146.1, C147.1, C148.1, C149.1, D10.4 (VDD), D11.4 (VDD), D12.4 (VDD), D13.4 (VDD), D14.4 (VDD), D15.4 (VDD), D16.4 (VDD), D17.4 (VDD), D18.4 (VDD), D19.4 (VDD), D20.4 (VDD), D21.4 (VDD), D22.4 (VDD), D29.4 (VDD), D30.4 (VDD), D31.4 (VDD), D32.4 (VDD), D36.4 (VDD); also elsewhere on the board
/ARGB_LEDS/LED_DATA_IN: D10.3 (DI); also elsewhere on the board
unnamed: D10.1 (DO), D12.3 (DI)
unnamed: D11.3 (DI), D13.1 (DO)
unnamed: D11.1 (DO), D32.3 (DI)
unnamed: D12.1 (DO), D14.3 (DI)
unnamed: D13.3 (DI), D15.1 (DO)
unnamed: D14.1 (DO), D16.3 (DI)
unnamed: D15.3 (DI), D17.1 (DO)
unnamed: D16.1 (DO), D18.3 (DI)
unnamed: D17.3 (DI), D19.1 (DO)
unnamed: D18.1 (DO), D20.3 (DI)
unnamed: D19.3 (DI), D21.1 (DO)
unnamed: D20.1 (DO), D22.3 (DI)
unnamed: D21.3 (DI), D29.1 (DO)
unnamed: D22.1 (DO), D30.3 (DI)
unnamed: D29.3 (DI), D31.1 (DO)
unnamed: D30.1 (DO), D31.3 (DI)
unnamed: D32.1 (DO), D36.3 (DI)

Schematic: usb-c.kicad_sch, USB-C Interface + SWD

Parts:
J6: 2305018-2; TE_2305018-2; not fitted
R173, R175: 1k5; R_0402_1005Metric; not fitted
R174, R176: 22; R_0402_1005Metric; not fitted
R177, R178: 5.1k; R_0402_1005Metric; not fitted
R179, R180: 0; R_0402_1005Metric; not fitted
U12: USBLC6-2SC6; SOT-23-6; not fitted

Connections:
+5V: U12.5 (VBUS); also elsewhere on the board
/USB-C/USB_D+: U12.4 (I/O2); also elsewhere on the board
/USB-C/USB_D-: U12.6 (I/O1); also elsewhere on the board
unnamed: J6.A5 (CC1), R177.1
unnamed: J6.B5 (CC2), R178.1
unnamed: R174.1, U12.1 (I/O1)
unnamed: R176.2, U12.3 (I/O2)
SWCLK: R180.1; also elsewhere on the board
SWDIO: R179.1; also elsewhere on the board
USBC_SWCLK: J6.A10 (RX2_N), J6.B10 (RX1_N), R180.2
USBC_SWDIO: J6.A11 (RX2_P), J6.B11 (RX1_P), R179.2
USB_CONN_D+: J6.A6 (DA_P), J6.B6 (DB_P), R175.1, R176.1
USB_CONN_D-: J6.A7 (DA_N), J6.B7 (DB_N), R173.1, R174.2

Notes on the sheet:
USB-C Legacy mode + Optional STLINK
USB-C Interface + SWD

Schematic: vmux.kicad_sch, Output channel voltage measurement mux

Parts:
C2, C112: 100nF; C_0402_1005Metric
C107: 47nF; C_0402_1005Metric
C1901, C1902, C1903, C1904, C1905, C1906, C1907, C1908: 4.7uF; C_0402_1005Metric
D38: BAT54SW; SOT-323_SC-70
D67: SZMM5Z3V9; D_SOD-523
IC2: 74HC4067PW-Q100J; SOP65P640X110-24N; Manufacturer_Part_Number 74HC4067PW-Q100J; Mouser Part Number 771-74HC4067PW-Q100J
R10, R13, R14, R17, R18, R33, R34, R37, R45, R48, R49, R52, R53, R88, R89, R92: 2.3k; R_0402_1005Metric
R11, R12, R15, R16, R19, R32, R35, R36, R46, R47, R50, R51, R65, R87, R90, R91: 10k; R_0402_1005Metric
R122: 1k; R_0402_1005Metric
U13: MCP6001-OT; SOT-23-5

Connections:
/VMUX/HP_MOS_DIV1: C1908.2, IC2.9 (Y0), R35.1, R37.2
/VMUX/HP_MOS_DIV2: C1907.2, IC2.8 (Y1), R19.1, R33.2
/VMUX/HP_MOS_DIV3: C1906.2, IC2.7 (Y2), R15.1, R17.2
/VMUX/HP_MOS_DIV4: C1905.2, IC2.6 (Y3), R11.1, R13.2
/VMUX/HP_MOS_DIV5: C1901.2, IC2.5 (Y4), R10.2, R12.1
/VMUX/HP_MOS_DIV6: C1902.2, IC2.4 (Y5), R14.2, R16.1
/VMUX/HP_MOS_DIV7: C1903.2, IC2.3 (Y6), R18.2, R32.1
/VMUX/HP_MOS_DIV8: C1904.2, IC2.2 (Y7), R34.2, R36.1
/VMUX/LP_MOS_DIV1: IC2.23 (Y8), R45.2, R47.1
/VMUX/LP_MOS_DIV2: IC2.22 (Y9), R49.2, R51.1
/VMUX/LP_MOS_DIV3: IC2.21 (Y10), R53.2, R87.1
/VMUX/LP_MOS_DIV4: IC2.20 (Y11), R89.2, R91.1
/VMUX/LP_MOS_DIV5: IC2.19 (Y12), R90.1, R92.2
/VMUX/LP_MOS_DIV6: IC2.18 (Y13), R65.1, R88.2
/VMUX/LP_MOS_DIV7: IC2.17 (Y14), R50.1, R52.2
/VMUX/LP_MOS_DIV8: IC2.16 (Y15), R46.1, R48.2
/VMUX/VMUX_SEL1: IC2.10 (S0); also elsewhere on the board
/VMUX/VMUX_SEL2: IC2.11 (S1); also elsewhere on the board
/VMUX/VMUX_SEL3: IC2.14 (S2); also elsewhere on the board
/VMUX/VMUX_SEL4: IC2.13 (S3); also elsewhere on the board
HP_MOS1: R15.2; also elsewhere on the board
HP_MOS2: R12.2; also elsewhere on the board
HP_MOS3: R11.2; also elsewhere on the board
HP_MOS4: R16.2; also elsewhere on the board
HP_MOS5: R32.2; also elsewhere on the board
HP_MOS6: R36.2; also elsewhere on the board
HP_MOS7: R35.2; also elsewhere on the board
HP_MOS8: R19.2; also elsewhere on the board
LP_MOS1: R47.2; also elsewhere on the board
LP_MOS2: R51.2; also elsewhere on the board
LP_MOS3: R87.2; also elsewhere on the board
LP_MOS4: R91.2; also elsewhere on the board
LP_MOS5: R90.2; also elsewhere on the board
LP_MOS6: R65.2; also elsewhere on the board
LP_MOS7: R50.2; also elsewhere on the board
LP_MOS8: R46.2; also elsewhere on the board
unnamed: D38.3, D67.1 (K), IC2.1 (Z), U13.3 (+)

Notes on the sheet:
In case you would ever consider to limit number of voltage dividers, the HC4067 operating range is up to 11V MAX!, It is really difficult to find 16 channel mux with extended input voltage range
IMPORTANT: On top of 2.3k resistors, there is 4.7uF capacitor soldered, to average out PWM from output voltage
In case of an reverse polarity situation, there might be an issue that +3.3V line is not powered, but HP_MOS out is, in such situation current should be limited by resistor
SZMM5Z3V9T1G
This values were verified! 2.32k and 10k is ok 2.32kOhm instead of 2.3k is used due to availabillity
(3.3kHz cut-off)

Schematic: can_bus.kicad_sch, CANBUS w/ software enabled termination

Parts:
C64, C65, C87: 100nF; C_0402_1005Metric
D27, D28: PESD2CANFD24L-UX; SOT65P210X110-3N; Manufacturer_Part_Number PESD2CANFD24L-UX; Mouser Part Number 771-PESD2CANFD24L-UX
IC17: TS5A21366DCUR; SOP50P310X90-8N; Manufacturer_Part_Number TS5A21366DCUR; Mouser Part Number 595-TS5A21366DCUR
R58, R59: 120; R_0402_1005Metric
U2, U3: MCP2561-E-SN; SOIC-8_3.9x4.9mm_P1.27mm

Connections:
+5V: C64.1, C65.1, C87.2, IC17.8 (V+), U2.3 (VDD), U3.3 (VDD); also elsewhere on the board
/CAN_BUS/CAN1_RX: U2.4 (RXD); also elsewhere on the board
/CAN_BUS/CAN1_TX: U2.1 (TXD); also elsewhere on the board
/CAN_BUS/CAN2_RX: U3.4 (RXD); also elsewhere on the board
/CAN_BUS/CAN2_TX: U3.1 (TXD); also elsewhere on the board
/CAN_BUS/CAN_TERMINATOR_1: IC17.7 (IN1); also elsewhere on the board
/CAN_BUS/CAN_TERMINATOR_2: IC17.3 (IN2); also elsewhere on the board
CAN1_H: D27.1 (K1), IC17.1 (NO1), U2.7 (CANH); also elsewhere on the board
CAN1_L: D27.2 (K2), R58.1, U2.6 (CANL); also elsewhere on the board
CAN2_H: D28.1 (K1), R59.1, U3.7 (CANH); also elsewhere on the board
CAN2_L: D28.2 (K2), IC17.6 (COM2), U3.6 (CANL); also elsewhere on the board
unnamed: IC17.2 (COM1), R58.2
unnamed: IC17.5 (NO2), R59.2

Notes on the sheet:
For commercial application this should be changed to solution that can persist at least 250mA continous short current
CAN1
Software termination for CAN1 & CAN2
CAN2

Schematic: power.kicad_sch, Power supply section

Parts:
C1: 4.7uF; C_0805_2012Metric
C3, C5, C90: 1uF; C_0805_2012Metric
C4, C92: 4.7uF; C_0603_1608Metric
C6, C7, C8, C9, C10, C11, C12, C13: 10uF; C_1206_3216Metric
C21: 100pF/50V; C_0402_1005Metric
C22: 100nF/50V; C_0402_1005Metric
C54: 1uF; C_0805_2012Metric; not fitted
C55: 4.7uF; C_0603_1608Metric; not fitted
C88: 1000uF; CP_Radial_D12.5mm_P5.00mm
D51, D52: SMC_TVS_28V; D_SMC
D53: 1N4448WS; D_SOD-323
D54: 1N4448WS; D_SOD-323; not fitted
F1: 2A; Fuse_1206_3216Metric
F2, F19, F23: 1A; Fuse_0805_2012Metric
F3: 3A; Fuse_0805_2012Metric
F18: 500mA; Fuse_0805_2012Metric; not fitted
FB1: 742792063; L_0805_2012Metric
IC1: BD50FD0WHFP-TR; BD50FD0WHFPTR; Manufacturer_Part_Number BD50FD0WHFP-TR; Mouser Part Number 755-BD50FD0WHFP-TR
IC3: LDO40LPU33RY; SON95P300X300X90-7N-D; Manufacturer_Part_Number LDO40LPU33RY; Mouser Part Number 511-LDO40LPU33RY
IC10: LDO40LPU50RY; SON95P300X300X90-7N-D; Manufacturer_Part_Number LDO40LPU50RY; Mouser Part Number 511-LDO40LPU50RY; not fitted
IC14: LDO40LPU50RY; SON95P300X300X90-7N-D; Manufacturer_Part_Number LDO40LPU50RY; Mouser Part Number 511-LDO40LPU50RY
L3: 10uH / 1A; L_6.3x6.3_H3
Q1, Q11: Si2319CDS; SOT-23
TP1: 3.3V PG; TestPoint_Pad_D1.0mm
TP10: 5V; TestPoint_Pad_D2.0mm
TP13: 3.3V; TestPoint_Pad_D2.0mm

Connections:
+3.3VP: F2.1; also elsewhere on the board
+5V: F18.1, F23.1, TP10.1; also elsewhere on the board
+5VL: F19.1; also elsewhere on the board
+12V: C88.1, D51.2 (A2), D52.2 (A2), F1.1, Q11.3 (D); also elsewhere on the board
+12VA: F3.1; also elsewhere on the board
/POWER1/PREFUSE_5VL: C92.1, F19.2, IC14.4 (VOUT), IC14.5 (VSENSE)
/POWER1/VOUT: C55.1, D54.2 (A), F18.2, IC10.2 (EN), IC10.3 (VIN)
unnamed: C21.1, C22.1, FB1.1, L3.2
unnamed: F1.2, Q1.3 (D)

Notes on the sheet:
This should be changed to CLC - Pi filter Change this to electrolytic cap
X7R capacitors close to pins
LDO 3.3V - EXTERNAL
B82462G4103M
Min. 25V 600-2000uF
This TVS should be uni-directional
1N4448WS should be placed here
BUCK 3.3V - INTERNAL
LDO 5V - INTERNAL
LDO 5V - INTERNAL (BIGGER FOOTPRINT)
PROTECTED BATT SUPPLY - EXTERNAL
Minimal fuse rating for 0805 is 250mA
REVERSE POLARITY + SUPPLY FILTER
This needs to be changed to Si2319CDS due to too low Vgss
INPUT FILTER & PROTECTION
LDO 5V - EXTERNAL
This needs to be changed to Si2319CDS due to too low Vgss ADD FUSE!

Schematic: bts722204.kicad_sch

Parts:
C14, C15, C16, C17: 10nF; C_0603_1608Metric
C18: 220pF; C_0402_1005Metric
C19: 470nF; C_0805_2012Metric
C20: 100nF; C_0805_2012Metric
D39: BAT54SW; SOT-323_SC-70
D49: SZMM5Z3V9; D_SOD-523
IC7: BTS722204ESAXUMA1; SOP65P600X115-25N; Manufacturer_Part_Number BTS722204ESAXUMA1; Mouser Part Number 726-BTS722204ESAXUMA
R20, R21, R22, R23, R31, R44: 1.2k; R_0402_1005Metric
R24, R25, R26, R27, R30, R114: 4.7k; R_0402_1005Metric
R28: 47; R_0805_2012Metric
R29: 470; R_0402_1005Metric

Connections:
+12V: C20.2, IC7.25 (VS); also elsewhere on the board
/LP_POWER_CHANNEL/BTS722204-1/IS: IC7.12 (IS), R31.1, R114.2
/LP_POWER_CHANNEL/BTS722204-1/LHI: IC7.7 (LHI), R44.1
/LP_POWER_CHANNEL/BTS722204-1/OUT0: C14.1, IC7.21 (OUT0_1), IC7.22 (OUT0_2), IC7.23 (OUT0_3), IC7.24 (OUT0_4); also elsewhere on the board
/LP_POWER_CHANNEL/BTS722204-1/OUT1: C15.1, IC7.19 (OUT1_1), IC7.20 (OUT1_2); also elsewhere on the board
/LP_POWER_CHANNEL/BTS722204-1/OUT2: C16.1, IC7.17 (OUT2_1), IC7.18 (OUT2_2); also elsewhere on the board
/LP_POWER_CHANNEL/BTS722204-1/OUT3: C17.1, IC7.13 (OUT3_1), IC7.14 (OUT3_2), IC7.15 (OUT3_3), IC7.16 (OUT3_4); also elsewhere on the board
/LP_POWER_CHANNEL/BTS722204-1/SI: IC7.4 (SI), R21.1
/LP_POWER_CHANNEL/BTS722204-1/SO: IC7.3 (SO), R20.1
/LP_POWER_CHANNEL/BTS722204-1/VDD_IO: C19.2, IC7.2 (VDD), R29.1
LP_CSN1: R23.2; also elsewhere on the board
LP_SIG_IN1: R24.1; also elsewhere on the board
LP_SIG_IN2: R25.1; also elsewhere on the board
LP_SIG_IN3: R26.1; also elsewhere on the board
LP_SIG_IN4: R27.1; also elsewhere on the board
unnamed: D39.3, D49.1 (K), R30.1, R114.1
unnamed: IC7.6 (CSN), R23.1
unnamed: C19.1, IC7.1 (GND_1), R28.1
unnamed: IC7.8 (IN0), R24.2
unnamed: IC7.9 (IN1), R25.2
unnamed: IC7.10 (IN2), R26.2
unnamed: IC7.11 (IN3), R27.2
unnamed: IC7.5 (SCLK), R22.1
SENS_OUT_LP1: C18.1, R30.2; also elsewhere on the board
SPI2_MISO: R20.2; also elsewhere on the board
SPI2_MOSI: R21.2; also elsewhere on the board
SPI2_SCK: R22.2; also elsewhere on the board

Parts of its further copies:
C67: 220pF; C_0402_1005Metric
C68: 470nF; C_0805_2012Metric
C69: 100nF; C_0805_2012Metric
C70, C71, C72, C73: 10nF; C_0603_1608Metric
D40: BAT54SW; SOT-323_SC-70
D50: SZMM5Z3V9; D_SOD-523
IC16: BTS722204ESAXUMA1; SOP65P600X115-25N; Manufacturer_Part_Number BTS722204ESAXUMA1; Mouser Part Number 726-BTS722204ESAXUMA
R93, R97, R98, R99, R100, R105: 1.2k; R_0402_1005Metric
R94: 47; R_0805_2012Metric
R95: 470; R_0402_1005Metric
R96, R101, R102, R103, R104, R115: 4.7k; R_0402_1005Metric

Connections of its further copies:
+12V: C69.2, IC16.25 (VS); also elsewhere on the board
/LP_POWER_CHANNEL/BTS722204-2/IS: IC16.12 (IS), R105.1, R115.2
/LP_POWER_CHANNEL/BTS722204-2/LHI: IC16.7 (LHI), R93.1
/LP_POWER_CHANNEL/BTS722204-2/OUT0: C70.1, IC16.21 (OUT0_1), IC16.22 (OUT0_2), IC16.23 (OUT0_3), IC16.24 (OUT0_4); also elsewhere on the board
/LP_POWER_CHANNEL/BTS722204-2/OUT1: C71.1, IC16.19 (OUT1_1), IC16.20 (OUT1_2); also elsewhere on the board
/LP_POWER_CHANNEL/BTS722204-2/OUT2: C72.1, IC16.17 (OUT2_1), IC16.18 (OUT2_2); also elsewhere on the board
/LP_POWER_CHANNEL/BTS722204-2/OUT3: C73.1, IC16.13 (OUT3_1), IC16.14 (OUT3_2), IC16.15 (OUT3_3), IC16.16 (OUT3_4); also elsewhere on the board
/LP_POWER_CHANNEL/BTS722204-2/SI: IC16.4 (SI), R98.1
/LP_POWER_CHANNEL/BTS722204-2/SO: IC16.3 (SO), R97.1
/LP_POWER_CHANNEL/BTS722204-2/VDD_IO: C68.2, IC16.2 (VDD), R95.1
LP_CSN2: R100.2; also elsewhere on the board
LP_SIG_IN5: R101.1; also elsewhere on the board
LP_SIG_IN6: R102.1; also elsewhere on the board
LP_SIG_IN7: R103.1; also elsewhere on the board
LP_SIG_IN8: R104.1; also elsewhere on the board
unnamed: D40.3, D50.1 (K), R96.1, R115.1
unnamed: IC16.6 (CSN), R100.1
unnamed: C68.1, IC16.1 (GND_1), R94.1
unnamed: IC16.8 (IN0), R101.2
unnamed: IC16.9 (IN1), R102.2
unnamed: IC16.10 (IN2), R103.2
unnamed: IC16.11 (IN3), R104.2
unnamed: IC16.5 (SCLK), R99.1
SENS_OUT_LP2: C67.1, R96.2; also elsewhere on the board
SPI2_MISO: R97.2; also elsewhere on the board
SPI2_MOSI: R98.2; also elsewhere on the board
SPI2_SCK: R99.2; also elsewhere on the board

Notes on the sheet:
Ris_prot -> value should be checked properly
BTS72220 - 4 channel high side switch

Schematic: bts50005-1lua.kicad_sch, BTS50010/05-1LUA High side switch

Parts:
C114: 100nF; C_0402_1005Metric
C115: 1nF; C_0402_1005Metric
C116: 10nF; C_0402_1005Metric
C117: 100nF; C_0805_2012Metric
D6: BAT54SW; SOT-323_SC-70
D45: SZMM5Z3V9; D_SOD-523
F8: 40A; Fuse_1206_3216Metric
Q7: BTS500101LUAAUMA1; Manufacturer_Part_Number BTS500101LUAAUMA1; Mouser Part Number 726-BTS500101LUAAUMA
R110, R199: 4.7k; R_0402_1005Metric
R201: 1k; R_0402_1005Metric
TP6: AFUSE; TestPoint_Pad_D2.0mm

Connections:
+12V: C115.1, C117.1, Q7.4 (DEN), Q7.9 (VS); also elsewhere on the board
/HP_POWER_CHANNEL/BTS50005-1LUA5/MOS_OUT: C116.2, F8.1, Q7.5 (OUT)
HP_MOS5: F8.2, TP6.1; also elsewhere on the board
unnamed: D6.3, D45.1 (K), R110.1, R199.2
unnamed: C115.2, Q7.2 (IS), R110.2, R201.2
SENS_OUT5: C114.2, R199.1; also elsewhere on the board
SIG_IN5: Q7.3 (IN); also elsewhere on the board

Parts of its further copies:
C93, C98, C103, C108, C119, C124, C129: 100nF; C_0402_1005Metric
C94, C100, C105, C110, C121, C126, C131: 10nF; C_0402_1005Metric
C95, C101, C106, C111, C122, C127, C132: 100nF; C_0805_2012Metric
C99, C104, C109, C113, C120, C125, C130: 1nF; C_0402_1005Metric
D1, D2, D3, D5, D7, D8, D9: BAT54SW; SOT-323_SC-70
D41, D42, D43, D44, D46, D47, D48: SZMM5Z3V9; D_SOD-523
F4, F5, F6, F7, F9, F21, F22: 40A; Fuse_1206_3216Metric
Q3, Q4, Q5, Q6, Q8, Q9, Q10: BTS500101LUAAUMA1; Manufacturer_Part_Number BTS500101LUAAUMA1; Mouser Part Number 726-BTS500101LUAAUMA
R9, R38, R106, R107, R111, R112, R113, R183, R188, R193, R198, R204, R209, R214: 4.7k; R_0402_1005Metric
R67, R185, R190, R195, R206, R211, R216: 1k; R_0402_1005Metric
TP2, TP3, TP4, TP5, TP7, TP8, TP9: AFUSE; TestPoint_Pad_D2.0mm

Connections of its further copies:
+12V: C95.1, C99.1, C101.1, C104.1, C106.1, C109.1, C111.1, C113.1, C120.1, C122.1, C125.1, C127.1, C130.1, C132.1, Q3.4 (DEN), Q3.9 (VS), Q4.4 (DEN), Q4.9 (VS), Q5.4 (DEN), Q5.9 (VS), Q6.4 (DEN), Q6.9 (VS), Q8.4 (DEN), Q8.9 (VS), Q9.4 (DEN), Q9.9 (VS), Q10.4 (DEN), Q10.9 (VS); also elsewhere on the board
/HP_POWER_CHANNEL/BTS50005-1LUA1/MOS_OUT: C94.2, F7.1, Q3.5 (OUT)
/HP_POWER_CHANNEL/BTS50005-1LUA2/MOS_OUT: C100.2, F4.1, Q4.5 (OUT)
/HP_POWER_CHANNEL/BTS50005-1LUA3/MOS_OUT: C105.2, F5.1, Q5.5 (OUT)
/HP_POWER_CHANNEL/BTS50005-1LUA4/MOS_OUT: C110.2, F6.1, Q6.5 (OUT)
/HP_POWER_CHANNEL/BTS50005-1LUA6/MOS_OUT: C121.2, F9.1, Q8.5 (OUT)
/HP_POWER_CHANNEL/BTS50005-1LUA7/MOS_OUT: C126.2, F21.1, Q9.5 (OUT)
/HP_POWER_CHANNEL/BTS50005-1LUA8/MOS_OUT: C131.2, F22.1, Q10.5 (OUT)
HP_MOS1: F7.2, TP5.1; also elsewhere on the board
HP_MOS2: F4.2, TP2.1; also elsewhere on the board
HP_MOS3: F5.2, TP3.1; also elsewhere on the board
HP_MOS4: F6.2, TP4.1; also elsewhere on the board
HP_MOS6: F9.2, TP7.1; also elsewhere on the board
HP_MOS7: F21.2, TP8.1; also elsewhere on the board
HP_MOS8: F22.2, TP9.1; also elsewhere on the board
unnamed: D1.3, D41.1 (K), R9.1, R183.2
unnamed: D2.3, D42.1 (K), R38.1, R188.2
unnamed: D3.3, D43.1 (K), R106.1, R193.2
unnamed: D5.3, D44.1 (K), R107.1, R198.2
unnamed: D7.3, D46.1 (K), R111.1, R204.2
unnamed: D8.3, D47.1 (K), R112.1, R209.2
unnamed: D9.3, D48.1 (K), R113.1, R214.2
unnamed: C113.2, Q3.2 (IS), R67.2, R107.2
unnamed: C99.2, Q4.2 (IS), R9.2, R185.2
unnamed: C104.2, Q5.2 (IS), R38.2, R190.2
unnamed: C109.2, Q6.2 (IS), R106.2, R195.2
unnamed: C120.2, Q8.2 (IS), R111.2, R206.2
unnamed: C125.2, Q9.2 (IS), R112.2, R211.2
unnamed: C130.2, Q10.2 (IS), R113.2, R216.2
SENS_OUT1: C93.2, R198.1; also elsewhere on the board
SENS_OUT2: C98.2, R183.1; also elsewhere on the board
SENS_OUT3: C103.2, R188.1; also elsewhere on the board
SENS_OUT4: C108.2, R193.1; also elsewhere on the board
SENS_OUT6: C119.2, R204.1; also elsewhere on the board
SENS_OUT7: C124.2, R209.1; also elsewhere on the board
SENS_OUT8: C129.2, R214.1; also elsewhere on the board
SIG_IN1: Q3.3 (IN); also elsewhere on the board
SIG_IN2: Q4.3 (IN); also elsewhere on the board
SIG_IN3: Q5.3 (IN); also elsewhere on the board
SIG_IN4: Q6.3 (IN); also elsewhere on the board
SIG_IN6: Q8.3 (IN); also elsewhere on the board
SIG_IN7: Q9.3 (IN); also elsewhere on the board
SIG_IN8: Q10.3 (IN); also elsewhere on the board

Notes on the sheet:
IMPORTANT: - DEN should be pulsed with IN. - DEN should be connected to IN via some resistor. - Right now when channel is in PWM mode (duty off part) and DEN enabled, it puts hard fault on output, due to open-circuit detection (till Vout discharges till < Typ. 3V - Link to forum
Check if RC filter values are correct: Sense signal filtering A time constant (RADC * CSENSE ) longer than 1 μs is recommended
Conditional Ris > 2.5k
For sake of accuracy of current sense BTS50010 should be used
SZMM5Z3V9T1G
<- Currently 8k2 0.1%
Ris_prot -> value should be checked properly
Sense resistor accuracy important!

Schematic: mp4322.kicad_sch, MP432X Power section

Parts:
C1: 1nF; C_0402_1005Metric
C2: 10nF; C_0402_1005Metric
C3, C4: 2.2uF; C_0805_2012Metric
C5: 22uF; CP_Elec_6.3x9.9
C23, C24: 4.7uF; C_1206_3216Metric
C25, C26: 0.1uF; C_0805_2012Metric
C27: 1uF; C_0402_1005Metric
C28: 47nF; C_0402_1005Metric
C29: 10pF; C_0402_1005Metric
C30, C31: 22uF; C_1206_3216Metric
C61, C62: 10uF; C_1206_3216Metric; not fitted
C63: 2.2uF; C_1206_3216Metric; not fitted
F24: 2A; Fuse_0805_2012Metric
L1: 742792063; L_0805_2012Metric
L2: XEL4020-102MEB; L_Coilcraft_XxL4020
L4: 2.2uH; L_Vishay_IHLP-1616
R1: 0R0; R_0402_1005Metric
R2: NA; R_0402_1005Metric; not fitted
R120: 15k; R_0402_1005Metric
R121, R122, R124: 100k; R_0402_1005Metric
R123: 31.6k; R_0402_1005Metric
U7: MP4322GDE-P; QFN-12_MP4322_MNP

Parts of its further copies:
C56: 47nF; C_0402_1005Metric
C57: 10pF; C_0402_1005Metric
C58, C59: 22uF; C_1206_3216Metric
C60: 1uF; C_0402_1005Metric
F20: 2A; Fuse_0805_2012Metric
L5: 2.2uH; L_Vishay_IHLP-1616
R60: 0R0; R_0402_1005Metric
R61, R63, R64: 100k; R_0402_1005Metric
R62: 15k; R_0402_1005Metric

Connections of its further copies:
unnamed: C56.1, R60.1

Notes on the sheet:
(1206)
12V FILTERING
If electrolytic cap won't fit
When creating layout always follow guidelines page 35 (Click for TDS)
To obtain best efficency always use converter that uses most of the advised by producer current range. For MP432XX fammily there are following possibilites: MP4320 - 0.5A (Requires bigger coil L = 5.6uH, lower freq = 1.8Mhz) MP4321 - 1A (Requires bigger coil L = 5.6uH) MP4322 - 2A (current implemen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
(1206)
LAYOUT GUIDELINES:
NOTE:
OPT UVLO

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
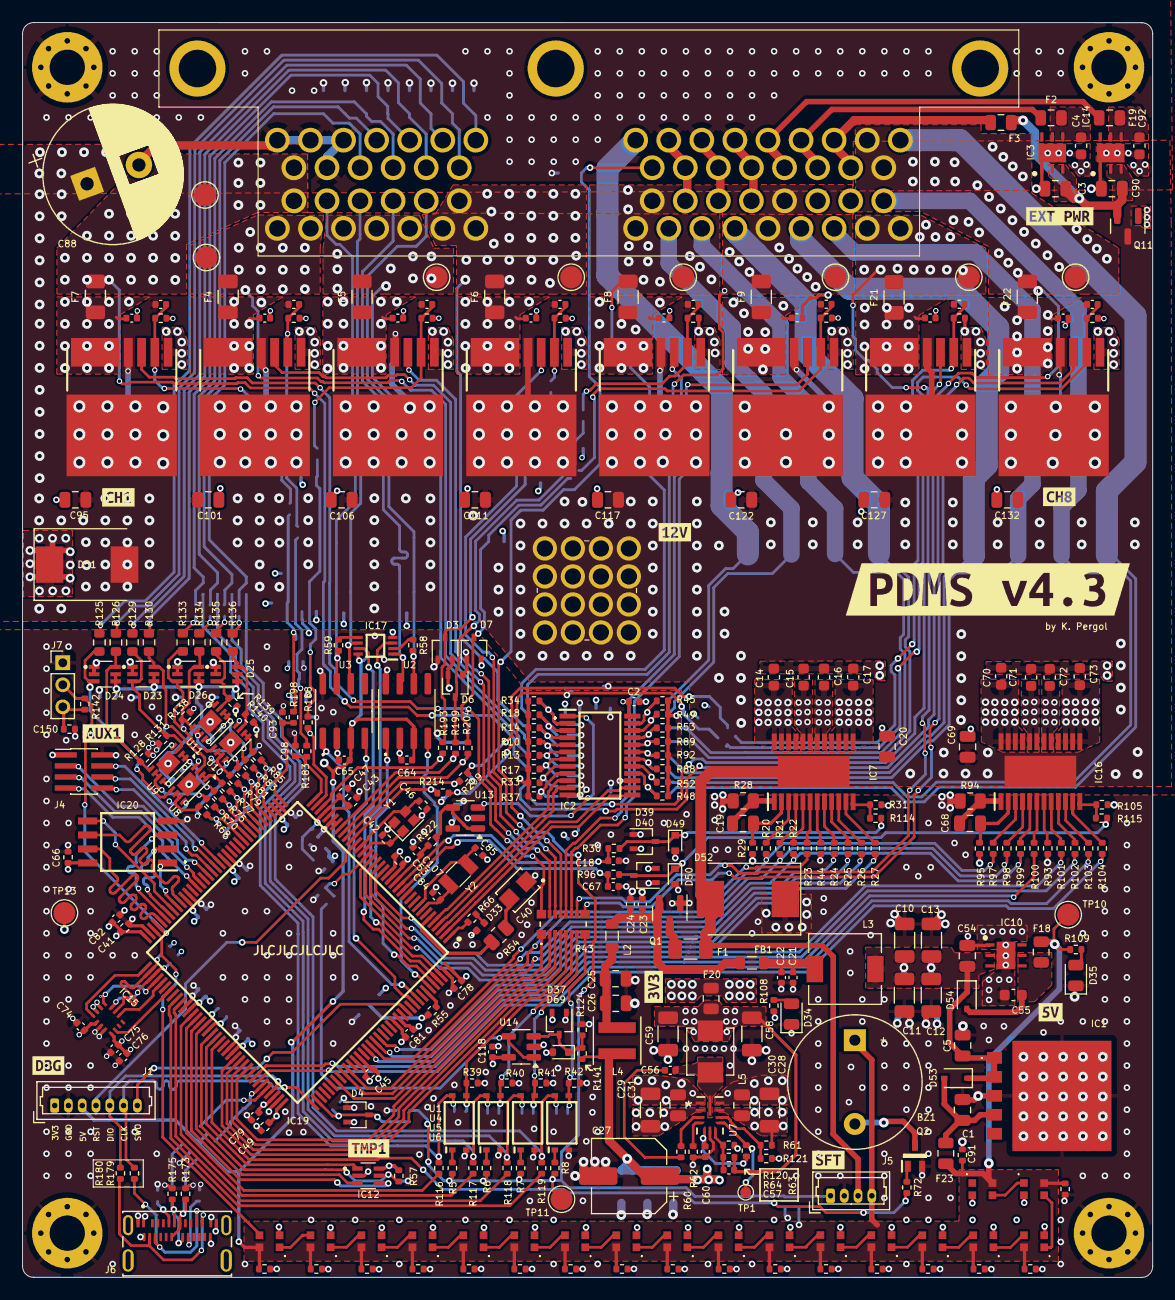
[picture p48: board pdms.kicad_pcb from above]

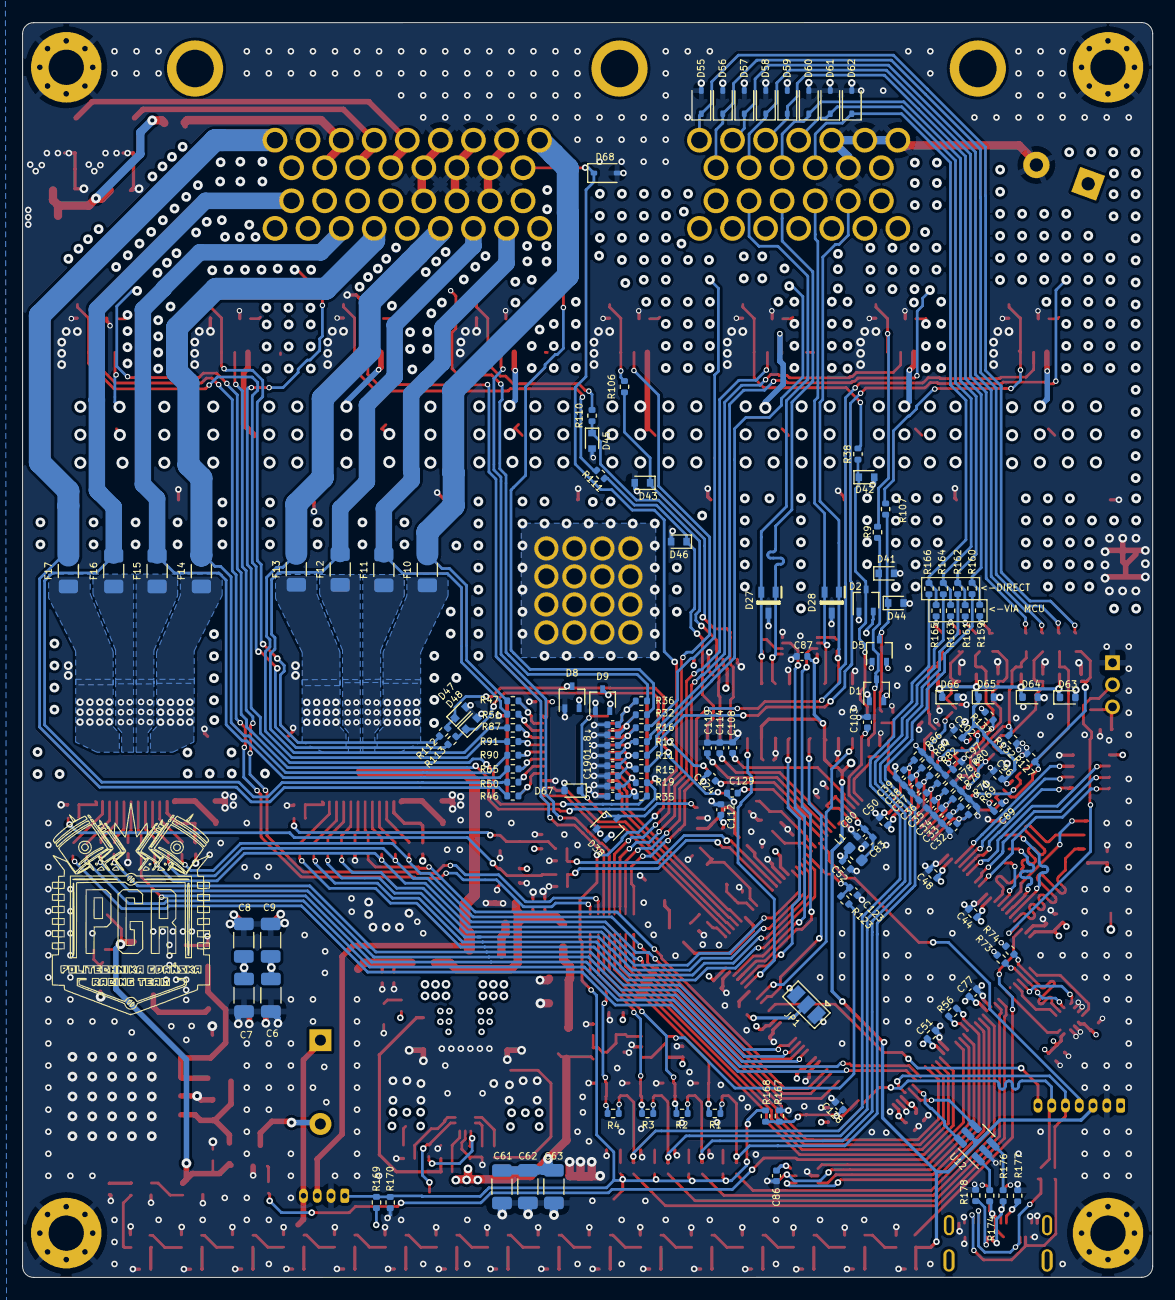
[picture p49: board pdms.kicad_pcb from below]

Board: 4 copper layers, 102.5 x 113.8 mm, 509 parts (147 on the bottom side), 300 nets.

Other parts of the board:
Ge: LOGO
kibuzzard-65AD9CDA: G***; kibuzzard-65AD9CDA
kibuzzard-65C2D9B8: G***; kibuzzard-65C2D9B8
kibuzzard-65C96195: G***; kibuzzard-65C96195
kibuzzard-646F7EA8: G***; kibuzzard-646F7EA8
kibuzzard-664CF65B: G***; kibuzzard-664CF65B
kibuzzard-680F5382: G***; kibuzzard-680F5382
kibuzzard-6477C3F8: G***; kibuzzard-6477C3F8
kibuzzard-64698A06: G***; kibuzzard-64698A06
kibuzzard-64713E79: G***; kibuzzard-64713E79
kibuzzard-64714FCB: G***; kibuzzard-64714FCB
kibuzzard-64716719: G***; kibuzzard-64716719

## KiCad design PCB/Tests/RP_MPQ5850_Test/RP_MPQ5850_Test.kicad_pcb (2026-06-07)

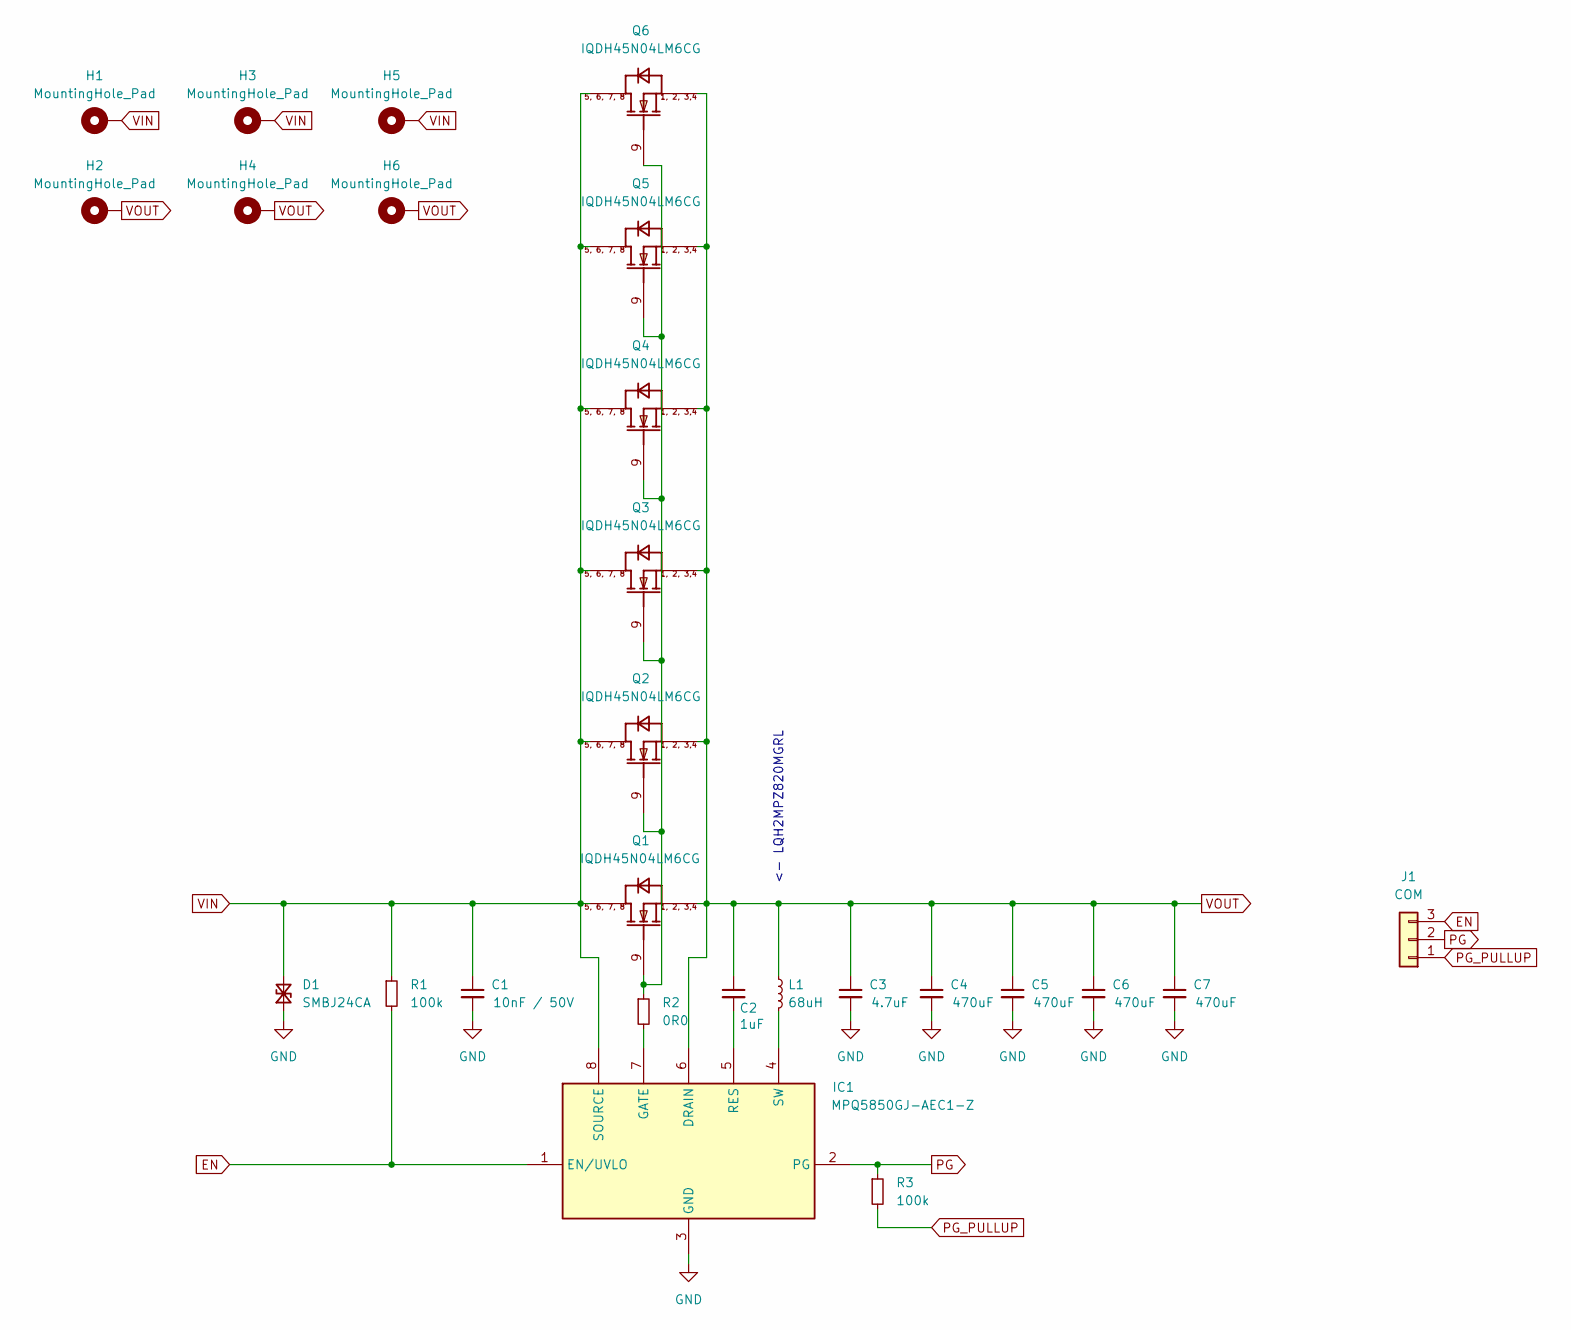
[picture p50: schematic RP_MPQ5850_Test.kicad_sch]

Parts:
C1: 10nF / 50V; D_0603_1608Metric
C2: 1uF; D_0805_2012Metric
C3: 4.7uF; D_1206_3216Metric
C4, C5, C6, C7: 470uF; CP_Radial_D12.5mm_P5.00mm
D1: SMBJ24CA; D_SMB
H1, H2, H3, H4, H5, H6: MountingHole_Pad; MountingHole_6mm_Pad_TopBottom
IC1: MPQ5850GJ-AEC1-Z; SOT65P280X100-8N; Manufacturer_Part_Number MPQ5850GJ-AEC1-Z
J1: COM; PinHeader_1x03_P2.54mm_Vertical
L1: 68uH; LQH2MCN100K02L
Q1, Q2, Q3, Q4, Q5, Q6: IQDH45N04LM6CG; IFX-PG-TTFN-9-2-V
R1, R3: 100k; R_0402_1005Metric
R2: 0R0; R_0402_1005Metric

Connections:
EN: IC1.1 (EN/UVLO), J1.3, R1.2
GND: C1.2, C3.2, C4.2, C5.2, C6.2, C7.2, D1.1 (A1), IC1.3 (GND)
unnamed: IC1.7 (GATE), R2.2
unnamed: C2.2, IC1.5 (RES)
unnamed: IC1.4 (SW), L1.2
unnamed: Q1.9 (GATE), Q2.9 (GATE), Q3.9 (GATE), Q4.9 (GATE), Q5.9 (GATE), Q6.9 (GATE), R2.1
PG: IC1.2 (PG), J1.2, R3.1
PG_PULLUP: J1.1, R3.2
VIN: C1.1, D1.2 (A2), H1.1, H3.1, H5.1, IC1.8 (SOURCE), Q1.5 (DRAIN1), Q1.6 (DRAIN2), Q1.7 (DRAIN3), Q1.8 (DRAIN4), Q2.5 (DRAIN1), Q2.6 (DRAIN2), Q2.7 (DRAIN3), Q2.8 (DRAIN4), Q3.5 (DRAIN1), Q3.6 (DRAIN2), Q3.7 (DRAIN3), Q3.8 (DRAIN4), Q4.5 (DRAIN1), Q4.6 (DRAIN2), Q4.7 (DRAIN3), Q4.8 (DRAIN4), Q5.5 (DRAIN1), Q5.6 (DRAIN2), Q5.7 (DRAIN3), Q5.8 (DRAIN4), Q6.5 (DRAIN1), Q6.6 (DRAIN2), Q6.7 (DRAIN3), Q6.8 (DRAIN4), R1.1
VOUT: C2.1, C3.1, C4.1, C5.1, C6.1, C7.1, H2.1, H4.1, H6.1, IC1.6 (DRAIN), L1.1, Q1.1 (SOURCE1), Q1.2 (SOURCE2), Q1.3 (SOURCE3), Q1.4 (SOURCE4), Q2.1 (SOURCE1), Q2.2 (SOURCE2), Q2.3 (SOURCE3), Q2.4 (SOURCE4), Q3.1 (SOURCE1), Q3.2 (SOURCE2), Q3.3 (SOURCE3), Q3.4 (SOURCE4), Q4.1 (SOURCE1), Q4.2 (SOURCE2), Q4.3 (SOURCE3), Q4.4 (SOURCE4), Q5.1 (SOURCE1), Q5.2 (SOURCE2), Q5.3 (SOURCE3), Q5.4 (SOURCE4), Q6.1 (SOURCE1), Q6.2 (SOURCE2), Q6.3 (SOURCE3), Q6.4 (SOURCE4)

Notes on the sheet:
<- LQH2MPZ820MGRL

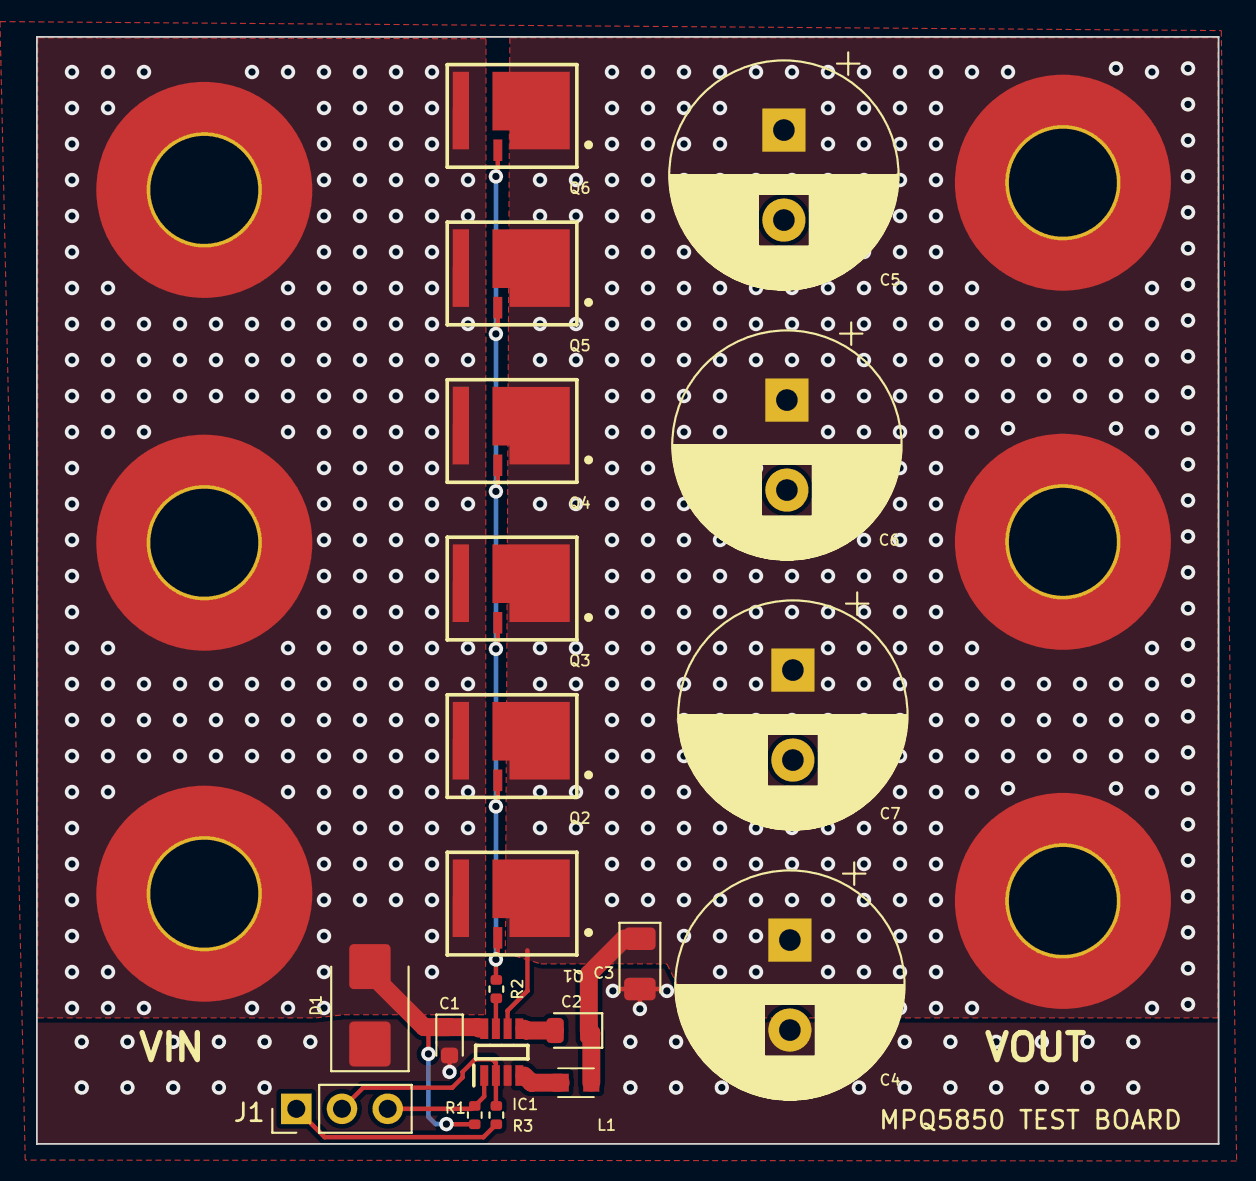
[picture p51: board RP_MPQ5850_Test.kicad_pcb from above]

Board: 4 copper layers, 65.7 x 61.5 mm, 26 parts (0 on the bottom side), 10 nets.

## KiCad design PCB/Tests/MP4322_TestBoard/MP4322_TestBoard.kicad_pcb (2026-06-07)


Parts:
H1, H2, H3: MountingHole_Pad; MountingHole_2.2mm_M2_ISO7380_Pad_TopBottom

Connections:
GND: H1.1, H2.1, H3.1; also elsewhere on the board

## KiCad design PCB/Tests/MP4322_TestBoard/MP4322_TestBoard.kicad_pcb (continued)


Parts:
C1: 1nF; C_0402_1005Metric
C2: 10nF; C_0402_1005Metric
C3, C4: 2.2uF; C_0805_2012Metric
C5: 22uF; CP_Elec_6.3x9.9
C23, C24: 4.7uF; C_1206_3216Metric
C25, C26: 0.1uF; C_0805_2012Metric
C27: 1uF; C_0402_1005Metric
C28: 47nF; C_0402_1005Metric
C29: 10pF; C_0402_1005Metric
C30, C31: 22uF; C_1206_3216Metric
F24: 2A; Fuse_0805_2012Metric
L1: L; L_0805_2012Metric
L2: L; L_Coilcraft_XxL4020
L4: 2.2uH; L_Vishay_IHLP-1616
R1: 0R0; R_0402_1005Metric
R2: NA; R_0402_1005Metric
R120: 15k; R_0402_1005Metric
R121, R122, R124: 100k; R_0402_1005Metric
R123: 31.6k; R_0402_1005Metric
U7: MP4322GDE-P; QFN-12_MP4322_MNP

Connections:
12V_FILTERED: C5.1, C23.1, C24.1, C25.1, C26.1, L2.1, R121.1, U7.2 (VIN), U7.10 (VIN)
+3.3V: F24.1; also elsewhere on the board
+12V: C1.1, C2.1, L1.1; also elsewhere on the board
/MP4322/PGO: R122.2, U7.8 (PG)
/MP4322/PRECOIL: C28.2, L4.1, U7.12 (SW)
/MP4322/PREFUSE: C29.2, C30.1, C31.1, F24.2, L4.2, R124.1
GND: C1.2, C2.2, C3.2, C4.2, C5.2, C23.2, C24.2, C25.2, C26.2, C27.2, C30.2, C31.2, R2.1, R120.1, R123.2, U7.1 (PGND), U7.6 (AGND), U7.11 (PGND); also elsewhere on the board
unnamed: C3.1, C4.1, L1.2, L2.2
unnamed: C27.1, R122.1, U7.5 (VCC)
unnamed: C28.1, R1.1
unnamed: C29.1, R123.1, R124.2, U7.7 (FB)
unnamed: R1.2, U7.3 (BOOT)
unnamed: R120.2, U7.4 (FREQ)
unnamed: R2.2, R121.2, U7.9 (EN)

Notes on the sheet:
(1206)
12V FILTERING
XEL4020-102MEB
When creating layout always follow guidelines page 35 (Click for TDS)
742792063
To obtain best efficency always use converter that uses most of the advised by producer current range. For MP432XX fammily there are following possibilites: MP4320 - 0.5A (Requires bigger coil L = 5.6uH, lower freq = 1.8Mhz) MP4321 - 1A (Requires bigger coil L = 5.6uH) MP4322 - 2A (current implemen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
(1206)
LAYOUT GUIDELINES:
NOTE:
OPT UVLO


Board: 4 copper layers, 36.5 x 20.3 mm, 31 parts (0 on the bottom side), 14 nets.

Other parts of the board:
J1, J2: Conn_01x02; JST_EH_B2B-EH-A_1x02_P2.50mm_Vertical

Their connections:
+3.3V: J2.2; also elsewhere on the board
+12V: J1.2; also elsewhere on the board
GND: J1.1, J2.1; also elsewhere on the board

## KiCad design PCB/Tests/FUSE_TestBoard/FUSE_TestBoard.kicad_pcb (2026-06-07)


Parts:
F1, F2, F3, F4, F5, F6, F7, F8: Fuse_Small; Fuse_1206_3216Metric_Pad1.42x1.75mm_HandSolder
J1, J2: 6473427-1; 64734271; Manufacturer_Part_Number 6473427-1; Mouser Part Number 571-6473427-1

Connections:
+3.3VP: J1.23, J1.24, J2.23, J2.24
+5VL: J1.25, J1.26, J2.25, J2.26
+12VA: J1.21, J1.22, J2.21, J2.22
ADC_IN1: J1.48, J2.48
ADC_IN2: J1.49, J2.49
ADC_IN3: J1.50, J2.50
ADC_IN4: J1.51, J2.51
CAN1_H: J1.40, J2.40
CAN1_L: J1.38, J2.38
CAN2_H: J1.44, J2.44
CAN2_L: J1.42, J2.42
CONN_AD_IN5: J1.52, J2.52
CONN_AD_IN6: J1.53, J2.53
CONN_AD_IN7: J1.54, J2.54
CONN_AD_IN8: J1.55, J2.55
GND: J1.10, J1.12, J1.14, J1.27, J1.28, J1.29, J1.30, J1.31, J1.32, J1.56, J1.57, J1.58, J1.60, J2.10, J2.12, J2.14, J2.27, J2.28, J2.29, J2.30, J2.31, J2.32, J2.56, J2.57, J2.58, J2.60
HP_MOS1: F1.1, J1.46, J1.59
HP_MOS1_B: F1.2, J2.46, J2.59
HP_MOS2: F2.1, J1.45, J1.47
HP_MOS2_B: F2.2, J2.45, J2.47
HP_MOS3: F3.1, J1.39, J1.41, J1.43
HP_MOS3_B: F3.2, J2.39, J2.41, J2.43
HP_MOS4: F4.1, J1.35, J1.36, J1.37
HP_MOS4_B: F4.2, J2.35, J2.36, J2.37
HP_MOS5: F5.1, J1.16, J1.17
HP_MOS5_B: F5.2, J2.16, J2.17
HP_MOS6: F6.1, J1.8, J1.9
HP_MOS6_B: F6.2, J2.8, J2.9
HP_MOS7: F7.1, J1.1, J1.3
HP_MOS7_B: F7.2, J2.1, J2.3
HP_MOS8: F8.1, J1.19, J1.20
HP_MOS8_B: F8.2, J2.19, J2.20
LP_MOS1: J1.34, J2.34
LP_MOS2: J1.15, J2.15
LP_MOS3: J1.13, J2.13
LP_MOS4: J1.11, J2.11
LP_MOS5: J1.7, J2.7
LP_MOS6: J1.5, J2.5
LP_MOS7: J1.2, J2.2
LP_MOS8: J1.18, J2.18
SAFETY_IN: J1.33, J2.33

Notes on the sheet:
Protected outs Max 1A


Board: 2 copper layers, 45.6 x 80.7 mm, 10 parts (1 on the bottom side), 41 nets.

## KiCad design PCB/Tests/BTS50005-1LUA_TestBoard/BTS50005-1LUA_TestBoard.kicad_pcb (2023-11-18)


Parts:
C1, C2: 10nF; C_0402_1005Metric
C3: 100nF; C_0805_2012Metric
C4: 100nF; C_0402_1005Metric
D1: BAT54SW; SOT-323_SC-70
H1, H2: MountingHole_Pad; MountingHole_6.5mm_Pad_Via
J1: Conn_01x06; Molex_Micro-Latch_53253-0670_1x06_P2.00mm_Vertical
Q1: BTS500101LUAAUMA1; Manufacturer_Part_Number BTS500101LUAAUMA1; Mouser Part Number 726-BTS500101LUAAUMA
R1, R3: 4.7k; R_0402_1005Metric
R2: 1k; R_0402_1005Metric
R4: 4k7; R_0402_1005Metric
R5: 75; R_0402_1005Metric
RT1: B57232V5103F360; THRMC1005X60N; Manufacturer_Part_Number B57232V5103F360; Mouser Part Number 871-B57232V5103F360
TP1: IN_TP; TestPoint_Keystone_5000-5004_Miniature
TP2: OUT_TP; TestPoint_Keystone_5000-5004_Miniature

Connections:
+12V: C3.1, H1.1, Q1.9 (VS), RT1.1
/DEN: Q1.4 (DEN), R3.1
/IN: Q1.3 (IN), R1.1
CONTOLLER_VDD: D1.2, J1.6
CONTROLER_DEN: J1.4, R3.2
CONTROLER_IN: J1.5, R1.2, TP1.1
CONTROLLER_ADC: C1.2, D1.3, J1.2, Q1.2 (IS), R2.2
CONTROLLER_TEMP: C4.1, J1.3, R4.2
GND: C1.1, C2.1, C3.2, C4.2, D1.1, J1.1, Q1.1 (GND_), R2.1, R5.2
unnamed: R4.1, R5.1, RT1.2
OUT: C2.2, H2.1, Q1.5 (OUT), TP2.1

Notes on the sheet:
BTS50010/05-1LUA Evaluation board
max 1%
Sense resistor accuracy important!



Board: 2 copper layers, 48.3 x 21.6 mm, 20 parts (5 on the bottom side), 11 nets.

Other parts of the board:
kibuzzard-65429BC2: G***; kibuzzard-65429BC2
kibuzzard-6542993B: G***; kibuzzard-6542993B
kibuzzard-65429977: G***; kibuzzard-65429977

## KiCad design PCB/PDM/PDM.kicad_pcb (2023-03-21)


Board: 2 copper layers, 294 parts (0 on the bottom side), 210 nets.

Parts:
C2: 4u7; C_0402_1005Metric_Pad0.74x0.62mm_HandSolder
C3, C7, C55, C56: 10pF; C_0402_1005Metric_Pad0.74x0.62mm_HandSolder
C4, C54: 1u; C_0402_1005Metric_Pad0.74x0.62mm_HandSolder
C5, C6, C8, C28, C29, C30, C31, C32, C33, C34, C35, C36, C37, C38, C39: 100n; C_0402_1005Metric_Pad0.74x0.62mm_HandSolder
C9, C50, C57, C65, C71, C77, C83, C89: 1uF; C_0805_2012Metric
C10, C11, C12, C19, C22, C51, C52, C53, C58, C59, C60, C66, C67, C68, C72, C73, C74, C78, C79, C80, C84, C85, C86, C90, C91, C92: 470nF; C_0805_2012Metric
C13, C96: 0,1mF; C_0805_2012Metric
C13#2, C20, C23, C49, C62, C64, C70, C76, C82, C88, C94, C95, C95#2, C96#2: 100nF; C_0805_2012Metric
C14, C15, C16, C17, C24, C25, C26, C27: 10nf; C_0805_2012Metric
C18, C21: 220pF; C_0402_1005Metric
C48, C61, C63, C69, C75, C81, C87, C93: 20uF; C_0805_2012Metric
D3, D6, D7, D8, D9, D10, D20, D21: BAT54BRW-7-F; SOT65P210X110-6N
D4, D5: 7V; D_0805_2012Metric
D11, D12, D13, D14, D15, D16, D17, D18, D19: WS2812B; LED_WS2812B-2020_PLCC4_2.0x2.0mm
F1, F2, F3, F4, F5, F6, F7, F8: 40A; Fuse_2512_6332Metric
IC1: STM32L496ZGT6; QFP50P2200X2200X160-144N
IC2: AT25SF128A-SHB-T; SOIC127P798X216-8N
IC3, IC3#2, IC9, IC9#2: SN65HVD230QDG4Q1; SOIC127P600X175-8N
IC4, IC4#2: TS5A21366DCUR; SOP50P310X90-8N
IC5, IC6: TMP126NDCKR; SOT65P210X110-6N
IC7, IC8: BTS722204ESAXUMA1; SOP65P600X115-25N
IC12, IC13: LM5050MK-1_NOPB; SOT95P280X110-6N
IC14: TLE9104SHXUMA1; SOP50P1030X260-21N
J2: 6473427-1; 64734271
J3: N01_036_6501_001; N010366501001
JP1: SolderJumper_3_Open; SolderJumper-3_P1.3mm_Open_RoundedPad1.0x1.5mm
Q1: MMBT3904; SOT-23
Q2, Q3: IAUA250N04S6N007AUMA1
Q4, Q5, Q6, Q7, Q8, Q9: STL135N8F7AG
Q10, Q11: STL225N6F7AG; POWERFLAT_5X6
R2: 1k; R_0402_1005Metric_Pad0.72x0.64mm_HandSolder
R3, R5, R6, R7, R8, R9, R11, R14, R20, R21, R22, R23, R31, R35, R36, R37, R38, R43, R44, R45, R46, R47, R48, R49, R50, R53, R54, R55, R56, R57, R64, R65, R66, R67, R70, R71, R73, R75, R76, R77, R78, R79, R82, R84, R85, R86, R87, R88, R91, R93, R94, R95, R96, R97, R100, R102, R103, R104, R105, R106, R109, R111, R112, R113, R114, R115: 1.2k; R_0402_1005Metric
R4, R13, R15, R24, R25, R26, R27, R30, R34, R39, R40, R41, R42, R62, R63, R68, R69, R74, R83, R92, R101, R110: 4.7k; R_0402_1005Metric
R10, R18, R19, R51, R58, R80, R89, R98, R107, R116: 10k; R_0402_1005Metric
R12, R52, R59, R81, R90, R99, R108, R117: 47k; R_0402_1005Metric
R16, R17, R17#2, R118: 120; R_0402_1005Metric
R16#2, R118#2, R119, R119#2: 0; R_0402_1005Metric
R28, R32: 47; R_0402_1005Metric
R29, R33: 470; R_0402_1005Metric
R72: 1k; R_0402_1005Metric
RS1, RS2, RS3, RS4, RS5, RS6, RS7, RS8: 1m; R_2512_6332Metric
RT1, RT2, RT3, RT4, RT5, RT6, RT7, RT8: B57232V5103F360; THRMC1005X60N
U1, U4, U5, U6, U7, U8, U9, U10: VNF1048FTR; QFN32L_5x5_STM
U2, U3: MCP2561-E-SN; SOIC-8_3.9x4.9mm_P1.27mm
Y1: 48Mhz; Crystal_SMD_5032-2Pin_5.0x3.2mm
Y2: 32KHz; Crystal_SMD_3215-2Pin_3.2x1.5mm

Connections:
12V_CONNECTOR: IC12.4 (IN), IC13.4 (IN), Q2.1 (S_1), Q2.2 (S_2), Q2.3 (S_3), Q2.4 (S_4), Q2.7 (S_5), Q3.1 (S_1), Q3.2 (S_2), Q3.3 (S_3), Q3.4 (S_4), Q3.7 (S_5)
+5V: D3.4, D3.5, D6.4, D6.5, D7.4, D7.5, D8.4, D8.5, D9.4, D9.5, D10.4, D10.5, D11.1 (VDD), D12.1 (VDD), D13.1 (VDD), D14.1 (VDD), D15.1 (VDD), D16.1 (VDD), D17.1 (VDD), D18.1 (VDD), D19.1 (VDD), D20.4, D20.5, D21.4, D21.5, IC14.16 (VDD), U2.3 (VDD), U3.3 (VDD)
+12V: C10.1, C48.1, C49.1, C51.1, C58.1, C61.1, C62.1, C63.1, C64.1, C66.1, C69.1, C70.1, C72.1, C75.1, C76.1, C78.1, C81.1, C82.1, C84.1, C87.1, C88.1, C90.1, C93.1, C94.1, IC12.6 (OUT), IC13.6 (OUT), Q2.6 (D), Q3.6 (D), RS1.1, RS2.1, RS3.1, RS4.1, RS5.1, RS6.1, RS7.1, RS8.1, U1.21 (ISNS_P), U1.25 (VS), U4.21 (ISNS_P), U4.25 (VS), U5.21 (ISNS_P), U5.25 (VS), U6.21 (ISNS_P), U6.25 (VS), U7.21 (ISNS_P), U7.25 (VS), U8.21 (ISNS_P), U8.25 (VS), U9.21 (ISNS_P), U9.25 (VS), U10.21 (ISNS_P), U10.25 (VS)
/BTS722204ESAXUMA1/ADC: C18.1, D4.2 (A2), R30.2
/BTS722204ESAXUMA1/OUT0: C14.1, IC7.21 (OUT0_1), IC7.22 (OUT0_2), IC7.23 (OUT0_3), IC7.24 (OUT0_4)
/BTS722204ESAXUMA1/OUT1: C15.1, IC7.19 (OUT1_1), IC7.20 (OUT1_2)
/BTS722204ESAXUMA1/OUT2: C16.1, IC7.17 (OUT2_1), IC7.18 (OUT2_2)
/BTS722204ESAXUMA1/OUT3: C17.1, IC7.13 (OUT3_1), IC7.14 (OUT3_2), IC7.15 (OUT3_3), IC7.16 (OUT3_4)
/BTS722204ESAXUMA1/VS: C20.2, IC7.25 (VS)
/BTS722204ESAXUMA2/ADC: C21.1, D5.2 (A2), R34.2
/BTS722204ESAXUMA2/OUT0: C24.1, IC8.21 (OUT0_1), IC8.22 (OUT0_2), IC8.23 (OUT0_3), IC8.24 (OUT0_4)
/BTS722204ESAXUMA2/OUT1: C25.1, IC8.19 (OUT1_1), IC8.20 (OUT1_2)
/BTS722204ESAXUMA2/OUT2: C26.1, IC8.17 (OUT2_1), IC8.18 (OUT2_2)
/BTS722204ESAXUMA2/OUT3: C27.1, IC8.13 (OUT3_1), IC8.14 (OUT3_2), IC8.15 (OUT3_3), IC8.16 (OUT3_4)
/BTS722204ESAXUMA2/VS: C23.2, IC8.25 (VS)
/HIGH SIDE1/CSN1: R11.1, R11.2, U4.2 (CSN)
/HIGH SIDE1/CSN2: R5.1, R5.2, U1.2 (CSN)
/HIGH SIDE1/CSN3: R53.1, R53.2, U5.2 (CSN)
/HIGH SIDE1/CSN4: R84.1, R84.2, U7.2 (CSN)
/HIGH SIDE1/CSN5: R75.1, R75.2, U6.2 (CSN)
/HIGH SIDE1/CSN6: R93.1, R93.2, U8.2 (CSN)
/HIGH SIDE1/CSN7: R111.1, R111.2, U10.2 (CSN)
/HIGH SIDE1/CSN8: R102.1, R102.2, U9.2 (CSN)
/HIGH SIDE1/VNF1048FTR1/MOS_GATE: Q4.4 (G), R12.2, U1.24 (HS_GATE)
/HIGH SIDE1/VNF1048FTR1/MOS_IN: Q4.5 (D_1), Q4.6 (D_2), Q4.7 (D_3), Q4.8 (D_4), Q4.9 (D_5), Q4.10 (D_6), Q4.11 (D_7), Q4.12 (D_8), Q4.13 (D_9), RS1.2, RT1.2, U1.20 (ISNS_N)
/HIGH SIDE1/VNF1048FTR1/MOS_OUT: F1.1, Q4.1 (S_1), Q4.2 (S_2), Q4.3 (S_3), R12.1, U1.23 (OUT)
/HIGH SIDE1/VNF1048FTR2/MOS_GATE: Q6.4 (G), R59.2, U5.24 (HS_GATE)
/HIGH SIDE1/VNF1048FTR2/MOS_IN: Q6.5 (D_1), Q6.6 (D_2), Q6.7 (D_3), Q6.8 (D_4), Q6.9 (D_5), Q6.10 (D_6), Q6.11 (D_7), Q6.12 (D_8), Q6.13 (D_9), RS3.2, RT3.2, U5.20 (ISNS_N)
/HIGH SIDE1/VNF1048FTR2/MOS_OUT: F3.1, Q6.1 (S_1), Q6.2 (S_2), Q6.3 (S_3), R59.1, U5.23 (OUT)
/HIGH SIDE1/VNF1048FTR3/MOS_GATE: Q7.4 (G), R90.2, U7.24 (HS_GATE)
/HIGH SIDE1/VNF1048FTR3/MOS_IN: Q7.5 (D_1), Q7.6 (D_2), Q7.7 (D_3), Q7.8 (D_4), Q7.9 (D_5), Q7.10 (D_6), Q7.11 (D_7), Q7.12 (D_8), Q7.13 (D_9), RS5.2, RT5.2, U7.20 (ISNS_N)
/HIGH SIDE1/VNF1048FTR3/MOS_OUT: F5.1, Q7.1 (S_1), Q7.2 (S_2), Q7.3 (S_3), R90.1, U7.23 (OUT)
/HIGH SIDE1/VNF1048FTR4/MOS_GATE: Q9.4 (G), R99.2, U8.24 (HS_GATE)
/HIGH SIDE1/VNF1048FTR4/MOS_IN: Q9.5 (D_1), Q9.6 (D_2), Q9.7 (D_3), Q9.8 (D_4), Q9.9 (D_5), Q9.10 (D_6), Q9.11 (D_7), Q9.12 (D_8), Q9.13 (D_9), RS6.2, RT6.2, U8.20 (ISNS_N)
/HIGH SIDE1/VNF1048FTR4/MOS_OUT: F6.1, Q9.1 (S_1), Q9.2 (S_2), Q9.3 (S_3), R99.1, U8.23 (OUT)
/HIGH SIDE1/VNF1048FTR5/MOS_GATE: Q8.4 (G), R81.2, U6.24 (HS_GATE)
/HIGH SIDE1/VNF1048FTR5/MOS_IN: Q8.5 (D_1), Q8.6 (D_2), Q8.7 (D_3), Q8.8 (D_4), Q8.9 (D_5), Q8.10 (D_6), Q8.11 (D_7), Q8.12 (D_8), Q8.13 (D_9), RS4.2, RT4.2, U6.20 (ISNS_N)
/HIGH SIDE1/VNF1048FTR5/MOS_OUT: F4.1, Q8.1 (S_1), Q8.2 (S_2), Q8.3 (S_3), R81.1, U6.23 (OUT)
/HIGH SIDE1/VNF1048FTR6/MOS_GATE: Q10.4 (G), R117.2, U10.24 (HS_GATE)
/HIGH SIDE1/VNF1048FTR6/MOS_IN: Q10.5 (D_1), Q10.6 (D_2), Q10.7 (D_3), Q10.8 (D_4), RS8.2, RT8.2, U10.20 (ISNS_N)
/HIGH SIDE1/VNF1048FTR6/MOS_OUT: F8.1, Q10.1 (S_1), Q10.2 (S_2), Q10.3 (S_3), R117.1, U10.23 (OUT)
/HIGH SIDE1/VNF1048FTR7/MOS_GATE: Q11.4 (G), R108.2, U9.24 (HS_GATE)
/HIGH SIDE1/VNF1048FTR7/MOS_IN: Q11.5 (D_1), Q11.6 (D_2), Q11.7 (D_3), Q11.8 (D_4), RS7.2, RT7.2, U9.20 (ISNS_N)
/HIGH SIDE1/VNF1048FTR7/MOS_OUT: F7.1, Q11.1 (S_1), Q11.2 (S_2), Q11.3 (S_3), R108.1, U9.23 (OUT)
/HIGH SIDE1/VNF1048FTR/MOS_GATE: Q5.4 (G), R52.2, U4.24 (HS_GATE)
/HIGH SIDE1/VNF1048FTR/MOS_IN: Q5.5 (D_1), Q5.6 (D_2), Q5.7 (D_3), Q5.8 (D_4), Q5.9 (D_5), Q5.10 (D_6), Q5.11 (D_7), Q5.12 (D_8), Q5.13 (D_9), RS2.2, RT2.2, U4.20 (ISNS_N)
/HIGH SIDE1/VNF1048FTR/MOS_OUT: F2.1, Q5.1 (S_1), Q5.2 (S_2), Q5.3 (S_3), R52.1, U4.23 (OUT)
/MCU/PWM_OUT1: D11.4 (DIN), IC1.136 (PB6)
/MCU/PWM_OUT2: IC1.135 (PB5), R72.1
BK1_IO0: IC1.65 (PE12), IC2.5 (SI(I/O0))
BK1_IO1: IC1.66 (PE13), IC2.2 (SO(I/O1))
BK1_IO2: IC1.67 (PE14), IC2.3 (~WP(I/O2))
BK1_IO3: IC1.68 (PE15), IC2.7 (~HOLD(I/O3))
BOOT0: IC1.138 (PH3-BOOT0), R2.1
CAN1_H: IC4.2 (COM1), IC4#2.2 (COM1), IC9.7 (CANH), IC9#2.7 (CANH), U2.7 (CANH)
CAN1_L: IC9.6 (CANL), IC9#2.6 (CANL), R16.1, R17.1, U2.6 (CANL)
CAN1_RX: IC1.139 (PB8), IC9.4 (R), IC9#2.4 (R), U2.4 (RXD)
CAN1_TX: IC1.140 (PB9), IC9.1 (D), IC9#2.1 (D), U2.1 (TXD)
CAN2_H: IC3.7 (CANH), IC3#2.7 (CANH), IC4.6 (COM2), IC4#2.6 (COM2), U3.7 (CANH)
CAN2_L: IC3.6 (CANL), IC3#2.6 (CANL), R17#2.1, R118.1, U3.6 (CANL)
CAN2_RX: IC1.73 (PB12), IC3.4 (R), IC3#2.4 (R), U3.4 (RXD)
CAN2_TX: IC1.74 (PB13), IC3.1 (D), IC3#2.1 (D), U3.1 (TXD)
CAN_TERMINATOR_1: IC4.7 (IN1), IC4#2.7 (IN1)
CAN_TERMINATOR_2: IC4.3 (IN2), IC4#2.3 (IN2)
CLK: IC1.63 (PE10), IC2.6 (SCK)
GND: C2.2, C3.2, C4.2, C5.2, C6.2, C7.2, C8.2, C9.1, C13.1, C13#2.1, C14.2, C15.2, C16.2, C17.2, C18.2, C20.1, C21.2, C23.1, C24.2, C25.2, C26.2, C27.2, C28.2, C29.2, C30.2, C31.2, C32.2, C33.2, C34.2, C35.2, C36.2, C37.2, C38.2, C39.2, C48.2, C49.2, C50.1, C54.2, C55.2, C56.2, C57.1, C61.2, C62.2, C63.2, C64.2, C65.1, C69.2, C70.2, C71.1, C75.2, C76.2, C77.1, C81.2, C82.2, C83.1, C87.2, C88.2, C89.1, C93.2, C94.2, C95.1, C95#2.1, C96.1, C96#2.1, D3.1, D3.2, D4.1 (A1), D5.1 (A1), D6.1, D6.2, D7.1, D7.2, D8.1, D8.2, D9.1, D9.2, D10.1, D10.2, D11.3 (VSS), D12.3 (VSS), D13.3 (VSS), D14.3 (VSS), D15.3 (VSS), D16.3 (VSS), D17.3 (VSS), D18.3 (VSS), D19.3 (VSS), D20.1, D20.2, D21.1, D21.2, IC1.16 (VSS_1), IC1.30 (VSSA), IC1.31 (VREF-), IC1.38 (VSS_2), IC1.51 (VSS_3), IC1.61 (VSS_4), IC1.71 (VSS_5), IC1.83 (VSS_6), IC1.94 (VSS_7), IC1.107 (VSS_8), IC1.120 (VSS_9), IC1.130 (VSS_10), IC1.143 (VSS_11), IC2.4 (GND), IC3.2 (GND), IC3#2.2 (GND), IC4.4 (GND), IC4#2.4 (GND), IC5.2 (GND), IC6.2 (GND), IC7.1 (GND_1), IC8.1 (GND_1), IC9.2 (GND), IC9#2.2 (GND), IC12.2 (GND), IC13.2 (GND), IC14.2 (GND_1), IC14.9 (GND_2), IC14.12 (GND_3), IC14.19 (GND_4), IC14.21 (EP), JP1.1 (A), Q1.2 (E), R16#2.1, R28.2, R31.2, R32.2, R43.2, R44.2, R45.2, R118#2.1, R119.1, R119#2.1, U1.7 (TEST1), U1.8 (TEST2), U1.13 (GND), U2.2 (VSS), U2.8 (STBY), U3.2 (VSS), U3.8 (STBY), U4.7 (TEST1), U4.8 (TEST2), U4.13 (GND), U5.7 (TEST1), U5.8 (TEST2), U5.13 (GND), U6.7 (TEST1), U6.8 (TEST2), U6.13 (GND), U7.7 (TEST1), U7.8 (TEST2), U7.13 (GND), U8.7 (TEST1), U8.8 (TEST2), U8.13 (GND), U9.7 (TEST1), U9.8 (TEST2), U9.13 (GND), U10.7 (TEST1), U10.8 (TEST2), U10.13 (GND)
MISO: IC1.88 (PG3), IC1.112 (PC11), IC1.117 (PD3), R7.1, R7.2, R47.1, R47.2, R55.1, R55.2, R77.1, R77.2, R86.1, R86.2, R95.1, R95.2, R104.1, R104.2, R113.1, R113.2, U1.4 (SDO), U4.4 (SDO), U5.4 (SDO), U6.4 (SDO), U7.4 (SDO), U8.4 (SDO), U9.4 (SDO), U10.4 (SDO)
MOSI: IC1.89 (PG4), IC1.113 (PC12), IC1.118 (PD4), R6.1, R6.2, R46.1, R46.2, R54.1, R54.2, R76.1, R76.2, R85.1, R85.2, R94.1, R94.2, R103.1, R103.2, R112.1, R112.2, U1.3 (SDI), U4.3 (SDI), U5.3 (SDI), U6.3 (SDI), U7.3 (SDI), U8.3 (SDI), U9.3 (SDI), U10.3 (SDI)
NCS: IC1.64 (PE11), IC2.1 (~CS)
unnamed: C9.2, U1.12 (V3V3)
unnamed: C10.2, U1.27 (CP)
unnamed: C11.1, U1.31 (CP1M)
unnamed: C11.2, U1.30 (CP1P)
unnamed: C12.1, U1.29 (CP2M)
unnamed: C12.2, U1.28 (CP2P)
unnamed: C19.1, R28.1
unnamed: C19.2, IC7.2 (VDD), R29.1
unnamed: C22.1, R32.1
unnamed: C22.2, IC8.2 (VDD), R33.1
unnamed: C50.2, U5.12 (V3V3)
unnamed: C51.2, U5.27 (CP)
unnamed: C52.1, U5.31 (CP1M)
unnamed: C52.2, U5.30 (CP1P)
unnamed: C53.1, U5.29 (CP2M)
unnamed: C53.2, U5.28 (CP2P)
unnamed: C57.2, U4.12 (V3V3)
unnamed: C58.2, U4.27 (CP)
unnamed: C59.1, U4.31 (CP1M)
unnamed: C59.2, U4.30 (CP1P)
unnamed: C60.1, U4.29 (CP2M)
unnamed: C60.2, U4.28 (CP2P)
unnamed: C65.2, U6.12 (V3V3)
unnamed: C66.2, U6.27 (CP)
unnamed: C67.1, U6.31 (CP1M)
unnamed: C67.2, U6.30 (CP1P)
unnamed: C68.1, U6.29 (CP2M)
unnamed: C68.2, U6.28 (CP2P)
unnamed: C71.2, U7.12 (V3V3)
unnamed: C72.2, U7.27 (CP)
unnamed: C73.1, U7.31 (CP1M)
unnamed: C73.2, U7.30 (CP1P)
unnamed: C74.1, U7.29 (CP2M)
unnamed: C74.2, U7.28 (CP2P)
unnamed: C77.2, U8.12 (V3V3)
unnamed: C78.2, U8.27 (CP)
unnamed: C79.1, U8.31 (CP1M)
unnamed: C79.2, U8.30 (CP1P)
unnamed: C80.1, U8.29 (CP2M)
unnamed: C80.2, U8.28 (CP2P)
unnamed: C83.2, U9.12 (V3V3)
unnamed: C84.2, U9.27 (CP)
unnamed: C85.1, U9.31 (CP1M)
unnamed: C85.2, U9.30 (CP1P)
unnamed: C86.1, U9.29 (CP2M)
unnamed: C86.2, U9.28 (CP2P)
unnamed: C89.2, U10.12 (V3V3)
unnamed: C90.2, U10.27 (CP)
unnamed: C91.1, U10.31 (CP1M)
unnamed: C91.2, U10.30 (CP1P)
unnamed: C92.1, U10.29 (CP2M)
unnamed: C92.2, U10.28 (CP2P)
unnamed: D11.2 (DOUT), D12.4 (DIN)
unnamed: D12.2 (DOUT), D13.4 (DIN)
unnamed: D13.2 (DOUT), D14.4 (DIN)
unnamed: D14.2 (DOUT), D15.4 (DIN)
unnamed: D15.2 (DOUT), D16.4 (DIN)
unnamed: D16.2 (DOUT), D17.4 (DIN)
unnamed: D17.2 (DOUT), D18.4 (DIN)
unnamed: D18.2 (DOUT), D19.4 (DIN)
unnamed: IC3.8 (RS), IC3#2.8 (RS), R16#2.2, R118#2.2
unnamed: IC4.1 (NO1), IC4#2.1 (NO1), R16.2, R17.2
unnamed: IC4.5 (NO2), IC4#2.5 (NO2), R17#2.2, R118.2
unnamed: IC7.3 (SO), R20.1
unnamed: IC7.4 (SI), R21.1
unnamed: IC7.5 (SCLK), R22.1
unnamed: IC7.6 (CSN), R23.1
unnamed: IC7.7 (LHI), R44.1
unnamed: IC7.8 (IN0), R24.2
unnamed: IC7.9 (IN1), R25.2
unnamed: IC7.10 (IN2), R26.2
unnamed: IC7.11 (IN3), R27.2
unnamed: IC7.12 (IS), R30.1, R31.1
unnamed: IC8.3 (SO), R35.1
unnamed: IC8.4 (SI), R36.1
unnamed: IC8.5 (SCLK), R37.1
unnamed: IC8.6 (CSN), R38.1
unnamed: IC8.7 (LHI), R45.1
unnamed: IC8.8 (IN0), R39.2
unnamed: IC8.9 (IN1), R40.2
unnamed: IC8.10 (IN2), R41.2
unnamed: IC8.11 (IN3), R42.2
unnamed: IC8.12 (IS), R34.1, R43.1
unnamed: IC9.8 (RS), IC9#2.8 (RS), R119.2, R119#2.2
unnamed: IC12.5 (GATE), Q2.5 (G)
unnamed: IC13.5 (GATE), Q3.5 (G)
unnamed: IC14.3 (IN1), R62.2
unnamed: IC14.4 (IN3), R63.2
unnamed: IC14.5 (SO), R64.2
unnamed: IC14.6 (SI), R65.2
unnamed: IC14.7 (CSN), R66.2
unnamed: IC14.8 (SCK), R67.1
unnamed: IC14.13 (RESN), R71.1
unnamed: IC14.14 (EN), R70.1
unnamed: IC14.17 (IN4), R69.2
unnamed: IC14.18 (IN2), R68.2
unnamed: JP1.2 (C), R2.2
unnamed: Q1.1 (B), R72.2
unnamed: R3.1, R4.1, U1.6 (DIAG)
unnamed: R9.1, U1.10 (HWLO)
unnamed: R10.1, RT1.1, U1.19 (NTC)
unnamed: R10.2, U1.18 (NTC_M)
unnamed: R13.1, R49.1, U4.6 (DIAG)
unnamed: R14.1, R15.1, U5.6 (DIAG)
unnamed: R50.1, U4.10 (HWLO)
unnamed: R51.1, RT2.1, U4.19 (NTC)
unnamed: R51.2, U4.18 (NTC_M)
unnamed: R57.1, U5.10 (HWLO)
unnamed: R58.1, RT3.1, U5.19 (NTC)
unnamed: R58.2, U5.18 (NTC_M)
unnamed: R73.1, R74.1, U6.6 (DIAG)
unnamed: R79.1, U6.10 (HWLO)
unnamed: R80.1, RT4.1, U6.19 (NTC)
unnamed: R80.2, U6.18 (NTC_M)
unnamed: R82.1, R83.1, U7.6 (DIAG)
unnamed: R88.1, U7.10 (HWLO)
unnamed: R89.1, RT5.1, U7.19 (NTC)
unnamed: R89.2, U7.18 (NTC_M)
unnamed: R91.1, R92.1, U8.6 (DIAG)
unnamed: R97.1, U8.10 (HWLO)
unnamed: R98.1, RT6.1, U8.19 (NTC)
unnamed: R98.2, U8.18 (NTC_M)
unnamed: R100.1, R101.1, U9.6 (DIAG)
unnamed: R106.1, U9.10 (HWLO)
unnamed: R107.1, RT7.1, U9.19 (NTC)
unnamed: R107.2, U9.18 (NTC_M)
unnamed: R109.1, R110.1, U10.6 (DIAG)
unnamed: R115.1, U10.10 (HWLO)
unnamed: R116.1, RT8.1, U10.19 (NTC)
unnamed: R116.2, U10.18 (NTC_M)
OSC32_IN: C55.1, IC1.8 (PC14-OSC32_IN), Y2.1
OSC32_OUT: C56.1, IC1.9 (PC15-OSC32_OUT), Y2.2
OSC_IN: C3.1, IC1.23 (PH0-OSC_IN), Y1.1
OSC_OUT: C7.1, IC1.24 (PH1-OSC_OUT), Y1.2
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

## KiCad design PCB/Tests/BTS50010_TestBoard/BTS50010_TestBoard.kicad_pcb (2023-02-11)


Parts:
C1: 150nF; C_0805_2012Metric_Pad1.18x1.45mm_HandSolder
C2: C_Small; C_0805_2012Metric_Pad1.18x1.45mm_HandSolder
C3: 10nF; C_0805_2012Metric_Pad1.18x1.45mm_HandSolder
D1: D_TVS; D_SMA
H1: IN_VS; MountingHole_3.2mm_M3_ISO7380_Pad_TopBottom
H2: OUT_VS; MountingHole_3.2mm_M3_ISO7380_Pad_TopBottom
J1: Conn_01x04_Male; PinHeader_1x04_P2.54mm_Vertical
R1: 1k; R_0805_2012Metric_Pad1.20x1.40mm_HandSolder
R2: 4.7k; R_0805_2012Metric_Pad1.20x1.40mm_HandSolder
U1: BTS50010-1TAE; TO127P1500X440-8N; PARTREV 1.0

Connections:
AUX_IN: C1.1, J1.3, U1.2 (IN)
GND: C1.2, C2.1, C3.1, D1.2 (A2), J1.4, R1.2, U1.1 (GND)
IN_VS: C2.2, D1.1 (A1), H1.1, U1.8 (VS)
unnamed: R1.1, R2.2, U1.3 (IS)
OUT_VS: C3.2, H2.1, J1.1, U1.5 (OUT), U1.6 (OUT), U1.7 (OUT)
SENSE: J1.2, R2.1


Board: 2 copper layers, 37.1 x 21.6 mm, 10 parts (0 on the bottom side), 6 nets.

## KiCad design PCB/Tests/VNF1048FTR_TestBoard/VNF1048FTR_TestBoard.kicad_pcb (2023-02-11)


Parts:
J1: Conn_01x06_Female; PinSocket_1x06_P2.54mm_Vertical
J2, J3: Conn_01x01_Female; SolderWire-2sqmm_1x01_D2mm_OD3.9mm
J4: Conn_01x02_Female; PinSocket_1x02_P2.54mm_Vertical
Q1: STL135N8F7AG; Manufacturer_Part_Number STL135N8F7AG; Mouser Part Number 511-STL135N8F7AG

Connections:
+3.3V: J4.2; also elsewhere on the board
+12V: J3.1; also elsewhere on the board
/VNF1048FTR/CSN: J1.6; also elsewhere on the board
/VNF1048FTR/DIAG: J1.1; also elsewhere on the board
/VNF1048FTR/HWLO: J1.2; also elsewhere on the board
/VNF1048FTR/MOS_GATE: Q1.4 (G); also elsewhere on the board
/VNF1048FTR/MOS_IN: Q1.5 (D_1), Q1.6 (D_2), Q1.7 (D_3), Q1.8 (D_4), Q1.9 (D_5), Q1.10 (D_6), Q1.11 (D_7), Q1.12 (D_8), Q1.13 (D_9); also elsewhere on the board
/VNF1048FTR/SCK: J1.3; also elsewhere on the board
/VNF1048FTR/SDI: J1.5; also elsewhere on the board
/VNF1048FTR/SDO: J1.4; also elsewhere on the board
GND: J4.1; also elsewhere on the board
MOS_OUTPUT12V: J2.1, Q1.1 (S_1), Q1.2 (S_2), Q1.3 (S_3); also elsewhere on the board

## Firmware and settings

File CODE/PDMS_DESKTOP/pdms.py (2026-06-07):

import multiprocessing
import time
import sys
from pathlib import Path

from PyQt5.QtCore import QTimer, Qt
from PyQt5.QtGui import QColor, QIcon, QKeySequence, QPixmap
from PyQt5.QtWidgets import QSplashScreen
from PyQt5.QtWidgets import (
    QApplication,
    QComboBox,
    QGridLayout,
    QGroupBox,
    QHeaderView,
    QHBoxLayout,
    QLabel,
    QLineEdit,
    QMainWindow,
    QMessageBox,
    QPushButton,
    QTabWidget,
    QTableWidget,
    QTableWidgetItem,
    QShortcut,
    QVBoxLayout,
    QWidget,
)

from pdm_can_worker import can_isolated_process
from pdm_config_tab import ConfigTab
from pdm_plot_tab import PlotPanel
from pdm_shared import (
    CHANNEL_COUNT,
    build_dark_stylesheet,
    CAN_CHANNEL,
    GUI_UPDATE_MS,
    IDS,
    OUT_STATE_MAP,
    OUT_STATUS_MAP,
    PHY_INPUT_COUNT,
    PLOT_UPDATE_MS,
    get_row_colors,
    get_asset_path,
)

import ctypes
# Tells Windows to treat the script as a distinct application rather than a Python script
myappid = 'mycompany.myproduct.subproduct.version' 
ctypes.windll.shell32.SetCurrentProcessExplicitAppUserModelID(myappid)

CHECKBOX_TICK_PATH = get_asset_path("assets/checkbox-tick.svg")

class MainWindow(QMainWindow):
    def __init__(self):
        super().__init__()
        self.setWindowTitle("PDMS Control App")
        self.resize(1920, 1280)

        self.pipe_ui, self.pipe_worker = multiprocessing.Pipe(duplex=False)
        self.tx_queue = multiprocessing.Queue()

        self.worker_process = None
        self.worker_started = False
        self.serial_device_ready = False
        self.last_frame_rx_time = 0.0

        self.latest_sys = {"status": 0, "batt": 0, "core_temp": 0.0, "safety": 0, "total_current": 0}
        self.latest_ch = [
            {"name": "", "status": 0, "state": 0, "voltage": 0, "current": 0, "current_avg": 0}
            for _ in range(CHANNEL_COUNT)
        ]
        self.latest_phy = [0] * PHY_INPUT_COUNT
        self.latest_frames = []
        self.plotting_enabled = True
        self.config_tab = None

        self.init_ui()

        self.plot_toggle_shortcut = QShortcut(QKeySequence("Ctrl+Space"), self)
        self.plot_toggle_shortcut.activated.connect(self.toggle_plotting)

        self.gui_timer = QTimer(self)
        self.gui_timer.timeout.connect(self.process_gui_refresh)
        self.gui_timer.start(GUI_UPDATE_MS)

        self.plot_timer = QTimer(self)
        self.plot_timer.timeout.connect(self.update_plots)
        self.plot_timer.start(PLOT_UPDATE_MS)

        self.hb_timer = QTimer(self)
        self.hb_timer.timeout.connect(self.update_heartbeat_status)
        self.hb_timer.start(200)

        QTimer.singleShot(0, self.start_can_worker)

    def start_can_worker(self):
        if self.worker_started:
            return
        self.serial_device_ready = False
        self.worker_process = multiprocessing.Process(
            target=can_isolated_process, args=(self.pipe_worker, self.tx_queue), daemon=True
        )
        self.worker_process.start()
        self.worker_started = True

    def init_ui(self):
        tabs = QTabWidget()
        self.setCentralWidget(tabs)

        dashboard = QWidget()
        dashboard_layout = QVBoxLayout(dashboard)

        top_panel = QHBoxLayout()
        dashboard_layout.addLayout(top_panel)

        sys_box = QGroupBox("System Overview")
        sys_grid = QGridLayout(sys_box)
        sys_grid.addWidget(QLabel("State:"), 0, 0)
        self.lbl_sys_state = QLabel("-")
        sys_grid.addWidget(self.lbl_sys_state, 0, 1)
        sys_grid.addWidget(QLabel("Battery:"), 1, 0)
        self.lbl_batt = QLabel("- mV")
        sys_grid.addWidget(self.lbl_batt, 1, 1)
        sys_grid.addWidget(QLabel("Device temp:"), 2, 0)
        self.lbl_temp = QLabel("- °C")
        sys_grid.addWidget(self.lbl_temp, 2, 1)
        sys_grid.addWidget(QLabel("Safety Line:"), 3, 0)
        self.lbl_safety = QLabel("-")
        sys_grid.addWidget(self.lbl_safety, 3, 1)
        sys_grid.addWidget(QLabel("Total I Avg:"), 4, 0)
        self.lbl_total_i = QLabel("- mA")
        sys_grid.addWidget(self.lbl_total_i, 4, 1)
        sys_grid.addWidget(QLabel("Invalid logic:"), 5, 0)
        self.lbl_logic_valid_mask = QLabel("-")
        self.lbl_logic_valid_mask.setWordWrap(True)
        sys_grid.addWidget(self.lbl_logic_valid_mask, 5, 1)
        top_panel.addWidget(sys_box, stretch=2)

        tx_box = QGroupBox("Send CAN Frame")
        tx_layout = QGridLayout(tx_box)
        self.combo_tx_id = QComboBox()
        self.combo_tx_id.setEditable(True)
        for name, cid in IDS.items():
            self.combo_tx_id.addItem(f"{name} (0x{cid:03X})", cid)
        self.combo_tx_id.setCurrentText("SYS_STATUS (0x401)")
        tx_layout.addWidget(self.combo_tx_id, 0, 0, 1, 2)
        tx_layout.addWidget(QLabel("Data (hex):"), 1, 0)
        self.entry_tx_data = QLineEdit("00 00 00 00 00 00 00 00")
        tx_layout.addWidget(self.entry_tx_data, 1, 1)
        btn_send = QPushButton("Transmit Frame")
        btn_send.clicked.connect(self.send_selected_frame)
        tx_layout.addWidget(btn_send, 2, 0, 1, 2)
        top_panel.addWidget(tx_box, stretch=2)

        tables_layout = QHBoxLayout()
        dashboard_layout.addLayout(tables_layout, stretch=2)

        out_table_box = QGroupBox("PDM Output Channel Bus Matrix")
        out_table_vbox = QVBoxLayout(out_table_box)
        self.table_channels = QTableWidget(CHANNEL_COUNT, 6)
        self.table_channels.setHorizontalHeaderLabels(["Name", "Status", "State", "V [mV]", "I inst [mA]", "I avg [mA]"])
        self.table_channels.horizontalHeader().setSectionResizeMode(QHeaderView.Stretch)
        for row in range(CHANNEL_COUNT):
            for col in range(6):
                item = QTableWidgetItem("")
                if col > 2:
                    item.setTextAlignment(Qt.AlignRight | Qt.AlignVCenter)
                self.table_channels.setItem(row, col, item)
        out_table_vbox.addWidget(self.table_channels)
        tables_layout.addWidget(out_table_box, stretch=5)

        phy_table_box = QGroupBox("Device Physical Inputs")
        phy_table_vbox = QVBoxLayout(phy_table_box)
        self.table_phy = QTableWidget(PHY_INPUT_COUNT, 2)
        self.table_phy.setHorizontalHeaderLabels(["Input Line", "Input voltage [mV]"])
        self.table_phy.horizontalHeader().setSectionResizeMode(QHeaderView.ResizeToContents)
        self.table_phy.horizontalHeader().setStretchLastSection(True)
        for row in range(PHY_INPUT_COUNT):
            self.table_phy.setItem(row, 0, QTableWidgetItem(f"Physical Input {row + 1}"))
            num_item = QTableWidgetItem("0")
            num_item.setTextAlignment(Qt.AlignRight | Qt.AlignVCenter)
            self.table_phy.setItem(row, 1, num_item)
        phy_table_vbox.addWidget(self.table_phy)
        tables_layout.addWidget(phy_table_box, stretch=2)

        frames_box = QGroupBox("Received CAN Frames")
        frames_vbox = QVBoxLayout(frames_box)
        self.table_frames = QTableWidget(0, 2)
        self.table_frames.setHorizontalHeaderLabels(["Frame ID", "Frequency [Hz]"])
        self.table_frames.horizontalHeader().setSectionResizeMode(QHeaderView.Stretch)
        frames_vbox.addWidget(self.table_frames)
        tables_layout.addWidget(frames_box, stretch=2)

        self.plot_panel = PlotPanel()
        dashboard_layout.addWidget(self.plot_panel, stretch=3)

        tabs.addTab(dashboard, "Dashboard")
        self.config_tab = ConfigTab()
        self.config_tab.send_binary_requested.connect(self.send_isotp_config)
        self.config_tab.send_reset_requested.connect(self.send_reset_device)
        self.config_tab.request_config_requested.connect(self.request_config_from_device)
        self.config_tab.can_frames_changed.connect(self._refresh_tx_frame_options)
        tabs.addTab(self.config_tab, "Configuration")
        self._refresh_tx_frame_options(self.config_tab.get_defined_can_frame_options())

        hb_corner = QWidget()
        hb_corner_layout = QHBoxLayout(hb_corner)
        hb_corner_layout.setContentsMargins(8, 0, 8, 0)
        hb_corner_layout.setSpacing(6)
        hb_corner_layout.addStretch(1)
        self.lbl_hb_dot = QLabel("●")
        self.lbl_hb_dot.setStyleSheet("color: #FF8A80; font-size: 14px; font-weight: bold;")
        self.lbl_hb_status = QLabel("Disconnected")
        self.lbl_hb_status.setStyleSheet("color: #FF8A80; font-weight: bold;")
        hb_corner_layout.addWidget(self.lbl_hb_dot)
        hb_corner_layout.addWidget(self.lbl_hb_status)
        tabs.setCornerWidget(hb_corner, Qt.TopRightCorner)

    def _set_heartbeat_status(self, text, color_hex):
        self.lbl_hb_status.setText(text)
        self.lbl_hb_status.setStyleSheet(f"color: {color_hex}; font-weight: bold;")
        self.lbl_hb_dot.setStyleSheet(f"color: {color_hex}; font-size: 14px; font-weight: bold;")

    def _refresh_tx_frame_options(self, options):
        current_data = self.combo_tx_id.currentData()
        current_text = self.combo_tx_id.currentText()

        self.combo_tx_id.blockSignals(True)
        self.combo_tx_id.clear()

        if options:
            for label, can_id in options:
                self.combo_tx_id.addItem(label, can_id)
        else:
            for name, cid in IDS.items():
                self.combo_tx_id.addItem(f"{name} (0x{cid:03X})", cid)

        restored = False
        if current_data is not None:
            idx = self.combo_tx_id.findData(current_data)
            if idx >= 0:
                self.combo_tx_id.setCurrentIndex(idx)
                restored = True

        if not restored and current_text:
            idx = self.combo_tx_id.findText(current_text)
            if idx >= 0:
                self.combo_tx_id.setCurrentIndex(idx)
                restored = True

        if not restored and self.combo_tx_id.count() > 0:
            self.combo_tx_id.setCurrentIndex(0)

        self.combo_tx_id.blockSignals(False)

    def send_isotp_config(self, payload):
        self.tx_queue.put({"cmd": "ISOTP_SEND", "id": 0x450, "payload": payload})

    def send_reset_device(self):
        self.tx_queue.put({"cmd": "RESET_DEVICE"})

    def request_config_from_device(self):
        self.tx_queue.put({"cmd": "REQUEST_CONFIG"})

    def send_selected_frame(self):
        tx_id_text = self.combo_tx_id.currentText()
        try:
            current_data = self.combo_tx_id.currentData()
            if current_data is not None:
                arbitration_id = int(current_data)
            else:
                cleaned = tx_id_text.split(" (")[0]
                arbitration_id = IDS[cleaned] if cleaned in IDS else int(cleaned, 0)
        except Exception:
            QMessageBox.critical(self, "CAN Field Error", "Invalid Target Arbitration Identifier")
            return

        try:
            payload = bytes(int(x, 16) for x in self.entry_tx_data.text().replace(",", " ").split())
        except Exception as exc:
            QMessageBox.critical(self, "Payload Hex Parse Error", f"Failed parsing byte context: {exc}")
            return

        self.tx_queue.put({"cmd": "TX", "id": arbitration_id, "payload": payload})

    def process_gui_refresh(self):
        updated = False
        while self.pipe_ui.poll():
            try:
                packet = self.pipe_ui.recv()
                if "isotp_progress" in packet:
                    if self.config_tab is not None:
                        self.config_tab.set_isotp_state(
                            packet.get("isotp_progress", 0),
                            packet.get("isotp_status", ""),
                            busy=not packet.get("isotp_done", False),
                        )
                        if packet.get("isotp_error"):
                            self.config_tab.set_isotp_state(0, f"Error: {packet['isotp_error']}", busy=False)
                    continue
                if "isotp_config_payload" in packet:
                    if self.config_tab is not None:
                        self.config_tab.load_binary_payload(packet["isotp_config_payload"])
                        self.config_tab.set_isotp_state(100, "Config received and loaded", busy=False)
                    continue
                if packet.get("serial_ready"):
                    self.serial_device_ready = True
                    continue
                if "error" in packet:
                    if self.config_tab is not None:
                        self.config_tab.set_isotp_state(0, f"Error: {packet['error']}", busy=False)
                    continue

                self.latest_sys = packet["sys"]
                self.latest_ch = packet["ch"]
                self.latest_phy = packet["phy"]
                self.latest_frames = packet.get("frames", [])
                self.plot_panel.update_from_packet(packet)
                self.last_frame_rx_time = time.time()
                updated = True
            except Exception:
                break

        if not updated:
            return

        self.lbl_sys_state.setText(str(self.latest_sys["status"]))
        self.lbl_batt.setText(f"{self.latest_sys['batt']} mV")
        self.lbl_temp.setText(f"{self.latest_sys['core_temp']:.1f} °C")
        self.lbl_safety.setText(str(self.latest_sys["safety"]))
        self.lbl_total_i.setText(f"{self.latest_sys['total_current']:.1f} mA")
        logic_valid_mask = int(self.latest_sys.get("logicValidMask", 0))
        invalid_outputs = [str(index + 1) for index in range(CHANNEL_COUNT) if not (logic_valid_mask & (1 << index))]
        if invalid_outputs:
            self.lbl_logic_valid_mask.setText(", ".join(invalid_outputs))
            self.lbl_logic_valid_mask.setStyleSheet("color: #FF8A80; font-weight: bold;")
        else:
            self.lbl_logic_valid_mask.setText("None")
            self.lbl_logic_valid_mask.setStyleSheet("")

        for i, ch in enumerate(self.latest_ch):
            bg_hex, text_hex = get_row_colors(ch["state"], ch["status"])
            status_str = OUT_STATUS_MAP.get(ch["status"], str(ch["status"]))
            state_str = OUT_STATE_MAP.get(ch["state"], str(ch["state"]))
            vals = (ch["name"], status_str, state_str, str(ch["voltage"]), str(ch["current"]), f"{ch['current_avg']:.1f}")

            for col_idx, text in enumerate(vals):
                item = self.table_channels.item(i, col_idx)
                if item.text() != text:
                    item.setText(text)
                item.setBackground(QColor(bg_hex))
                item.setForeground(QColor(text_hex))

        self.plot_panel.apply_channel_names([ch["name"] for ch in self.latest_ch])

        for i, val in enumerate(self.latest_phy):
            item = self.table_phy.item(i, 1)
            if item.text() != str(val):
                item.setText(str(val))

        self.table_frames.setRowCount(len(self.latest_frames))
        for row, frame in enumerate(self.latest_frames):
            fid_text = f"0x{frame['id']:03X}"
            freq_text = f"{frame['freq']:.1f}"
            id_item = self.table_frames.item(row, 0)
            if id_item is None:
                id_item = QTableWidgetItem()
                self.table_frames.setItem(row, 0, id_item)
            if id_item.text() != fid_text:
                id_item.setText(fid_text)

            freq_item = self.table_frames.item(row, 1)
            if freq_item is None:
                freq_item = QTableWidgetItem()
                freq_item.setTextAlignment(Qt.AlignRight | Qt.AlignVCenter)
                self.table_frames.setItem(row, 1, freq_item)
            if freq_item.text() != freq_text:
                freq_item.setText(freq_text)

        self.update_heartbeat_status()

    def update_heartbeat_status(self):
        worker_alive = self.worker_process is not None and self.worker_process.is_alive()

        if not worker_alive:
            self._set_heartbeat_status("Disconnected", "#FF8A80")
            return

        if not self.serial_device_ready:
            self._set_heartbeat_status("Disconnected", "#FF8A80")
            return

        if self.last_frame_rx_time <= 0:
            self._set_heartbeat_status(f"Serial ready: {CAN_CHANNEL}", "#FFD54F")
            return

        age_s = time.time() - self.last_frame_rx_time
        if age_s > 1.0:
            self._set_heartbeat_status(f"Serial ready: {CAN_CHANNEL}", "#FFD54F")
        else:
            self._set_heartbeat_status(f"Connected ({age_s:.1f}s)", "#81C784")

    def update_plots(self):
        if not self.plotting_enabled:
            return
        self.plot_panel.refresh_plots()

    def toggle_plotting(self):
        self.plotting_enabled = not self.plotting_enabled
        if self.plotting_enabled:
            self.plot_timer.start(PLOT_UPDATE_MS)
        else:
            self.plot_timer.stop()

    def closeEvent(self, event):
        if self.worker_started:
            self.tx_queue.put({"cmd": "EXIT"})
            self.worker_process.join(timeout=0.5)
        super().closeEvent(event)


if __name__ == "__main__":
    multiprocessing.freeze_support()
    app = QApplication(sys.argv)
    app.setStyleSheet(build_dark_stylesheet(CHECKBOX_TICK_PATH))
    app.setWindowIcon(QIcon(get_asset_path("assets/pdms.ico")))
    # Show a splash/loading screen during application bring-up
    splash_pix_path = get_asset_path("assets/pdms_splash.png")
    if Path(splash_pix_path).exists():
        pix = QPixmap(splash_pix_path)
    else:
        # Fallback: small blank pixmap with icon if no splash image available
        pix = QPixmap(480, 300)
        pix.fill(QColor('#2D2D2D'))

    splash = QSplashScreen(pix)
    splash.showMessage("Loading PDMS...", Qt.AlignBottom | Qt.AlignHCenter, QColor("#FFFFFF"))
    splash.show()
    app.processEvents()

    window = MainWindow()
    window.show()

    # Finish the splash after the main window is visible (short delay to let init finish)
    QTimer.singleShot(600, lambda: splash.finish(window))

    sys.exit(app.exec_())

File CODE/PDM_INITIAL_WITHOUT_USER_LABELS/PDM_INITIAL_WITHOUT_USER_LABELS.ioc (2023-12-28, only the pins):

Mcu.UserName=STM32L496ZGTx
PA0.Signal=ADCx_IN5
PA1.Signal=ADCx_IN6
PA10.Signal=S_TIM1_CH3
PA11.Signal=USB_OTG_FS_DM
PA12.Signal=USB_OTG_FS_DP
PA2.Signal=ADCx_IN7
PA3.Signal=ADCx_IN8
PA4.Signal=ADCx_IN9
PA5.Signal=ADCx_IN10
PA6.Signal=ADCx_IN11
PA7.Signal=ADCx_IN12
PA9.Signal=S_TIM1_CH2
PB0.Signal=ADCx_IN15
PB1.Signal=ADCx_IN16
PB11.Signal=S_TIM2_CH4
PB12.Signal=GPXTI12
PB13.GPIO_Label=IMU_I2C_SCL
PB13.Signal=I2C2_SCL
PB14.GPIO_Label=IMU_I2C_SDA
PB14.Signal=I2C2_SDA
PB15.Signal=GPIO_Output
PB5.Signal=CAN2_RX
PB6.Signal=CAN2_TX
PB8.Signal=CAN1_RX
PB9.Signal=CAN1_TX
PC0.Signal=ADCx_IN1
PC1.Signal=ADCx_IN2
PC10.Signal=SPI3_SCK
PC11.Signal=SPI3_MISO
PC12.Signal=SPI3_MOSI
PC2.Signal=ADCx_IN3
PC3.Signal=ADCx_IN4
PC4.Signal=ADCx_IN13
PC5.Signal=ADCx_IN14
PC6.Signal=S_TIM3_CH1
PC7.Signal=S_TIM3_CH2
PC8.Signal=S_TIM3_CH3
PC9.Signal=S_TIM3_CH4
PD0.GPIO_Label=LP_CSN2
PD0.Signal=GPIO_Output
PD1.Signal=SPI2_SCK
PD10.Signal=GPXTI10
PD12.Signal=S_TIM4_CH1
PD13.Signal=S_TIM4_CH2
PD14.Signal=S_TIM4_CH3
PD15.Signal=S_TIM4_CH4
PD2.GPIO_Label=LP_CSN1
PD2.Signal=GPIO_Output
PD3.Signal=SPI2_MISO
PD4.Signal=SPI2_MOSI
PD5.Signal=GPIO_Output
PD6.Signal=GPXTI6
PD7.Signal=GPIO_Output
PD8.GPIO_Label=IMU_MODE_SEL
PD8.Signal=GPIO_Output
PE1.Signal=S_TIM17_CH1
PE10.Signal=QUADSPI_CLK
PE11.Signal=QUADSPI_BK1_NCS
PE12.Signal=QUADSPI_BK1_IO0
PE13.Signal=QUADSPI_BK1_IO1
PE14.Signal=QUADSPI_BK1_IO2
PE15.Signal=QUADSPI_BK1_IO3
PE2.GPIO_Label=INFO_LED
PE2.Signal=GPIO_Output
PE3.GPIO_Label=HP_MOS_SEL1
PE3.Signal=GPIO_Output
PE4.GPIO_Label=HP_MOS_SEL2
PE4.Signal=GPIO_Output
PE5.GPIO_Label=HP_MOS_SEL3
PE5.Signal=GPIO_Output
PF10.Signal=ADC3_IN13
PF3.Signal=ADC3_IN6
PF4.Signal=ADC3_IN7
PF5.Signal=ADC3_IN8
PF6.Signal=S_TIM5_CH1
PF7.Signal=S_TIM5_CH2
PF8.Signal=S_TIM5_CH3
PF9.Signal=S_TIM5_CH4
PG10.Signal=S_TIM15_CH1
PG11.Signal=S_TIM15_CH2
PG2.Signal=SPI1_SCK
PG3.Signal=SPI1_MISO
PG4.Signal=SPI1_MOSI
PG5.Signal=GPIO_Input
PG6.Signal=GPIO_Output
PG7.Signal=GPIO_Output
PG9.Signal=GPIO_Output

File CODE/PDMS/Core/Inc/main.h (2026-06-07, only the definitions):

#define STATUS_LED_Pin LL_GPIO_PIN_2
#define STATUS_LED_GPIO_Port GPIOE
#define VOLTAGE_MUX_SEL4_Pin LL_GPIO_PIN_3
#define VOLTAGE_MUX_SEL4_GPIO_Port GPIOE
#define VOLTAGE_MUX_SEL3_Pin LL_GPIO_PIN_4
#define VOLTAGE_MUX_SEL3_GPIO_Port GPIOE
#define VOLTAGE_MUX_SEL2_Pin LL_GPIO_PIN_5
#define VOLTAGE_MUX_SEL2_GPIO_Port GPIOE
#define VOLTAGE_MUX_SEL1_Pin LL_GPIO_PIN_6
#define VOLTAGE_MUX_SEL1_GPIO_Port GPIOE
#define SENS_OUT_LP2_Pin LL_GPIO_PIN_3
#define SENS_OUT_LP2_GPIO_Port GPIOF
#define SENS_OUT_LP1_Pin LL_GPIO_PIN_4
#define SENS_OUT_LP1_GPIO_Port GPIOF
#define VMUX_ADC_Pin LL_GPIO_PIN_5
#define VMUX_ADC_GPIO_Port GPIOF
#define LP_SIG1_Pin LL_GPIO_PIN_6
#define LP_SIG1_GPIO_Port GPIOF
#define LP_SIG2_Pin LL_GPIO_PIN_7
#define LP_SIG2_GPIO_Port GPIOF
#define LP_SIG3_Pin LL_GPIO_PIN_8
#define LP_SIG3_GPIO_Port GPIOF
#define LP_SIG4_Pin LL_GPIO_PIN_9
#define LP_SIG4_GPIO_Port GPIOF
#define MAIN_12V_Pin LL_GPIO_PIN_10
#define MAIN_12V_GPIO_Port GPIOF
#define SENS_OUT8_Pin LL_GPIO_PIN_0
#define SENS_OUT8_GPIO_Port GPIOC
#define SENS_OUT7_Pin LL_GPIO_PIN_1
#define SENS_OUT7_GPIO_Port GPIOC
#define SENS_OUT6_Pin LL_GPIO_PIN_2
#define SENS_OUT6_GPIO_Port GPIOC
#define SENS_OUT5_Pin LL_GPIO_PIN_3
#define SENS_OUT5_GPIO_Port GPIOC
#define SENS_OUT4_Pin LL_GPIO_PIN_0
#define SENS_OUT4_GPIO_Port GPIOA
#define SENS_OUT3_Pin LL_GPIO_PIN_1
#define SENS_OUT3_GPIO_Port GPIOA
#define SENS_OUT2_Pin LL_GPIO_PIN_2
#define SENS_OUT2_GPIO_Port GPIOA
#define SENS_OUT1_Pin LL_GPIO_PIN_3
#define SENS_OUT1_GPIO_Port GPIOA
#define IO_CONN8_Pin LL_GPIO_PIN_4
#define IO_CONN8_GPIO_Port GPIOA
#define IO_CONN7_Pin LL_GPIO_PIN_5
#define IO_CONN7_GPIO_Port GPIOA
#define IO_CONN6_Pin LL_GPIO_PIN_6
#define IO_CONN6_GPIO_Port GPIOA
#define IO_CONN5_Pin LL_GPIO_PIN_7
#define IO_CONN5_GPIO_Port GPIOA
#define IO_CONN4_Pin LL_GPIO_PIN_4
#define IO_CONN4_GPIO_Port GPIOC
#define IO_CONN3_Pin LL_GPIO_PIN_5
#define IO_CONN3_GPIO_Port GPIOC
#define IO_CONN2_Pin LL_GPIO_PIN_0
#define IO_CONN2_GPIO_Port GPIOB
#define IO_CONN1_Pin LL_GPIO_PIN_1
#define IO_CONN1_GPIO_Port GPIOB
#define LED_DATA_Pin LL_GPIO_PIN_11
#define LED_DATA_GPIO_Port GPIOB
#define PWM_SIG8_Pin LL_GPIO_PIN_12
#define PWM_SIG8_GPIO_Port GPIOD
#define PWM_SIG7_Pin LL_GPIO_PIN_13
#define PWM_SIG7_GPIO_Port GPIOD
#define PWM_SIG6_Pin LL_GPIO_PIN_14
#define PWM_SIG6_GPIO_Port GPIOD
#define PWM_SIG5_Pin LL_GPIO_PIN_15
#define PWM_SIG5_GPIO_Port GPIOD
#define TEMP1_ALERT_Pin LL_GPIO_PIN_5
#define TEMP1_ALERT_GPIO_Port GPIOG
#define TEMP1_CS_Pin LL_GPIO_PIN_6
#define TEMP1_CS_GPIO_Port GPIOG
#define BUZZ_CTRL_Pin LL_GPIO_PIN_7
#define BUZZ_CTRL_GPIO_Port GPIOG
#define PWM_SIG4_Pin LL_GPIO_PIN_6
#define PWM_SIG4_GPIO_Port GPIOC
#define PWM_SIG3_Pin LL_GPIO_PIN_7
#define PWM_SIG3_GPIO_Port GPIOC
#define PWM_SIG2_Pin LL_GPIO_PIN_8
#define PWM_SIG2_GPIO_Port GPIOC
#define PWM_SIG1_Pin LL_GPIO_PIN_9
#define PWM_SIG1_GPIO_Port GPIOC
#define SAFETY_IN_Pin LL_GPIO_PIN_15
#define SAFETY_IN_GPIO_Port GPIOA
#define LP_CSN2_Pin LL_GPIO_PIN_7
#define LP_CSN2_GPIO_Port GPIOD
#define LP_CSN1_Pin LL_GPIO_PIN_9
#define LP_CSN1_GPIO_Port GPIOG
#define CAN_TERM1_Pin LL_GPIO_PIN_0
#define CAN_TERM1_GPIO_Port GPIOE
#define CAN_TERM2_Pin LL_GPIO_PIN_1
#define CAN_TERM2_GPIO_Port GPIOE

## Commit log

2022-11-13 Added crucial elements schematics
    [BTS50010-1TAE.kicad_sch, BTS50010_TestBoard.kicad_pcb, BTS50010_TestBoard.kicad_sch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]
2022-11-15 Added another high-side switch 2x7A + 2x4A SPI
    [BTS50010-1TAE.kicad_sch, BTS70021EPP.kicad_sch, BTS722204ESAXUMA1.kicad_sch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]
2022-11-17 Added Reverse polarity protection
    [BTS722204ESAXUMA1.kicad_sch, PDM.kicad_pcb, PDM.kicad_sch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]
2022-12-27 Fuck christmas & low side section
    [PDM.kicad_pcb, PDM.kicad_sch, TLE8104E.kicad_sch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]
2022-12-31 Concept revision and MCU section changes
    [BTS70021EPP.kicad_sch, PDM.kicad_pcb, PDM.kicad_sch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]
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2023-01-02 MCU preliminary scheme and qspi flash
    [PDM.kicad_pcb, PDM.kicad_sch, mcu.kicad_sch]
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2023-01-03 Added new type of high side driver based on VNF1048 + STL135
    [HSTYPE1.kicad_sch, PDM.kicad_pcb, PDM.kicad_sch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]
2023-01-10 Finished high side section & fixed some ERC's errors
    [PDM.kicad_pcb, PDM.kicad_sch, VNF1048FTR.kicad_sch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]
2023-01-12 New test board for VNF1048FTR
    [VNF1048FTR.kicad_sch, VNF1048FTR_TestBoard.kicad_pcb, VNF1048FTR_TestBoard.kicad_sch]
2023-01-12 Minor changes in HS sechmatics
    [PDM.kicad_sch, USER_PERIPHERAL.kicad_sch, VNF1048FTR.kicad_sch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]
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2023-01-15 Changed MCP2561 to SN65HVD230 for Q1 and 3.3V supply
    [PDM.kicad_sch, VNF1048FTR.kicad_sch, highside1.kicad_sch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]
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2023-01-15 Added fuse on each output of hs section - change footprint later!
    [6473427-1.stp, PDM.kicad_pcb, PDM.kicad_sch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]
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2023-03-21 Modified VNF1048 read, but SPIERROR bit is HIGH
    [PDM.kicad_pcb]
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2023-03-22 Added HWLO unlock still not working
    [main.h]
2023-03-29 Watch dog toggled on timer - works ok - problem with unlock
2023-04-12 Current status - still SPIE problem
2023-04-26 Created new simplified version of PDM -> PDMS
    [bts50010.kicad_sch, bts722204.kicad_sch, pdms.kicad_pcb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]
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2023-05-01 Added reverse polarity section LM74700 based
    [can_bus.kicad_sch, pdms.kicad_sch, power.kicad_sch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]
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2023-05-06 Changed MCU to L496 & finished powerswitch section
    [CONNECTOR_SOLUTION.xlsx, adc_prot.kicad_sch, adc_protection.kicad_sch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]
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2023-05-06 Assigned powerfets outputs to PWM outputs of MCU
    [ntc_section.kicad_sch, pdms.kicad_sch, power.kicad_sch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]
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2023-05-11 Added voltage mux section & layouting high side - hp
    [pdms.kicad_pcb, pdms.kicad_sch, user_peripheral.kicad_sch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]
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2023-05-17 Imported 3.3V section with problematic shitty plugin
    [BTS722204ESAXUMA1.stp, bts722204.kicad_sch, pdms.kicad_pcb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]
2023-05-17 Layout of high current traces to connector changed
    [pdms.kicad_pcb, pdms.kicad_sch, power_switches.kicad_sch]
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2023-05-20 DRC fix
    [pdms.kicad_pcb]
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2023-05-21 IMU layout - fixed
    [pdms.kicad_pcb]
2023-05-21 12V radsok connector + flash fix
    [pdms.kicad_pcb, pdms.kicad_sch]
2023-05-21 Oscillator layout - whole MCU
    [pdms.kicad_pcb, pdms.kicad_sch]
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2023-05-25 Zone size changed + DRC fix
    [pdms.kicad_pcb]
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2023-05-31 Changed main power connector, added USB-C, added BLE - not wired yet
    [argb_leds.kicad_sch, pdms.kicad_sch, user_peripheral.kicad_sch]
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2024-01-11 Added can-bus software switching and major changes in layout
    [bts50005-1lua.kicad_sch, can_bus.kicad_sch, pdms.kicad_sch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]
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2024-01-21 IMPORTANT! Batching all IS pin to single ADC peripheral
    [pdms.kicad_pcb, pdms.kicad_sch]
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2024-02-15 !ORDERED VERSION! - Added stiching on single channel traces
    [pdms-B_Cu.gbr, pdms-B_Mask.gbr, pdms-B_Paste.gbr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]
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2024-03-31 Not working version of pooling multiple channel ADC
    [adc.c, main.h, out.c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]
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2024-05-20 Added bigger LDO with lower Rth(ja), TVS suppressor diode
    [pdms.kicad_sch, power.kicad_sch]
2024-06-04 FINISHED: Version with fusing and input power filtering
    [pdms.kicad_sch, power.kicad_sch]
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2024-09-25 Major code rework, fixing macros without proper protections, adding comments and static keywords, void args for empty argument list
    [adc.c, bsp_out.c, out.c]
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2024-11-03 Created reverse polarity evaluation board
    [RP_MPQ5850_Test-B_Cu.gbr, RP_MPQ5850_Test-B_Mask.gbr, RP_MPQ5850_Test-B_Paste.gbr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]
2024-12-15 Minor changes in overall schematics & MP4322 scheamtics
    [input_selection.kicad_sch, mp4322.kicad_sch, pdms.kicad_pcb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]
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2024-12-15 Added reverse-polarity board gerbers
    [RP_MPQ5850_Test-B_Cu.gbr, RP_MPQ5850_Test-B_Mask.gbr, RP_MPQ5850_Test-B_Paste.gbr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]
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2025-03-22 Generated production files for RP_MPQ5850 & MP4322 schematic change
    [BOM-RP_MPQ5850_Test.csv, MP4322_TestBoard.kicad_sch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]
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2025-03-22 Fixed on-start UVLO handler
    [adc_handler.c, ws2812b.c]
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2025-03-30 Fixed invalid semaphore give, from wrong place
    [adc_handler.c]
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2025-03-30 Fix - Added timer delete function on UVLO timer
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2025-04-20 Last board commit before switch to Kicad 8.0.x
    [pdms.kicad_pcb, power.kicad_sch]
2025-04-22 PDMS PCB input modification WIP - no supply
    [adc_prot.kicad_sch, argb_leds.kicad_sch, bts50005-1lua.kicad_sch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]
2025-04-23 Fixed memory and aux routing, fixed decoupling of MCU, fixed hse oscilator layout, fixed BTS500 input capacitors size and thermal, fixed via stiching on output channels, changed LP mos traces to thin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
    [MP4322_TestBoard.kicad_pcb, adc_prot.kicad_sch, bts50005-1lua.kicad_sch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]
2025-04-26 PDMS PCB WIP modification mp4322 finished layput, cleared USB-C layout, moved OSC32 for better fit
    [bts50005-1lua.kicad_sch, input_selection.kicad_sch, mp4322.kicad_sch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]
2025-04-26 PDMS PCB WIP modification - finished LDO layout
    [mp4322.kicad_sch, pdms.kicad_pcb, power.kicad_sch]
2025-04-28 PDMS PCB WIP modification - fixed zones and stiching between output channel layers, DRC errors clean-up
    [BD50FD0WHFP-TR.stp, pdms.kicad_pcb]
2025-04-28 PDMS PCB WIP modification - added better input protection and filtering for voltage channels
    [bts50005-1lua.kicad_sch, bts722204.kicad_sch, pdms.kicad_pcb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]
2025-04-28 PDMS PCB WIP modification - added better input protection on battery voltage measurement point
    [pdms.kicad_pcb, pdms.kicad_sch]
2025-04-28 PDMS PCB WIP modification - added TVS diode and debouncing cap on safety line
    [pdms.kicad_pcb, pdms.kicad_sch]
2025-04-29 PDMS PCB V4.3 modification finished layout - drc clean-up, added external one-wire temp probe
    [BOM-pdms.csv, argb_leds.kicad_sch, bts722204.kicad_sch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]
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2026-05-16 Added exponential moving average to smoothen out telemetry data
    [pdm_pelny_przejazd.csv, pdm_pelny_przejazd_endurance.csv, pdmdisp_20260516-170648.csv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]
2026-05-17 Fixed can input conversion bug for boolean, added documentation for bsp_input and input modules [NOT TESTED]
    [bsp_phyinput.c]
2026-05-17 Fixed ADC IRQ yield from semaphore bug, changed ADC handlers priority to higher [NOT TESTED]
    [adc.c, adc_handler.c]
2026-05-17 Changed adc1 task priority to realtime, fixed invalid SW oversampling value, added TODO for median filter in current sense [NOT TESTED]
    [adc.c]
2026-05-18 Validated bsp_phy inputs changes, fixed telemetry output for SPOC2 device, validated ADC priority change [TESTED]
    [pdmdisp_20260516-170648.csv, pdmdisp_20260516-171424.csv, pdmdisp_20260516-171757.csv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]
2026-05-20 Added median filter - it's too slow 2.5ms processing
    [adc.c, adc.h, adc_handler.c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]
2026-05-21 Added optimized median filter for ADC1, Modified control script to export configuration - separated configuration of linker script to place configurations, added packed parameter for config
    [all.csv, pdm_pelny_przejazd.csv, pdm_pelny_przejazd_endurance.csv]
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2026-05-22 Added possibility to reset device over CAN
    [pdm_can_worker.py, pdm_config_tab.py, pdm_plot_tab.py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]
2026-06-04 Minor STM32 code changes: - Added logic expression validity mask to telemetry outputs - Disabled assert to hardfault escalation - Added act-on-safety mechanism (not tested) - Changed not implemented 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
    [can_handler.c, out.c]
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2026-06-04 Added xls file with Mouser PDMS v4.3 suplementary order
    [Projekt_cze02_0656PM (version 1).xls]
2026-06-04 Added gerbers of PDMS v4.3, assembly docs, modified DNP parameters
    [BOM-pdms.csv, bts50005-1lua.kicad_sch, bts722204.kicad_sch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]
2026-06-05 Fixed and verified Act-on-safety-line mechanism, added PWM configuration via desktop app
    [adc.c, bsp_out.c, out.c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]
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2026-06-05 Marked changes and notes for future PCB, anti-aliasing filter cacitors soldered on top of vmux divider, DEN should be controlled via IN, so no open-circuit is detected during PWM
    [bts50005-1lua.kicad_sch, vmux.kicad_sch]
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

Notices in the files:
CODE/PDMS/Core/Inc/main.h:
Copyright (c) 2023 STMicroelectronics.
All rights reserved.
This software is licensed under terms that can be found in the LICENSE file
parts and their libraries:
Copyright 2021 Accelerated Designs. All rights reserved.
